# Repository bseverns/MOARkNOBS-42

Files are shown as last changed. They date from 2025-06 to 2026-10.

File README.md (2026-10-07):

# MOARkNOBS-42

MOARkNOBS-42 (MN42) is an open, reactive MIDI/OSC performance instrument: a physical control surface, Teensy firmware,
a browser configurator, and a desktop Bridge that are designed and documented as one system.

It gives performers 42 configurable control slots, six envelope-follower inputs, profile recall, MIDI, OSC, and
browser-based editing without hiding the device contract behind proprietary software. It is closer to a small system
with a very visible control surface than “just a controller with a lot of knobs.”

[Try the browser configurator in simulator mode](https://bseverns.github.io/MN42/) without hardware, or read the
[five-minute orientation](docs/getting-started/FirstFiveMinutes.md).

## How the system fits together

```mermaid
flowchart LR
  H[Hardware<br>buttons, pots, LEDs,<br>envelope inputs] --> F[Firmware<br>scanning, MIDI,<br>config, persistence]
  F --> C[Contracts<br>manifest, schema,<br>WebSerial, Bridge RPC]
  C --> U[User tools<br>browser configurator,<br>OSC and host MIDI]
```

Each layer reports what it knows to the next. That is why the project emphasizes schema compatibility, verified
readback, test coverage, and evidence-backed support boundaries.

## Choose your path

| Interest | Start here | You will learn... |
| --- | --- | --- |
| Performer | [Quickstart for Performers](docs/getting-started/QuickstartForPerformers.md) | How to connect, configure, recall profiles, and prepare a rig. |
| Builder | [Quickstart for Builders](docs/getting-started/QuickstartForBuilders.md) | How to inspect, flash, bring up, and validate a board. |
| Contributor | [Contributing](CONTRIBUTING.md) | The build, test, documentation, and review gates. |
| Technical Evaluator | [Hardware-Test Readme](HARDWARE_TEST_README.md) | What the current prototype evidence proves—and does not prove. |

For a conceptual tour, use [Start Here](docs/getting-started/StartHere.md). For a complete source-tree map, use
[Repository Contents](docs/project/RepositoryContents.md).

## What is included

- **Hardware:** a Teensy 4.0 control surface with buttons, pots, LEDs, MIDI I/O, OLED feedback, and six reactive inputs.
- **Firmware:** scheduling, control scanning, MIDI behavior, modulation, configuration, and generation-checked persistence.
- **Browser configurator:** direct WebSerial setup, monitoring, staged edits, verified Apply, profiles, and a hardware-free simulator.
- **Bridge:** local browser console, OSC routing, virtual/host MIDI routing, and an App-over-Bridge transport.
- **Documentation and evidence:** contracts, build guides, validation procedures, and dated bench receipts.

## Quick start without hardware

1. Open the [hosted configurator](https://bseverns.github.io/MN42/).
2. Select **Start Simulator** for the firmware-default reset state, or **Load Demo Rig** for the illustrative example.
3. Check the named simulator fixture in Session, then change a slot, inspect the staged diff, and apply it to the simulated device.

The simulator demonstrates the browser workflow. It does not validate physical controls, timing, MIDI wiring, or
electrical behavior.

## Build and test

The PlatformIO project root is `firmware/`; always pass `-d firmware` from the repository root:

```bash
pio run -d firmware -e teensy40_main
pio test -d firmware -e teensy40_unity -vvv
```

Run the grouped repository checks before proposing a change:

```bash
./tools/doctor --full
```

See [Contributing](CONTRIBUTING.md) for the scoped test matrix and the custom Unity transport rules.

## Current project boundary

MN42 is at the hardware-test stage. The prototype boards and software paths are useful for bring-up and evaluation,
but the repository does not claim a public v1.0 release, an orderable fabrication package, universal host/browser
support, or a signed desktop installer.

Current hardware observations, board photos, test status, and the exact evidence still needed are kept in the
[Hardware-Test Readme](HARDWARE_TEST_README.md) and [Current Build](hardware/CurrentBuild.md)—not on this landing page.

## Documentation

- [Documentation site](https://bseverns.github.io/MOARkNOBS-42/)
- [System Map](docs/getting-started/SystemMap.md)
- [Connectivity Guide](docs/getting-started/ConnectivityGuide.md)
- [Documentation Truth Map](docs/reference/DocumentationTruthMap.md)
- [Testing](docs/validation/TESTING.md)
- [Release and reproducibility](REPRODUCIBILITY.md)

If two documents disagree, the [Documentation Truth Map](docs/reference/DocumentationTruthMap.md) defines the tie-break
rules. Historical wiki pages are frozen; canonical maintained documentation lives in this repository and the generated
documentation site.

## Contact and feedback

- Reproducible bugs and public questions: [GitHub Issues](https://github.com/bseverns/MOARkNOBS-42/issues)
- Security-sensitive reports: [Security policy](SECURITY.md)
- Pilot-run inquiries: [severns3@gmail.com](mailto:severns3@gmail.com)

Never put credentials, private device data, or other secrets in a public issue.

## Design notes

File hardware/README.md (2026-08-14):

# MOARkNOBS-42 Hardware References

This folder contains the hardware references used by the hardware-test package.
Use these files to validate the current prototype on the bench.

Do not treat this folder as a fabrication-ready release bundle.

Start with [CurrentBuild.md](CurrentBuild.md).

## External Power Requirement

Use a regulated `5 V DC` external supply at the DC input.

- `5 V / 4 A` is the minimum recommended bench supply.
- `5 V / 5 A` is preferred for LED-heavy testing (`white100`, `blast`, long soaks).
- Ground must be common across logic, LED, MIDI, and envelope follower sections.

> [!WARNING]
> Do not feed `9 V` or `12 V` into this board's VIN path unless a regulator/buck stage is explicitly added and documented. In this project, `VIN_RAW` and `VIN_FUSED` are project rail labels and should not be interpreted as an Arduino-style high-voltage raw VIN input.

## Power Topology Caveat

The intended fuse topology is:

- preferred: `5V_IN -> F1_LOGIC_0.5A -> 5V_LOGIC`
- preferred: `5V_IN -> F2_LED_2.5A -> 5V_LED`

If the actual board copper instead routes `F2` downstream of `F1`, then `F1` becomes an upstream choke for the entire machine.

> [!WARNING]
> If `F1` is upstream of the LED branch, the `0.5 A` PTC is the effective whole-system current limit. Firmware brightness caps help, but they are not a substitute for correct rail topology and fuse placement.

## Verify Before High-Current LED Tests

Before `white100`, `blast`, or burn-in phases:

- meter DC jack positive to `F1` input
- meter DC jack positive to `F1` output
- meter DC jack positive to `F2` input
- determine whether `F1` and `F2` are parallel branches or whether `F2` is downstream of `F1`
- do not run full-strip white or burn-in tests until this is confirmed

Power estimates and quick current math live in [PowerBudget.md](../docs/reference/PowerBudget.md).

## Firmware Env Boundary

- Flash `teensy40_main` on Rev A or any board whose LED rail topology is still unverified.
- Flash `teensy40_main_reworked` only after the board has been reworked and that split-rail topology has its own dated validation evidence.

## Current Bench-Validation References

- [Power, button, and LED schematic](../docs/assets/board/SCH_MOAR_Schematic_1-PWR-BUTTON-LED_2026-08-13.png)
- [Interface, MIDI, and control schematic](../docs/assets/board/SCH_MOAR_Schematic_2-INTERFACE-MIDI-CNTRL_2026-08-13.png)
- [Six-channel envelope schematic](../docs/assets/board/SCH_MOAR_Schematic_3-ENVELOPE_2026-08-13.png)
- [top-side board photo](../docs/assets/board/prodTOP.jpg) and [bottom-side board photo](../docs/assets/board/prodBTM.jpg)
- [trace-inspection photo](../docs/assets/board/trace.jpg), [bench context](../docs/assets/board/bench.jpg), and [powered bring-up](../docs/assets/board/bringup.jpg)
- [fabrication boundary note](fabrication/README.md)

These files are included to support bench validation and wiring review. No current BOM, Gerber, or NC-drill release bundle is tracked in `fabrication/`.

## Included Notes

- [CurrentBuild.md](CurrentBuild.md)
- [Parts.md](Parts.md)
- [PartsRationale.md](PartsRationale.md)
- [Substitutions.md](Substitutions.md)

## Status Boundary

- current schematic PNG sheets and board photos are present and usable as hardware references
- no current BOM export is tracked in `fabrication/`
- no verified fabrication-ready Gerber and NC-drill bundle is claimed by this package
- the fabrication folder is a boundary note until verified manufacturing files are added

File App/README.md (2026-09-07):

# MOARkNOBS-42 Browser Configurator

Use the browser configurator to connect directly over WebSerial, monitor the instrument, edit mappings, and manage
profiles. If you need OSC, host MIDI, or a browser without WebSerial, use the [Bridge](../bridge/README.md) path.

The fastest hardware-free introduction is the [hosted configurator](https://bseverns.github.io/MN42/): select
**Start Simulator** for the firmware-default reset state, or **Load Demo Rig** for illustrative mappings and motion.
The active simulator fixture is named in Session.

## Support boundary

- Direct USB is best evidenced on Chromium-based browsers with WebSerial.
- App-over-Bridge is best evidenced with the Node 24 Bridge on a desktop host.
- Firefox/Safari WebSerial and universal browser support are not claimed.
- The simulator rehearses App behavior; it is not hardware, electrical, MIDI-wiring, or latency evidence.

See [Host Compatibility](../docs/reference/HostCompatibility.md) before widening those claims.

## Quick start: direct USB

1. Flash the controller and connect it with a USB data cable.
2. From `App/`, serve the files from a secure or localhost origin:

   ```bash
   python3 -m http.server 8000
   ```

3. Open <http://localhost:8000/> in a Chromium-based browser.
4. Select **Check compatibility**, then **Connect**, and choose the MN42 serial device.
5. Wait for the identity, manifest, schema, and configuration handshake to finish.
6. Stage an edit, review the diff, select **Apply**, and wait for verified readback.

The legacy `benzknobz.html` URL remains a supported local/test entry point.

## Quick start: App over Bridge

```bash
npm --prefix bridge ci
npm --prefix bridge start
```

Open <http://127.0.0.1:8787/>, start the device session, then select **Open configurator**. The App uses the structured
Bridge session for configuration while OSC and MIDI routing remain active.

## Everyday workflow

- Use **Configure** to select a physical slot, map its output, build the **Reactive** path (source, ARG relationship, and EF character), then add **Motion**. With ARG off, Source drives the path; with ARG on, Reactive assignment keeps the path assigned while ARG supplies its combined value. Each Motion lane shows its shared generator’s current shape and rate, or labels an unsaved generator change as a local draft; editing remains in Lab. The selected-slot strip separates staged settings from measured device contributions and follows their causal order.
- Use **Stage** for a compact performance dashboard and safe recall controls.
- Use **Lab** for exact controls arranged by ownership. Its upper row keeps Live Slots, Selected Slot, and compact Session context together; the full-width **Lab Bench** opens one room at a time: **Instrument** for machine-wide shaping and live device controls, **Profile** for A–D arp/LFO/incoming-MIDI work, **Observe** for scope, monitor, MIDI trace, and modulation topology, and **Evidence** for staged diff and diagnostics. Continuous slot controls pair exact numbers with sliders; timing sliders use logarithmic travel. Reset to confirmed stages the last confirmed field value.
- Importing JSON stages a draft; it does not write the device until Apply succeeds.
- Export saves the current staged state, including unsent changes.
- Profile, scene, macro, and transport actions that could replace a dirty draft are blocked until it is applied or discarded.
- If Apply becomes uncertain, keep the candidate visible and let authoritative readback resolve device truth.

**State · Presets, profiles & backups** groups starting presets, device profile actions, and configuration/profile files.
Opening the drawer writes nothing. Presets and imports stage changes; profile save persists configuration on the device.

Changed controls carry **Staged** markers. The compact **Review / Discard / Apply** dock keeps the transaction available;
Review can focus the exact changed slot field in its Lab Bench room. **Customize in Lab** and **Return to Configure** preserve the
selected slot and LFO lane; generator links open **Lab Bench → Profile → Profile LFO & Routes**. Recipe explanations remain visible on touch screens.

The App explains how a slot’s value is shaped; the Bridge explains where that value goes. Neither surface infers
missing device measurements or confirms receipt by an external host application.

## Troubleshooting

- **Connect is unavailable:** wait for the page to finish initializing, then run **Check compatibility**.
- **No device selected:** the browser picker was cancelled; select **Connect** again and choose the device.
- **WebSerial is blocked:** use HTTPS or `http://localhost`, and confirm the browser supports WebSerial.
- **Apply is disabled:** fix the validation errors shown in the staged-diff panel.
- **State is uncertain/resynchronizing:** do not repeat writes blindly; wait for authoritative readback.
- **Need to recover during a set:** use **Panic Help**; the hardware baseline combo is `Ctrl0 + Ctrl1 + Ctrl2`.

## Develop and test

```bash
npm --prefix App test
```

The Playwright suite serves the real runtime and view modules, then exercises simulator, schema, staged Apply,
uncertainty, migration, profile, and UI behavior.

## Reference

- [App Behavior Contract](../docs/app/AppBehaviorContract.md) — runtime ownership, modes, schema, staged state, telemetry, and simulator boundaries
- [Configuration Transaction Model](../docs/reference/ConfigurationTransactionModel.md) — candidate, receipt, uncertainty, and readback semantics
- [App Transport Truth Table](../docs/app/AppTransportTruthTable.md) — direct, structured Bridge, raw Bridge, and simulator labels
- [Configurator Tour](../docs/guides/Configurator.md) — operator-facing UI walkthrough
- [App bench receipts](../docs/bench/app/README.md) — observed host/device evidence
- [Documentation Truth Map](../docs/reference/DocumentationTruthMap.md) — tie-break rules

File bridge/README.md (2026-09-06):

# MN42 Bridge

The MN42 Bridge is the desktop companion for the browser configurator. Use it when a rig needs OSC, host/virtual MIDI,
a local browser console, or App access without browser WebSerial. For direct USB configuration only, start with the
[App](../App/README.md).

## Support boundary

- Best repo evidence: Node.js 24 desktop host with the browser console or CLI.
- OSC and DAW routing are setup-specific; consult receipts before making host-wide claims.
- CI artifacts are unsigned. This repository does not claim a signed installer or broad DAW certification.
- Package scripts intentionally require Node `>=24 <25` until wider versions have explicit evidence.

See [Host Compatibility](../docs/reference/HostCompatibility.md) for the conservative matrix.

## Quick start: browser console

Prerequisites: Node.js 24.x and an MN42 connected over USB.

```bash
npm --prefix bridge ci
npm --prefix bridge start
```

Open <http://127.0.0.1:8787/> if the server does not open it automatically. Then:

1. Choose the serial port and confirm the OSC/MIDI destinations.
2. Start the Bridge and wait for the device session to report ready.
3. Open **Monitor**, start passive soundcheck, and move one stable hardware control to observe configured Bridge outputs.
4. Select **Open configurator** when you need instrument configuration edits.

Returning users begin at **Your saved rig**: choose a browser-local **Performance Setup** and **Start this setup**
to recall its exact serial, MIDI, and OSC settings. The suggested MN42 profile stays advisory. **Edit** and
**New setup** open the collapsed setup workbench; its manual start action is **Start current setup**.

**Routing** labels Device → MIDI cards **Next start** and MIDI → OSC custom routes **Live now**. Slot/EF → CC →
Channel cards, with raw JSON under Advanced, apply on the next Bridge start in Configured routes mode; legacy
compatibility retains its automatic CC assignments.
Invalid raw definitions block starting and saving until corrected.

**Monitor** follows MN42 → USB → Bridge and the four OSC/MIDI directions. Idle routes remain neutral; observed
Bridge output does not confirm receipt in a host application. Device evidence is available under **Device details**,
and alerts link to the relevant Diagnostics section. See the [console tour](../docs/bridge/BridgeConsoleTour.md).

The HTTP server binds to loopback by default. Every launch creates a random control token and opens a tokenized URL;
treat it as a local credential. Public-interface HTTP requires the explicit `--unsafe-network-http` option and your own
network protection.

## Quick start: CLI

Find the serial device (`/dev/cu.usbmodem*` on macOS, `/dev/ttyACM*` or `/dev/ttyUSB*` on Linux, or a COM port on
Windows), then run:

```bash
node bridge/mn42_bridge.js \
  --serial /dev/ttyACM0 \
  --osc 9000 \
  --osc-listen 9000 \
  --host 127.0.0.1 \
  --bind 127.0.0.1 \
  --midi "MN42 Bridge"
```

Replace the serial path and MIDI port label with values from the host. Use `--config ./bridge/settings.example.json`
for saved settings; explicit CLI flags override the file.

## What the Bridge routes

- Device telemetry to OSC and optional host MIDI.
- OSC or MIDI performance messages back to the firmware live-control lane.
- Structured device-session state to the browser configurator.
- Revisioned staged configuration through `/api/device/*` and `/ws/events`.
- Raw newline-oriented serial compatibility through `/ws`.

Clients negotiate the structured interface through `GET /api/contract` before
using it. Existing `/api/*` paths remain the version-1 compatibility surface;
the response advertises API/event versions, Bridge version/source identity,
supported device schema versions, and verified Apply/session capabilities.

Live `SET_SLOT_VALUE` and typed MIDI/OSC events are performance writes, not staged configuration. Configuration changes
use stage/apply endpoints and preserve uncertainty until authoritative readback resolves device truth.

## Everyday workflows

- **Rehearsal/show:** follow [Bridge for Performers](../docs/guides/BridgeForPerformers.md).
- **Browser console:** use [Bridge Console Tour](../docs/bridge/BridgeConsoleTour.md).
- **OSC or DAW setup:** use [Bridge Operator Reference](../docs/bridge/BridgeOperatorReference.md).
- **App integration:** use [Bridge Transport Contract](../docs/bridge/BridgeTransportContract.md).
- **Write behavior:** use [Bridge Write Lanes](../docs/bridge/BridgeWriteLanes.md).

## Troubleshooting

- **No device updates:** confirm the serial path, close other serial clients, then restart and wait for `HELLO`.
- **OSC commands ignored:** send to the listen port (default `9000`) and use `/mn42/cmd` or a documented typed address.
- **DAW cannot see MIDI:** create/enable a host loopback port and pass its exact label to `--midi`.
- **Port already in use:** stop the existing process or choose different HTTP/OSC ports.
- **Apply is uncertain:** do not repeat the write blindly; wait for the session's authoritative readback.

## Develop and test

```bash
npm --prefix bridge test
npm --prefix bridge run smoke
```

Packaging and signing are separate release concerns. See [Bridge Signing Plan](../docs/release/BridgeSigningPlan.md) and
the [artifact checklist](../docs/release/bridge-artifacts-checklist.md).

## Reference

- [Bridge Docs Map](../docs/bridge/BridgeDocsMap.md)
- [Bridge Operator Reference](../docs/bridge/BridgeOperatorReference.md)
- [Bridge Transport Contract](../docs/bridge/BridgeTransportContract.md)
- [Bridge Write Lanes](../docs/bridge/BridgeWriteLanes.md)
- [Known Good Host Recipes](../docs/reference/KnownGoodHostRecipes.md)
- [Bridge bench receipts](../docs/bench/bridge/README.md)
- [Documentation Truth Map](../docs/reference/DocumentationTruthMap.md)

Bridge code is licensed under the repository license; bundled dependency notices are in
[THIRD_PARTY_LICENSES.md](THIRD_PARTY_LICENSES.md).

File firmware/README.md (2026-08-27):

# MOARkNOBS-42 Firmware Hardware-Test Guide

> **Doc class:** Contract doc. This is the firmware build/test boundary for the current hardware-test package; release and hardware-readiness claims still require the validation docs.

This `firmware/` directory is the real PlatformIO project for the current MOARkNOBS-42 hardware-test package.
The commands below are safe to copy from the repository root because they pass `-d firmware` explicitly.

For document tie-break rules, see [Documentation Truth Map](../docs/reference/DocumentationTruthMap.md).

## Baseline Build

```bash
pio run -d firmware -e teensy40_main
```

The repo-root `platformio.ini` is only a guard that rejects accidental root-level builds.

## Firmware Environments

- `teensy40_main` for Rev A / unverified-rail boards; this is the conservative default build
- `teensy40_main_reworked` only for boards whose split-rail rework has been validated and documented
- `teensy40_full_system` for bridge-connected full-stack bench validation
- `teensy40_unified_test` for manual bench verification of buttons, pots, OLED, LEDs, and envelope inputs
- `teensy40_biquad_test` for filter verification
- `teensy40_eeprom_persistence` for staged persistence and backup-restore validation
- `teensy40_slot_verify` for slot-storage integrity checks
- `teensy40_led_demo` for LED pattern and load-surface checks
- `teensy40_button_ef_demo` for simple button plus envelope USB MIDI validation
- `teensy40_display_alive` for an OLED-only "is the panel alive?" check
- `teensy40_display_led_hw` for OLED and LED hardware bring-up
- `teensy40_power_burnin` for LED load and power-rail soak testing
- `teensy40_unity` for the custom Unity smoke suite

The full lane summary lives in [../docs/hardware-test/TestMatrix.md](../docs/hardware-test/TestMatrix.md).

`GET_MANIFEST` reports the active board power profile, LED cap, and rail-verification bit from the selected env, so do not flash `teensy40_main_reworked` unless the physical board actually matches that claim.

## Envelope Filter Timing

Envelope filter configuration keeps the legacy `frequency` field for wire and
preset compatibility, but the value is a shaping-control scale rather than a
physical cutoff in hertz. The runtime samples one of six followers every 2 ms,
giving each follower an effective rate of about 83.3 Hz. It translates the
legacy control ratio onto that real cadence before configuring the biquad.
Per-slot EF voices perform the same translation using the configured mid-tier
envelope interval. The `native_biquad` step-response test locks this timing
model without claiming analog-input-to-host latency.

## Configuration and Profile Boundaries

The compatibility commands `CAL_ENVS`, `GET_FILTER`, `SET_FILTER`,
`GET_SLOT_FILTER`, `SET_SLOT_FILTER`, `GET_ARGPAIR`, and `SET_ARGPAIR` are
handled by `src/protocol/LegacyConfigCommands.cpp`. Their command spellings,
responses, and persistence behavior are unchanged; `ConfigManager` now exposes
configuration operations without parsing transport text. This refactor does
not alter the durable layout or wire protocol.

`src/protocol/ConfigSchema.cpp` owns `GET_SCHEMA` construction, while
`ProfileTypes.h` owns the current packed profile payload independently of the
manager class. `ProfileMigration.cpp` performs read-only decoding and
sanitization for stored profile versions 1–7; `ConfigManager` retains profile
ID/address validation and the public load/save façade. Migration fixtures cover
versions 1–6, current-version coverage protects version 7, and decoder failure
tests verify that invalid records do not mutate the caller's output.
Activating a stored profile also requires one valid legacy pot/CC mapping copy;
an extended profile payload alone cannot produce a partial profile transition.

The `SET_ALL` implementation is separated into `ConfigBulkTransport` for chunk
staging, timeout/idempotency, and ACKs; `ConfigJsonApply` for complete validation
and atomic runtime/persistence mutation; and `ConfigApplyDigest` for the
device-owned normalized-state checksum. Parse, identity, abort, and timeout
failures discard staged transport state; retrying the last acknowledged
sequence plus config identity replays the same applied checksum and storage
generation without applying again.

Direct read commands remain fronted by `ProtocolSimpleHandlers`, but bounded
read-chunk framing and pending-output state live in `ChunkedReadTransport`, and
`GET_MOD_MATRIX` construction lives in the flash-resident `ModMatrixReport`.
Non-persistent live `SET_*` mutations live in `ProtocolLiveControlHandlers`.
These are ownership boundaries only: command names, response shapes,
persistence semantics, and the durable layout are unchanged.

## On-device Live Editing

The performance surface can now reach three formerly configurator-heavy slot settings without entering config mode:

| Gesture | Active-slot edit | Live behavior |
| --- | --- | --- |
| Double-press `Ctrl3` | Cycle EF oversampling through 1x, 2x, 4x, 8x, 16x, and 32x | Reconfigures the assigned follower immediately |
| Double-press `Ctrl4` | Toggle the slot-local ARG combiner | Switches the configured ARG method and source pair in or out |
| `Ctrl0+Ctrl1+Ctrl4` | Toggle the fixed LFO 1 lane | Enables live centered modulation at 100% for an untuned lane and preserves later tuning |

Ctrl3 and Ctrl4 defer their ordinary single action until the 300 ms double-press window expires, so their double actions do not also change channel or data1. Ctrl5 has no double-press action: each tap-tempo press fires immediately on release, including fast 240 BPM tapping. The edits persist with the slot and stream `slot_patch` readback to an attached configurator. The complete short/long/double/combo map lives in [include/ButtonManager/README.md](include/ButtonManager/README.md).

The former Ctrl5 collision is removed: rapid taps can no longer be classified as an LFO toggle. Ctrl5 singles continue to update `g_tappedBPM`, while the dedicated LFO chord preserves the previous live lane initialization and tuning-retention behavior.

The OLED also acts as a contextual command palette. Holding Ctrl0-Ctrl5 shows that control's semantic namespace and useful chord continuations; recognized chord prefixes show deeper continuations. The compact firmware table and [generated quick reference](../docs/reference/generated/OnDeviceQuickReference.md) both come from [the on-device control registry](../docs/reference/on_device_control_registry.json), so help copy and gesture metadata share one machine-readable source. Config, LFO, jitter, and diagnostic views retain priority and use persistent mode headers.

## First Reading Path

If you are learning this firmware by reading code, start with
[src/firmware_main.cpp](src/firmware_main.cpp), then follow the ordered header
walkthrough in [../docs/firmware/FirmwareMainReadingPath.md](../docs/firmware/FirmwareMainReadingPath.md).
That path is the repo's intended "top-down" introduction to the machine.

## Core Commands

Firmware build:

```bash
pio run -d firmware -e teensy40_main
```

Unity smoke suite:

```bash
pio test -d firmware -e teensy40_unity -vvv
```

Unified bench sketch:

```bash
pio run -d firmware -e teensy40_unified_test -t upload
```

LED surface stress sketch:

```bash
pio run -d firmware -e teensy40_led_demo -t upload
```

Full bridge/system lane:

```bash
pio run -d firmware -e teensy40_full_system -t upload
```

Production boot contract proof:

```bash
node firmware/system_test/mn42_boot_contract_runner.js --serial /dev/cu.usbmodemXXXX --flash --report logs/boot-contract.json
```

Attach-live hardware proof when the board is already running firmware and you only need the real configurator/apply lane:

```bash
node firmware/system_test/mn42_boot_contract_runner.js --serial /dev/cu.usbmodemXXXX --attach-live --report logs/boot-contract-attach-live.json
```

Request one-shot configurator boot from a running firmware image:

```text
ENTER_CONFIG_MODE
```

`ENTER_CONFIG_MODE` stores a one-shot boot marker and reboots. The next boot enters
USB configurator mode and consumes the marker; normal power-up defaults to the
standalone runtime so USB MIDI remains available without opening the configurator
or bridge first.

Live runtime controls exposed over the configurator/native protocol:

```text
GET_NOTE_DYNAMICS
SET_NOTE_DYNAMICS,<velocityShift>,<changeProbability>
GET_JITTER
SET_JITTER,<depth>,<smoothness>
GET_CLOCK
SET_CLOCK,<followExternal>,<clockOutEnabled>,<tappedBpm>
GET_USB_MIDI
SET_USB_MIDI,<0|1>
```

`SET_NOTE_DYNAMICS` clamps to `-64..63` and `0..100`. `SET_JITTER` clamps both
values to `0.0..1.0`. `SET_CLOCK` clamps the internal tempo to `20..300 BPM`.
The firmware advertises these lanes in the manifest so the browser configurator
can fail closed on older builds.

`GET_MANIFEST` also reports a small persistence-health snapshot for host tools:
`brownout_count`, `eeprom_primary_valid`, `eeprom_backup_valid`, and
`eeprom_last_load` (`primary`, `backup`, or `defaults`).

## Important Test Contract

- PlatformIO project root is `firmware/`.
- The Unity lane uses the custom Serial1 transport from `test/unity_output.cpp`.
- Do not re-enable PlatformIO's autogenerated Unity transport.
- Tests assume `board_build.usbtype = usb_midi_serial`.
- Hardware firmware builds override USB strings to enumerate as `MN42 MIDI` (manufacturer `MN42`).
- Do not pull display or SD stacks into the Unity lane unless explicitly needed.

## Local References

- [include/](include/README.md)
- [src/](src/README.md)
- [test/](test/README.md)
- [system_test/](system_test/README.md)

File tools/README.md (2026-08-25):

# Bench Toys & Code Gremlins

> Grab-bag of small scripts that sniff, log, or otherwise harass the hardware so you can learn by poking.

## Serial Logger

Curious about latency or noise? `serial_logger/SerialToCsv.pde` is a Processing sketch that funnels whatever the board spits into CSV files you can graph or diff later. Quick run:

```text
1. Launch Processing 4.
2. Load `SerialToCsv.pde`.
3. Hit Run and choose the board's serial port.
4. Press `L` to log latency, `N` for noise. `Q` bails.
```

Outputs land in `docs/bench/latency/latency.csv` and `docs/bench/noise/adc_idle.csv`. More details live in the [serial_logger README](serial_logger/README.md).

## RTL Latency Report

When you bounce the rig through an external DAW loop and capture an impulse
response, feed those WAVs to `rtl_latency_report.py`. It auto-detects the
send/return spikes, measures the gap in samples, and spits out both a table and
JSON so you can compare baseline (256 buffer) against tuned (64 buffer) sessions
without hand math. Think of it as a drummer with a calculator: loud, precise,
and painfully honest.

## Docs Link Checker

Run `python3 tools/check_docs_links.py` before you ship docs-heavy changes. It checks local Markdown links and heading anchors so learners don't fall through trapdoors.

## Public UI Vocabulary Guard

Run `python3 tools/check_public_ui_vocabulary.py --root .` to keep musician-facing front-door docs on the current App and Bridge names. The guard is deliberately scoped: historical records, compatibility tokens, recipe names, and deep contracts may still use words such as `advanced` or `stage` in other meanings.

## Bring Your Own Hacks

Got a script that makes debugging less dull? Park it here with a README and keep dependencies light. No binaries, no mystery jars—just plain text mischief that others can remix.

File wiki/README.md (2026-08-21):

# Archived Wiki Source Pack

> **Archived:** The wiki is frozen and is no longer a maintained documentation surface. Canonical documentation lives
> in [`docs/`](../docs/index.md), the root [`README.md`](../README.md), and the component READMEs.

The files in this directory are retained as historical source material so existing GitHub Wiki links do not disappear.
They may describe older workflows or support boundaries and must not be used to settle current behavior.

## Where to go instead

- Project introduction: [`README.md`](../README.md)
- Performer path: [`docs/getting-started/QuickstartForPerformers.md`](../docs/getting-started/QuickstartForPerformers.md)
- Builder path: [`docs/getting-started/QuickstartForBuilders.md`](../docs/getting-started/QuickstartForBuilders.md)
- Contributor path: [`CONTRIBUTING.md`](../CONTRIBUTING.md)
- Evaluator path: [`HARDWARE_TEST_README.md`](../HARDWARE_TEST_README.md)
- Documentation tie-break rules: [`docs/reference/DocumentationTruthMap.md`](../docs/reference/DocumentationTruthMap.md)

## Maintenance policy

- Do not add new guidance to `wiki/`.
- Fix a wiki page only when needed to prevent a dangerous or materially misleading stale instruction.
- Move any still-unique, current content into `docs/` before updating it.
- Do not publish this directory as a replacement for the maintained documentation site.

Existing pages remain snapshots. Their `Canonical source` declarations point readers toward the maintained contract or
guide that supersedes them.

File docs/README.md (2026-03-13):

# Docs Index

> Hardware's signed off and etched in copper. This folder is the reference stash for the whole machine—schematics, firmware lore, and every misadventure we've documented.

Welcome to the MOARkNOBS-42 documentation playground. This README aims to help you navigate the library of notes, design scraps, and personal ramblings we keep around to teach ourselves and the next hacker.

Need the fast track from bare board to release? Hit the [Process Overview](ProcessOverview.md).

Craving the bird's-eye view? The [systemflow docs](sketch/systemFlow/) rip the machine into subsystems so you can see how every knob, LED, and envelope fits together before you dive into the weeds.

If you only need the canonical operational docs, start here:

- [TESTING.md](TESTING.md) for what the current automated/manual coverage actually proves
- [ReleaseGuide.md](ReleaseGuide.md) for the human release checklist
- [../REPRODUCIBILITY.md](../REPRODUCIBILITY.md) for the exact artifact-building recipe
- [../App/README.md](../App/README.md) for the browser/runtime/schema/Apply contract

## Local site preview

The repo now ships with a MkDocs scaffold so the docs can read like a guided site instead of a loose folder dump.

```bash
pip install -r requirements.txt
mkdocs serve
```

Then open the local URL MkDocs prints in your terminal.

| Doc | Why it exists | Keep it fresh |
| --- | --- | --- |
| [Primers/MIDI-DSP101.md](Primers/MIDI-DSP101.md) | MIDI basics and the DSP tricks our firmware leans on | Sync when firmware MIDI features or filter math shift |
| [ProcessOverview.md](ProcessOverview.md) | Full build and release flow | Update when hardware or firmware release steps move |
| [TESTING.md](TESTING.md) | Canonical test workflow + coverage map | Refresh when test scope or commands move |
| [ReleaseGuide.md](ReleaseGuide.md) | Human release checklist | Refresh when release ritual or asset list changes |
| [../REPRODUCIBILITY.md](../REPRODUCIBILITY.md) | Canonical deterministic artifact recipe | Refresh when `release.sh` or artifact shape changes |
| [../App/README.md](../App/README.md) | App/runtime contract and simulator notes | Refresh when manifest/schema/apply semantics change |
| [interop/seedbox.md](interop/seedbox.md) | SeedBox handshake + CC contract | Refresh when either repo tweaks the interop map |

## Accessibility

- Every diagram and board glam shot sports alt text so screen readers get the same gossip as eyeballs.
- Headings descend one level at a time—no surprise teleporting from H1 to H4.
- Code blocks and tables stay lightweight so zoom tools and high-contrast themes can rage without breaking layout.

## PCB Gallery

> Fast glamor shots live here so the hardware README can stay lean. Want the cadaver-level detail? The [sketch/](sketch/) folder holds every layer and subsystem sketch.

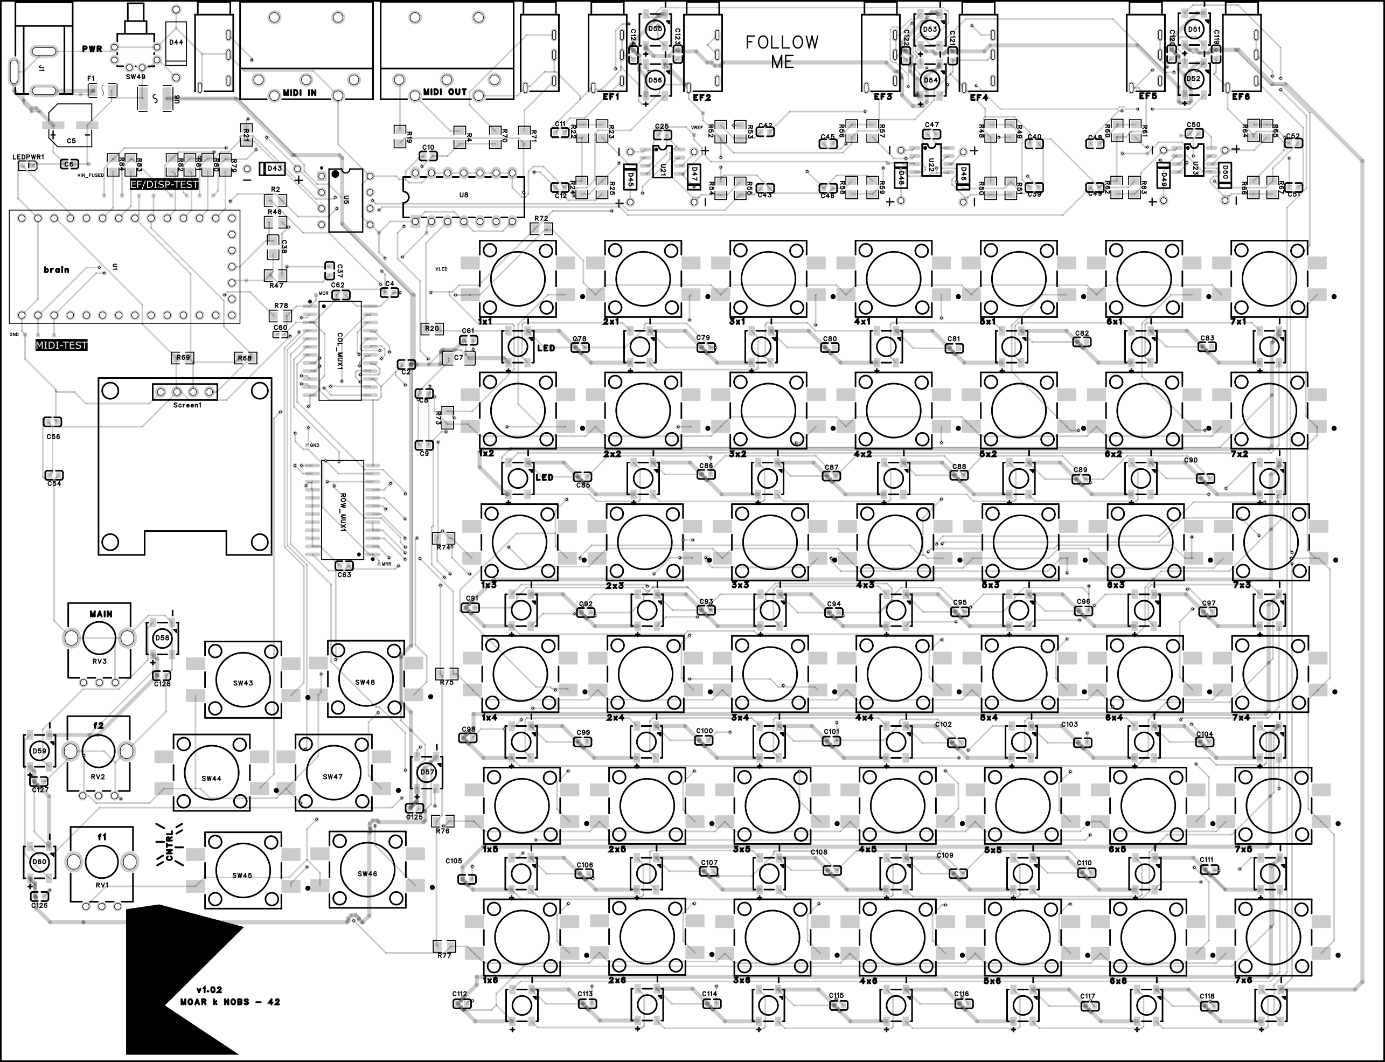
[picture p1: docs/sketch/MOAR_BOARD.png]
Render of MOARkNOBS board showing component layout


Layer spelunking:

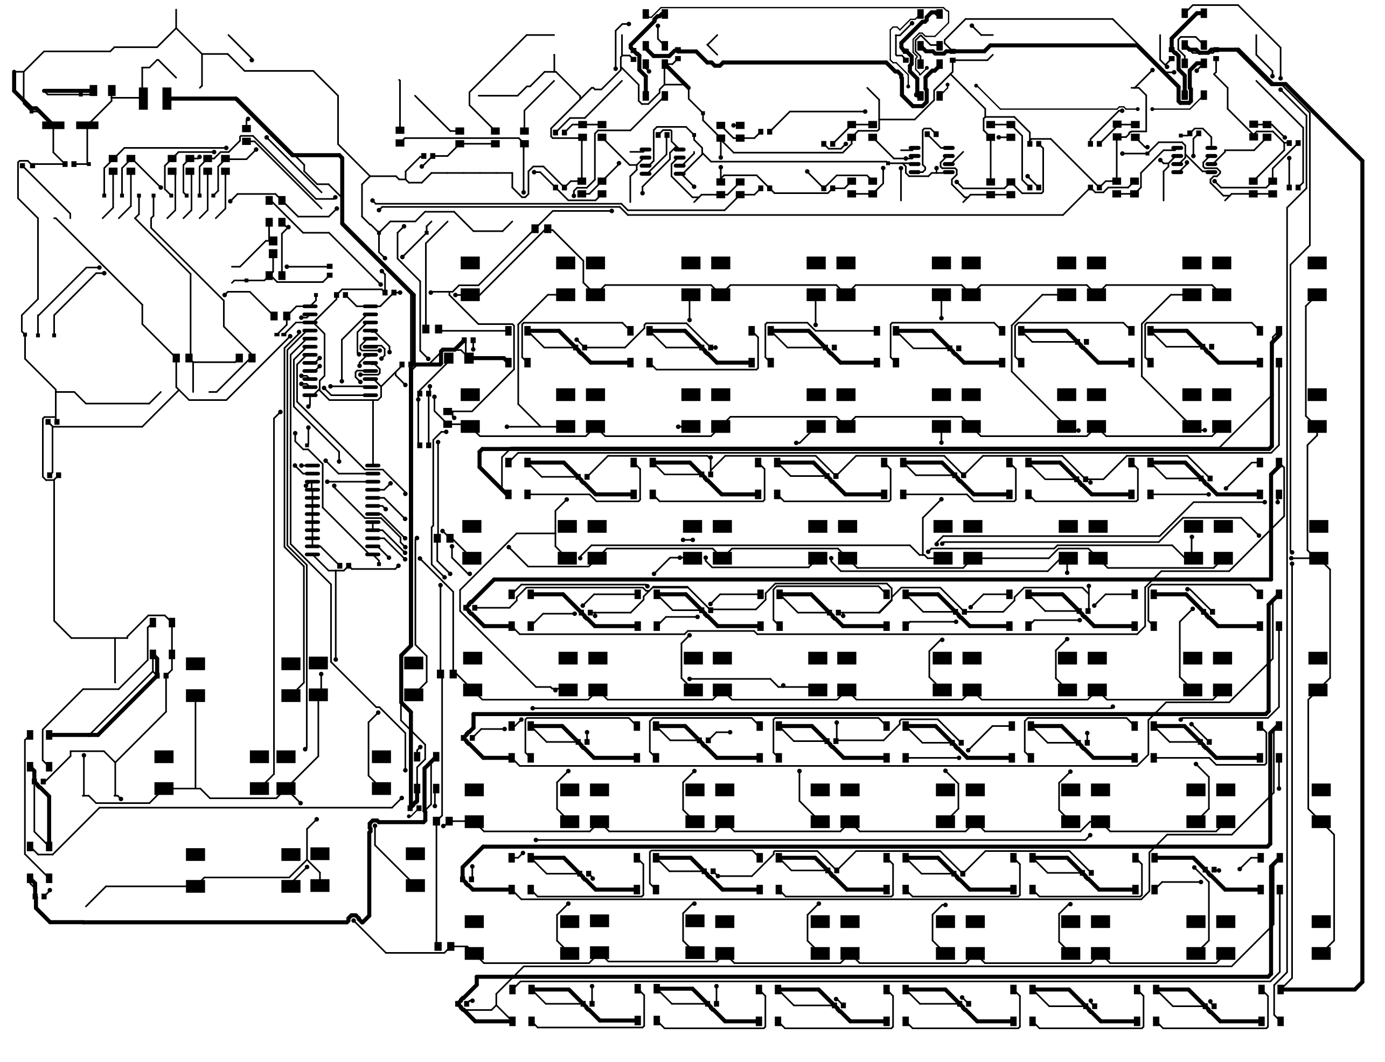
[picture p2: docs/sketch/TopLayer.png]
PCB top-layer trace map

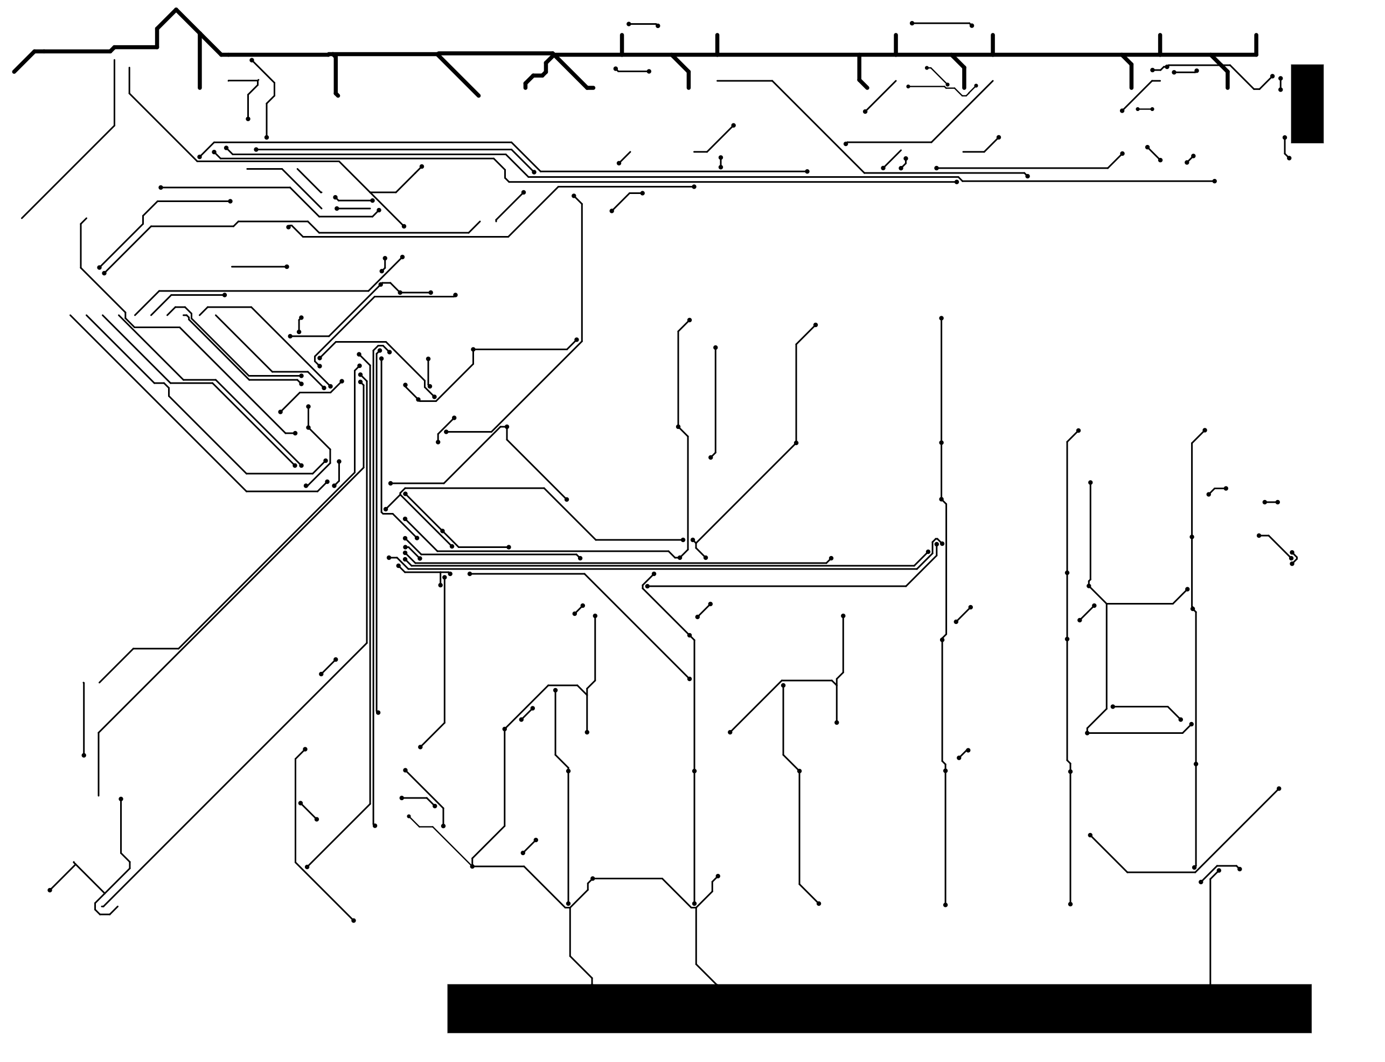
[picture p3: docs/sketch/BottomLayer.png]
PCB bottom-layer trace map


### Everything Everywhere

```mermaid
flowchart TD
  Flash --> Loader[Bootloader] --> FW[Teensy Firmware]
  FW --> BM[ButtonManager] --> DM[DisplayManager]
  Buttons((Buttons)) -->|scan| BM --> FW
  EF[EnvelopeFollower] -->|mod| Slots((Slots))
  ARP[Arpeggiator] -->|mod| Slots((Slots))
  MIDIIN --> FW --> DM[DisplayManager]
  MIDIIN --> FW --> Slots((Slots))
  Browser[[Browser]] --> WebSerial --> FW
  NodeOSC[[Node OSC Bridge]] --> FW
  FW --> Slots((Slots)) --> MIDIOut((MIDI Out))
  FW --> MIDIThrough((MIDI Through))
```

## System Capabilities

 - [Hardware README](../hardware/README.md#sparkfun-shortcut) — final board layout, power rails, and a SparkFun shortcut for the silicon.
- [Firmware README](../firmware/README.md) — how the code slings MIDI, wrangles envelope followers, and keeps the LEDs honest.
- Firmware reference tables: [button map & combo guide](../firmware/include/ButtonManager/README.md#button-map), [filter types](../firmware/include/EnvelopeFollower/README.md#filter-types), [arp settings](../firmware/include/Arpeggiator/README.md#arp-settings), [MIDI types](../firmware/include/MIDIHandler/README.md#supported-message-types), [ARG methods](../firmware/include/EnvelopeFollower/README.md#arg-methods), [display hooks](../firmware/include/DisplayManager/README.md#key-methods).

## Choose Your Adventure

> Need a refresher before you dive? Hit the [MIDI + DSP 101 Primer](Primers/MIDI-DSP101.md) for channel lore, CC etiquette, and the envelope math our modules lean on.

- [BuildersHandbook.md](BuildersHandbook.md) — wire it, flash it, and smoke-test it.
- [Troubleshooting.md](Troubleshooting.md) — chase gremlins when the box won't boot or buttons go rogue.
- [HISTORY.md](HISTORY.md) — chronological ride through the project's evolution. Commit references, design pivots, and the "why" behind the build.
- [Options_DNI.md](Options_DNI.md) — the optional / Do Not Install cheat sheet. Use this before you lock a BOM or when you're deciding what not to solder.
- [PinMap.md](PinMap.md) — every MCU pin's mission and mayhem.
- [EEPROMLayout.md](EEPROMLayout.md) — where config bytes live and die.
- [FirmwareUpdate.md](FirmwareUpdate.md) — flash new brains without desoldering.
- [TESTING.md](TESTING.md) — unit tests to full-stack thrash sessions.
- [DemoPolish.md](DemoPolish.md) — runbook for final demo soak, EXT clock checks, panic-reset verification, and asset packing.
- [TODO.md](TODO.md) — post-release wishlist for when the first build is out and you're itching for v2.
- [ReleaseGuide.md](ReleaseGuide.md) — full release playbook. For quick steps see [Publishing a Release](../README.md#publishing-a-release).
- [../CONTRIBUTING.md](../CONTRIBUTING.md) — patch etiquette and repo contract.
- [sketch/](sketch/) — raw schematics and subsystem scribbles when you need the gory details.
  Highlights:
    - [buttonMatrix.md](sketch/systemFlow/hw/buttonMatrix.md) — how the 42-button grid scans its soul.
    - [display.md](sketch/systemFlow/hw/display.md) — wrangling pixels and I²C.
    - [envelopeFE.md](sketch/systemFlow/hw/envelopeFE.md) — analog envelope follower circuits.
    - Plenty more (midi opto, power antics, board PDFs) for late-night study.
- [WebSerial.md](WebSerial.md) — how the board chats with browsers, negotiates schema versions, and keeps presets safe.
- [OSCBridge.md](OSCBridge.md) — quickstart for OSC + virtual MIDI bridge usage, including DAW setup and troubleshooting.
- [BridgeForPerformers.md](BridgeForPerformers.md) — one-page show-day checklist for running bridge + OSC/DAW fast.
- [BridgePackaging.md](BridgePackaging.md) — implementation plan for shipping one-click bridge binaries/installers.
- [release/bridge-artifacts-checklist.md](release/bridge-artifacts-checklist.md) — per-release template for bridge binary assets, checksums, and sign-off.
- [thermal/](thermal/) — keep the silicon from frying itself.

## Exporting the narrative report

The long-form release report (`report-CDSsample.md`) is meant to ship right next to the binaries.
When you need a pretty PDF for Zenodo, a class handout, or a grant package, run our Pandoc helper:

```bash
./tools/render_report.sh
```

By default the PDF lands in `docs/dist/MOARkNOBS-42-report.pdf`. Set `PDF_ENGINE=xelatex`
if you prefer a different LaTeX backend than [Tectonic](https://tectonic-typesetting.github.io/).
Pass an alternate output directory as the first argument if you want the PDF elsewhere.

## Why these specific parts?

> Quick hits on why each chunk of silicon shows up and where SparkFun teaches the tricks. Longer sourcing diary still lives in
> [../hardware/Parts.md](../hardware/Parts.md) when you want BOM-level receipts.

- **Teensy 4.0** — horsepower with USB baked in. The [Teensy 4.0 Hookup Guide](https://learn.sparkfun.com/tutorials/teensy-40-hookup-guide) covers pinout, power, and programming basics.
- **CD74HC4067 analog mux** — collapses 42 buttons into one ADC read. The [16‑Channel Mux Breakout Guide](https://learn.sparkfun.com/tutorials/16-channel-analogdigital-multiplexer-breakout-cd74hc4067-hookup-guide) shows how to breadboard the trick.
- **SN74HCT245 level shifter** — keeps 5 V button buses from smoking the 3 V3 MCU. SparkFun's [Logic Level Shifting 101](https://learn.sparkfun.com/tutorials/logic-level-shifting) explains the voltage translation.
- **6N138 optocoupler** — isolates MIDI IN. SparkFun's [MIDI Tutorial](https://learn.sparkfun.com/tutorials/midi-tutorial/all) breaks down DIN wiring and opto‑isolation.
- **MCP6002 op‑amp** — rectifies audio for the envelope followers. SparkFun's [Op-Amp Basics](https://learn.sparkfun.com/tutorials/op-amps/all) digs into precision rectifiers and biasing.
- **WS2812 LEDs** — one data pin, full-color rage. SparkFun's [WS2812 Breakout Hookup Guide](https://learn.sparkfun.com/tutorials/ws2812-breakout-hookup-guide) covers timing and power layout.

### Lab Playlist: choose your own adventure

Warm up your brain before flashing firmware.

- [Logic Level Shifting 101](https://learn.sparkfun.com/tutorials/logic-level-shifting) — keep 5 V gear from roasting 3 V3 brains.
- [Demystifying SPI](https://learn.sparkfun.com/tutorials/serial-peripheral-interface-spi) — the bus behind future displays and flash chips.
- [UART vs. MIDI](https://learn.sparkfun.com/tutorials/midi-tutorial/all) — MIDI rides a current loop, not plain UART; this primer shows the difference.
- [Op-Amp Basics](https://learn.sparkfun.com/tutorials/op-amps/all) — build envelope followers, filters, or fuzz boxes without fear.

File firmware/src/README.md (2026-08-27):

# Source Files and Test Mayhem

Welcome to the belly of the beast. This folder splits into two gangs:

- **Core firmware** — the `.cpp` files that actually make the MN42 sing. Stuff like `Arpeggiator.cpp`, `ButtonManager.cpp`, and `firmware_main.cpp` get baked into the shipping build.
- **Machine tests** — `*_t.cpp` hardware harnesses you flash and exercise manually. Unity smoke tests live separately in `../test/test_*.cpp`.

## Source ↔ Docs Fast Lane

If you're trying to understand the firmware as a machine instead of chasing one
module in isolation, start with
[firmware_main.cpp](firmware_main.cpp) and the ordered walkthrough in
[../../docs/firmware/FirmwareMainReadingPath.md](../../docs/firmware/FirmwareMainReadingPath.md).

If you're trying to grok what a file is supposed to do, jump straight to its manifesto:

- [Arpeggiator.cpp](Arpeggiator.cpp) → [../include/Arpeggiator/README.md](../include/Arpeggiator/README.md)
- [ButtonManager.cpp](ButtonManager.cpp) → [../include/ButtonManager/README.md](../include/ButtonManager/README.md)
- [ConfigManager.cpp](ConfigManager.cpp) → [../include/ConfigManager/README.md](../include/ConfigManager/README.md)
- [DisplayManager.cpp](DisplayManager.cpp) → [../include/DisplayManager/README.md](../include/DisplayManager/README.md)
- [EnvelopeFollower.cpp](EnvelopeFollower.cpp) → [../include/EnvelopeFollower/README.md](../include/EnvelopeFollower/README.md)
- [LEDManager.cpp](LEDManager.cpp) → [../include/LEDManager/README.md](../include/LEDManager/README.md)
- [MIDIHandler.cpp](MIDIHandler.cpp) → [../include/MIDIHandler/README.md](../include/MIDIHandler/README.md)
- [MidiInputRouter.cpp](MidiInputRouter.cpp) → profile-owned inbound CC matching and pickup
- [MachineParameterService.cpp](MachineParameterService.cpp) → normalized internal/slot mutation boundary
- [PotentiometerManager.cpp](PotentiometerManager.cpp) → [../include/PotentiometerManager/README.md](../include/PotentiometerManager/README.md)
- [protocol/Protocol.cpp](protocol/Protocol.cpp) → [protocol/README.md](protocol/README.md)

## Run the Tests

Each test rides its own PlatformIO environment. To see one roar, run the matching command from the `firmware/` directory:

```bash
pio run -e teensy40_full_system               # builds src/main_t.cpp
pio run -e teensy40_unified_test              # builds src/unified_t.cpp
pio run -e teensy40_display_alive             # builds src/display_alive_t.cpp
pio run -e teensy40_biquad_test               # builds src/biquadfilter_t.cpp
pio run -e teensy40_eeprom_persistence        # builds src/eeprom_persistence_t.cpp (LittleFS default)
pio run -e teensy40_slot_verify               # builds src/verify_slots_t.cpp (LittleFS default)
```

Use these to keep your mods honest. Compile, flash, repeat—no fear, no mercy.

## Jitter Tuning

Hold `Ctrl0 + Ctrl3 + Ctrl4` and turn control pots to tune Perlin jitter:
- Pot 0: depth (`Jitter: 0.35`)
- Pot 1: smoothness (`Smooth: 0.42`)

## Live Surface Shortcuts

Outside config and LFO-tune modes, use these gestures to edit the active slot live:

- Double-press `Ctrl3`: cycle EF oversampling through 1x/2x/4x/8x/16x/32x.
- Double-press `Ctrl4`: toggle ARG on/off while retaining its selected method and sources.
- Press `Ctrl0+Ctrl1+Ctrl4`: toggle fixed LFO 1 modulation. A new lane starts Centered at 100%; disabling it retains that tuning.

Ctrl3 and Ctrl4 retain their exclusive 300 ms double-press window. Ctrl5 has no double-press action and sends each tap-tempo press immediately on release. See the [ButtonManager field guide](../include/ButtonManager/README.md) for the complete map.

## MIDI Nerd Notes

`MIDIHandler.cpp` now speaks RPN and can sniff out universal SysEx packets. If you're poking at the MIDI spec, this is your playground to see how the fancy stuff maps to code.

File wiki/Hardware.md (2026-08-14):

# Hardware

Hardware artifacts live in `hardware/` and supporting diagrams in `docs/sketch/`.
Canonical source: `hardware/README.md`

## Core board characteristics

- Teensy 4.0 controller
- 42-button matrix via multiplexers
- 42 multiplexed physical potentiometer/control slots
- 52 WS2812 LEDs
- 6 envelope follower inputs
- MIDI I/O over DIN and TRS Type-A

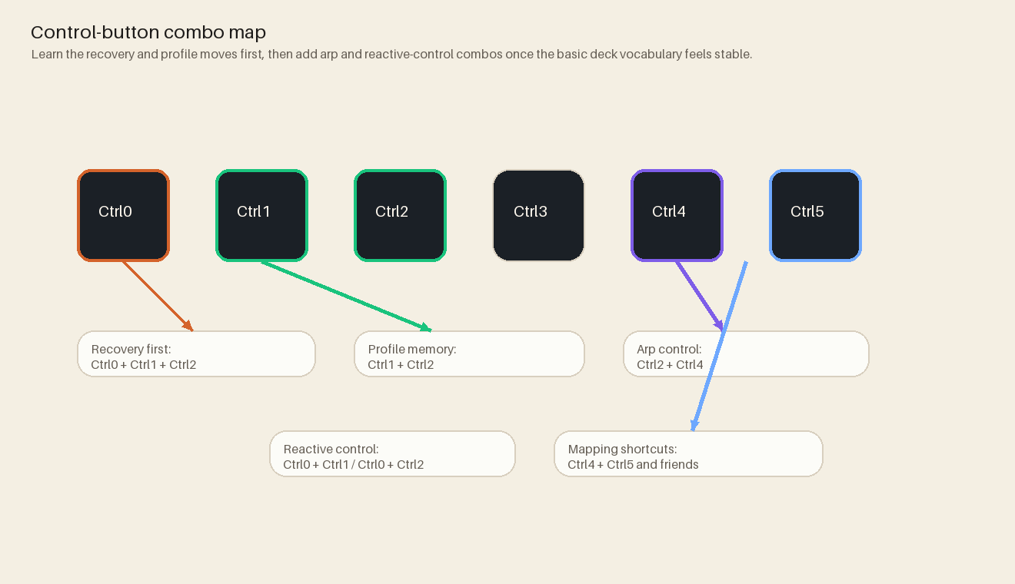
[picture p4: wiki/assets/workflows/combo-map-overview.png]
Control-surface map showing the six control buttons and their recovery, profile-memory, arpeggiator, reactive-control, and mapping shortcut families.


## Build and fabrication assets

- [Power, button, and LED schematic](../docs/assets/board/SCH_MOAR_Schematic_1-PWR-BUTTON-LED_2026-08-13.png)
- [Interface, MIDI, and control schematic](../docs/assets/board/SCH_MOAR_Schematic_2-INTERFACE-MIDI-CNTRL_2026-08-13.png)
- [Six-channel envelope schematic](../docs/assets/board/SCH_MOAR_Schematic_3-ENVELOPE_2026-08-13.png)
- [Top](../docs/assets/board/prodTOP.jpg), [bottom](../docs/assets/board/prodBTM.jpg), and [trace-inspection](../docs/assets/board/trace.jpg) board photos
- [Fabrication boundary note](../hardware/fabrication/README.md) (no orderable Gerber/BOM package is currently enclosed)

## Design docs

- Hardware overview: `hardware/README.md`
- Part rationale: `hardware/Parts.md`
- System flow sketches: `docs/sketch/systemFlow/hw/`
- Pin mapping: `docs/reference/PinMap.md`

## Electrical and safety notes

- Use a regulated `5 V DC` supply: `5 V / 4 A` minimum, or `5 V / 5 A` for LED-heavy tests.
- Do not feed `9 V` or `12 V` into the board's VIN path unless a documented regulator or buck stage has been added.
- Keep logic, LED, MIDI, and envelope-follower grounds common.
- Before full-strip white, blast, or burn-in testing, meter whether `F1` and `F2` are parallel branches. If `F2` is downstream of `F1`, the `0.5 A` PTC limits the whole machine; firmware brightness caps do not correct that topology.
- Keep LED power rails wide (>= 0.5mm traces in PCB CAD revisions).
- Respect fused rails and common ground wiring practices.
- Verify power polarity before first boot and rework.

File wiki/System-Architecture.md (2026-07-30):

# System Architecture

MOARkNOBS-42 has four main layers:
Canonical source: `README.md`

1. Hardware controller (Teensy + buttons + pots + LEDs + envelope inputs + MIDI I/O)
2. Firmware runtime (schedulers, protocol, managers, persistence)
3. WebSerial configuration app (`App/`)
4. Node OSC/MIDI bridge (`bridge/`)

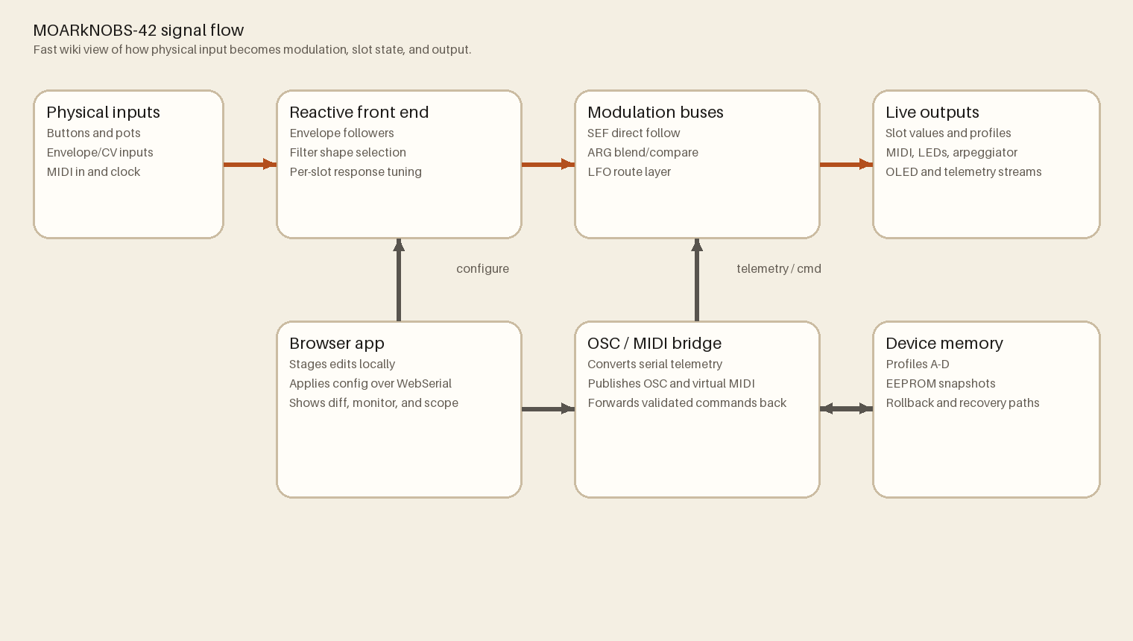
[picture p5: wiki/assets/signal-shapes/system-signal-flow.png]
System diagram showing physical inputs feeding the reactive front end, then modulation buses, then live outputs, with the browser app, OSC/MIDI bridge, and device memory connected as the operator and host-control layers around that path.


## Data flow

1. Human input enters from button matrix, control buttons, pots, and envelope follower analog inputs.
2. Firmware updates slot state, modulation state (EF/ARG/LFO/arp), and output buses.
3. Firmware emits MIDI and telemetry over serial/WebSerial.
4. Bridge converts telemetry to OSC/MIDI and forwards external commands back to firmware.
5. Web app stages config, validates schema, and applies updates via serial protocol.

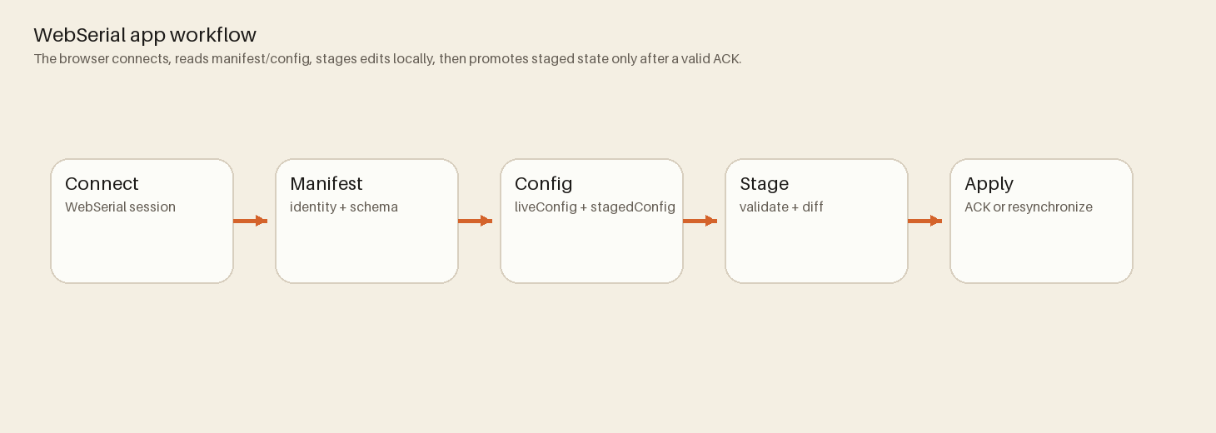
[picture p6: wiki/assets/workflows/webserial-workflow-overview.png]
WebSerial workflow showing connection, manifest and schema discovery, configuration read, local staging, validation, then Apply confirmation or resynchronization.


## Firmware runtime organization

- `SystemState`: shared object ownership and wiring
- `Protocol`: serial command handling + JSON/RPC contract
- `Modes`: profile + slot behavior
- `UI`: OLED/LED/button interaction layer
- `Runtime`: scheduler servicing and task orchestration

## Persistent configuration

- Transactional, generation-backed LittleFS stores durable configuration,
  profiles, macros, and scenes.
- Two data generations plus redundant metadata keep an incomplete write from
  becoming authoritative.
- At boot, firmware selects the newest valid generation or falls back to
  defaults when neither validates.
- The old schema-4 EEPROM offset map is historical documentation, not the
  current persistence contract.

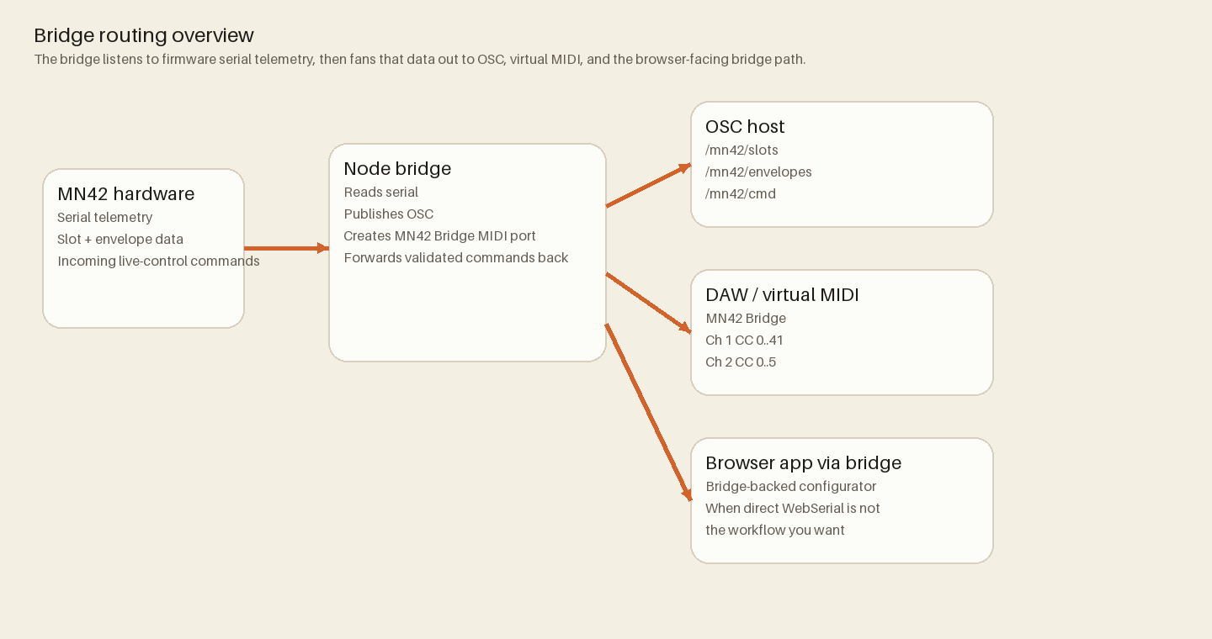
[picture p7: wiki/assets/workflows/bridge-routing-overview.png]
Bridge routing overview showing the hardware serial connection entering the Node bridge and branching to OSC, virtual MIDI, and the browser configurator.


## Primary source references

- `README.md` (root architecture narrative)
- `firmware/README.md` (runtime details)
- `docs/guides/WebSerial.md` (host contract and message flow)
- `docs/guides/OSCBridge.md` (bridge transport behavior)
- `docs/reference/PersistenceContract.md` (current LittleFS commit model)

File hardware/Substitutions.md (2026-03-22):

# Parts Substitutions

This page is a conservative sourcing guide for builders. It only records what can be stated without inventing electrical equivalence.

If a substitute is not documented in repo evidence, it is marked `UNVERIFIED — needs bench validation`.

## Substitution Table

| Function | Current part | Sourcing risk | Known substitute | Verification status | Notes |
| --- | --- | --- | --- | --- | --- |
| MCU / USB MIDI host brain | Teensy 4.0 | High | No repo-documented direct substitute | No substitute documented in repo | Board docs and firmware docs assume Teensy 4.0 specifically. |
| Button matrix analog mux | CD74HC4067 | Medium | No repo-documented direct substitute | No substitute documented in repo | Treat family swaps as risky until channel behavior and control logic are bench-validated. |
| 5 V to 3V3 logic translation | SN74HCT245 | Medium | No repo-documented direct substitute | No substitute documented in repo | Direction, thresholds, and timing should be treated as validation items, not assumptions. |
| Envelope follower op-amp stage | MCP6002 | Medium | `UNVERIFIED — needs bench validation` | Unverified | Any alternate op-amp must be checked for supply range, input behavior, and envelope response on the bench. |
| MIDI IN isolation | 6N138 | Medium | `UNVERIFIED — needs bench validation` | Unverified | The repo mentions the 6N138 path but does not document a validated alternate optocoupler. |
| Addressable indicator LEDs | WS2812-style LEDs | Medium | `UNVERIFIED — needs bench validation` | Unverified | The repo documents a WS2812-style family, not a single verified purchasing SKU or package variant. |
| OLED display | SSD1306 OLED | Medium | `UNVERIFIED — needs bench validation` | Unverified | The repo documents SSD1306 usage, but not a validated alternate module list. |
| MIDI connectors | 5-pin DIN plus 1/8 in TRS Type-A | Low | No repo-documented substitute list | No substitute documented in repo | Mechanical footprint and Type-A wiring should be treated as fit checks. |
| Power protection | 0.5 A logic PTC and 2.5 A LED PTC | Medium | `UNVERIFIED — needs bench validation` | Unverified | Hold current, trip current, and physical footprint should be confirmed before substitution. |

## How To Use This Page

1. Prefer the documented part when you can source it.
2. If you must substitute, treat `UNVERIFIED` literally and test the affected subsystem before a full build.
3. If you validate a substitute on real hardware, update this file with the exact part number and the test evidence that proved it.

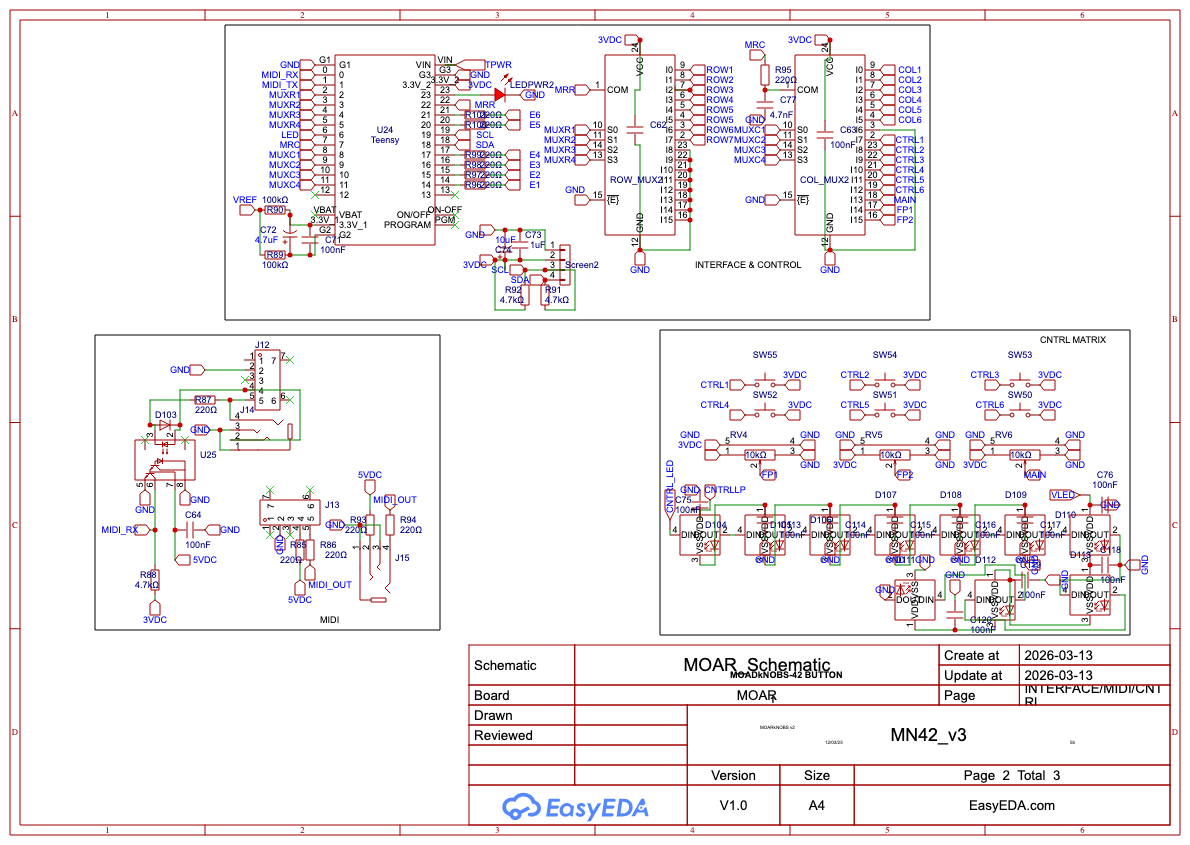
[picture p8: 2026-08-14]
docs/assets/board/SCH_MOAR_Schematic_2-INTERFACE-MIDI-CNTRL_2026-08-13.png

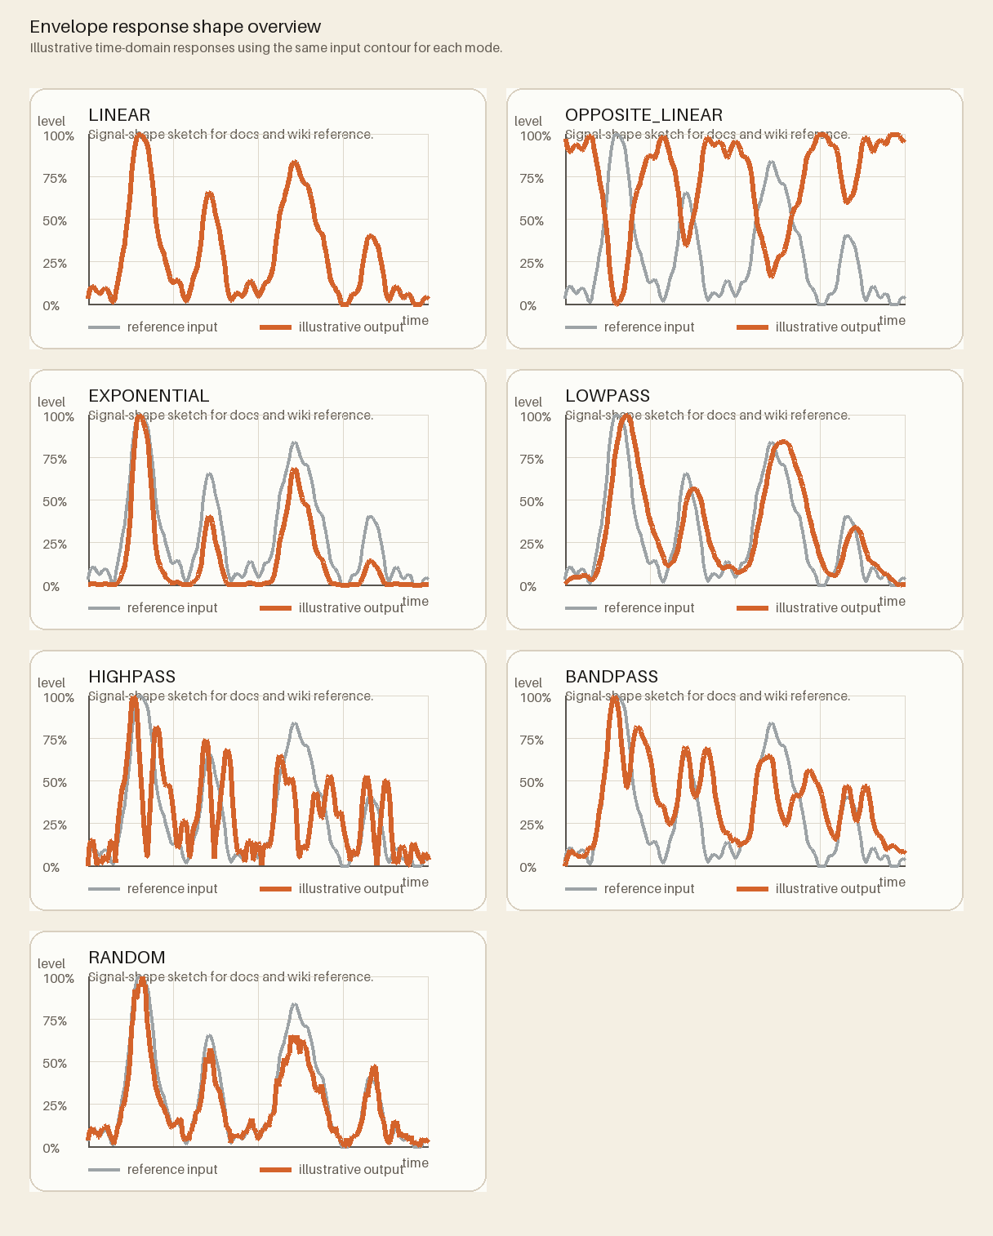
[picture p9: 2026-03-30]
docs/assets/signal-shapes/filter-shapes-overview.png

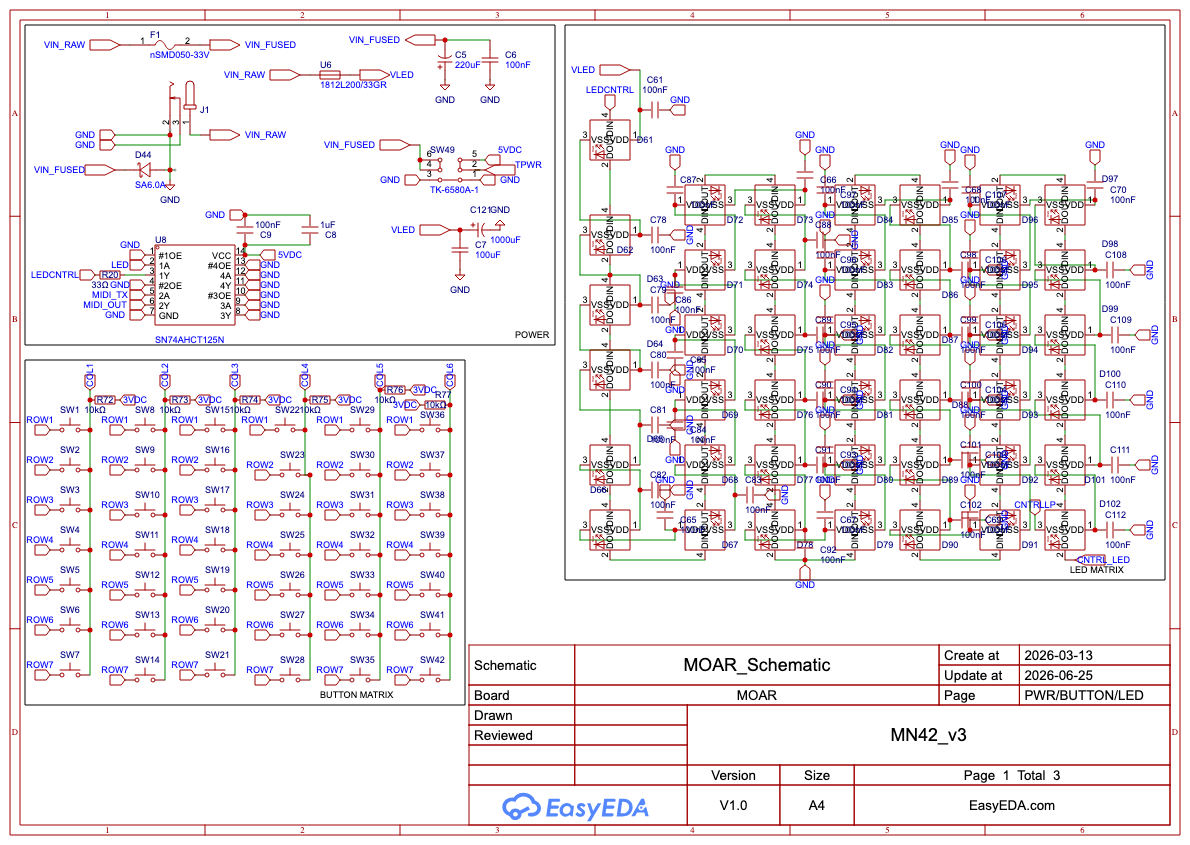
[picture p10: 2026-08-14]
docs/assets/board/SCH_MOAR_Schematic_1-PWR-BUTTON-LED_2026-08-13.png

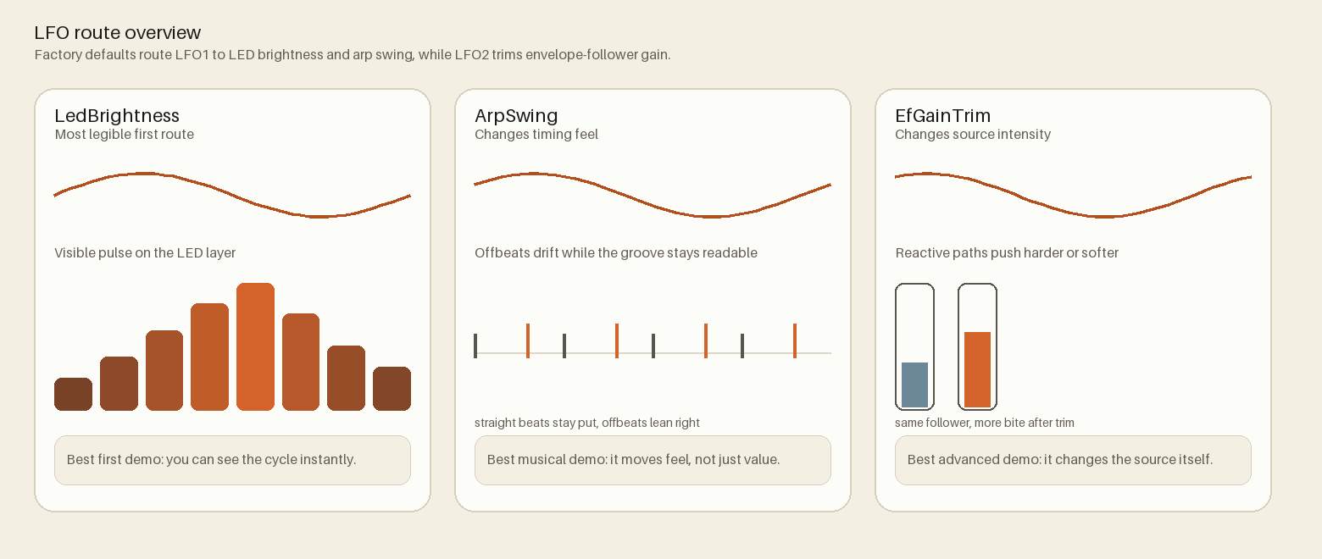
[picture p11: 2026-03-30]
docs/assets/signal-shapes/lfo-route-overview.png

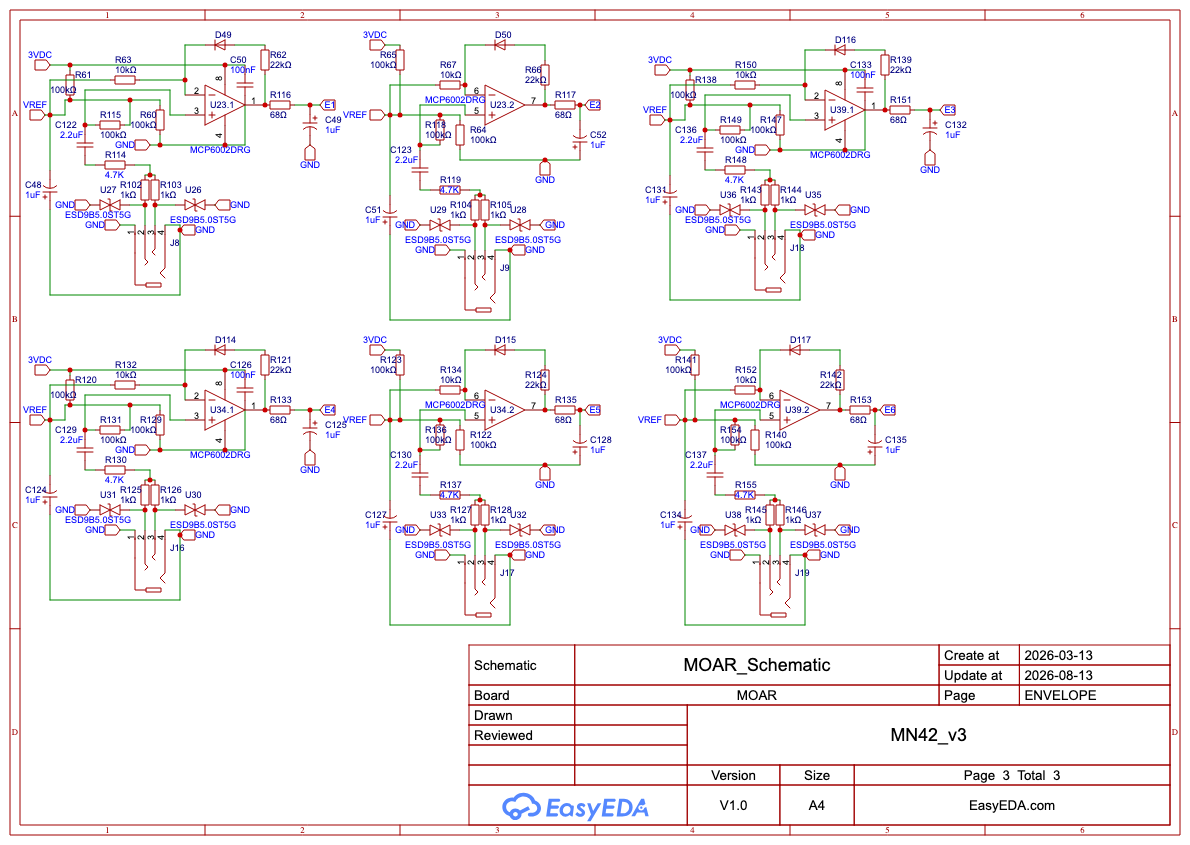
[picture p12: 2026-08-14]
docs/assets/board/SCH_MOAR_Schematic_3-ENVELOPE_2026-08-13.png

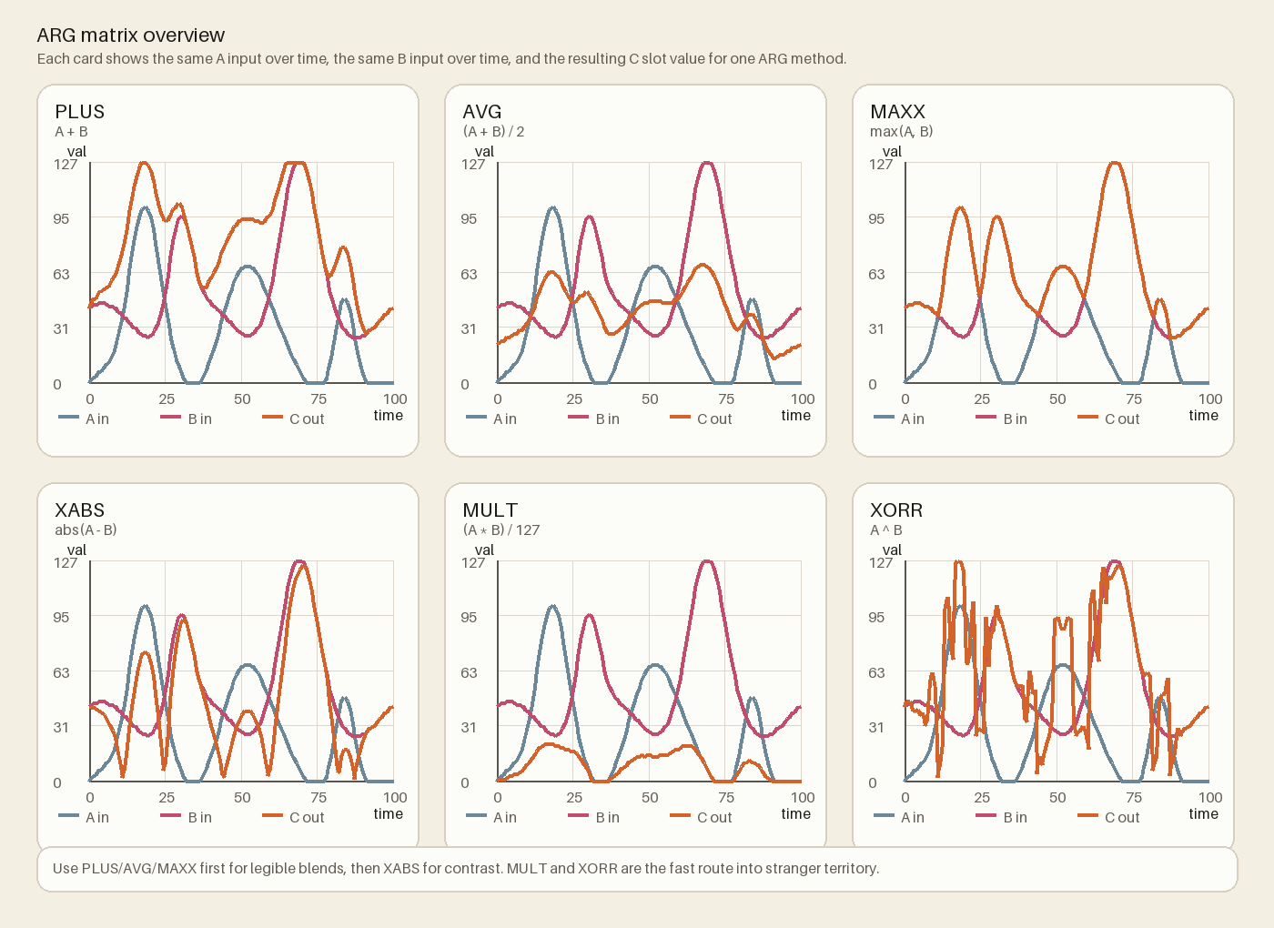
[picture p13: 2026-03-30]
wiki/assets/signal-shapes/arg-matrix-overview.png

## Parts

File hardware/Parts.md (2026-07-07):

# Parts & Rationale

> The silicon misfits that make this controller sing; this is the canonical stash for why each part earned a seat on the board.

For the current hardware file status, start with [CurrentBuild.md](CurrentBuild.md). For sourcing risk and conservative alternates, see [Substitutions.md](Substitutions.md).

## Teensy 4.0

600 MHz ARM core with native USB MIDI. SparkFun's [Teensy 4.0 Hookup Guide](https://learn.sparkfun.com/tutorials/teensy-40-hookup-guide) walks through pinout, power rails, and flashing without bricking.

## CD74HC4067 analog mux

Collapses forty‑two buttons into one ADC read. The [16‑Channel Mux Breakout Guide](https://learn.sparkfun.com/tutorials/16-channel-analogdigital-multiplexer-breakout-guide) shows how to fan-in a forest of switches and breadboard it before spinning copper.

## SN74HCT245 level shifter

Keeps the 5 V button grid and LED strip from punching the 3 V3 brain. SparkFun's [Logic Level Shifting 101](https://learn.sparkfun.com/tutorials/logic-level-shifting) explains the voltage‑translation sleight of hand.

## Power rails + fuses

Splitting the 5 V logic rail from the 5 V LED rail keeps noise off the MCU while the strip parties. Inline PTC fuses (0.5 A for logic, 2.5 A for LEDs) fail safe if you cross-wire or short a pixel. SparkFun's [Fuse Tutorial](https://learn.sparkfun.com/tutorials/fuses) is the quick refresher on why these little resettable bricks earn their keep.

## MCP6002 op-amp

Rectifies and smooths incoming audio for the envelope followers. SparkFun's [Op-Amp Basics](https://learn.sparkfun.com/tutorials/op-amps/all) covers precision rectifiers and bias tricks.

## 6N138 optocoupler

Gives MIDI IN its own electrical bubble. SparkFun's [MIDI Tutorial](https://learn.sparkfun.com/tutorials/midi-tutorial/all) breaks down current loops, DIN vs. TRS jacks, and why opto‑isolation matters.

## WS2812 LEDs

One data pin, a riot of color on 52 diodes. SparkFun's [WS2812 Breakout Hookup Guide](https://learn.sparkfun.com/tutorials/ws2812-breakout-hookup-guide) dives into timing and power decoupling so you don't brown‑out the strip.

Need swap-friendly alternates or board placement notes? Hop back to the [hardware README](README.md) for the condensed build sheet and layout lore, then check [Substitutions.md](Substitutions.md) before making part swaps.

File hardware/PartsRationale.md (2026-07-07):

# Why These Specific Parts?

Here’s the long-form rant the landing page no longer has space for: every part on this board is picked because it either keeps the rig stable under demo abuse or makes the learning story cleaner. Grab the cheat-sheet vibe from the README, then come here when you want the receipts.

## Teensy 4.0: the loud brain

Teensy 4.0 gives us a 600 MHz core, USB MIDI baked in, and a dev community that actually debugs in public. It’s overkill on clock speed, which means we can waste cycles on clarity—more comments, more guard rails—without dropping frames on the LED strip or choking MIDI. If you want to contrast it with STM32 or RP2040 in a workshop, the code paths here make the trade-offs obvious.

## CD74HC4067 analog mux: button crowd control

Forty-two buttons would eat every pin on the board, so a 16-channel analog mux does the crowd control. It keeps the PCB routing sane, demonstrates address-line timing, and still leaves room to tack on extra sensors if you’re hacking live. Students see the mux logic in `ButtonManager` and immediately grok why scan timing matters.

## SN74HCT245 level shifter: peace between voltage islands

The button matrix and LEDs live at 5 V; the MCU chills at 3.3 V. A simple HCT245 keeps everyone polite without resorting to exotic bidirectional boards. It’s cheap, forgiving, and a perfect excuse to teach why voltage translation belongs near the noisy peripherals instead of in firmware hacks.

## Power rails + fuses: controlled chaos

Splitting the logic and LED rails keeps digital noise out of the audio and UI paths. PTC fuses (0.5 A for logic, 2.5 A for LEDs) add idiot-proofing so beginners can botch a solder joint without letting the magic smoke out. The layout leaves clear test points so you can probe sag and ripple when you want to nerd out about decoupling.

## MCP6002 op-amp: envelope honesty

The MCP6002 rectifies and smooths the incoming audio so the envelope follower doesn’t lie. It runs happily on the same 5 V rail as the rest of the front-end and tolerates the clumsy inputs you get during workshops. It’s also a great teaching moment for precision rectifiers without dragging in exotic op-amps.

## 6N138 optocoupler: MIDI quarantine

MIDI IN gets its own electrical bubble via a 6N138. It keeps laptop ground loops from turning into hum on the LEDs and doubles as a live demo of why opto-isolation exists. DIN and TRS wiring both behave once you follow the datasheet, so you can hot-swap cables mid-demo without fear.

## WS2812 LEDs: maximal spectacle

One data pin drives 52 diodes and the timing quirks make for excellent debugging theater. They’re noisy enough to justify the power rail isolation, and the DMA tricks in firmware show exactly how to feed them without starving MIDI. If you want calmer lights, swap the strip, but the WS2812 drama makes the lessons stick.

Need alternate part numbers, footprints, or sourcing links? The shopping list and board notes stay in the [hardware README](README.md) and the quick reference tables live in [hardware/Parts.md](Parts.md). Grab those when you’re ordering; come back here when you want to explain why this BOM earns its keep.

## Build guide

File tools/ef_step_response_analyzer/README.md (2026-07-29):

# EF Step Response Analyzer

Open `EfStepResponseAnalyzer.pde` in Processing 4 and press `O` to select a
CSV from `tools/ef_latency_logger/EfLatencyCsv.pde`. The sketch groups samples
by EF and slot, infers monotonic rises/releases, and exports one row per
meaningful response run with:

- observed MIDI-output 10–90% duration;
- event cadence;
- mean device sample-to-MIDI-enqueue latency; and
- the output range and sample count used for each result.

The analyzer ignores movements under 16 MIDI values and splits runs after a
100 ms sample gap or a meaningful direction reversal. Those thresholds are in
the sketch constants so a bench operator can make them stricter for a noisy
signal.

The result describes the observed **translated MIDI output response**. It does
not establish analog EF circuit rise/release time from an external stimulus or
physical host MIDI-arrival latency. Use a shared trigger and scope/logic
analyzer when those measurements are required.

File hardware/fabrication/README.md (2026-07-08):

# MOARkNOBS-42 Fabrication Artifacts

This directory is the canonical location for verified PCB manufacturing documents when they exist, primarily **Gerber / NC Drill packages** needed to duplicate the physical board cleanly.

## Currently Omitted

At present, **no orderable fabrication packages are enclosed**.
The tracked contents of this directory are currently limited to this `README.md` boundary note. No current BOM, Gerber archive, NC-drill archive, pick-and-place export, or assembly package is tracked here.

The repository intentionally delays supplying push-button manufacturing `.zip` drops until the prototype layout and bring-up findings have completed release-level hardware checks. Consequently, the distributed hardware asset constitutes a **reference bundle**: useful for code review, schematic tracing, bench validation, and planning, but not a factory-ready fabrication package.

When a verified revision is confirmed, standardized manufacturing artifacts should be added here with explicit version and validation notes.

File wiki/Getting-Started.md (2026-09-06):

# Getting Started

This is the finished-instrument path from cable to one saved, playable setup.
You do not need PlatformIO, Python, or the firmware source to follow it.
Canonical source: `docs/getting-started/QuickstartForPerformers.md`

## 1. Connect safely

1. Use a known-good USB **data** cable, not a charge-only cable.
2. Connect the instrument through its normal documented USB/power arrangement.
3. Wait for the Teensy USB device to appear before opening another serial tool.
4. Do not open the browser configurator and Bridge against the same serial port
   at the same time.

If the instrument does not enumerate, go directly to
[Connect did nothing](Troubleshooting.md#connect-did-nothing).

## 2. Choose the simpler connection

| Your goal | Open this | Connection |
| --- | --- | --- |
| Configure one instrument, inspect it, or manage profiles | Browser configurator supplied with the instrument | Direct WebSerial in a Chromium-based browser |
| Use OSC, a DAW-facing MIDI route, or App-over-Bridge | MN42 Bridge console | Bridge session |

Start with direct WebSerial unless OSC or DAW routing is part of tonight's
session. If you received the instrument with a hosted configurator URL, open
that. Running the App or Bridge from a source checkout belongs in
[Developer Setup](Developer-Setup.md).

If neither a configurator URL nor an MN42 Bridge application was supplied, the
current hardware-test package does not yet provide a zero-setup end-user
launcher; use Developer Setup or ask the instrument builder for the matching
App/Bridge artifact.

## 3. Confirm recognition

In the configurator:

1. click **Connect**
2. choose the MOARkNOBS-42/Teensy serial device
3. wait for the banner to show the device identity and firmware
4. confirm the transport/contract indicator is verified

In the Bridge console, wait until **Bridge**, **Serial**, and **Device** all
report ready, then choose **Open configurator**.

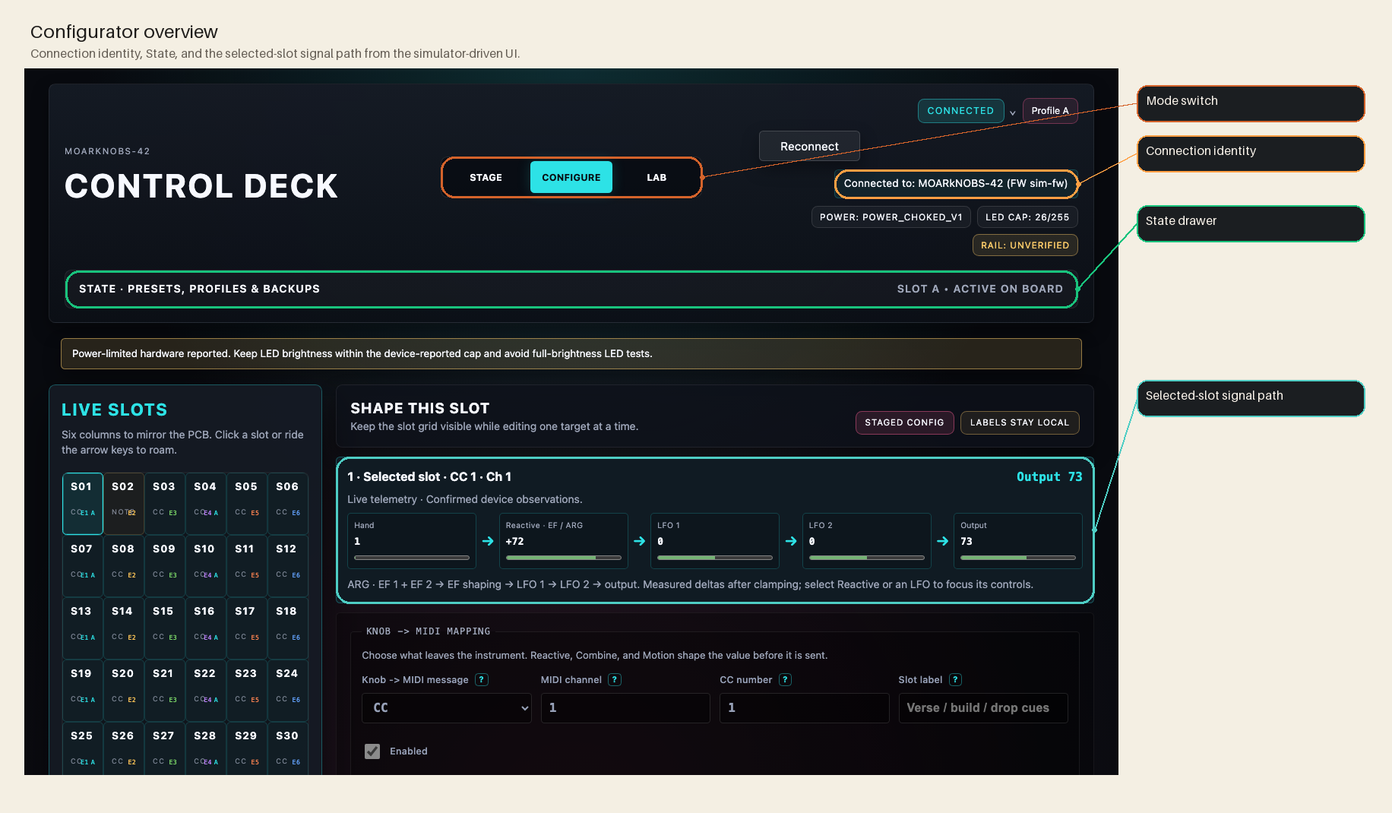
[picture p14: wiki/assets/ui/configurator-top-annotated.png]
Annotated configurator overview identifying the mode switch, connection identity, State drawer, and selected-slot signal path.


For an already-configured instrument at a performance, select **Stage** in the
top mode switch. It shows connection/telemetry health, profile and scene
recall, slot activity, envelope levels, and panic help without exposing staged
editors or Apply controls. If the dashboard says a draft is staged, resolve it
in Configure or Lab before any profile or scene recall.

## 4. Load one known starting point

For the shortest first pass:

1. switch the configurator to **Configure** or **Lab**
2. choose `DEMO_A - Reactive Stack` from the preset picker
3. confirm the staged-diff area becomes visible
4. click **Apply**

For an exact DAW/synth exercise with a downloadable JSON configuration, use
[First Playable Walkthrough](Playable-Walkthrough.md).

## 5. Move, listen, and look

A successful first checkpoint has three kinds of evidence:

- moving an enabled control changes its slot value and emits MIDI
- a receiving synth or DAW reacts to the mapped message
- the slot/LED and configurator telemetry move with the control or envelope

If the browser changes but the synth does not, use
[MIDI is not reaching the DAW](Troubleshooting.md#midi-is-not-reaching-the-daw).

## 6. Interpret Apply honestly

- **Synced** or verified readback: the captured configuration became device
  truth.
- **No device write needed**: the normalized device state was already the same.
- **Applied captured configuration / newer edits remain staged**: the captured
  version applied, but later edits are still local.
- **Apply rejected before transmission**: correct or refresh, then retry; the
  device was not written by that attempt.
- **Apply outcome uncertain**: stop editing and let authoritative readback
  finish. Do not assume success or rollback.
- **Device differs**: device truth is known, but it does not match the attempted
  candidate; the draft remains available.

## 7. Save it

After the device is verified and the staged diff is clean:

1. choose profile `A`, `B`, `C`, or `D`
2. click **Save profile**
3. use **Download profile/configuration** for an external JSON backup
4. switch away and back once to prove recall before relying on it live

Profiles use the current generation-backed LittleFS persistence system, not the
historical EEPROM layout.

## 8. Learn one recovery move

The panic-safe hardware combo is `Ctrl0 + Ctrl1 + Ctrl2`. It stops the arp,
disables EF follow, and reloads the active profile baseline.

Keep [Troubleshooting](Troubleshooting.md) open during the first session. It is
organized by the symptom you see, not by repository subsystem.

## Next useful pages

- [First Playable Walkthrough](Playable-Walkthrough.md)
- [Configure in Browser](WebSerial-App.md)
- [Connect to DAW / OSC](OSC-Bridge.md)
- [Save and recall profiles](WebSerial-App.md#save-recall-and-back-up)
- [Developer Setup](Developer-Setup.md)

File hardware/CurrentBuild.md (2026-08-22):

# Current Hardware Build

This is the hardware status page for the hardware-test package.

Last audited against repo contents: 2026-08-22.

Audit status: prototype bring-up references are present and current for the hardware-test package; no verified fabrication bundle or current fabrication BOM is tracked.

## Package Scope

This package supports prototype bench validation.
It does not claim fabrication readiness.
The tracked `hardware/fabrication/` tree currently contains only `README.md`, which is a boundary note rather than a manufacturing artifact.

## Physical Board Status

Prototype PCBs have been received and are now part of the hardware-test loop. The current work is bring-up evidence,
not production sign-off: power-rail checks, OLED/control validation, MIDI path testing, envelope follower behavior,
LED load testing, and host connectivity through the WebSerial App and bridge.

The fabricated boards are clean enough to make the prototype review useful. Current faults and caveats are being treated
as design and integration findings in this machine unless later bench evidence points to a fabrication-quality problem.
The 0.5 mm test pads visible across the current board are usable for probing during this bench-review phase.

Board photos currently present:

- top-side photo: `docs/assets/board/prodTOP.jpg`
- bottom-side photo: `docs/assets/board/prodBTM.jpg`
- trace-inspection photo: `docs/assets/board/trace.jpg`
- assembled bench-context photo: `docs/assets/board/bench.jpg`
- powered bring-up context photo: `docs/assets/board/bringup.jpg`
- early Teensy breadboard harness photo: `docs/assets/board/test.jpg`
- raw historical assembly-photo archive: `hardware/archive/T-3D5W706139A/`

These images are public breadcrumbs for the prototype story. They do not replace measured inspection notes, serial logs,
or dated bench receipts.

## Current Hardware References

| Item | Path | Status | Use in this package |
| --- | --- | --- | --- |
| Power/button/LED schematic | [sheet 1](../docs/assets/board/SCH_MOAR_Schematic_1-PWR-BUTTON-LED_2026-08-13.png) | present | Power, button-matrix, and LED reference for bench validation |
| Interface/MIDI/control schematic | [sheet 2](../docs/assets/board/SCH_MOAR_Schematic_2-INTERFACE-MIDI-CNTRL_2026-08-13.png) | present | Teensy interface, MIDI, OLED, and direct-control reference |
| Envelope schematic | [sheet 3](../docs/assets/board/SCH_MOAR_Schematic_3-ENVELOPE_2026-08-13.png) | present | Six-channel envelope-input reference |
| Fabrication directory contents | `hardware/fabrication/README.md` only | boundary note only | States that no orderable fabrication package is enclosed |
| Prototype BOM export | none tracked in `hardware/fabrication/` | absent | No current BOM file is present in this checkout; do not rely on older BOM names |
| Gerber / NC-drill archive | none tracked in `hardware/fabrication/` | absent | No verified fabrication bundle is present or claimed |
| Physical board photos | [top](../docs/assets/board/prodTOP.jpg), [bottom](../docs/assets/board/prodBTM.jpg), [trace](../docs/assets/board/trace.jpg), [bench](../docs/assets/board/bench.jpg), [bring-up](../docs/assets/board/bringup.jpg) | present | Public breadcrumb images for current prototype board review |

## How To Use This Folder

1. Use the three current schematic sheets and linked board photos to confirm the assembled prototype matches the expected wiring and layout.
2. Use [Parts.md](Parts.md) and [Substitutions.md](Substitutions.md) to review parts and likely substitutions before bench work.
3. If you are preparing manufacturing files, stop. This package does not certify a fabrication-ready output set.

## Known Design / Integration Findings

- The physical boards are suitable for probing and bring-up; no fabrication-quality blocker is claimed from the current
  photo and trace-inspection evidence.
- The tracked `hardware/fabrication/` directory is only a status note until verified manufacturing artifacts are added.
- Rail topology and high-current LED behavior still need dated bench evidence before this prototype can be described as
  release-ready.
- Any fault found during bring-up should be logged as a design/integration finding first, then reclassified only if direct
  inspection or measurement points to fabrication.

## What Is Not Verified Yet

- no verified Gerber plus NC-drill release bundle
- no tracked current BOM export in `hardware/fabrication/`
- no tracked fabrication artifact in `hardware/fabrication/` beyond the boundary README
- no claim that any fabrication archive has completed release-level checks
- no order-ready manufacturing sign-off from this package
- no claim that the physical prototype has completed full release-level hardware validation

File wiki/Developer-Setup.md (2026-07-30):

# Developer Setup

This page takes a contributor from a source clone to a firmware handshake,
local App, and optional Bridge.
Canonical source: `docs/project/ProcessOverview.md`

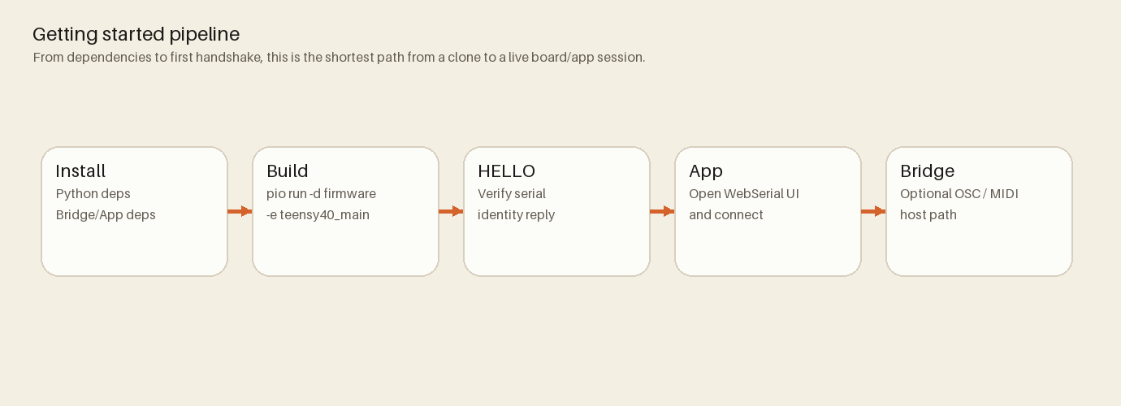
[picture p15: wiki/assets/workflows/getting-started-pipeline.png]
Pipeline graphic showing install, build, HELLO handshake, WebSerial app connection, and optional bridge setup.


## Prerequisites

- PlatformIO Core on PATH (`pio`)
- Node.js 24.x for Bridge/App tooling
- Python 3.11 or newer for repository helper scripts
- Teensy 4.0 connected over USB

## 1. Install dependencies

From repository root:

```bash
pip install -r requirements.txt
npm --prefix bridge ci
npm --prefix App ci
```

## 2. Build and upload firmware

The PlatformIO project root is `firmware/`:

```bash
pio run -d firmware -e teensy40_main
pio run -d firmware -e teensy40_main -t upload
```

## 3. Verify the serial handshake

Open a serial terminal and send:

```text
HELLO
```

Expected response includes:

```json
{ "hello": "mn42" }
```

## 4. Run the App locally

```bash
python3 -m http.server -d App
```

Open `http://localhost:8000/`, click **Connect**, and confirm manifest data
appears.

## 5. Run the Bridge when needed

```bash
node bridge/mn42_bridge.js --serial /dev/ttyACM0 --osc 9000 --osc-listen 9000 --host 127.0.0.1 --bind 127.0.0.1 --midi "MN42 Bridge"
```

Replace `/dev/ttyACM0` with the actual device path.

## Contributor routes

- `docs/project/ProcessOverview.md`
- `docs/getting-started/BuildersHandbook.md`
- `docs/validation/TESTING.md`
- [Wiki testing map](Testing.md)
- [Symptom-based troubleshooting](Troubleshooting.md)

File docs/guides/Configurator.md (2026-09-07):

# Configurator Tour

Current App contract/support boundary: [App/README.md](https://github.com/bseverns/MOARkNOBS-42/blob/main/App/README.md), [Host Compatibility](../reference/HostCompatibility.md), [Documentation Truth Map](../reference/DocumentationTruthMap.md).

The browser app is not just a remote control. It is the safest place to understand the firmware contract because it has to negotiate identity, schema compatibility, staged edits, and confirmation from the device before pretending anything changed.

Annotated browser configurator screenshot showing connection identity, the State drawer, and the selected-slot signal path.

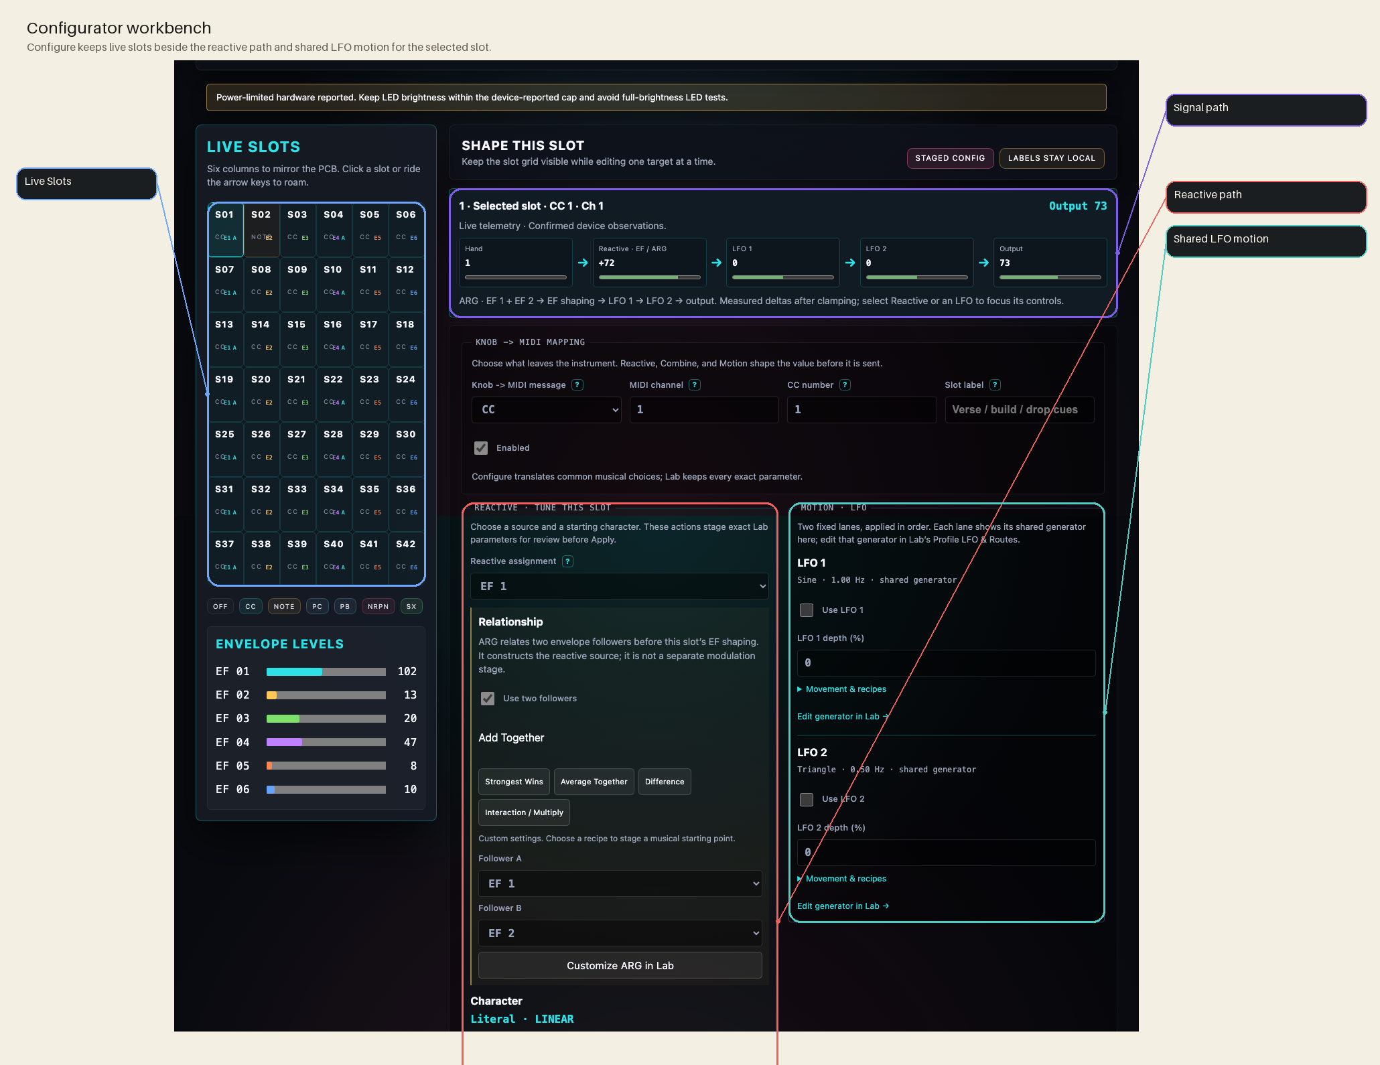
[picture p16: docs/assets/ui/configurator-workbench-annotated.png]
Annotated browser configurator screenshot showing live slots, the selected-slot signal path, Reactive shaping, and shared LFO Motion.


## The core idea

The configurator keeps two versions of the world:

- **live config** – what the device most recently confirmed
- **staged config** – what the user is currently editing

That split lets the UI show meaningful diffs and preserve local work. After transmission, an ambiguous outcome is resolved by authoritative device readback; it is not described as rollback. See [Configuration Transaction Model](../reference/ConfigurationTransactionModel.md).

## Connect flow

```mermaid
sequenceDiagram
  participant User
  participant App
  participant Device
  User->>App: Connect
  App->>Device: hello
  App->>Device: get_manifest
  Device-->>App: manifest
  App->>App: compare schema versions
  App->>Device: get_schema
  Device-->>App: schema
  App->>Device: get_config
  Device-->>App: config
  App->>App: seed liveConfig and stagedConfig
```

If the manifest schema does not match the app's local contract, the app raises a migration-required path before it allows live writes.

## What happens when you edit

Most controls do **not** immediately rewrite device state.

1. you change a field
2. the form system validates and clamps it against `config_schema.json`
3. the app mutates `stagedConfig`
4. the diff panel compares `stagedConfig` to `liveConfig`
5. Apply becomes available only when the staged payload is valid

Some controls can also issue field-level writes through the runtime patch lane, but even then the runtime stages locally first so the UI never loses track of intent. On native WebSerial, the production contract is still full Apply with verified ACK.

## Selected-slot tuning translates Lab; it does not replace it

Configure centers the selected slot with a persistent identity, mapping, measured output, and two musical shaping zones. It follows this progression:

```text
recipe -> musical feel -> translated summary -> exact Lab parameters
```

The App's `tuning_catalog.js` is presentation metadata only. It supplies musician-first labels, explanations, and deterministic recipe patches. `config_schema.json` still decides whether a configuration is structurally valid, and firmware/readback still decides what the device actually contains. The catalog is tested against the schema enum lists so it cannot silently add or omit a firmware value.

Configure exposes:

- **Source / Reactive assignment** — the exact EF assignment for this slot; when ARG is enabled, the assignment keeps the reactive path connected while ARG supplies its combined follower value
- **Character** — small selected-slot EF recipes such as Clean / Neutral, Smooth, Punchy, Gate, and Experimental
- **Response** — a readable summary derived from the exact smoothing, detector, attack, and release values; it is not a new firmware parameter
- **Amount** — Adaptive explicitly enables auto-gain; Subtle, Moderate, and Strong explicitly disable auto-gain and stage gain 0.5, 1, or 2. The summary retains the exact mechanism.
- **Direction** — a musical translation of the firmware destination mode, such as **Louder → more** or **Signal replaces value**; Lab retains the exact token.
- **Reactive relationship / ARG** — inside Reactive, enable two followers, choose source A/B, and stage Strongest Wins, Average Together, Difference, or Interaction recipes. ARG chooses the reactive input before the slot’s EF shaping; it is not an additional independent output delta. An EF assignment still gates this path.
- **Motion / LFO** — each fixed lane has its own switch and signed depth. Configure shows the current shared generator shape and rate, or marks an unsaved generator edit as a **local draft**. **Movement & recipes** discloses combine mode and centered-motion recipes; generator editing remains in Lab’s Profile LFO & Routes.

Lab keeps every underlying control. Enum choices lead with musical language while retaining the exact token, for example **Smooth · LOWPASS**, **Punchy · EXPONENTIAL**, **Average Together · AVG**, and **Strongest Wins · MAXX**.

Lab has two deliberate tiers. Its upper row keeps **Live Slots**, **Selected Slot**, and a compact **Session** context together. The full-width **Lab Bench** then opens one ownership room at a time:

- **Instrument** holds envelope assignments, filter/ARG compatibility controls, LED configuration, USB MIDI output, and Device Clock.
- **Profile** holds Profile Arp, Profile LFO & Routes, and Incoming MIDI for the selected A–D profile.
- **Observe** holds the Device Monitor, EF/LFO Scope, MIDI Monitor, and the read-only Modulation Matrix.
- **Evidence** holds Staged Diff, the Diagnostic Slot Inspector, and the Debug Log.

This does not reduce Lab coverage. It gives machine-wide settings, profile state, live observation, and diagnostic evidence separate destinations. Configure deep links open the matching room; **Edit generator in Lab** opens **Profile → Profile LFO & Routes** and focuses the chosen generator.

### State and exact Lab controls

**State · Presets, profiles & backups** groups starting presets, profile switching/saving, and JSON backups. Presets and imports stage a draft; Apply sends it; profile save persists it. Existing dirty-draft and capability guards remain in force. Opening the drawer does not issue a write.

Lab’s continuous slot parameters pair exact numeric inputs with sliders. Attack/release and other millisecond time constants use logarithmic travel; smoothing, gain, and lane depth use linear travel. Double-click a continuous control, or use its **Reset to confirmed** button, to stage the last confirmed field value. No reset writes immediately.

The smaller Apply dock reserves scroll space and keeps focused controls clear of it. Screenshot checks include the dock when dirty, rather than hiding it.

### Recipe boundaries

Recipes use the same staged config path as manual edits. They do not write immediately.

| Recipe family | Changes | Deliberately preserves |
| --- | --- | --- |
| EF character | selected slot's EF response fields | EF source, calibration baseline, gain, direction, every other slot |
| ARG | selected slot's enable + method | source A/B and every other slot |
| Fixed LFO | one selected slot-local lane | the other lane and every other slot |

Recipes show a persistent explanation below their controls, including on touch devices. Staged markers identify affected controls; Review remains the complete diff and focuses the corresponding Lab tab, slot, lane, and field. **Customize in Lab** opens the relevant exact controls, and **Return to Configure** preserves the selected slot and lane.

The signal strip displays hand/base → reactive EF/ARG delta → LFO 1 delta → LFO 2 delta → resolved output. Contribution graphics use one coherent device snapshot, never arithmetic reconstructed from staged settings. Missing or stale contribution data is explicitly unreported; no ARG-specific delta is invented.

The compact EF evidence line reuses the App's current telemetry snapshot: EF identity, active/recent/inactive state, current level, resolved slot output, EF contribution when reported, and gate threshold when relevant. It is host-observed visualization, not physical-device validation or latency measurement.

Simulator modulation is behavioral rehearsal, not analog calibration or hardware-validation evidence. Its deterministic LFO traces follow the declared shape, and its EF model intentionally maps only enough existing tuning fields to make recipe differences visible without claiming circuit fidelity.

When firmware sends a `slot_patch`, the App says **Device reported** because the frame proves device state but does not reliably prove whether the originating action was a deck press or another device-side path. Clean editor state follows that truth without becoming a false browser draft; unrelated staged intent is preserved and conflicts remain visible.

## Live controls remain a separate authority lane

Jitter, Device Clock, Note Dynamics, and the Live Arp Engine use immediate runtime RPCs. They do not join the main staged configuration Apply. Multi-field Jitter and Clock forms protect unfinished local input from telemetry until **Push live override** succeeds; disconnect deliberately clears that pending local draft.

Lab presents one **Shared Arp Engine**, not two arpeggiators. The context switch chooses either current live engine state (`SET_ARP`) or one profile's saved defaults (`SET_PROFILE`). Selected Slot carries its staged root note plus profile assignment and live start/stop actions. The profile assignment disclosure remains the bulk inspection path. Shape and timing are shared by every running arp slot; firmware changes are not required for this information architecture.

## Presets are starting points, profiles are memory

The preset picker is there to help users learn the instrument on purpose instead of by superstition.

- Picking a preset stages a candidate config in the browser.
- It does **not** persist anything until you apply it.
- It only becomes long-term device memory when you explicitly save that state into profile A, B, C, or D.

That means you can safely audition mappings, compare ideas, and keep one preset as a teaching scaffold while another becomes your actual stored performance profile.

If you want the human explanation for every shipped preset, read [Preset Library](PresetLibrary.md).

## What happens when you apply

```mermaid
flowchart TD
  A[User presses Apply] --> B[Runtime validates staged config]
  B --> C[Runtime sends full staged payload with checksum]
  C --> D{Receipt and integrity fields valid?}
  D -- Yes --> E[read back and verify device config]
  D -- No --> F[mark uncertain]
  F --> G[resynchronize from device]
  E --> H[verified]
  G --> H
  G --> I[verified-device-different]
```

This is the important safety behavior:

- a valid receipt starts or completes verification
- a missing or mismatched receipt means the outcome is uncertain
- authoritative readback determines what the device actually contains

After a verified Apply, Configure may offer **Return to pre-Apply state**. This action stages the previously confirmed snapshot for review; it does not write to the device. The operator must Apply again. A later device patch or authoritative hydration invalidates that snapshot so the App does not offer a stale return path.

## What the configurator helps users learn

The app is useful because it turns protocol details into visible actions:

- **manifest identity** becomes a connection banner
- **schema versioning** becomes migration warnings
- **config validity** becomes disabled Apply until the payload is legal
- **device patches** become visible live updates instead of invisible background state changes
- **transport uncertainty** becomes an explicit resynchronization workflow

## Where to go next

- Read [Operator Tutorial](OperatorTutorial.md) for the practical “how to operate this machine” walkthrough.
- Read [Profile Workflow](ProfileWorkflow.md) if you want the save/load/reset flow explained step by step.
- Read [Failure-First Guide](../validation/FailureFirst.md) if your mental model is forming through recovery cases.
- Read [WebSerial Protocol](WebSerial.md) for the lower-level message model.
- Read [Preset Library](PresetLibrary.md) for what each shipped preset is trying to teach.
- Read [Testing](../validation/TESTING.md) for what the simulator and Playwright suite actually prove.
- Read [Bridge For Performers](BridgeForPerformers.md) if your interest is more live workflow than development.

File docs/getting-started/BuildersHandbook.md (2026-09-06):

# Builder's Handbook

Welcome to the MOARkNOBS-42 build bible—the fast-and-loose guide for wiring, flashing, and taming this misfit controller. If you're holding a soldering iron and a dream, you're in the right place.

If the board throws a tantrum, consult the [Troubleshooting](../validation/Troubleshooting.md) page before you reach for the fire extinguisher.

## Wire It Up

Start with the bare essentials. We'll keep the spaghetti minimal:

1. **Power** – Feed the Teensy 5 V through `VUSB` and ground everything like your sanity depends on it.

   Power hookup: 5V to VUSB, ground shared
   _Teensy getting 5 V on VUSB, all grounds bonded._

2. **LED Data** – Run Teensy pin `6` through a ~330 Ω resistor into the first WS2812's `DIN`. Chain the rest like dominoes.

   LED data line: pin 6 → 330 Ω → DIN
   _Pin 6 hits a resistor before feeding DIN. If it looks like this, you're golden._

3. **Buttons/Encoders** – Follow the pin labels on the board. Short wires = less noise.

   Button harness fanned to labeled pins
   _Each ribbon lands on its labeled pad; no loose strands, no drama._

4. **Decoupling** – Drop a 0.1 µF ceramic between 5 V and GND near the Teensy and again at the LED strip. It's cheaper than smoke.
5. **Wire Gauge** – 22 AWG for power runs, 24 AWG stranded for data. Keep anything carrying bits under 30 cm unless you like debugging antennas.

Reference diagrams still carry the wiring examples. Current prototype board and bench-context photos live under
`docs/assets/board/`; measured bench receipts still need to stay in the validation and bench docs.

### Wiring Habits

- Twist power and ground together; the pair that hums together stays quiet together.
- Heat‑shrink every joint so nothing shorts when the roadies throw the rig in a van.
- If it bends, give it strain relief—zip ties, hot glue, chewing gum, whatever keeps the Teensy from doing yoga.

### Why this matters

Mess up the power or data line and the board either sulks or smokes. A clean wiring job saves you hours of "why is nothing blinking?".

### Runtime LED control

The WS2812 strip isn’t just a wiring exercise—the firmware persists brightness and color all the way through EEPROM and the profile system. `GET_CONFIG` shows the current `led` object (brightness, RGB, hex), `SET_LED` stores new values, and `SET_ALL` can ship `{"led":{"color":"#00ffee"}}` fragments to pick a shade for the whole rig. You still drive the data line through pin 6, but the LEDManager now listens to the LFO bus (`LedBrightness` target) and updates the strip as soon as a profile loads, a `SET_LED` lands, or an envelope follower tips a slot. The status LED on pin 23 pulses whenever a diagnostic counter increments (UART overruns, dropped MIDI, slow loops), so it’s the quickest smoke test when you suspect the firmware is under stress.

## Flash the Brain

1. **Install PlatformIO** – `pip install -r requirements.txt` or use the VS Code add-on. Old-school? Arduino IDE with Teensyduino works too.
2. **Plug in the Teensy 4.0** over USB.
3. **Build and upload** the main firmware from the repo root:
   ```bash
   pio run -d firmware -t upload -e teensy40_main
   ```
   The loader will yell success when it's done.
4. **Local library stash** – We archive FastLED and the Adafruit display libs under `firmware/lib/`.
   PlatformIO grabs these first, so builds don't choke when you're offline or the registry glitches.
   To refresh them, pull the latest release from upstream, drop it in that folder, and keep the license file.

### Firmware Flow

```mermaid
flowchart TD
    Boot --> Init[Init hardware]
    Init --> Loop{Main loop}
    Loop -->|Read inputs| Proc[Process controls]
    Proc --> Update[Update LEDs & MIDI]
    Update --> Loop
```

### Why this matters

Knowing the firmware loop helps you predict how fast the box reacts and where to poke when hacking features.

## LFO Engine

Two low‑frequency oscillators live inside the firmware for modulation work. Each LFO can free‑run in Hz or lock to the MIDI clock (24 PPQN), with depth and polarity controls per instance.

```cpp
#include "LFO/LFOManager.h"

LFO &lfo1 = lfoManager.lfo(0);
lfo1.setShape(LFOShape::Sine);
lfo1.setFrequencyHz(1.0f);
lfo1.setDepth(0.75f);
lfo1.setBipolar(false);
lfo1.setSyncEnabled(true);
lfo1.setSyncRatio(LFOSyncRatio::Div4); // 1 cycle per 4 beats
```

The LFO bus can drive internal targets like EF gain trim, arp swing, or LED brightness, and can be routed out over MIDI/OSC via the routing layer.

The same LFO state lives inside each profile snapshot. `GET_PROFILE` returns the `lfos` array plus the `routes` table (internal targets, MIDI CC7/CC14, and OSC callbacks), and `SET_PROFILE` lets you persist changes by sending a JSON payload with partial updates. When a profile loads, the firmware replays those shapes, depths, and routes via `LFOManager::applyProfile`, so the LEDs, arpeggiator, and envelope gain trim all jump to the stored motion before you touch a knob. The normalized outputs are mirrored in `g_lfoValues` and the WebSerial `lfos` telemetry so the UI and OLED draw the same oscillations the scheduler runs.

## Arpeggiator

The arpeggiator can run UP, DOWN, UP-DOWN, RAND, DRUNK, or EUCL patterns, synced to MIDI clock (24 PPQN) or the internal tapped BPM fallback. Step length stays in ticks, while swing and gate length are percent-based so timing scales with tempo.

- **Toggle:** `Ctrl2 + Ctrl4` turns the arp on/off for the active slot when that slot is assigned by the active profile.
- **Edit (hold):** Long-press `Ctrl2 + Ctrl4` to enter Arp Edit while held; Control pot 1 sets gate length %, Control pot 2 sets octave range (0–3).
- **Swing presets:** Long-press `Ctrl2 + Ctrl3` to cycle 0%, 8%, 16%, 30%.
- **Base note:** Short press `Ctrl2 + Ctrl3` bumps the base note.

## First-Run Tests

Once the firmware's on board, make sure the basics don't flake out:

1. **Blink test** – Drop this mini sketch in `firmware/test/` and upload it the same way:
   ```cpp
   #include <FastLED.h>
   #define LED_PIN 6
   #define NUM_LEDS 1
   CRGB leds[NUM_LEDS];
   void setup(){ FastLED.addLeds<WS2812, LED_PIN, GRB>(leds, NUM_LEDS); }
   void loop(){
     leds[0]=CRGB::Green; FastLED.show(); delay(500);
     leds[0]=CRGB::Black; FastLED.show(); delay(500);
   }
   ```
   If that lone pixel blinks, you're in business.
2. **Button sanity** – Build the hardware test suite:
   ```bash
   pio run -d firmware -e teensy40_full_system
   ```
   Follow the serial prompts to poke every switch and LED.

### Why this matters

Catching a dead LED or flaky button now beats reflowing it after the enclosure's buttoned up.

## Button Controls

Need a crash course in front‑panel mayhem? Here's how the six control buttons misbehave. _EF = Envelope Follower._

| Button | Short Press | Long Press | Double Press |
| --- | --- | --- | --- |
| #0 | Toggle EF | Calibrate EF baseline | Cycle EF filter forward |
| #1 | Next Slot | Reload active profile | Cycle EF filter backward |
| #2 | Cycle EF assignment | Toggle Slot Active | Cycle MIDI Type (CC/Note/etc) |
| #3 | Cycle MIDI Channel | Reload persisted config | Cycle EF oversampling |
| #4 | Cycle registry number (CC/NRPN/RPN) | Save active profile/config | Toggle active-slot ARG |
| #5 | Tap BPM | Diagnostics/pages | Toggle active-slot LFO 1 lane |

**Slot Buttons (0–41):**
Short press selects the slot. Long press assigns or cycles the Envelope Follower and flips it on; once it’s awake, jab Control 0‑5 to lock to a specific EF.

### Why this matters

Learning the combos early means you perform tricks live instead of digging through docs mid‑set.

If you want the combinations grouped by intention instead of by raw button matrix, read [Combo Guide](../guides/ComboGuide.md).

## WebSerial in the Wild

The Teensy screams JSON snapshots over WebSerial so the browser can watch the synth wiggle in real time.

```mermaid
sequenceDiagram
    participant B as Browser
    participant T as Teensy
    B->>T: HELLO\n
    T->>B: {"hello":"mn42"}
    loop Every ~100ms
        T->>B: {"slots":[...],"envelopes":[...]}
    end
```

### Why this matters

WebSerial lets you tweak patches from a browser without custom software. It's quick feedback with zero driver drama.

## What Could Go Wrong?

- **No common ground** – LEDs ghost or don’t light. Tie every ground together like you mean it.
- **Wrong pin** – LED data on any pin but 6? Enjoy the dark.
- **Power sag** – feeding 52 WS2812s from a wimpy supply causes brownouts and swearing.
- **Missing libraries** – PlatformIO fails fast if dependencies vanish. Check `platformio.ini` before blaming the hardware.
- **Bootloader naps** – if the Teensy doesn’t auto‑program, hit its button to jolt the bootloader awake.

### Why this matters

These classics ruin weekends. Keep them in mind and you'll spend more time making noise than troubleshooting.

## Profiles

The rig hoards four full configuration profiles (A–D) in EEPROM. Each slot stores pot mappings, LED brightness/color, envelope routing (including follower-to-multi-slot mappings), ARG/filter details, and the entire modulation matrix (arpeggiator timing + shape, LFO shapes/depths/routes, and per-slot MIDI channel/EF payloads). The WebSerial [`GET_PROFILE`](../guides/WebSerial.md#profiles-and-modulation-snapshots) response exposes this snapshot so editors can replay the same state in software, and `SET_PROFILE` lets you persist a partial or complete payload back to the board. When you load a profile, the firmware replays the stored LED color, LFO routes, and slot envelope parameters instantly before your pots/docs move again.

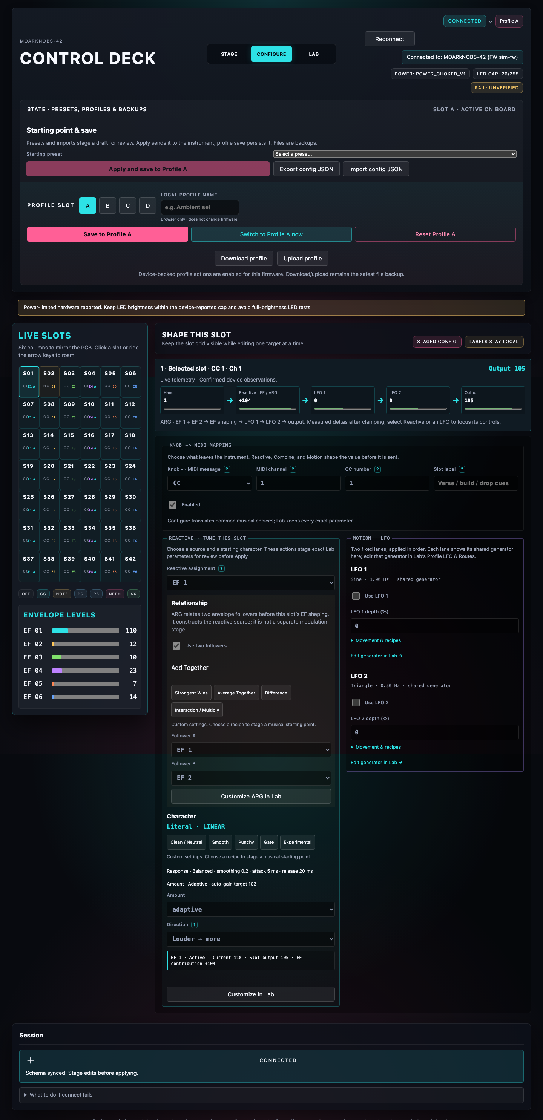
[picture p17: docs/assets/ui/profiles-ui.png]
Browser configurator State drawer showing Profile A–D selection, save and recall controls, and JSON backup actions.


The hero banner mirrors those slots: tap A–D to pick the active profile, then use **Save profile**, **Load profile**, or **Reset profile** to call the UI’s RPC helpers. Save will stage the current diff and then invoke `SET_PROFILE` for that slot, while Load clears the diff and re-fetches the stored snapshot via `GET_PROFILE`. Reset restores the slot to factory defaults and pushes them back through `SET_PROFILE` so the desk stays tidy.

For crash recovery and sharing, download the staged profile as JSON or upload a backup file that stages immediately (the UI also mirrors the last staged state to `localStorage`, so a reload keeps unsent edits handy).

If you want curated starting points before you start authoring your own maps, use the browser preset picker and keep [Preset Library](../guides/PresetLibrary.md) nearby. That page explains what each shipped preset is trying to teach and which one is best for a first pass.

- **Jump profiles** – mash **Ctrl1 + Ctrl2** to hop to the next profile. It wraps after the fourth.
- **Save the chaos** – long‑press **Ctrl4** once you've mangled the knobs to taste.
- **Panic reload** – long‑press **Ctrl1** (with the confirm jab) to yank the active profile from EEPROM.

### Why this matters

Profiles let you keep live, studio, and "what if I break everything" setups without re‑flashing, and the payload ensures every modulation bus, LED cue, and envelope follower is restored exactly as it was.

## Manual Hardware Tests

Compile the test environments when you want to verify the board outside of the main firmware:

```bash
pio run -d firmware -e teensy40_full_system      # or teensy40_unified_test, etc.
# Unity harness flexes a different muscle:
pio test -d firmware -e teensy40_unity -vvv
```

Available environments:

- `teensy40_full_system` – step-through checks of each subsystem
- `teensy40_unity` – Unity-driven automated tests (run with `pio test -d firmware -e teensy40_unity -vvv`)
- `teensy40_unified_test` – full integration test
- `teensy40_biquad_test` – biquad filter calibration
- `teensy40_eeprom_persistence` – EEPROM backup/restore test
- `teensy40_slot_verify` – verifies MIDI slot storage

### Why this matters

Running the test rigs lets you trust the hardware before you haul it on stage.

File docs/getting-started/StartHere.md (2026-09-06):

# New User Story

If you are new to MOARkNOBS-42, the easiest mistake is to think it is "just a controller with a lot of knobs." It is closer to a small system with a very visible control surface.

This page is the beginner-friendly tour: what the parts are, how they relate, and what to read next when you want to go deeper.

If you need a brutally short first path, start with [First Five Minutes](FirstFiveMinutes.md). It sorts the first step into four choices: play it, configure it, build/test it, or understand it.

If you want the whole hardware/App/Bridge/firmware/evidence picture before the tour, open the [System Map](SystemMap.md).

If you already know you want a longer role-based reading path, skip ahead to [Guided Routes](GuidedRoutes.md).

## The elevator version

MOARkNOBS-42 is built around four layers:

```mermaid
flowchart TD
  H[Hardware layer<br>buttons, pots, LEDs, envelope inputs] --> F[Firmware layer<br>scheduler, MIDI, config, persistence]
  F --> C[Contract layer<br>manifest, schema, WebSerial, bridge RPC]
  C --> U[User layer<br>browser app, OSC bridge, performer workflow]
```

If one layer lies to the next, the whole experience gets weird fast. That is why the docs keep returning to contract sync, test coverage, authoritative readback, and traceability.

## What you are looking at

### On the board

Render of the MOARkNOBS board showing its control layout and main supporting components.

- a Teensy 4.0 running the firmware
- a button grid and control buttons for direct interaction
- LED output for visual feedback
- envelope follower inputs for audio-reactive control
- generation-checked persistent storage so the machine remembers verified state

### In the browser

Annotated browser configurator screenshot showing live slots, the selected-slot signal path, Reactive shaping, and shared LFO Motion.

- a runtime that connects over WebSerial
- a schema-driven form system
- staged edits that can be reviewed before they are applied
- checksum-backed Apply with explicit uncertainty and authoritative readback

## The first mental model to keep

The browser does **not** own the truth by itself, and the firmware does **not** blindly trust the browser.

The normal conversation is:

1. connect to the device
2. ask for its manifest
3. compare schema versions
4. fetch the config
5. stage changes locally
6. apply changes and wait for a verified receipt/readback outcome

That is why the configurator can safely support staging, diff views, local draft discard, uncertainty recovery, and migration warnings.

## The first practical walk

If you want the shortest role-based route, use [First Five Minutes](FirstFiveMinutes.md). If you want the learning tour, follow this order:

### 1. Learn the high-level workflow

Read [Process Overview](../project/ProcessOverview.md).

That page tells you the sequence from hardware prep to release without burying you in implementation details.

### 2. Learn how to recover from problems

Read [Troubleshooting](../validation/Troubleshooting.md).

The best time to understand failure modes is before the board is half-built and silent.

### 3. Learn the browser model

Read [Configurator Tour](../guides/Configurator.md), then [WebSerial Walkthrough](../guides/ProtocolWalkthrough.md).

If you learn best from concrete examples rather than empty forms, read [Preset Library](../guides/PresetLibrary.md) after that. It explains what each shipped preset is actually for and why the picker exists.

If you want the vocabulary before the examples, read [Glossary](../reference/Glossary.md).

If you want the reactive-control concepts broken out into small explainers instead of one big system page, follow [Reactive Control Guide](../guides/ReactiveControlGuide.md) with [ARG Guide](../guides/ARGGuide.md), [Filter Feel Guide](../guides/FilterFeelGuide.md), and [LFO Route Guide](../guides/LfoRouteGuide.md).

Those pages explain how the browser thinks about staged state, manifests, patches, and apply safety.

### 4. Learn what the tests actually prove

Read [Testing Story](../validation/TestingStory.md), then [Testing](../validation/TESTING.md).

If your real question is "how do I get one playable setup tonight?" jump to [Musician-First Guide](MusicianFirstGuide.md).

That page is where the repo stops being mystical about "tested" versus "not yet proven on real hardware."

## What to ignore on your first pass

You do **not** need to read these immediately unless you are debugging or extending the stack:

- [Legacy EEPROM Layout — Schema 4](../reference/EEPROMLayout.md) — historical only
- [Pin Map](../reference/PinMap.md)
- [Assumption Ledger](../reference/assumption-ledger.md)

They matter, but they are better after you already know the main path through the instrument.

## When you are ready for the deeper story

Once the basic workflow makes sense, read [History](../project/HISTORY.md).

That is where the project starts to become legible as more than a collection of files. You can see when test coverage expanded, when the browser became schema-driven, when release hardening started to matter, and why the project now reads so defensively in places.

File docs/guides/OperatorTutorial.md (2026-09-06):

# Operator Tutorial

This page is the practical answer to “how do I actually operate this thing without guessing?”

The browser configurator is not just a settings page. It is the live operating surface for:

- understanding what the board is currently doing
- staging edits without lying to yourself
- deciding when to apply those edits to the device
- managing profiles and backups

Annotated configurator screenshot showing connection identity, the State drawer, and the selected-slot signal path.

Annotated configurator screenshot showing live slots, the selected-slot signal path, Reactive shaping, and shared LFO Motion.

## The three states you need to keep separate

If you keep these separate, the machine feels calm. If you mix them together, it feels haunted.

### 1. Live device state

This is what the firmware most recently confirmed.

- It is the truth the hardware is actually using.
- It updates after connect and after a successful apply.
- It is what profile save/load/reset operates on.

### 2. Staged browser state

This is what you are currently editing in the configurator.

- Most form edits change staged state first.
- The diff panel compares staged state to live device state.
- **Apply** is the moment staged state attempts to become live device state.

### 3. Browser-only operator state

This is local helper information that belongs to the operator, not the firmware.

- slot labels
- the MIDI badge

These do **not** get written to the board.

That means:

- they do not require **Apply**
- they survive reconnects in the same browser
- they should not be mistaken for device memory

## First operating pass

Use this as the basic rehearsal flow.

1. Connect the board.
2. Confirm the header shows the expected device and firmware.
3. Click a slot in **Live Slots**.
4. Edit that slot in **Selected Slot**.
5. Watch the staged diff change.
6. Press **Apply** only when the staged change is intentional.
7. Save a profile only after the live device state is the state you want to keep.

## Editing safely

The safest mental model is:

1. select the slot
2. make the edit
3. inspect the diff
4. apply intentionally
5. save the profile only if that live result is worth keeping

This is safer than treating every field as a live hardware write.

## Profiles, backups, and recovery

There are two different kinds of “saving” in the configurator.

### Save profile

This stores the current live device state into an on-device profile slot.

Use it when the board itself should remember the state.

### Download / upload profile

This is file backup and restore through the configurator.

Use it when:

- you want an external copy
- you want to move a setup between machines
- you want a rollback point before experimental edits

### Reset profile

This restores the active profile to its baseline and pushes that result back through the normal profile path.

Treat it as destructive. Make a backup first if the current state matters.

## What to watch during operation

The configurator gives you three useful truth surfaces:

- the connection banner: which device you are actually talking to
- the staged diff: what has changed but is not yet applied
- the status/console area: whether the last action succeeded, failed, or rolled back

If these three surfaces agree, you are usually safe.

If they disagree, stop and resolve that before making more changes.

## Suggested rehearsal workflow

Before rehearsal:

1. connect and confirm identity
2. load the intended profile
3. make any needed staging edits
4. apply
5. save the updated profile only if you want the board to keep it

During rehearsal:

1. keep an eye on the connection/status surface
2. use the slot labels and MIDI badges as operator aids
3. avoid profile reset unless you are intentionally restoring a baseline

After rehearsal:

1. export a backup if the session produced a good state
2. note any browser-local labels you want to recreate elsewhere

## Read next

- [Configurator Tour](Configurator.md) for the transport and staged/live contract
- [Profile Workflow](ProfileWorkflow.md) for save/load/reset behavior
- [Failure-First Guide](../validation/FailureFirst.md) if you want to understand what happens when things go wrong
- [Testing](../validation/TESTING.md) for what the repo actually proves

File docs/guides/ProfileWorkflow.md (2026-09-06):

# Profile Workflow

This page exists because profiles are one of the easiest places for a newcomer to get confused.

The short version:

- a **preset** is a browser-side starting point
- a **profile** is a saved device memory slot

If you mix those up, the configurator feels unpredictable. If you keep them separate, the workflow becomes calm and deliberate.

## The profile panel as a workflow

Browser configurator State drawer showing presets, Profile A–D selection, save and recall controls, and JSON backup actions.

Use the profile area as a four-step process, not as a pile of unrelated buttons.

### 1. Pick a target profile slot

Choose A, B, C, or D based on what role you want it to play:

- A: safe baseline
- B: current rehearsal idea
- C: alternate mapping
- D: risky experiment or show-specific scene

The exact slot names do not matter. The role does.

### 2. Stage changes first

This can come from:

- editing the form directly
- loading a preset from the picker
- importing a JSON config

At this point nothing permanent has happened yet.

### 3. Apply to the live device

This is when the browser actually pushes the staged config to the deck. Only after the device acknowledges the change should you treat the new state as real.

### 4. Save the live state into a profile

Saving a profile is what turns "I like this right now" into "I can get back here later."

That is the core mental model:

```mermaid
flowchart LR
  A[Load or edit staged config] --> B[Apply to live device]
  B --> C[Listen, watch, verify]
  C --> D[Save into profile A-D]
```

_Alt text: Flowchart showing the profile workflow moving from staged edits to Apply, then verification, then saving into a permanent device profile slot._

## What each button is for

### Save profile

Use this when the current live state is good and you want it to persist in the selected slot.

On current firmware this writes the selected device slot directly over the native `SAVE_PROFILE` path.
If the browser disables this button, treat that as a stale firmware or disconnected-session clue rather than a hidden feature flag. Use **Download profile** for a file backup until the device reconnects cleanly.

### Load profile

Use this when you want to recall the saved EEPROM state from the selected slot and make it active again.

On current firmware this recalls the selected device slot through `LOAD_PROFILE` and makes that slot active.
If this control is disabled, the browser is usually protecting you from stale firmware, a disconnected device, or a failed handshake.

### Reset profile

Use this when you want to wipe the selected slot back to its baseline/default state.

On current firmware this restores the selected slot to the firmware baseline through `RESET_PROFILE`, then marks that slot active.
If this control is disabled, reconnect first and confirm the manifest loaded; do not assume the slot was reset remotely.

### Download profile

Use this when you want a portable JSON backup of the current staged or active idea outside the device.

### Upload profile

Use this when you want to bring in a saved JSON and stage it for review.

## The safe beginner ritual

If you are not yet comfortable, do this every time:

1. choose a target slot
2. stage one preset or a small set of edits
3. apply
4. confirm the rig behaves the way you expect
5. save into that same slot

That order makes it much harder to lose a known-good setup.

## Common mistakes

### "I picked a preset and thought it was already saved"

It is not. The preset picker stages locally first. You still need to Apply, and then Save if you want persistence.

### "I loaded a profile and my unsaved browser changes vanished"

That is expected. Load profile means "replace the current live/staged context with the device snapshot from that slot."

### "I saved into the wrong slot"

Use one slot as a permanent baseline so you always have a clean place to recover from.

### "I do not know whether I should export a preset or save a profile"

- export when you want a file
- save profile when you want on-device recall

### "The profile buttons are disabled even though this repo says they are supported"

That usually means one of three things:

- you are not connected
- the manifest handshake did not complete
- the board is running older firmware than the current app/docs expect

## Suggested slot roles

For many users this simple scheme is enough:

| Slot | Role |
| ---- | --- |
| A | stable baseline |
| B | current rehearsal build |
| C | alternate arrangement |
| D | risky experiment or one-song setup |

The point is not the labels themselves. The point is that every slot should have a job.

## Read next

- [Musician-First Guide](../getting-started/MusicianFirstGuide.md) for the rehearsal-first version of this workflow
- [Preset Library](PresetLibrary.md) for browser-side starting points
- [Failure-First Guide](../validation/FailureFirst.md) for what to do when profile actions feel confusing
- [WebSerial Protocol](WebSerial.md) for the underlying `GET_PROFILE` / `SET_PROFILE` snapshot behavior

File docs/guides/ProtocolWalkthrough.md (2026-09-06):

# WebSerial Walkthrough

Current line-level contract: [MN42 Line Protocol](../reference/MN42LineProtocol.md), [Serial Protocol](../reference/SerialProtocol.md), [Documentation Truth Map](../reference/DocumentationTruthMap.md).

If you want to learn the firmware source behind this conversation, pair this
guide with [Firmware Main Reading Path](../firmware/FirmwareMainReadingPath.md)
and [firmware/src/protocol/README.md](https://github.com/bseverns/MOARkNOBS-42/blob/main/firmware/src/protocol/README.md).

The raw WebSerial reference tells you what messages exist. This page explains why the conversation is structured that way and what a newcomer should expect to happen from the moment the browser connects.

The short version is: the browser does not blindly trust the device, and the device does not blindly trust the browser.

## The session story

```mermaid
sequenceDiagram
  participant Browser
  participant Firmware
  Browser->>Firmware: HELLO
  Firmware-->>Browser: {"hello":"mn42"}
  Browser->>Firmware: GET_MANIFEST
  Firmware-->>Browser: manifest JSON
  Browser->>Firmware: GET_SCHEMA
  Firmware-->>Browser: schema JSON
  Browser->>Firmware: GET_CONFIG
  Firmware-->>Browser: full config JSON
  Browser->>Browser: clone into liveConfig and stagedConfig
  Browser->>Firmware: live patch lane or full apply lane
  Firmware-->>Browser: patch or checksum ACK
```

_Alt text: Sequence diagram showing a browser sending HELLO, requesting manifest and config, then staging edits and receiving patches or acknowledgements from the firmware._

That flow is the heart of the configurator.

## Step 1: identify the device before editing it

The browser starts by saying hello, then asks for the manifest.

Console-style handshake diagram showing the browser HELLO request and the firmware JSON response.

The manifest is not decorative metadata. It tells the browser:

- what device is connected
- what firmware version it is running
- what schema version the device expects
- how many slots, pots, envelopes, and LEDs the UI should assume

That is why the browser can show identity banners and schema mismatch warnings before it lets anyone edit live state.

## Step 2: hydrate a trustworthy model

Once the manifest makes sense, the browser requests the full configuration and splits it into two copies:

- `liveConfig`: what the device most recently confirmed
- `stagedConfig`: what the user is currently editing

That split is the most important safety feature in the app. It lets the UI be honest about what is merely proposed versus what the device has actually accepted.

## Step 3: edit locally first

When a user changes a field, the browser usually edits `stagedConfig` first.

That means the UI can:

- show diffs before applying changes
- batch related changes together
- preview migrations
- recover cleanly if a write is rejected

Without staged state, the browser would have to pretend every local change was already true on the device.

## Step 4: send the smallest safe write

There are two common write shapes:

- a narrow patch lane for field-level edits when the active transport supports it
- a broader staged apply lane that carries complete state and a checksum

The right mental model is not "the browser streams every keystroke forever." The right model is "the browser tries to send the smallest truthful mutation and waits for device confirmation."

## Step 5: listen for patches and telemetry

The firmware streams two useful classes of output:

- periodic state snapshots
- targeted patch messages when a smaller part of the state changes

This matters because the configurator is not a static settings form. It is a live monitor:

- slot values move
- envelope followers breathe
- LFO values animate
- diagnostics tell you when the firmware is under pressure

Screenshot of the browser configurator State drawer showing presets, device profiles, and JSON backup actions.

## Step 6: verify or resynchronize

When the browser sends a larger apply, the firmware answers with a checksum-backed acknowledgement. That acknowledgement is what allows the browser to advance `liveConfig` to the newly staged state.

If the acknowledgement is missing or does not match expectations, the runtime enters uncertainty and reads authoritative device configuration back. It does not claim rollback after transmission. See [Configuration Transaction Model](../reference/ConfigurationTransactionModel.md).

That is a quiet but critical part of the contract. It keeps the UI from lying.

## Why the protocol feels more formal than a hobby serial app

This protocol is a little stricter than a typical "send some JSON over USB" tool because the browser is acting like an editor for a real instrument state:

- version mismatches matter
- partial writes matter
- persistence matters
- diagnostics matter
- rollback matters

The point is not ceremony for its own sake. The point is to make on-stage and on-bench editing trustworthy.

## What new users should remember

If the configurator feels careful, that is intentional.

It is trying to protect four things at once:

1. device identity
2. schema compatibility
3. staged versus confirmed state
4. safe apply behavior

Once you understand those four ideas, the rest of the WebSerial reference becomes much easier to read.

## Read next

- [Configurator Tour](Configurator.md) for the UI-facing side of this exchange
- [WebSerial Protocol](WebSerial.md) for the full command and payload reference
- [App README](https://github.com/bseverns/MOARkNOBS-42/blob/main/App/README.md) for the runtime-side implementation model

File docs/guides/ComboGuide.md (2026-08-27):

# Combo Guide

The raw button/combination table is useful, but it is not the easiest way to learn the controller.

This page groups the combos by intention so a new player can memorize the ones that matter first.

While any control button is held, the OLED now acts as a contextual command palette. It names that control's family and shows the most useful continuations; recognized prefixes reveal their available deeper continuations. Every registered chord also receives generated exact-action help, including separate tap and hold actions where applicable. The hexadecimal fallback is reserved for unregistered combinations. The compact, generated [On-Device Control Quick Reference](../reference/generated/OnDeviceQuickReference.md) comes from the same registry as the firmware help table.

Control-button map highlighting recovery, profile, arp, reactive-control, and mapping combo clusters.

## Start here if you are new

Memorize these first:

1. profile cycling
2. arp toggles
3. panic-safe reset
4. one or two MIDI-type shortcuts

That gives you recovery, timing control, and basic mapping power without having to carry the whole matrix in your head.

The full button table still lives in [firmware/include/ButtonManager/README.md](https://github.com/bseverns/MOARkNOBS-42/blob/main/firmware/include/ButtonManager/README.md#button-map).

## Recovery combos

These are the ones worth learning even if you never become a combo wizard.

| Combo | What it does | Why it matters |
| --- | --- | --- |
| `Ctrl0 + Ctrl1 + Ctrl2` | panic-safe baseline reset  | fastest "get me back to something sane" move |
| long-press `Ctrl1` | reload profile from EEPROM | recover a stored baseline |
| long-press `Ctrl3` | reset EEPROM | destructive recovery path; not a casual action |

Recommended to memorize first:

- panic-safe reset
- profile reload

## Profile and memory combos

These help you move between saved states.

| Combo | What it does |
| --- | --- |
| `Ctrl1 + Ctrl2` | cycle profiles A-D |
| long-press `Ctrl4` | save config |
| long-press `Ctrl1` | reload current profile |

These are the combos that matter most once you start using the rig in rehearsal or live work.

## Arp combos

These control timing and note behavior.

| Combo | What it does |
| --- | --- |
| `Ctrl2 + Ctrl4` | toggle arpeggiator |
| long-press `Ctrl2 + Ctrl4` | enter arp edit while held |
| `Ctrl2 + Ctrl3` | bump arp base note |
| long-press `Ctrl2 + Ctrl3` | cycle swing presets |

Best ones to learn first:

- `Ctrl2 + Ctrl4`
- long-press `Ctrl2 + Ctrl3`

Those two alone let you feel the arp become part of the instrument.

## Mapping and MIDI-type combos

These are about changing what a slot _is_.

| Combo | What it does |
| --- | --- |
| `Ctrl4 + Ctrl5` | set slot to MIDI Note mode |
| `Ctrl3 + Ctrl5` | set slot to Program Change |
| `Ctrl0 + Ctrl5` | set slot to Pitch Bend |
| `Ctrl1 + Ctrl4` | set slot to Aftertouch |
| `Ctrl2 + Ctrl5` | set slot to NRPN |
| `Ctrl1 + Ctrl3` | set slot to RPN |
| `Ctrl0 + Ctrl3` | set slot to SysEx |

This is powerful, but it is not the right first thing to memorize. Learn it once the concepts are clear.

## Reactive-control combos

These are where the deck starts acting more like a reactive instrument.

| Combo | What it does |
| --- | --- |
| `Ctrl0 + Ctrl1` | cycle ARG method |
| `Ctrl0 + Ctrl2` | cycle ARG envelope pair |
| `Ctrl0 + Ctrl4` | enable EF and randomize settings |
| `Ctrl0 + Ctrl1 + Ctrl4` | toggle live LFO 1 for the active slot |

These are great once you already understand EF and ARG, but they are exactly the ones that can feel like "black magic" without context.

Read these first:

- [ARG Guide](ARGGuide.md)
- [Filter Feel Guide](FilterFeelGuide.md)
- [Reactive Control Guide](ReactiveControlGuide.md)

## System and mode combos

These change broader operating behavior.

| Combo | What it does |
| --- | --- |
| `Ctrl3 + Ctrl4 + Ctrl5` | toggle USB MIDI output |
| `Ctrl3 + Ctrl4` | cycle LED display modes |
| `Ctrl1 + Ctrl5` | toggle MIDI clock output |
| `Ctrl1 + Ctrl4 + Ctrl5` | toggle clock source (EXT/INT) |
| `Ctrl0 + Ctrl1 + Ctrl3` | toggle LFO quick-tune mode |
| `Ctrl0 + Ctrl2 + Ctrl3 + Ctrl5` | enter on-device config mode |

You can roll into or out of the Config Mode chord in any finger order. Its
temporary `Ctrl2+Ctrl3` subset is suppressed, so entering or leaving the mode
does not also bump the arpeggiator base note.
Release all controls before intentionally playing one of its sub-combos; the
all-up state re-arms both short and long forms immediately.

LFO quick-tune control-pot map:

- `CtrlPot0`: frequency
- `CtrlPot1`: depth
- `CtrlPot2`: sync ratio (sync ON) or bipolar/unipolar (sync OFF)

These are useful, but most players do not need them on day one.

## Actions that can replace current runtime state

These deserve confirmation:

- long-press `Ctrl3` reloads persisted configuration and can replace unsaved runtime edits
- anything that rewrites slot type while you are not sure what the active slot is

If in doubt, reload a profile instead of escalating immediately.

## A good memorization order

If you only want a sensible first set, learn these in order:

1. `Ctrl1 + Ctrl2` for profile cycling
2. `Ctrl2 + Ctrl4` for arp toggle
3. `Ctrl0 + Ctrl1 + Ctrl2` for panic-safe reset
4. long-press `Ctrl1` for profile reload
5. one MIDI type shortcut you actually use often

That gives you a practical live vocabulary without forcing you to memorize the whole matrix at once.

## Read next

- [Profile Workflow](ProfileWorkflow.md) for how profile actions fit the browser/device workflow
- [Failure-First Guide](../validation/FailureFirst.md) for what to do when a combo puts the rig somewhere unexpected
- [Builder's Handbook](../getting-started/BuildersHandbook.md) for the broader hands-on control story

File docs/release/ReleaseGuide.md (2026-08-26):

# Release Guide

Need to cut a proper drop? Start with [Release Story](ReleaseStory.md), then treat this file as the operator checklist and [Reproducibility](Reproducibility.md) as the canonical artifact recipe.

Current release/support boundary: [Release Boundary Index](ReleaseBoundaryIndex.md), [Host Compatibility](../reference/HostCompatibility.md), [bridge/README.md](https://github.com/bseverns/MOARkNOBS-42/blob/main/bridge/README.md), [Bridge Signing Plan](BridgeSigningPlan.md), [Documentation Truth Map](../reference/DocumentationTruthMap.md).

```mermaid
flowchart LR
  A[Build + tests] --> B[Update notes]
  B --> C[Stamp version]
  C --> D[Tag commit]
  D --> E[release.sh]
  E --> F[Artifacts + manifest]
  F --> G[Upload / publish]
```

1. **Run the gauntlet** – build (`pio run -d firmware -e teensy40_main`) and test (`pio test -d firmware -e teensy40_unity -vvv`, `npm --prefix bridge test`, `npm --prefix App test`). For a beta/public candidate, run `./release_verify_hil.sh`; it always runs the bridge and app suites, and it adds Unity/full-stack HIL when `TEST_PORT` or an auto-detected board is available. Use `REQUIRE_HIL=1` when hardware evidence is mandatory.
2. **Refresh the human-facing release notes** – update [CHANGELOG.md](https://github.com/bseverns/MOARkNOBS-42/blob/main/CHANGELOG.md) and the relevant entry in [HISTORY.md](../project/HISTORY.md) so both the terse delta log and the longer narrative are current.
3. **Confirm version stamping** – firmware version strings come from `FW_VERSION`/`GIT_SHA`, which are stringized in [firmware/include/version.h](https://github.com/bseverns/MOARkNOBS-42/blob/main/firmware/include/version.h) and injected by [firmware/scripts/version.py](https://github.com/bseverns/MOARkNOBS-42/blob/main/firmware/scripts/version.py). For local release builds, export the intended tag before invoking the release script:
   ```bash
   FW_VERSION=vX.Y.Z ./release.sh vX.Y.Z
   ```
   - `release.sh` now runs two explicit lanes:
     - `release_verify_hil.sh` (hardware verification; enforce with `REQUIRE_HIL=1`)
     - `release_build.sh` (deterministic artifact generation)
   - `release_verify_hil.sh` feeds the generated `dist/mn42_vX.Y.Z_hardware-test_verification.json` so artifacts explicitly show what verification was executed versus skipped.
   - `release_build.sh` refuses tracked source changes before packaging so `dist/mn42_vX.Y.Z_hardware-test_manifest.json` records a clean source commit.
4. **Commit it** – lock in doc updates and any release prep changes with a commit.
5. **Tag it loud** – `git tag -a vX.Y.Z -m "vX.Y.Z"` to mark the moment. The release workflow rejects lightweight tags, non-semantic tag names, and tags without a matching dated `CHANGELOG.md` heading.
6. **Push the tag** – `git push origin vX.Y.Z` kicks CI into `.github/workflows/release.yml`.
7. **Review the prerelease** – after every required build lane succeeds, CI creates or updates the GitHub prerelease, appends a factual artifact index, and attaches the complete output set.
   - The release workflow builds hardware-test firmware artifacts, a frozen browser App ZIP, and unsigned hardware-test bridge packages (`macOS x64 + arm64`, `Linux x64`, `Windows x64`). It also stores the core and Bridge bundles as workflow artifacts.
   - Release packaging is blocked unless bridge tests, app tests, and `teensy40_main` firmware build pass in the release workflow.
   - GitHub Release creation and asset upload happen only in the final publication job, after both the core and Bridge artifact bundles exist.
   - GitHub Release asset labels must keep the current boundary visible: hardware-test/prerelease, not beta/public.
   - Read `mn42_vX.Y.Z_hardware-test_verification.json` before publishing notes: default hosted runners use optional HIL mode unless you provide a hardware port.
   - Bridge uploads include per-target checksums, bridge third-party license payloads, artifact manifest metadata, and hardware-test/prerelease labels.
8. **Add or refine human notes** – CI-generated notes and the artifact index provide the factual floor; edit the prerelease description if the milestone needs a stronger narrative.
9. **Celebrate or debug** – if CI faceplants, fix it and cut a new tag rather than moving the failed tag. If it works, cue the lights.

## Bridge packaging track

Unsigned bridge packaging now runs automatically in the release workflow. The remaining manual track is signing and installer-grade polish for beta/public outward artifacts:

1. Follow [`BridgePackaging.md`](BridgePackaging.md) phases for the current release target.
2. Review the generated bridge artifacts and checksums from CI.
3. For a beta/public macOS artifact, run `npm --prefix bridge run package:macos` with `REQUIRE_BRIDGE_SIGNING=1`, `APPLE_CODESIGN_IDENTITY`, `APPLE_NOTARY_KEY`, `APPLE_NOTARY_KEY_ID`, and `APPLE_NOTARY_ISSUER_ID`.
4. Attach/verify signed bridge artifacts alongside firmware files on the GitHub release when you are producing a signed outward-facing release.
5. Verify docs match the shipped UX (`docs/guides/OSCBridge.md`, `docs/guides/BridgeForPerformers.md`, `bridge/README.md`).
6. Complete the artifact checklist template: [`release/bridge-artifacts-checklist.md`](bridge-artifacts-checklist.md).

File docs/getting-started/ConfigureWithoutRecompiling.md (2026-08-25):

# Configure Without Recompiling

Many MN42 performance and mapping behaviors can be configured without recompiling firmware.

That does not make MN42 a generic no-code controller platform. The firmware still defines the instrument. The browser configurator and Bridge expose the parts intended to move during setup, rehearsal, and performance.

## Configuration Boundary Table

| Area | Configurable Without Recompile | Still Firmware/Contract Bound |
| --- | --- | --- |
| Slots | message type, channel, primary data field, active state, slot-local modulation fields | slot count, schema shape, supported message types |
| Profiles | save, load, reset, import, export | EEPROM layout, profile count, firmware persistence behavior |
| Incoming MIDI | source port/channel/CC, destination, interaction, output range, takeover | binding capacity, supported message class, destination eligibility, takeover rules  |
| EF | assignment, follower-related slot settings, destination behavior where exposed | envelope count, input hardware, firmware follower implementation |
| ARG | enable, method, sources | available methods and source count |
| LFO routes | route type, target, amount/depth/range where supported | route count, target enum, output scheduler behavior |
| Bridge | serial path, OSC/MIDI ports, host recipes, App-over-Bridge workflow | staged/live write boundaries and Bridge/device session contract |

## Browser Configurator

Use the browser configurator for the main staged configuration workflow:

- inspect manifest, schema, and current config
- edit slots
- stage changes locally
- validate against schema
- Apply to firmware
- save, load, reset, and export profiles

The safe rule is simple: staged edits do not become live firmware truth until Apply succeeds and the device acknowledges the write.

## Slots

Slots can be configured without recompiling:

- MIDI message type
- MIDI channel
- CC or primary data field
- active/muted state
- slot-local EF settings
- slot-local ARG settings

The exact available fields depend on the current firmware manifest and schema.

## Profiles

Profiles let the device store working states instead of rebuilding a setup from scratch. The App exposes profile workflows for saving, loading, resetting, importing, and exporting profile data.

Use profiles for rehearsal states, show setups, and experiments you want to recover.

## Incoming MIDI

Incoming MIDI bindings are profile-owned firmware configuration, not Bridge host mappings. In Lab, use **Profile Performance → Incoming MIDI** to configure:

- DIN, USB, or either input port;
- MIDI channel and 7-bit CC number;
- a supported slot or machine-level destination;
- Continuous, Momentary, or Toggle interaction;
- output minimum and maximum;
- soft pickup or jump takeover for Continuous routes.

The current implementation accepts only CC7 input. Slot destinations are intentionally limited to active, direct, unmodulated CC slots so external ownership and physical takeover remain unambiguous. See [MIDI Input Mapping](../guides/MidiInputMapping.md).

## EF Settings

Envelope follower behavior can be configured per slot:

- assigned follower index
- response/filter shape
- detection mode
- attack/release or related timing
- baseline and gain behavior
- destination behavior for how EF contribution affects the slot value

EF changes are still bounded by firmware support. The configurator should fail closed when the connected firmware does not advertise a capability.

## ARG Settings

ARG blends two envelope follower sources before the slot uses the modulation result. Per-slot ARG settings include:

- enable/disable
- method
- source A
- source B

Use [ARG Guide](../guides/ARGGuide.md) when choosing a method by feel rather than by formula.

## LFO Routes

LFO routes can target internal behavior, MIDI/CC output, slot values, or OSC mirrors depending on firmware support.

Current route controls include:

- LFO index
- route type
- target
- depth
- signed amount
- output min/max range

Use [LFO Route Guide](../guides/LfoRouteGuide.md) and [Modulation Matrix Contract](../reference/ModulationMatrixContract.md) for the deeper model.

## Bridge And Session Workflows

Use the Bridge when the browser cannot or should not talk directly to the device, or when the performance setup needs OSC or virtual MIDI.

Bridge-side configuration can include:

- serial path
- OSC host/ports
- MIDI port label
- custom MIDI-to-OSC mappings
- cached structured device session
- App-over-Bridge workflow

Bridge live-control writes are not the same as staged firmware config writes. See [Bridge Write Lanes](../bridge/BridgeWriteLanes.md).

## Conservative Boundary

Without recompiling does not mean without proof.

Before treating a workflow as production-safe, check:

- [Host Compatibility](../reference/HostCompatibility.md)
- [Connectivity Guide](ConnectivityGuide.md)
- [TESTING](../validation/TESTING.md)
- [Release Criteria](../release/ReleaseCriteria.md)

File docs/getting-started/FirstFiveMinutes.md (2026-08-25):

# First Five Minutes

> **Doc class:** Orientation. This page helps you choose a first path. It does not replace contract or evidence docs. Current safe repo claim: hardware-test package.

Pick the sentence that sounds most like you. Do that path first. Ignore the rest until you have momentum.

## Explore Without Hardware

**Who this is for:** curious visitors who want to understand the configurator before finding or building an instrument.

1. Open the [hosted configurator](https://bseverns.github.io/MN42/).
2. Switch to **Lab**, then select **Start simulator** instead of connecting a serial device.
3. Change one slot, inspect the staged diff, and apply it to the simulated device.

The simulator proves the browser workflow, not physical controls, timing, MIDI wiring, or electrical behavior.

## Play It

**Who this is for:** performers who want one playable setup before reading the whole repo.

**What you need:** an MN42 board, a USB data cable, a supported browser path, and the audio/MIDI/OSC gear you actually plan to use.

**Steps:**

1. Plug the board in over USB and confirm it enumerates.
2. Open the configurator in performer/stage mode.
3. Connect, check the device banner, and load or save a profile.
4. Use the Bridge only if you need OSC or a DAW-facing virtual MIDI port.
5. Before rehearsal or demo use, run the punch list for that exact rig.

**Primary links:**

- [Quickstart for Performers](QuickstartForPerformers.md)
- [Connectivity Guide](ConnectivityGuide.md)
- [Demo Test Punch List](../validation/DemoTestPunchList.md)

**Caveat:** a working bench setup is not a universal host/DAW/browser claim.

## Configure It

**Who this is for:** users who want to change mappings, profiles, scenes, or live setup without touching firmware.

**What you need:** a connected board, the browser configurator, and either direct WebSerial or the local Bridge path.

**Steps:**

1. Decide whether direct WebSerial is enough or whether you need the Bridge.
2. Connect and wait for manifest/config data before editing.
3. Use **Configure** for everyday slot mapping or **Lab** for exact bench controls.
4. Stage edits, review the diff, apply, and wait for confirmation.
5. Save the profile only after the device accepted the setup.

**Primary links:**

- [Configurator Tour](../guides/Configurator.md)
- [Profile Workflow](../guides/ProfileWorkflow.md)
- [Configure Without Recompiling](ConfigureWithoutRecompiling.md)

**Caveat:** the browser helps edit device state; it is not the source of truth by itself.

## Build/Test It

**Who this is for:** builders validating hardware, flashing firmware, or proving a board on the bench.

**What you need:** the current board/build, Teensy 4.0, PlatformIO, USB data cable, and a bench setup you trust.

**Steps:**

1. Check the current hardware status before ordering, soldering, or assuming fabrication files are ready.
2. Build or upload the main firmware from the repo root with `pio run -d firmware -e teensy40_main`.
3. Confirm the board answers `HELLO`.
4. Run the Unity lane with `pio test -d firmware -e teensy40_unity -vvv`.
5. Use hardware-test lanes and receipts for real-board claims.

**Primary links:**

- [Quickstart for Builders](QuickstartForBuilders.md)
- [Current Hardware Build](../reference/HardwareCurrentBuild.md)
- [TESTING](../validation/TESTING.md)

**Caveat:** this repo is not claiming public fabrication readiness or verified rail topology without dated evidence.

## Understand It

**Who this is for:** readers who want the mental model before operating or building anything.

**What you need:** no hardware; just enough patience to avoid reading every deep reference page first.

**Steps:**

1. Read the object card to learn what MN42 is and is not.
2. Open the system map to see hardware, firmware, App, Bridge, and evidence as one system.
3. Read who controls a slot so the reactive and takeover paths have a concrete shape.
4. Use the glossary only when terms get in the way.

**Primary links:**

- [Object Card](ObjectCard.md)
- [System Map](SystemMap.md)
- [Who Controls This Slot?](../learn/OneSignalPath.md)

**Caveat:** if pages disagree, use the [Documentation Truth Map](../reference/DocumentationTruthMap.md); history and planning pages do not define current behavior.

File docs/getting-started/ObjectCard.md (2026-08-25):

# MN42 Object Card

MOARkNOBS-42 is a specific open, reactive MIDI/OSC performance instrument. It is not a generic controller platform and not a minimal faderbank.

Current repo status: hardware-test package. For folder ownership and generated-output boundaries, see [Repository Contents](../project/RepositoryContents.md).

## What Is In The Object?

- 42 virtual control slots
- six envelope follower inputs
- Teensy 4.0 firmware
- MIDI output lanes over USB and hardware MIDI
- RGB LED feedback
- display/status surfaces
- browser configurator support
- optional desktop Bridge for OSC and virtual MIDI workflows

## What Are The Controls?

The main performance model is slot-based. A slot can represent a MIDI behavior, store per-slot settings, and receive modulation from reactive sources.

The reactive sources include:

- envelope follower input
- ARG pair math between envelope followers
- LFO routes
- live hardware control movement
- profile-owned incoming MIDI for supported machine parameters and eligible direct, unmodulated CC slots

These sources do not all participate through one universal resolver. Reactive composition and external-MIDI takeover have separate, documented eligibility and ownership semantics. See [Who Controls This Slot?](../learn/OneSignalPath.md).

## What Comes Out?

MN42 can emit MIDI messages from slot state and modulation. The documented system also supports OSC and virtual MIDI workflows through the Bridge.

The current docs are conservative about host support. Read [Host Compatibility](../reference/HostCompatibility.md) before treating any browser, DAW, or operating-system path as generally verified.

## What Connects To It?

- USB for firmware/configurator paths
- hardware MIDI connections
- signal inputs for envelope follower behavior
- browser configurator over the supported transport path
- local Bridge process when OSC, virtual MIDI, or App-over-Bridge is the better fit

## What Can Be Configured Without Recompiling?

Many performance and mapping behaviors can be configured without recompiling firmware:

- slot message type, channel, and primary value fields
- profiles
- EF assignment and follower settings
- ARG settings
- LFO route targets and ranges
- profile-owned incoming MIDI bindings, response modes, ranges, and takeover policy
- bridge/session workflow settings

See [Configure Without Recompiling](ConfigureWithoutRecompiling.md).

## What Is Experimental Or Hardware-Test Only?

This repo is still framed as a hardware-test package. Hardware-test evidence matters more than optimistic interpretation.

Treat these as conservative boundaries:

- public fabrication readiness is not claimed
- rail topology verification is not implied unless a dated evidence doc says so
- host/DAW compatibility is setup-specific unless covered by receipts
- release status depends on [Release Criteria](../release/ReleaseCriteria.md)

## What Should Not Be Assumed Yet?

Do not assume universal browser support, universal DAW routing, signed bridge installers, fabrication-ready production artifacts, or production-safe hardware variants just because a software check passes.

The instrument is real and documented, but the proof path is deliberately visible.

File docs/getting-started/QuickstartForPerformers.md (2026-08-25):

# Quickstart for Performers

This is the shortest path from plugging in the board to using it live.

```mermaid
flowchart LR
  A[USB connect] --> B[Browser configurator]
  B --> C[Apply / save profiles]
  B --> D{Need OSC or DAW MIDI?}
  D -- No --> E[Stay on WebSerial]
  D -- Yes --> F[Start bridge]
  F --> G[Use OSC / virtual MIDI]
```

## 1. Connect the board

1. Plug MOARkNOBS-42 into your computer over USB.
2. Wait for the board to enumerate.
3. If the board is new or newly flashed, confirm it responds to `HELLO` before show-day use.

## 2. Start with the browser configurator

Use the browser configurator when you want direct USB setup, profile management, and live monitoring without extra routing software.

Use **Stage** mode at a gig. It keeps connection state, firmware identity, active profile, power safety, slot activity, envelope levels, scene recall, and the documented panic-baseline help visible without exposing raw schema forms or lab panels.

Use **Configure** or **Lab** when preparing mappings. Configure keeps everyday slot mapping visible; Lab restores the full bench with EF/ARG/filter/LED editors, import/export, monitor, scope, MIDI monitor, and debug surfaces.

Use **Lab** tools for debugging. Treat those as bench surfaces, not the normal show screen.

Start here:

- [Configurator Tour](../guides/Configurator.md) for the current configurator workflow
- [Operator Tutorial](../guides/OperatorTutorial.md) for the practical operating model
- [Connectivity Guide](ConnectivityGuide.md) if you are not sure whether you need the bridge

## 3. Connect in the configurator

1. Serve the configurator from `http://localhost` or use the published project URL you normally deploy from.
2. Open the configurator. Add `?mode=stage` when you want the performer dashboard first.
3. Click **Connect**.
4. Pick the MOARkNOBS-42 serial device.
5. Wait for the connection banner to show the device identity and firmware details.

## 4. Save and load profiles

- Use profile slots `A` through `D` for on-device saved states.
- Use **Load profile** to recall a stored device state.
- Use **Save profile** after you have applied and confirmed the setup you want to keep.
- Use export/download if you want an external JSON backup as well.

More detail: [Profile Workflow](../guides/ProfileWorkflow.md).

## 5. Use the bridge only when you need it

Use the Node bridge when you need one of these:

- OSC into Max, Pd, TouchOSC, or another OSC host
- A virtual MIDI port for a DAW
- A fallback path when the browser/workstation setup is not the right tool

Bridge details: [OSC Bridge](../guides/OSCBridge.md) and [Performer Bridge Guide](../guides/BridgeForPerformers.md).

## 6. If connection fails

- Re-seat the USB cable and confirm it is a data cable.
- Reopen the configurator and reconnect.
- Serve the configurator from `http://localhost` or another allowed secure context.
- If WebSerial is not working in your browser/workflow, switch to the bridge path in [Connectivity Guide](ConnectivityGuide.md).
- If the board itself is not responding, check [Troubleshooting](../validation/Troubleshooting.md).

## 7. Before a rehearsal or public demo

- Run [Demo Test Punch List](../validation/DemoTestPunchList.md).
- Use [Validation Flow](../validation/ValidationFlow.md) if you need to decide whether the setup is merely connected, actually demo-ready, or still in bench-only status.

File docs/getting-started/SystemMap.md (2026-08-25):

# System Map

> **Doc class:** Orientation. Use this page to see how the physical instrument, App, Bridge, firmware contracts, and evidence docs fit together.

MN42 is a specific reactive performance instrument, not a generic controller platform. The system is easiest to read as one object with several truth boundaries: the hardware exposes controls and signals, firmware owns the runtime behavior, the App stages and applies configuration, and the Bridge gives the browser a structured host/device session.

```mermaid
flowchart LR
  Performer[Performer]
  Controls[42 slots<br/>pots, buttons, LEDs]
  Inputs[Six EF inputs<br/>CV/audio envelope followers]
  Firmware[Firmware<br/>manifest, schema, config]
  App[Browser App<br/>staged editor and monitor]
  Bridge[Structured Bridge<br/>host session and transports]
  Hosts[MIDI/OSC hosts<br/>DAWs, synths, tools]
  ExternalMIDI[Other MIDI devices<br/>performance input]
  Evidence[Bench and release evidence]

  Performer --> Controls
  Performer --> Inputs
  Controls --> Firmware
  Inputs --> Firmware
  App <--> Bridge
  Bridge <--> Firmware
  Firmware <--> Hosts
  ExternalMIDI <--> Firmware
  Bridge --> Hosts
  Firmware --> Evidence
  App --> Evidence
  Bridge --> Evidence
```

## Reading It

- The **object** is the 42-slot controller with six envelope followers and reactive modulation.
- The **firmware** is the source of truth for persisted profile/config state and supported capabilities.
- The **App** is the operator surface for staging, applying, monitoring, and profile work.
- The **Bridge** gives desktop browsers structured access to device state and host transports.
- **Incoming MIDI** is a profile-owned firmware performance lane. Supported CC routes keep working over DIN or USB without the App or Bridge attached.
- The **contracts** define what the App, Bridge, and firmware promise to each other.
- The **evidence docs** record what has actually been tested.

## Truth Boundaries

Use the contracts when behavior matters:

- [Manifest Contract](../reference/ManifestContract.md) for firmware capabilities, schema, and release boundary data.
- [Bridge Transport Contract](../bridge/BridgeTransportContract.md) for browser-to-Bridge session behavior.
- [MN42 Line Protocol](../reference/MN42LineProtocol.md) and [Serial Protocol](../reference/SerialProtocol.md) for device command lanes.
- [Modulation Matrix Contract](../reference/ModulationMatrixContract.md) for EF, ARG, LFO, and route reporting.
- [MIDI Input Mapping](../guides/MidiInputMapping.md) for profile-owned inbound CC routes and takeover behavior.

Use the evidence pages when readiness matters:

- [TESTING](../validation/TESTING.md) for software and hardware-test lanes.
- [Release Criteria](../release/ReleaseCriteria.md) for release gates.
- [Bench Receipts](../bench/README.md) for observed App, Bridge, firmware, host, latency, and noise receipts.

## Next Pages

- [Object Card](ObjectCard.md) for the physical definition.
- [Configure Without Recompiling](ConfigureWithoutRecompiling.md) for what can be changed from the App/Bridge path.
- [Who Controls This Slot?](../learn/OneSignalPath.md) for the reactive-composition and external-takeover paths.
- [Guided Routes](GuidedRoutes.md) if you want a role-based reading order.

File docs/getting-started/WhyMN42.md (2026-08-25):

# Why MN42

MOARkNOBS-42 is a performance instrument for deciding what gets to move a control.

A performer's hand can establish a value. Sound can disturb it through envelope followers. Two signals can be combined through ARG. Time can move it through an LFO. For eligible direct CC slots and machine-level parameters, another MIDI device can take control; soft pickup lets the performer cross that remote value and take the slot back without a jump.

That shifting relationship between body, environment, time, and other machines is the musical reason MN42 exists.

## Control is a relationship

MN42 is not a bank of knobs with modulation added around the edges. Its 42 slots are places where control relationships can be configured, recalled, observed, and performed.

Two paths make the idea concrete:

- **Reactive composition:** a physical baseline can be shaped by EF/ARG behavior and LFO routes according to their documented add, subtract, replace, scale, or centered semantics.
- **External takeover:** profile-owned incoming MIDI can write an eligible direct, unmodulated CC slot or a supported machine parameter. Soft pickup prevents the physical pot from snapping the value back until it crosses the externally established value.

Those paths are related, but they are not one universal arbitration engine. Current firmware deliberately rejects ambiguous incoming-MIDI targets such as independently modulated slot baselines. The constraint keeps the musical result explainable.

Read [Who Controls This Slot?](../learn/OneSignalPath.md) for the visual version, then [Reactive Control Guide](../guides/ReactiveControlGuide.md) and [MIDI Input Mapping](../guides/MidiInputMapping.md) for the two deeper paths.

## Legibility makes the behavior playable

Unusual control relationships are useful only if a performer can understand and recover them.

MN42 keeps that logic visible through:

- open hardware and firmware that can be inspected and rebuilt;
- a browser App with separate Stage, Configure, and Lab surfaces;
- profiles that keep reactive settings and incoming MIDI routes with the device;
- a local Bridge that separates host routing from instrument configuration;
- contracts that define exact behavior instead of asking the UI to invent it;
- evidence documents that distinguish a demonstrated path from a general claim.

Openness is therefore not the whole thesis. It is what makes this reactive instrument teachable, auditable, and trustworthy.

## More than a sealed controller

Many controllers hide value ownership inside presets, host mappings, or companion software. MN42 makes the movement itself inspectable:

- what established the baseline;
- which reactive sources contributed;
- where a route exits;
- when external MIDI owns a virtual pot;
- when the performer's hand has taken it back;
- what is live now versus staged for Apply.

The physical surface, firmware, App, Bridge, profiles, and documentation are parts of one instrument because each helps answer those questions.

## Who this matters to

MN42 makes the most sense for:

- experimental musicians who want control movement to become compositional material;
- sound and media artists working across audio, MIDI, OSC, and physical gesture;
- educators who want modulation, takeover, and state authority to remain visible;
- instrument hackers who want to audit, rebuild, or alter the system without pretending unverified behavior is proven.

If that sounds like you, continue with [Who Controls This Slot?](../learn/OneSignalPath.md), [Quickstart for Performers](QuickstartForPerformers.md), or [Quickstart for Builders](QuickstartForBuilders.md).

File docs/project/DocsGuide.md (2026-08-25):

# Docs Guide

This page is the sitemap and governance guide for MN42 documentation.

If two pages disagree, use the [Documentation Truth Map](../reference/DocumentationTruthMap.md). That page defines the truth hierarchy; this page only tells you where to go.

## Where Do I Start?

- New to the instrument: [Start Here](../getting-started/StartHere.md)
- Need the physical definition: [Object Card](../getting-started/ObjectCard.md)
- Need the repo map: [Repository Contents](RepositoryContents.md)
- Want a reading path: [Guided Routes](../getting-started/GuidedRoutes.md)
- Performing with the device: [Quickstart for Performers](../getting-started/QuickstartForPerformers.md)
- Building or flashing: [Quickstart for Builders](../getting-started/QuickstartForBuilders.md)
- Lost in terms: [Glossary](../reference/Glossary.md)

## Site Categories

Use these categories when deciding where a doc belongs:

| Category  | Use it for | First pages |
| --- | --- | --- |
| Learn | concepts, vocabulary, and teaching paths | [Why MN42](../getting-started/WhyMN42.md), [Who Controls This Slot?](../learn/OneSignalPath.md) |
| Use | performer/operator workflows | [Configurator Tour](../guides/Configurator.md), [Profile Workflow](../guides/ProfileWorkflow.md) |
| Build | hardware, firmware, bring-up, flashing | [Builder's Handbook](../getting-started/BuildersHandbook.md), [Bringup](../hardware-test/Bringup.md) |
| Prove | tests, validation, release readiness, receipts  | [TESTING](../validation/TESTING.md), [Release Criteria](../release/ReleaseCriteria.md) |
| Reference | protocol, contracts, compatibility, pin maps | [MN42 Line Protocol](../reference/MN42LineProtocol.md), [Manifest Contract](../reference/ManifestContract.md) |
| Project | support, process, history, pilot-run framing | [License and Support](LicenseAndSupport.md), [Pilot Run](PilotRun.md) |
                                                 |

## Which Docs Are Canonical?

Canonical behavior and support boundaries live in contract docs:

- [App README](https://github.com/bseverns/MOARkNOBS-42/blob/main/App/README.md)
- [Bridge README](https://github.com/bseverns/MOARkNOBS-42/blob/main/bridge/README.md)
- [Firmware README](https://github.com/bseverns/MOARkNOBS-42/blob/main/firmware/README.md)
- [Host Compatibility](../reference/HostCompatibility.md)
- [Manifest Contract](../reference/ManifestContract.md)
- [MN42 Line Protocol](../reference/MN42LineProtocol.md)
- [Serial Protocol](../reference/SerialProtocol.md)
- [Bridge Transport Contract](../bridge/BridgeTransportContract.md)
- [Bridge Write Lanes](../bridge/BridgeWriteLanes.md)
- [Modulation Matrix Contract](../reference/ModulationMatrixContract.md)

Orientation pages may simplify these contracts, but they do not override them.

For folder ownership and generated-output boundaries, use [Repository Contents](RepositoryContents.md).

## Where Are Evidence Docs?

Evidence docs live under validation, release, bench, and hardware-test areas:

- [Testing Story](../validation/TestingStory.md)
- [TESTING](../validation/TESTING.md)
- [Validation Flow](../validation/ValidationFlow.md)
- [Release Criteria](../release/ReleaseCriteria.md)
- [Bench Receipts](../bench/README.md)
- [Hardware Test Matrix](../hardware-test/TestMatrix.md)
- [Known Issues](../hardware-test/KnownIssues.md)

Bench receipts should remain in the repo even when they are not all visible in top navigation.

## Where Are Historical Docs?

Historical and planning docs are useful context, not current truth:

- [History](HISTORY.md)
- [Lineage](lineage.md)
- [TODO](TODO.md)
- `docs/agents/_reports/`
- dated audits such as [Repo Health Audit 2026-03](../validation/repo-health-audit-2026-03.md)
- old app/runtime upgrade plans and release-packaging plans

If a historical page conflicts with a contract or evidence doc, the historical page loses.

## What Do I Read If I Am Lost?

Read in this order:

1. [Object Card](../getting-started/ObjectCard.md)
2. [Guided Routes](../getting-started/GuidedRoutes.md)
3. [Who Controls This Slot?](../learn/OneSignalPath.md)
4. [Glossary](../reference/Glossary.md)
5. [Documentation Truth Map](../reference/DocumentationTruthMap.md)

Then choose one lane: Learn, Use, Build, Prove, Reference, Project, or Archive.

## Canonical Visuals And Behavior Media

The repo keeps many useful fabrication views, bench photos, and diagnostic screenshots. Only the small set below should be treated as a current visual answer to “what does MN42 look like now?”

| Canonical view | Maintained source | Current status |
| --- | --- | --- |
| Physical instrument hero | `docs/assets/board/moarF.png` | Current board view; not a claim of a finished enclosure or production unit |
| Annotated physical surface | Not yet captured | Required; do not substitute a fabrication render and call it a finished instrument |
| App Configure | `App/tests/visual-snapshots/configure-1440x1000.png` | Approved visual-regression baseline |
| App Lab | `App/tests/visual-snapshots/lab-1920x1080.png` | Approved visual-regression baseline |
| App Stage | `App/tests/visual-snapshots/stage-1440x1000.png` | Approved visual-regression baseline |
| Bridge Monitor | `docs/images/bridge-stage-mode.png` | Recapture required; the committed image still shows the legacy Stage label |

Other UI images are explanatory or historical unless a page explicitly identifies them as current. A canonical capture must record:

- the surface and viewport;
- capture date and source commit;
- simulator versus attached hardware;
- any profile, recipe, or staged state needed to reproduce it;
- useful alt text that describes the information hierarchy rather than decorative color.

The App's four approved PNGs are pixel assertions on the canonical macOS + pinned Chromium lane. Routine screenshot matrices remain diagnostic artifacts and do not become front-door imagery automatically.

### First behavior video

The first canonical behavior clip should document incoming-MIDI soft pickup on attached hardware:

1. an external CC establishes the value of one eligible direct slot;
2. the physical pot moves below that value without snapping the output;
3. the pot crosses the remote value;
4. physical control resumes.

Capture the control surface and a visible value/output monitor in the same take. Record firmware identity, profile, MIDI source, destination slot, and source commit beside the clip. Label it **demonstration**, not validation, unless a matching receipt records the setup and expected result. Provide a caption or transcript.

Until that attached-hardware take exists, [Who Controls This Slot?](../learn/OneSignalPath.md) is the canonical storyboard. A simulator-only clip must be labeled as simulator rehearsal and must not replace the hardware demonstration.

## Editing Rules

- Put new conceptual/teaching pages in Learn.
- Put operator workflows in Use.
- Put first-boot and flashing workflows in Build.
- Put proof, checklists, receipts, and release gates in Prove.
- Put protocol and compatibility details in Reference.
- Put support, process, history, and governance in Project.
- Put generated reports, old audits, and stale plans in Archive.

Before adding a new page, decide whether it is contract, evidence, orientation, planning, or history. If that is unclear, update the [Documentation Truth Map](../reference/DocumentationTruthMap.md) or the [Documentation Compaction Plan](DocumentationCompactionPlan.md).

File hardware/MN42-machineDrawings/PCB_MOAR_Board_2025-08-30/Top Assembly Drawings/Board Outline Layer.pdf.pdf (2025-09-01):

7x6

EF6 MIDI OUT | EF4

f2

### MOAR k NOBS - 42

EF5

f1

1x1

### PWR

EF3

### MAIN

### brain

v1.02

MIDI IN | EF1 | EF2
\\ | /

### CNTRL

/ | \\

1x2

### LED

### LED

2x2 | 3x2 | 4x2 | 5x2 | 6x2 | 7x2
1x3 | 2x3 | 3x3 | 4x3 | 5x3 | 6x3 | 7x3
1x4 | 2x4 | 3x4 | 4x4 | 5x4 | 6x4 | 7x4
1x5 | 2x5 | 3x5 | 4x5 | 5x5 | 6x5 | 7x5
1x6 | 2x6 | 3x6 | 4x6 | 5x6 | 6x6
2x1 | 3x1 | 4x1 | 5x1 | 6x1 | 7x1

MIDI-TEST

EF/DISP-TEST

# FOLLOW

ME

VIN_FUSED

VLED

MRR

MCR

GND

GND

VREF

J1
SW49

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
C78 | C80 | C81
C82 | C83

C85

C86

C61

C87 | C88 | C89

C90

C91
C92 | C93 | C94 | C95 | C96 | C97
C98 | C99 | C100 | C101
C102 | C103
C104
C105 | C106 | C107
C108 | C109C121

C120

C126

C127

C128

C124

C123
C122

U5

U1

SW48

SW47

SW45 | SW46

SW44

SW43

Screen1

RV3

RV2

RV1

ROW_MUX1

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
R69 | R68

R47

R46

R21
R19
R4

R2

LEDPWR1

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
COL_MUX1

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
R74 R73

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
C25 | C47 | C50
C52
C49 | C51

C48

C46

C45

C43

C42
C40
C12 | C39

C11

C54

C62

C63

C79

C110 | C111
C112 | C113 | C114 | C115 | C116 | C117 | C118C119

C125

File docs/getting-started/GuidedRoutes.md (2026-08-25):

# Guided Routes

Pick one route, finish it, then come back for the others.

If you only need the next five minutes, use [First Five Minutes](FirstFiveMinutes.md). This page is the longer reading map after that first choice.

## Builder Route

**Best for:** someone assembling, flashing, or proving hardware.

**Time estimate:** 45-60 minutes for reading, not counting bench work.

**Outcome:** you know the bring-up order, flashing lane, and proof boundary.

Primary links:

1. [Object Card](ObjectCard.md)
2. [Quickstart for Builders](QuickstartForBuilders.md)
3. [Hardware Story](HardwareStory.md)
4. [Builder's Handbook](BuildersHandbook.md)
5. [Bringup](../hardware-test/Bringup.md)

Go deeper:

- [Testing Story](../validation/TestingStory.md)
- [Hardware Test Matrix](../hardware-test/TestMatrix.md)
- [Release Criteria](../release/ReleaseCriteria.md)

## Learner Route

**Best for:** someone trying to understand the architecture and vocabulary.

**Time estimate:** 35-45 minutes.

**Outcome:** you can explain the object, signal path, and main contracts in plain language.

Primary links:

1. [System Map](SystemMap.md)
2. [Why MN42](WhyMN42.md)
3. [Who Controls This Slot?](../learn/OneSignalPath.md)
4. [Glossary](../reference/Glossary.md)
5. [Reactive Control Guide](../guides/ReactiveControlGuide.md)

Go deeper:

- [ARG Guide](../guides/ARGGuide.md)
- [Filter Feel Guide](../guides/FilterFeelGuide.md)
- [LFO Route Guide](../guides/LfoRouteGuide.md)

## Musician Route

**Best for:** someone who wants a playable rig without reading every firmware page first.

**Time estimate:** 20-30 minutes.

**Outcome:** you can connect, configure, use profiles, and recover from common show-day mistakes.

Primary links:

1. [Quickstart for Performers](QuickstartForPerformers.md)
2. [Configurator Tour](../guides/Configurator.md)
3. [Profile Workflow](../guides/ProfileWorkflow.md)
4. [Connectivity Guide](ConnectivityGuide.md)
5. [Failure-First Guide](../validation/FailureFirst.md)

Go deeper:

- [Bridge for Performers](../guides/BridgeForPerformers.md)
- [Preset Library](../guides/PresetLibrary.md)
- [Configure Without Recompiling](ConfigureWithoutRecompiling.md)

## Teaching Route

**Best for:** workshops, studios, and classrooms.

**Time estimate:** 30-45 minutes.

**Outcome:** a learner can move from concrete behavior to modulation concepts without drowning in implementation detail.

Primary links:

1. [Object Card](ObjectCard.md)
2. [Who Controls This Slot?](../learn/OneSignalPath.md)
3. [Configure Without Recompiling](ConfigureWithoutRecompiling.md)
4. [Reactive Control Guide](../guides/ReactiveControlGuide.md)
5. [Testing Story](../validation/TestingStory.md)

Go deeper:

- [MIDI + DSP 101](../Primers/MIDI-DSP101.md)
- [Firmware Main Reading Path](../firmware/FirmwareMainReadingPath.md)
- [Documentation Truth Map](../reference/DocumentationTruthMap.md)

## If You Are Lost

Read [Docs Guide](../project/DocsGuide.md). It explains which pages are canonical, which pages are evidence, and where historical notes live.

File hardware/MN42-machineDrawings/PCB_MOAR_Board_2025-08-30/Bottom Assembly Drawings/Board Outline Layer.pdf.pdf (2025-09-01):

/ | \\

# CNTRL

\\ | /

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
C120
C121

C122

C123
C124

U5

U1

# ROW_MUX1

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
# COL_MUX1

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
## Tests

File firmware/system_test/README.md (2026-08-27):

# System Test Pit

Welcome to the gauntlet. This folder is where the firmware proves it can survive a night on stage.
These are **hardware-in-the-loop** tests — they don't fake the MCU or the peripherals.
We flash the real board and make sure the buttons, LEDs, EEPROM and friends actually do their job.

## OSC↔firmware rodeo (from [`docs/validation/TESTING.md`](../../docs/validation/TESTING.md))

`docs/validation/TESTING.md` defines the OSC + WebSerial hardware-in-the-loop lane. Think of these as end-to-end stories
the automated runner rehearses:

1. **Handshake & heartbeat** – `mn42_bridge.js` should auto-fire `HELLO`, wait for the board’s `{"hello":"mn42"}` reply, and
   stream `/mn42/slots` + `/mn42/envelopes` snapshots. No stream, no party.
2. **OSC command loop** – sling `/mn42/cmd` with `{ "cmd": "SET_SLOT_VALUE", "slot": N, "value": V }`. The bridge must validate
   the JSON, translate it to the firmware text command `SET_SLOT_VALUE,<slot>,<value>`, and the firmware should report the new
   value in the next `/mn42/slots` burst.
3. **Keep-alive sanity** – once streaming, periodic snapshots should keep landing without re-sending `HELLO`. If packets stop,
   the bridge should whine in its stdout and attempt a reconnect.
4. **Storage smoke pass** – when explicitly armed, the runner closes the bridge phase, opens the serial lane directly, and
   proves `SAVE_PROFILE` / `LOAD_PROFILE` / `RESET_PROFILE`, `SAVE_MACRO_SLOT` / `RECALL_MACRO_SLOT`, and
   `SAVE_SCENE` / `GET_SCENES` / `RECALL_SCENE` against a real board.

These checkpoints match the spirit of the "Real hardware gauntlet" section: the scripts aren't just poking APIs, they're
proving the board, bridge, and OSC stack stay in lockstep.

## What's inside

- `mn42_fullstack_runner.js` – Node-based system smoke test that orchestrates the OSC ↔ bridge ↔ firmware handshake above, and
  can optionally run the destructive EEPROM storage smoke pass after the bridge phase.
- `mn42_bridge_session_runner.js` – Node-based bridge-session proof for the upgraded browser-console path:
  `/api/connect`, `/api/device/session`, `/api/device/stage`, `/api/device/apply`, cleanup apply, and `/ws/events`.
- `mn42_boot_contract_runner.js` – Node-based direct-serial proof for the exact `teensy40_main` boot path: standalone boot
  banner, `ENTER_CONFIG_MODE` reboot, configurator handshake, one staged `SET_ALL` apply/ACK, and cleanup back to the original
  config.
- `mn42_persistence_abuse_runner.js` – Evidence wrapper for persistence abuse. Safe by default: it runs the non-destructive
  boot/apply/readback proof and only runs destructive profile/macro/scene storage checks when `--exercise-storage` is passed.
- `test_*.cpp` – hardware-oriented subsystem tests, including Ctrl3/Ctrl4 double-press timing, immediate Ctrl5 tap tempo, and the `Ctrl0+Ctrl1+Ctrl4` live LFO 1 chord.
- `TestHelpers.cpp` – shared glue for those sketches.

## Running the full-stack script

1. Flash the hardware with the full system firmware:

   ```bash
   pio run -d firmware -e teensy40_full_system -t upload
   ```

2. Install bridge deps if you haven’t already:

   ```bash
   npm --prefix bridge ci
   ```

3. Fire the runner (it spawns the bridge for you). Override ports via flags or env vars if needed:

   ```bash
   node firmware/system_test/mn42_fullstack_runner.js \
     --serial /dev/ttyACM0 \
     --osc-out 10000 \
     --osc-in 10001 \
     --report logs/system-test.json | tee logs/system-test.log
   ```

   It exits non-zero if any OSC↔firmware scenario craters. Reports capture both the story (JSON) and the raw log so CI can hoard
   artifacts.

4. If you want the storage/recovery pass too, use explicit sacrificial slots:

   ```bash
   node firmware/system_test/mn42_fullstack_runner.js \
     --serial /dev/ttyACM0 \
     --exercise-storage \
     --profile-slot 3 \
     --scene-slot 5 \
     --pot-index 0 \
     --report logs/system-test-storage.json | tee logs/system-test-storage.log
   ```

   This intentionally overwrites:

- the selected profile slot
- the single macro snapshot
- the selected scene slot

   The runner restores the active live profile and rewrites the selected profile slot if it had an existing stored payload, but it
   cannot non-destructively back up the macro snapshot or an occupied scene slot. Pick bench-only storage targets.

## Running the structured bridge-session proof

Use this when you want hardware evidence for the modern bridge runtime rather than the older raw OSC heartbeat story.

1. Put `teensy40_main` into USB configurator mode first. The simplest repeatable lane is:

   ```bash
   node firmware/system_test/mn42_boot_contract_runner.js \
     --serial /dev/cu.usbmodemXXXX \
     --attach-live \
     --report logs/boot-contract-attach-live.json
   ```

2. Run the bridge-session proof:

   ```bash
   node firmware/system_test/mn42_bridge_session_runner.js \
     --serial /dev/cu.usbmodemXXXX \
     --http-port 8791 \
     --report logs/bridge-session-test.json
   ```

The runner proves:

- the browser-console server starts
- `/api/connect` starts the bridge against the real USB serial port
- `/api/device/session` reaches `ready`
- `/ws/events` emits `device.ready`
- `/api/device/stage` marks the session dirty
- `/api/device/apply` returns an ACK/checksum and promotes staged config to live
- cleanup apply restores the original live config

## Running the persistence abuse wrapper

Use this when you want one JSON receipt that separates:

- safe automated HIL proof
- opt-in destructive storage proof
- Unity-covered corruption scenarios
- manual-only fault-injection cases

Safe default run:

```bash
node firmware/system_test/mn42_persistence_abuse_runner.js \
  --serial /dev/cu.usbmodemXXXX \
  --report logs/persistence-abuse-safe.json
```

The safe run writes two artifacts:

- the requested JSON report
- a dated Markdown receipt at `docs/bench/firmware/YYYY-MM-DD_persistence-safe-summary.md`

Destructive storage run on sacrificial slots:

```bash
node firmware/system_test/mn42_persistence_abuse_runner.js \
  --serial /dev/cu.usbmodemXXXX \
  --exercise-storage \
  --profile-slot 3 \
  --scene-slot 5 \
  --pot-index 0 \
  --report logs/persistence-abuse-storage.json
```

The wrapper does not fake real-board corruption. It reports primary/backup/default recovery from the Unity suite and leaves
power-cut or raw-corruption fault injection in the manual bench lane until there is an explicit safe hook.

## When to reach for the older sketches

Those `test_*.cpp` binaries still have a place when you’re chasing electrical gremlins—buttons, LEDs, or the envelope follower
baseline. Use `pio run -d firmware -e teensy40_eeprom_persistence` and friends for deep dives, then pivot back to the automated
runner once the solder smoke clears.

Rock it, break it, then make it better.

## Running the production boot contract runner

Use this when you need evidence for the real `teensy40_main` boot/configurator handoff instead of the bridge demo lane.

1. Install bridge deps if you have not already:

   ```bash
   npm --prefix bridge ci
   ```

2. Run the boot contract proof against the attached board. Add `--flash` when you want the runner to upload `teensy40_main`
   first:

   ```bash
   node firmware/system_test/mn42_boot_contract_runner.js \
     --serial /dev/cu.usbmodemXXXX \
     --flash \
     --report logs/boot-contract.json | tee logs/boot-contract.log
   ```

   If the board is already running the current firmware and you cannot reliably attach before the one-shot standalone boot
   banner, use the attach-live lane instead:

   ```bash
   node firmware/system_test/mn42_boot_contract_runner.js \
     --serial /dev/cu.usbmodemXXXX \
     --attach-live \
     --report logs/boot-contract-attach-live.json | tee logs/boot-contract-attach-live.log
   ```

The runner proves:

- standalone boot emits the boot banner plus `{"type":"boot_mode","mode":"standalone_runtime"}`
- direct serial answers `HELLO` while the standalone runtime is alive
- `ENTER_CONFIG_MODE` reboots into `{"type":"boot_mode","mode":"usb_configurator"}`
- configurator mode completes `HELLO` -> `GET_MANIFEST` -> `GET_SCHEMA` -> `GET_CONFIG`
- one small `SET_ALL` change receives a matching ACK/checksum and readback
- cleanup restores the original config unless `--skip-cleanup` is set

In `--attach-live` mode, the runner still proves the real `HELLO` -> `ENTER_CONFIG_MODE` -> configurator handshake ->
`SET_ALL`/ACK/cleanup path, but it does not require capturing the cold-boot standalone banner from byte zero.

Note: after the configurator-mode proof, the board remains in USB configurator mode until the next manual reset or power cycle.

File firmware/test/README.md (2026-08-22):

# MOARkNOBZ Firmware: Hardware Testing Suite

This project doubles as a proving ground and a punching bag. Two flavors of tests keep the firmware honest:

* `src/*_t.cpp` – manual hardware gauntlets you flash and prod like a lab rat.
* `test/test_*.cpp` – the only Unity smoke tests, run under `pio test` when you want receipts without solder burns.

Only the `test/test_*.cpp` crowd plays nice with Unity. Anything in `src/*_t.cpp` won't budge until you upload it to real silicon.

You're in `firmware/test/`; bounce back to [../README.md](../README.md) for the grand tour of the firmware proper.

## Unity Output

`unity_output.cpp` is the trash‑talking megaphone that lets Unity scream over `Serial1` when tests run on real iron. The test
rig `[env:teensy40_unity]` flips on `UNITY_INCLUDE_CONFIG_H`, so `unity_config.h` wires Unity's macros straight into those
hooks—no extra `build_src_filter` dance.

`UNITY_OUTPUT_START()` boots the chatter at 115200 on `Serial1` by default. If your hardware grooves at some other rate, crack
open `unity_config.h` and remix the macro.

`GlobalsStub.cpp` seeds `g_tappedBPM` plus the other globals the unit suite
needs, so the linker chills without hauling in `Globals.cpp` and its SD baggage.

## Custom Runner

PlatformIO's stock Unity runner speaks over the default `Serial` port, which is useless for this rig. Our tests scream down
`Serial1`, so we roll a tiny Python runner that just parses Unity's output and calls it a day.

To take it for a spin from repo root:

```bash
pio test -d firmware -e teensy40_unity -vvv
pio test -d firmware -e native_midi_input -vvv
```

Or, if you're already inside `firmware/`:

```bash
pio test -e teensy40_unity -vvv
```

Drop new flashing logic into `stage_uploading()` if your CI needs to lob firmware at some remote hardware. The rest of the
runner is pure line parsing, so hack away.

## Hardware Hit List

| File | What it beats on |
|---|---|
| `src/main_t.cpp` | LEDs, button matrix, slot pot, envelope followers, OLED display |
| `src/unified_t.cpp` | Whole rig at once: LEDs, buttons, pots, envelopes, display, config |
| `src/biquadfilter_t.cpp` | BiquadFilter DSP math only |
| `src/eeprom_persistence_t.cpp` | EEPROM, ConfigManager, slots, display, buttons, pots, envelopes, LEDs |
| `src/verify_slots_t.cpp` | MIDISlots and EEPROM integrity |
| `test/test_led_manager.cpp` | LEDManager brightness and colour knobs |
| `test/test_button_manager.cpp` | ButtonManager long‑press timing |
| `test/test_potentiometer_manager.cpp` | Pot channel + CC mapping |
| `test/test_display_manager.cpp` | DisplayManager update throttle |
| `test/test_envelope_follower.cpp` | EnvelopeFollower low‑pass/high‑pass flip |
| `test/test_config_manager.cpp` | ConfigManager EEPROM recovery |
| `test/test_midi_handler.cpp` | MIDIHandler program/aftertouch/pitch bend/NRPN/SysEx routing – fakes the pipes, so keep it off hardware |
| `test/test_arpeggiator.cpp` | Arpeggiator start/stop sanity |
| `test/test_biquad_filter.cpp` | BiquadFilter low‑pass vs high‑pass math |
| `test/demo_button_ef_usb_midi.cpp` | Punk-simple USB MIDI hardware demo: one button, one envelope follower |

### Picking the right test

Say the OLED ghosts you mid-jam:

1. Scan the table and spot `test/test_display_manager.cpp`.
2. Blast the whole Unity suite: `pio test -d firmware -e teensy40_unity -vvv` (or `pio test -e teensy40_unity -vvv` from `firmware/`). `test/test_mainUnity.cpp` will herd every test, including the display check. Want just one? comment out the `RUN_TEST` lines you don't care about and rerun.
3. If Unity shrugs, flash `src/main_t.cpp` (`pio run -e teensy40_full_system -t upload`) and watch the screen dance.
4. Still blank? time to chase solder joints.

### Shared helpers

`TestHelpers.cpp` anchors the control-button matrix in one spot so every test riffs from the same pin map. Include `TestHelpers.h` and you're good to shred without duplicating arrays.

#### Hardware I/O fakes with a safety switch

`Hardware/IO.h` is the new patch bay for `analogRead()` and `digitalRead()`. The default passthrough still hits the real ADC/GPIO on hardware, but tests can hijack the lines with `hardware::setAnalogReadProvider()`/`setDigitalReadProvider()` or the friendlier `Scoped…` wrappers. Feed it a lambda, spill out whatever fake voltage or button state you need, and Unity will believe you. Check `test/test_hardware_io.cpp` for the full recipe, including a tiny sequence generator that loops canned ADC readings while ButtonManager chews through its matrix. Use it to slam extreme values, bounce simulations, or timing edge cases without touching copper.

## Manual machine tests (`src/*_t.cpp`)

When you need to stare the hardware in the face, grab a `src/*_t.cpp` sketch and drive it yourself.

Example: run the unified gauntlet and see what smokes first.

1. `cd firmware`
2. `pio run -e teensy40_unified_test -t upload`
3. `pio device monitor`
4. Mash buttons, twist pots, and read the OLED like a fortune teller. Fix whatever flinches.

## Now with Unity smoke tests

We finally caved and wired up a few automated checks in `test/test_*.cpp` for those lonely nights when you want proof without solder burns. Anything in `src/*_t.cpp` still demands real hardware and a steady trigger finger.

```bash
pio test -d firmware -e teensy40_unity -vvv
```

### Native-host seam

`native_biquad` is the first hardware-free firmware lane. It tests the
Arduino-independent `BiquadFilter` coefficient and response behavior on the
CI host:

```bash
pio test -d firmware -e native_biquad -vvv
```

`native_transport` executes the Arduino-independent modulation token-bucket
policy on the CI host, including cold-reset timing, refill/capacity behavior,
32-bit clock wraparound, Note priority, rotating fairness, and failed-attempt
token preservation:

```bash
pio test -d firmware -e native_transport -vvv
```

`native_modulation` executes slot-value composition without the Arduino HAL,
including EF/LFO ordering, all lane modes, clamping, sanitization, and the
legacy replacement curve:

```bash
pio test -d firmware -e native_modulation -vvv
```

`native_persistence` exercises the extracted storage-map and migration-layout
arithmetic plus profile-modulation packing, sanitization, and CRC semantics:

```bash
pio test -d firmware -e native_persistence -vvv
```

It complements, rather than replaces, the Teensy Unity/HIL environment. New
native tests should stay behind a deliberate portable boundary; do not pull
Arduino, display, SD, or USB transport dependencies into this lane.

 The `teensy40_unity` rig only flips on `UNIT_TEST`. If you also define `USB_MIDI_STUB`, `test/usb_midi.cpp` and pals hijack the usual Teensy globals and fake out `MIDI` and `usbMIDI`. Instead of playing macro shell games, we drop in a skinny `usb_midi_class` that exposes the same face as the real deal. Any code shouting for `usbMIDI` ends up talking to our stub, the core header never loads, and the linker goes back to sleep. A tiny `MIDI.h` shim rides shotgun so the `midi` namespace exists even when the heavyweight library sits out. Hardware builds leave that flag off so `MIDIHandler.cpp` sticks with the legit USB stack—no linker brawls, no ghosts.

  Tests never include `<Arduino.h>` directly anymore. Drop `#include "unity_config.h"` at the top and it drags in Arduino and our usbMIDI doppelganger. The `teensy40_unity` env rewrites the core's `usbMIDI` symbols at build time so the stub keeps center stage and the real header stays buried. Skip the shim and the compiler will howl about dueling `usb_midi_class` defs.

### Serial? fake it.

Vendor libs love to yammer over `Serial` even when there's no UART in sight. Host-side builds don't drag in the Arduino core, so `test/SerialStub.h` fakes the small `Print` and `HardwareSerial` surface used by native seams. The Teensy Unity graph keeps the OLED, BusIO, FastLED/OctoWS2811, and LittleFS libraries out entirely: test-local Adafruit/FastLED headers provide only the interface types exercised by software tests. Hardware builds still resolve the real libraries.

Unity is fussy and demands a `unity_config.h` to map its battle cries.
There's a lean version in `test/unity_config.h` that just sprays bytes
over `Serial1`. If you need different output, crack that file open and
remix the macros.

That env sets `test_build_src = true`, but we keep the haul lean with a `build_src_filter`. Only the bits we actually test hitch a ride—`test_mainUnity.cpp`, `Arpeggiator.cpp`, `MIDIHandler.cpp`, plus `GlobalsStub.cpp` and `Utility.cpp` so the clock math and tapped BPM global keep time. `DisplayManager::registerInteraction()` gets faked in `test/DisplayManagerStub.cpp` so the UI stays out of the link step. If anything in that pile won't compile, Unity will scream before you ever flash a board.

### VS Code's flaky build staging

If VS Code yells about `firmware/test/DisplayManagerStub.cpp` and a missing `.sconsign311.dblite`, that's SCons trying to log its dependency cache before PlatformIO finished birthing the `.pio/build/<env>` directory. We now strong-arm that folder into existence in `firmware/scripts/deprecated_copy_flag.py` (peek [`firmware/scripts/README.md`](../scripts/README.md) for the gritty details), but if you see the error again, nuke `.pio/` and rerun `pio test -d firmware -e teensy40_unity -vvv` so the script can repave the path.

### test_envelope_follower.cpp
Snaps the EnvelopeFollower between low-pass and high-pass to make sure DC gets gutted on command.

### test_config_manager.cpp
Corrupts EEPROM headers on purpose and checks that the backup block rides to the rescue.

### test_button_manager.cpp
Fakes time itself to ensure long presses don't fire until 500ms has actually passed and that a follow-up tap is needed to seal the deal.

### test_led_manager.cpp
Makes sure the LED engine listens when we bark new brightness or colour orders.

### test_potentiometer_manager.cpp
Checks that channel and CC mapping stick for the first slot pot.

### test_display_manager.cpp
Pokes the update interval to prove the UI can chill when told.

### test_midi_handler.cpp

Shoots fake MIDI through stubbed veins to make sure routing doesn't flake out. The usb_midi impostors live in this folder and disappear on real silicon, so `teensy40_unified_test` leaves this test on the bench. Only the `teensy40_unity` rig builds with `UNIT_TEST` to conjure those impostors; every other env skips the flag, so anything leaning on the stub just naps.

The stub's `MidiType` enum mirrors the real deal. The opener is `SystemExclusive`, the curtain drop is `EndOfExclusive`, and a freshly-minted `Tick` rides 0xF8 so you can count the beat without pulling in the whole clock rig. If your tests still shout the old names, patch 'em—yesterday's API won't save today's jam.

### test_arpeggiator.cpp
Starts the riff machine, stops it, and double-checks it grabbed the right slot.

### test_biquad_filter.cpp
Runs a quick low-pass vs high-pass duel to catch any rogue DSP math.

## File Descriptions

### main_t.cpp

Location: src/main_t.cpp

#### Purpose-built to verify all major subsystems individually:

LEDManager: one LED at a time, now including the new EF meters, control beacon and pot halos

ButtonManager: tests both the matrix-multiplexed buttons and the direct-wired control buttons

PotentiometerManager: sweeps the lone slot pot; filter knobs get read via ButtonManager

EnvelopeFollower: confirms dynamic envelope response

DisplayManager: shows static test data on all 3 lines

Run this and check it with your eyes. No automation. Human-in-the-loop sanity checks, every time.

Interaction: Step manually by hitting Enter in the serial monitor between stages.

### demo_button_ef_usb_midi.cpp

Location: test/demo_button_ef_usb_midi.cpp

This is the "show it to the synth club" sketch. It ditches the whole firmware stack and just wires a single control button (pin 12) and one envelope follower input (A0) straight into USB MIDI. Flash it when you want to prove the analog front-end works without hauling the full UI along.

Upload it like so:

```bash
pio run -d firmware -e teensy40_button_ef_demo -t upload
```

What you get once it boots:

* Serial spits a quick setup spiel while it samples a noise-floor baseline.
* Button presses blast middle C on channel 1.
* The envelope jack maps to MIDI CC 21 with a fast smoothing tail. Wiggle your source and watch MIDI Monitor light up.

Pro tip: keep the rig quiet for a hot second after reset so the baseline stays classy. After that, mash away.

### unified_t.cpp

Location: src/unified_t.cpp

#### This is the integration stress-test. All systems together, reacting to physical input. No waiting for user input via serial; it uses the actual button matrix for flow control. If something doesn't light up, react, or show data, you know exactly where to poke.

Used for field validation, QA benches, and righteous debugging rage.

Interaction: Uses real button presses (not keyboard input). Designed to be used with the assembled controller.

### biquadfilter_t.cpp

Location: src/biquadfilter_t.cpp

#### Tests the digital signal processing side of things. No LEDs. No buttons. Just math:

Verifies BiquadFilter's behavior for low-pass filters

Confirms correct coefficient updates and state handling

Useful for catching dumb mistakes in your DSP brain

Run this when your filter "sounds weird" and you're sure the hardware is fine.

### eeprom_persistence_t.cpp

Location: src/eeprom_persistence_t.cpp

#### Checks that configuration data survives a power cycle and that the backup EEPROM region can resurrect corrupted settings.

Expect to reboot the board a couple of times and watch the display for prompts. The sketch now hollers over both `Serial` and `Serial1`, so pick your poison. It's manual, messy, and exactly why this suite exists.

### verify_slots_t.cpp

Location: src/verify_slots_t.cpp

#### Blasts known values into every MIDISlot and slurps them back out to make sure EEPROM isn't lying to you.

Output scrolls by on Serial with PASS/FAIL verdicts. Trust, but verify.

## How to Build a Test

Each test is wired to its own PlatformIO environment in platformio.ini. The trick is to explicitly define which files you want to include. Here's an example for building `main_t.cpp`:

[env:teensy40_full_system]
extends = env:teensy40_base
build_src_filter =
    +<**/main_t.cpp>
    +<**/ButtonManager.cpp>
    +<**/ConfigManager.cpp>
    +<**/DisplayManager.cpp>
    +<**/EnvelopeFollower.cpp>
    +<**/LEDManager.cpp>
    +<**/MIDIHandler.cpp>
    +<**/PotentiometerManager.cpp>
    +<**/Utility.cpp>
    +<include/**.h>
    -<**/firmware_main.cpp>

Flash it with:

```bash
pio run -e teensy40_full_system -t upload
```

That `teensy40_full_system` build shoves the whole circus onto the board so you can poke every subsystem live.

Swap in `unified_t.cpp`, `biquadfilter_t.cpp`, `eeprom_persistence_t.cpp`, or `verify_slots_t.cpp` depending on what you're shaking down today.

## Add Your Own Test

Got a new stunt that isn't in the roster? Spin up your own environment:

```ini
[env:your_new_test]
extends = env:teensy40_base
build_src_filter = +<**/your_new_test.cpp>
test_build_src = true
```

`build_src_filter` is your whitelist—only sources tagged with a `+` get invited to the party. Flip `test_build_src` to haul in everything under `src/` so Unity hammers the real firmware, not some cardboard cutout.

For a full-blown example, raid [platformio.ini](../platformio.ini) and riff off an existing `env:` block.

## Final Note

This isn't a test suite for a codebase. It's a test suite for a circuit. If you're not plugging in wires and getting your fingers zapped on that one cap you forgot was charged, you're doing it wrong or I did it wrong, building it for you. This repo is for makers, hackers, educators, and the electrically-inclined misfits who prefer flickering LEDs and buzzers over CI badges.

If you're here, you're one of us. Thank you for looking at a README this deep in the project. Let's test dirty.

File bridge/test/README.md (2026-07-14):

# MN42 Bridge Test Rig

~~Before you smash that keyboard, make sure you've knocked out the setup in the [bridge README](../README.md).~~ Node 24, deps installed, the whole prep talk.

```mermaid
flowchart LR
  Tests[npm test]
  Bridge((mn42_bridge))
  Mock[[Mock Serial]]
  Tests --> Bridge
  Bridge <-->|JSON| Mock
```

## Running the suite

This scrappy test pile lives under `npm test`.

```bash
npm test
```

Run it from inside `bridge/` and watch each script light up. It's the fastest way to prove the bridge still boots, screams OSC, and whines when the serial line ghosts it.

For tighter feedback loops, the package scripts are split by responsibility:

- `npm run test:cli` checks help output and missing-port handling.
- `npm run test:transport` checks serial-to-OSC, OSC/MIDI-to-serial, validation, and reconnect behavior.
- `npm run test:browser` checks the browser-driven bridge server, `/app/` serving, raw `/ws` transport, structured session API, and `/ws/events`.
- `npm run smoke` runs entrypoint smoke checks for both `mn42_bridge.js` and `mn42_bridge_server.js`.

### Command validation cage match

Need to make sure the bridge slams the door on garbage? `cmd_validation.test.js` hurls oversized JSON and off-the-rails slot/value pairs to confirm anything sketchy gets dropped before it can fry your rig.

## What's with the mocks?

The tests hijack modules so you don't need the real controller dangling off USB:

- `mock_serial.js` spins up `SerialPortMock` with a canned handshake and a few slot values. Use it when you want serial JSON to spill over into OSC without touching hardware.
- `mock_serial_close.js` fakes a flaky cable by dropping the port once and shouting whenever the bridge claws its way back. Perfect for verifying reconnect logic.
- `mock_jzz.js` muzzles the `jzz` MIDI driver so ALSA stays quiet and tests don't go spelunking for hardware.

## Rolling your own serial saga

Got a fresh nightmare to simulate? Wire up a new mock:

1. Write a module that replaces `serialport` with your custom class or `SerialPortMock` setup. Peek at the existing mocks for reference.
2. In your test, preload the mock with `node -r ./test/my_mock.js mn42_bridge.js ...` or `require()` it before booting the bridge.
3. Script the drama—spew fake JSON, drop connections, or count writes—and assert the bridge keeps its cool.

Keep it loud, keep it lean, and remember: real hardware is the enemy of deterministic CI.

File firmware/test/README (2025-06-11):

#MOARkNOBZ Firmware: Hardware Testing Suite

This project contains a set of low-level, unapologetically manual tests for the MOARkNOBZ firmware. 

These test files are not placed in the conventional /test folder, but directly in the src/ directory. Why? Because we want full control. PlatformIO's test runner is fine for blinking LEDs and clapping for your own test framework, but when you're pushing bytes over MIDI and debugging weird I2C flickers, you need direct access and clean compile filters.

##File Descriptions

###mainTEST.cpp

Location: src/mainTEST.cpp

####Purpose-built to verify all major subsystems individually:

LEDManager: one LED at a time, manually stepped

ButtonManager: tests both the matrix-multiplexed buttons and the direct-wired buttons

PotentiometerManager: reads all knobs, prints analog values

EnvelopeFollower: confirms dynamic envelope response

DisplayManager: shows static test data on all 3 lines

Run this and check it with your eyes. No automation. Human-in-the-loop sanity checks, every time.

Interaction: Step manually by hitting Enter in the serial monitor between stages.

###unified.cpp

Location: src/unified.cpp

####This is the integration stress-test. All systems together, reacting to physical input. No waiting for user input via serial; it uses the actual button matrix for flow control. If something doesn't light up, react, or show data, you know exactly where to poke.

Used for field validation, QA benches, and righteous debugging rage.

Interaction: Uses real button presses (not keyboard input). Designed to be used with the assembled controller.

###test_biquadfilter.cpp

Location: src/test_biquadfilter.cpp

####Tests the digital signal processing side of things. No LEDs. No buttons. Just math:

Verifies BiquadFilter's behavior for low-pass filters

Confirms correct coefficient updates and state handling

Useful for catching dumb mistakes in your DSP brain

Run this when your filter "sounds weird" and you're sure the hardware is fine.

##How to Build a Test

Each test is wired to its own PlatformIO environment in platformio.ini. The trick is to explicitly define which files you want to include. Here's an example for building mainTEST.cpp:

[env:teensy40_mainTEST]
extends = env:teensy40_base
build_src_filter =
    +<**/mainTEST.cpp>
    +<**/ButtonManager.cpp>
    +<**/ConfigManager.cpp>
    +<**/DisplayManager.cpp>
    +<**/EnvelopeFollower.cpp>
    +<**/LEDManager.cpp>
    +<**/MIDIHandler.cpp>
    +<**/PotentiometerManager.cpp>
    +<**/Utility.cpp>
    +<include/**.h>
    -<**/firmware_main.cpp>

Substitute mainTEST.cpp with unified.cpp or test_biquadfilter.cpp depending on what you're testing.

##Final Note

This isn't a test suite for a codebase. It's a test suite for a circuit. If you're not plugging in wires and getting your fingers zapped on that one cap you forgot was charged, you're doing it wrong. This repo is for makers, hackers, educators, and the electrically-inclined misfits who prefer flickering LEDs over CI badges.

If you're here, you're one of us. Let's test dirty.

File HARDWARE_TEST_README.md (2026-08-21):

# MOARkNOBS-42 Hardware-Test Readme

## What This Package Is

This package is a self-contained hardware-test bundle for the current MOARkNOBS-42 prototype.
It is intended to validate:

- prototype firmware bring-up
- OLED function at address `0x3C`
- button matrix and control buttons
- potentiometer scanning
- WS2812 LED behavior
- USB MIDI and board-side MIDI routing
- envelope follower behavior and baseline checks
- WebSerial telemetry and configurator behavior
- OSC/MIDI bridge connectivity

## What This Package Is Not

- not a public release package
- not a fabrication-ready manufacturing bundle
- not a claim that any Gerber archive or NC-drill outputs are verified
- not a signed desktop-installer package

Current package limitations are tracked in [docs/hardware-test/KnownIssues.md](docs/hardware-test/KnownIssues.md).

## Evidence Photo Trail

The package now includes a small photo trail for the hardware story. These photos are useful for orientation and
storytelling; the pass/fail evidence still comes from the bring-up checklist, serial logs, measurements, and dated bench
receipts.

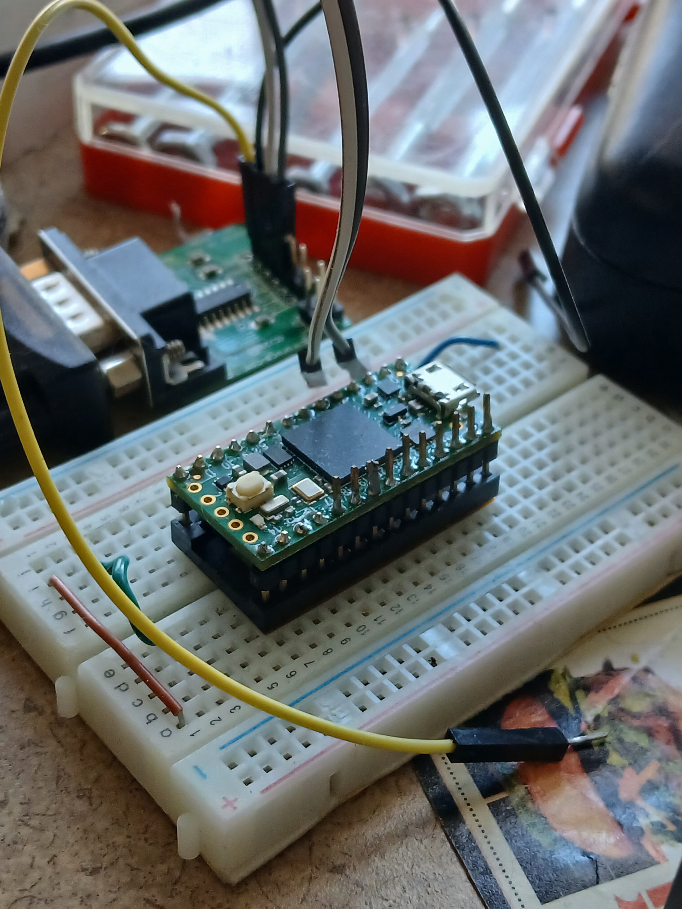
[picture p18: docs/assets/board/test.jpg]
Early Teensy breadboard harness used before the full MOARkNOBS-42 board became the main validation target.


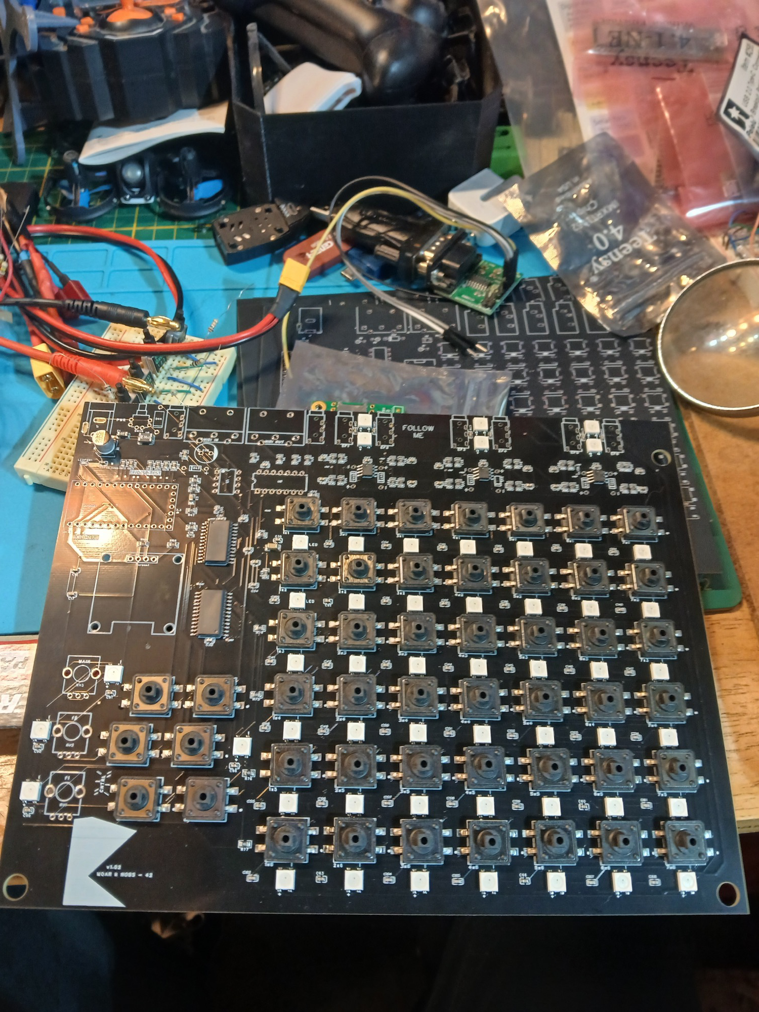
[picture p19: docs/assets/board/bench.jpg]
Assembled MOARkNOBS-42 prototype board on the bench with controls, LEDs, and support hardware visible.


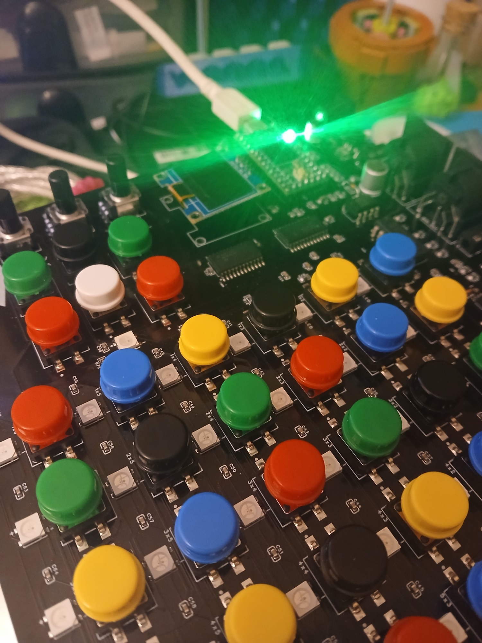
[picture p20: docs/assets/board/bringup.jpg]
Powered MOARkNOBS-42 prototype board during bring-up with button caps installed and status LEDs visible.


### Fabrication and inspection views

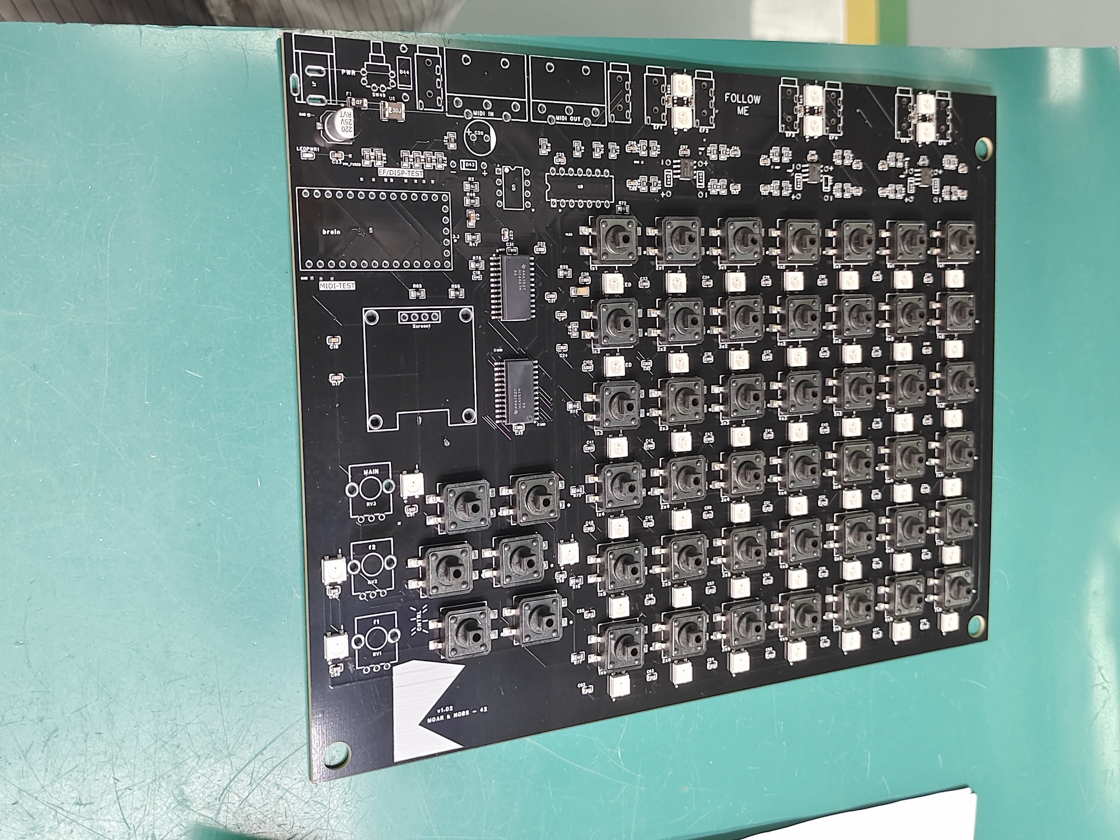
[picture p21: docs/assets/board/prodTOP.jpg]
Top side of the MOARkNOBS-42 prototype PCB from the current fabrication run.


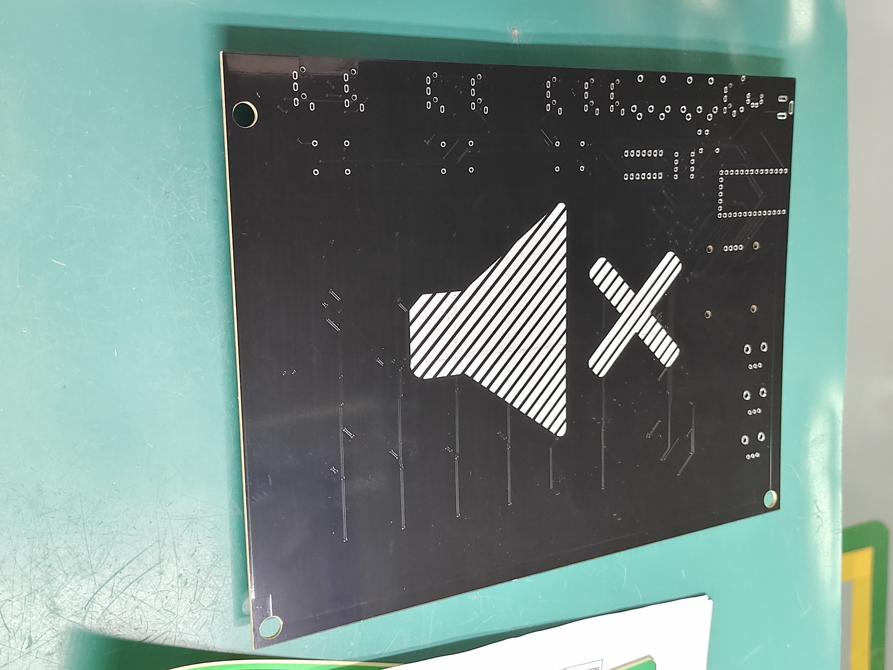
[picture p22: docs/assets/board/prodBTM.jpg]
Bottom side of the MOARkNOBS-42 prototype PCB from the current fabrication run.


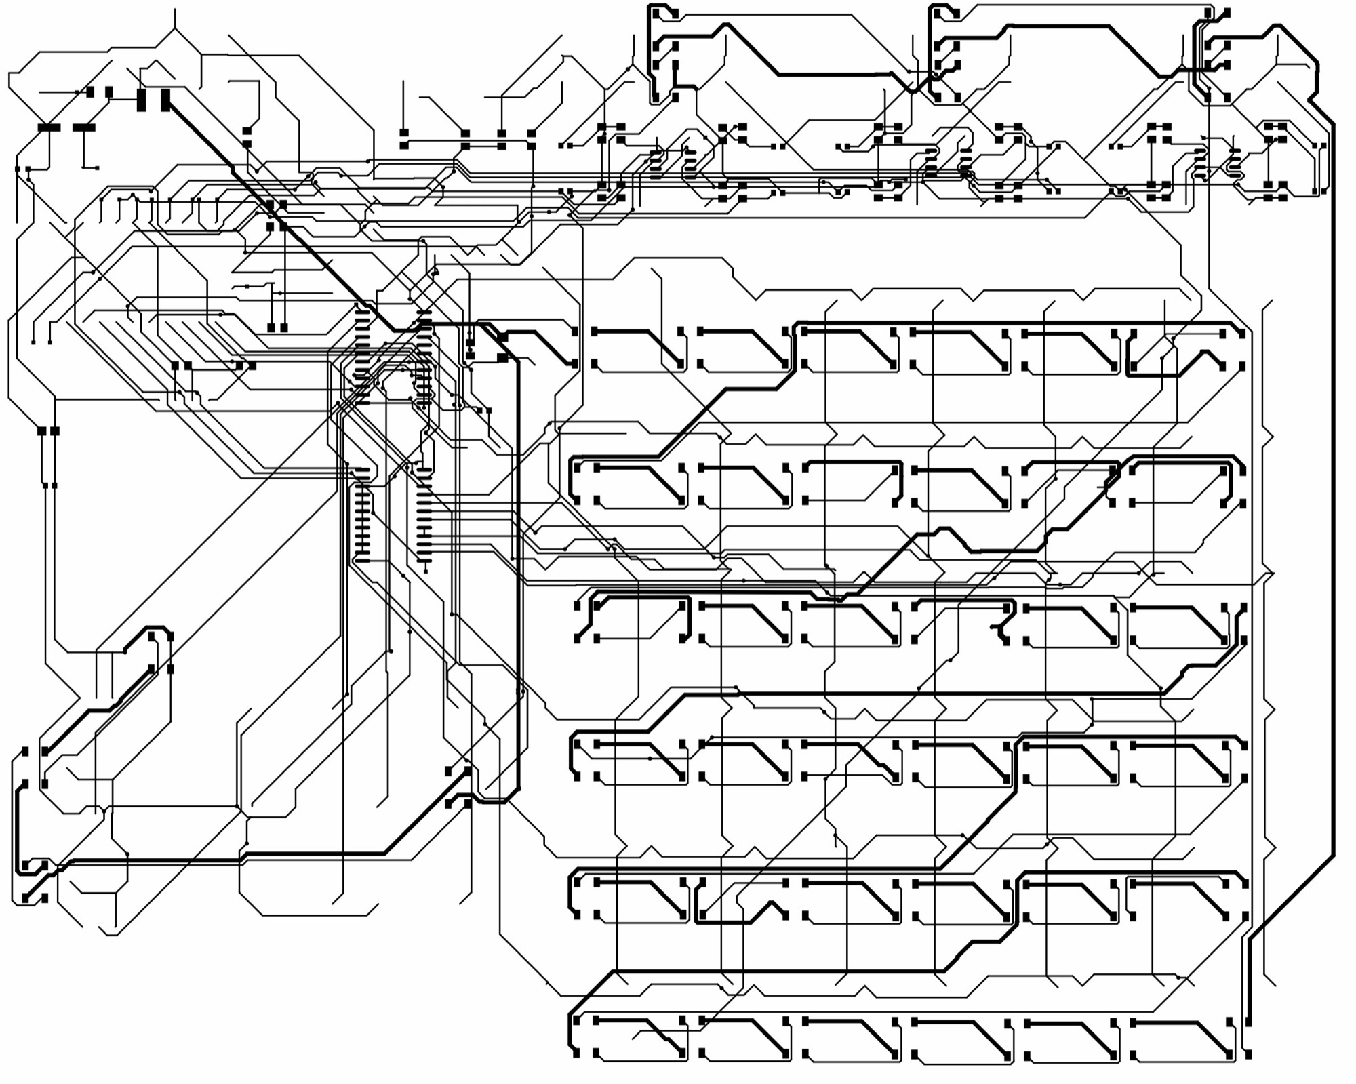
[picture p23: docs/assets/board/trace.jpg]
Close-up trace inspection photo from the MOARkNOBS-42 prototype PCB bring-up work.


## Current Review Snapshot

| Area | Current observation | Status | Next evidence needed |
| --- | --- | --- | --- |
| PCB fabrication quality | Boards arrived cleanly enough for probing, assembly review, and trace inspection; 0.5 mm test pads are usable. | Useful prototype run | Dated inspection notes and rail measurements |
| Power rails | Bring-up is in progress; current testing indicates an input-fuse routing problem. | Under review | Voltage, current, and thermal receipt after power-path correction |
| OLED/display | Dedicated hardware validation depends on the corrected power path. | Under review | Display bring-up pass/fail receipt |
| Controls and MIDI | The board is suitable for button, pot, DIN, and USB-MIDI validation. | Under review | Filmed control-scan and MIDI receipt |
| LEDs and reactive inputs | LED load and envelope-follower behavior still need bench evidence. | Under review | Load/current and EF baseline receipts |
| Fabrication readiness | No verified Gerber, NC-drill, or release BOM bundle is enclosed. | Not ready | Verified, revision-matched fabrication release bundle |

The canonical hardware status is [hardware/CurrentBuild.md](hardware/CurrentBuild.md). This table is an orientation
summary, not a substitute for dated measurements or bench receipts.

## Package Layout

- `firmware/` contains the real PlatformIO project and all kept firmware test lanes.
- `hardware/` contains the current schematic PDF, PCB/reference drawing PDFs, parts notes, and the fabrication boundary note.
- `App/` is included because WebSerial telemetry validation is part of this package.
- `bridge/` is included because bridge validation is part of this package.
- `docs/hardware-test/` contains the hardware-test operator docs.
- `tools/` contains the bench capture helpers, link checker, and source-export script.

## First Command

From a clean checkout, verify the documented firmware build:

```bash
pio run -d firmware -e teensy40_main
```

That is the package baseline. If this build fails, stop there and fix the toolchain before bench work.

## Setup

Install the Python-side requirements:

```bash
python3 -m pip install -r requirements.txt
```

Install the optional host-side validation dependencies when you need them:

```bash
npm --prefix bridge ci
npm --prefix App ci --no-audit --no-fund
```

## Supported Firmware Environments

- `teensy40_main`
- `teensy40_full_system`
- `teensy40_unified_test`
- `teensy40_biquad_test`
- `teensy40_eeprom_persistence`
- `teensy40_slot_verify`
- `teensy40_button_ef_demo`
- `teensy40_display_led_hw`
- `teensy40_power_burnin`
- `teensy40_unity`

See [docs/hardware-test/TestMatrix.md](docs/hardware-test/TestMatrix.md) for when to use each one.

## First-Boot Checklist

Run the first-boot procedure in [docs/hardware-test/Bringup.md](docs/hardware-test/Bringup.md).

The minimum bring-up sequence is:

1. Inspect power rails and soldering before first power.
2. Build and upload `teensy40_main`.
3. Confirm Teensy USB detection and serial output.
4. Run `teensy40_display_led_hw` to confirm the OLED path and LED path.
5. Run `teensy40_unified_test` for manual control, display, and EF checks.
6. Validate WebSerial with `App/`.
7. Validate bridge connectivity with `bridge/` plus `teensy40_full_system`.

## WebSerial Validation

Serve the configurator locally:

```bash
python3 -m http.server --directory App 8000
```

Then open `http://localhost:8000/`, connect to the board, and confirm:

- `HELLO` succeeds
- manifest/config load succeeds
- live telemetry updates while controls move

The App-specific reference is [App/README.md](App/README.md).

## Bridge Validation

Start the bridge:

```bash
npm --prefix bridge start
```

Then open `http://127.0.0.1:8787/` and confirm the bridge reaches the device after the
firmware sends its handshake. The bridge-specific reference is [bridge/README.md](bridge/README.md).

For the end-to-end lane, flash `teensy40_full_system` and run:

```bash
node firmware/system_test/mn42_fullstack_runner.js --serial /dev/ttyACM0 --report logs/system-test.json
```

Replace `/dev/ttyACM0` with the actual device path on your host.

## Source Package Export

To create a hardware-test source archive that excludes `node_modules`, `.pio`, `.platformio`,
`site`, `dist`, `logs`, `.DS_Store`, Playwright output, and temp files:

```bash
python3 tools/export_hardware_test_source.py --root . --label hardware-test --output dist/mn42_hardware_test.zip
```

The included and excluded surfaces for that archive are listed in
[docs/hardware-test/PackageManifest.md](docs/hardware-test/PackageManifest.md).

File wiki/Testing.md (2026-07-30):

# Testing

Testing is layered from fast firmware checks to full hardware + bridge exercises.
Canonical source: `docs/validation/TESTING.md`

If you are trying to recover tonight's instrument rather than validate a build,
start with [Troubleshooting by Symptom](Troubleshooting.md). The commands below
are contributor and bench-validation tools.

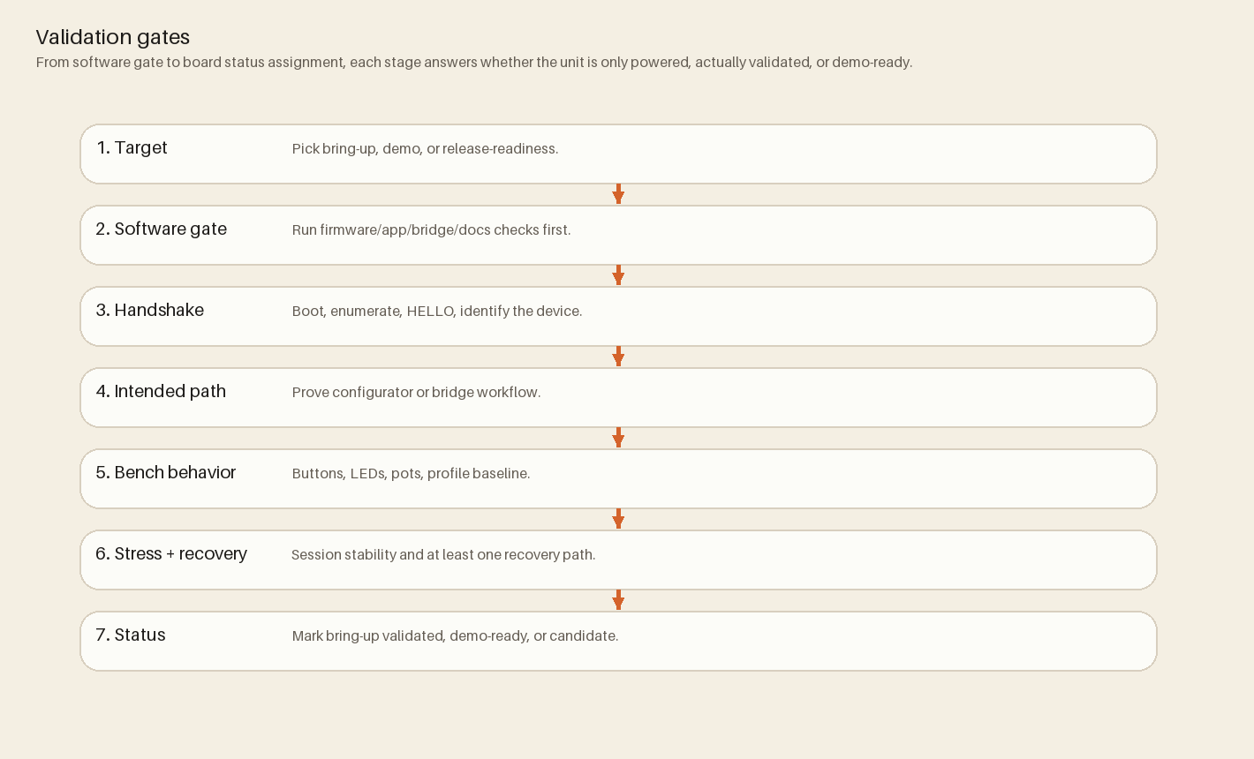
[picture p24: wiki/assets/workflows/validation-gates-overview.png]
Validation-gate diagram progressing from target selection and software checks through handshake, intended-path proof, bench behavior, stress and recovery, and final status.


## Canonical command set

Run from repo root unless noted.

1. Full orchestrated suite:
   ```bash
   ./test.sh
   ```
2. Unity firmware suite (strict command from repo contract):
   ```bash
   pio test -d firmware -e teensy40_unity -vvv
   ```
3. Firmware build sanity:
   ```bash
   pio run -d firmware -e teensy40_main
   ```
4. Bridge tests:
   ```bash
   npm --prefix bridge test
   ```
5. App tests:
   ```bash
   npm --prefix App test
   ```

## Unity test contract (important)

- PlatformIO project root is `firmware/`.
- Unity transport is custom only (`firmware/test/unity_output.cpp` using `Serial1`).
- Do not use PlatformIO's default serial Unity transport.
- Do not add `-DSerial=...` transport substitutions.
- Do not include `unittest_transport.h` from PlatformIO defaults.
- USB mode for tests is `USB_MIDI_SERIAL`.

## Manual firmware test environments

- `teensy40_full_system`
- `teensy40_unified_test`
- `teensy40_biquad_test`
- `teensy40_eeprom_persistence`
- `teensy40_slot_verify`

Build and upload with:

```bash
pio run -d firmware -e <env> -t upload
```

## Full-stack hardware runner

```bash
node firmware/system_test/mn42_fullstack_runner.js --serial /dev/ttyACM0 --report logs/system-test.json
```

## Reference docs

- `docs/validation/TESTING.md`
- `firmware/test/README.md`
- `firmware/system_test/README.md`

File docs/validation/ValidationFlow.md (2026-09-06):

# Validation Flow

> **Doc class:** Evidence doc. This page is the go/no-go flow for board, demo, and release-readiness validation.

Use this page when you need a repeatable answer to one question:

Is this board merely powered on, actually validated, demo-ready, or ready for a broader supported release?

This flow is conservative on purpose. If a step is not proven, mark it as unverified instead of assuming it is fine.

Current evidence/support boundary: [TESTING](TESTING.md), [Host Compatibility](../reference/HostCompatibility.md), [Documentation Truth Map](../reference/DocumentationTruthMap.md).

Validation gate diagram showing the sequence from target selection and software gate through handshake, intended path, bench behavior, stress and recovery, and final status assignment.

## 1. Pick the validation target

Choose one target before you start:

- `bring-up` for a newly assembled or newly received board
- `demo` for a rehearsal or public-facing prototype pass
- `release-readiness` for broader support or small-batch product claims
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

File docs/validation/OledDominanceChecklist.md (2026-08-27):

# OLED Dominance Checklist

This checklist validates that temporary overlays never hide modal editing state.

## Scope

Display ownership should resolve in this order:

1. startup animation
2. modal edit views (`on-device config`, `LFO tune`, `jitter tune`, `diagnostics`)
3. held-control contextual command palette
4. status overlays (when no modal view is active)
5. control overlays (`filter`, `arp`, `arp edit`, `note dynamics`)
6. screensaver
7. baseline context view
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

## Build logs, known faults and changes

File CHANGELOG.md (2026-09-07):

# Changelog

All notable changes to this project will be documented in this file.

The format is based on [Keep a Changelog](https://keepachangelog.com/en/1.0.0/),
and this project adheres to [Semantic Versioning](https://semver.org/spec/v2.0.0.html).

## [Unreleased]

### Fixed
- The final GitHub Release upload now selects the repository explicitly, allowing the checkout-free publication job to attach its already-built asset bundles.

## [v0.9.8] - 2026-08-25

### Added
- Frozen, deterministic browser App ZIPs now ship with the firmware, source, verification, provenance, checksum, and license artifacts.
- Release-tag preflight now requires an annotated semantic tag and a matching dated changelog entry.
- Added live hardware-in-the-loop receipts for firmware live-control lanes, including USB MIDI output, note dynamics, jitter, and clock round-trips with before/after configuration-state verification.
- Added selected-slot modulation visualizations and expanded Lab observation/evidence surfaces for Scope, MIDI Monitor, Device Monitor, Modulation Matrix, staged diff, slot inspection, and debug logging.
- Added integration coverage requiring simulator LFO routing, selected-slot telemetry, active-profile state, legacy-route shadowing, and Mod Matrix reporting to agree.
Added compact visual landmarks to major Lab rooms and tools while keeping text labels authoritative and telemetry surfaces icon-free.

### Changed
- GitHub prerelease creation and asset upload now run as one final gated publication job after every core and Bridge platform bundle succeeds.
- Bridge outputs are preserved as four platform-specific ZIPs so manifests, checksums, READMEs, and license files cannot overwrite one another during collection.
- Reworked the App around distinct Stage, Configure, and Lab operator roles rather than progressively denser versions of one editor.
- Reorganized Lab around Instrument, Profile, Observe, and Evidence workspaces.
- Split Lab Instrument controls into staged Machine configuration (Apply required) and immediate Live device controls (Writes now).
- Refined Configure around a selected-slot signal path that separates hand position, Reactive/EF/ARG behavior, fixed LFO motion, and resolved output.
- Refined Bridge surfaces around performer/session routing and live topology rather than duplicating configurator responsibilities.
- Changed fresh simulator startup to use neutral profile LFO routing instead of a seeded demonstration route.
- Changed simulator LFO resolution so telemetry and Mod Matrix reporting consume the same active-profile effective routing graph.
- Browser App publication now produces source-addressable immutable releases and stamps the originating repository SHA into the deployed surface.

### Fixed
- Packaged Bridge schema authority now includes the App tuning catalog and supports the named and async ES-module exports required by the staged runtime.
- Release publication no longer depends on a GitHub Release already existing when the tag-triggered workflow starts.
- Fixed simulator startup reporting a false Slot 6 LFO conflict caused by a hidden seeded profile route.
- Fixed simulator Mod Matrix routing being read from Profile A regardless of the currently active profile.
- Fixed disagreement between simulator telemetry and Mod Matrix reporting for profile SlotValue LFO routes.
- Fixed simulator compatibility semantics for legacy profile LFO routes so fixed per-slot lanes shadow older routes in the same way as firmware.
- The final GitHub Release upload now selects the repository explicitly, allowing the checkout-free publication job to attach its already-built asset bundles.

### Release Boundary
- The repository remains a hardware-test package, not a beta/public hardware release.
- Current software, simulator, App, Bridge, CI, and HIL tooling can prepare and record physical validation but do not substitute for it.
- rail_topology_verified remains false.
- Beta/public progression remains blocked on documented physical evidence including reworked-rail validation where applicable, soak testing, EF stability, EXT-clock starvation, panic-baseline validation, and the required fabrication/assembly artifacts.
- Further feature work is not evidence that these physical gates have passed.

## [v0.9.7] - 2026-08-25

### Added
- Device-owned Incoming MIDI routes with profile persistence, soft takeover, and musician-facing App configuration.
- Expanded Lab coverage for slot envelopes, LFOs, profile performance controls, and machine-level modulation routes.
- Root README now introduces MN42 as a complete instrument ecosystem and routes performers, builders, contributors, and evaluators to one landing page each.
- Documentation navigation now provides a five-page Learn syllabus and generated path breadcrumbs.
- The retained wiki source pack is explicitly archived in favor of canonical repository documentation.
- App and Bridge entry pages are now concise operational guides backed by focused behavior and operator references.

### Changed
- Reframed the App and Bridge around selected-slot behavior, profile performance, incoming control, and evidence-backed device authority.
- Hardware-test status and fabrication photos now live in `HARDWARE_TEST_README.md` instead of dominating the project landing page.
- Contribution guidance now front-loads the required readiness checklist and `tools/doctor.py --full` gate.

### Release Boundary
- Published as release `v0.9.7` from legacy lightweight tag `26_8` at `af1f1e7`; the tagged software state passed its core preflights, but the initial GitHub Release had no attached assets after the Bridge package smoke and release-upload ordering exposed last-mile defects.
- Treat this as a hardware-test/prerelease milestone and release-engineering rehearsal, not a signed beta/public distribution.

## [v0.9.6] - 2026-06-01

### Changed
- Hardened App and Bridge flows, refreshed OSC routing and the Bridge operator tour, and expanded verification/release automation across the `beta4..beta5` commit range.
- Published GitHub source tag `beta5` as release `v0.9.6`.

### Release Boundary
- The GitHub release has no attached binary assets or release notes. Treat it as a source snapshot, not an installer or HIL-verified artifact bundle; use repository manifests and checksums for any generated `dist/` set.

## [beta0.6.0] - 2026-04-20

### Added
- Firmware now exposes real device-backed profile save/load/reset flows plus EEPROM-backed macro snapshot and scene storage, with manifest capability reporting so the App can tell the truth about what the board supports.
- Added stronger storage/regression coverage in the firmware tests plus a destructive `--exercise-storage` lane in `firmware/system_test/mn42_fullstack_runner.js` for bench validation of profile/macro/scene persistence.
- Added `docs/reference/HostCompatibility.md` so browser, bridge, OSC, and DAW support claims are split into verified, documented, and not-claimed buckets instead of being implied from skim-level marketing language.
- WebSerial `GET_MANIFEST` now includes `device_name`, allowing host tools to identify the target rig explicitly instead of inferring identity from version/build data.
- App connect panel now shows a dedicated identity banner (`Connected to: <device> (FW <version>)`) and ships an inline "What to do if connect fails" helper.
- Added firmware panic-safe baseline combo (`Ctrl0 + Ctrl1 + Ctrl2`): stops arp, disables EF follow, and reloads the active profile.
- Added App demo presets `DEMO_A - Reactive Stack` and `DEMO_B - Clock Contrast` for show-ready profile switching.
- Added `docs/DemoPolish.md` runbook covering soak test flow, EXT-clock starvation checks, panic-path verification, and demo asset prep.
- Added Playwright test `App/tests/connection_banner.spec.js` to guard the new connection identity UX in CI.
- Added a persisted Basic/Advanced UI mode in the App (plus `ui_mode` Playwright coverage) so newcomers can stay on plain knob->MIDI mapping while power users keep EF/ARG/filter depth visible.
- Added a guided profile workflow in the App (target slot -> switch/load -> apply -> save), profile import/export staging cues, and tighter profile toolbar behavior around connect/disconnect state.
- Added glossary-style help badges and layman labels across slot editing + schema-rendered forms so EF/ARG/filter/SysEx terms are explained inline instead of buried in docs.
- Added bridge usability docs for every audience level: full operator runbook (`bridge/README.md`), quickstart (`docs/OSCBridge.md`), performer one-pager (`docs/BridgeForPerformers.md`), and packaging plan (`docs/BridgePackaging.md`).
- Added release-prep tooling for bridge packaging: `bridge/scripts/smoke_bridge_cli.js`, `bridge/scripts/package_bridge.sh`, and npm scripts (`smoke`, `package:bridge`, `release:prep`) plus a per-release artifact checklist (`docs/release/bridge-artifacts-checklist.md`).
- Playwright simulator rig bolts into CI and `test.sh`, so you can hammer the
  App’s UI without cracking open the firmware—kick it off locally with
  `npm --prefix App test` when you want browser-level truth before wiring up
  the hardware. The suite now rewrites the manifest mid-run to trigger the
  migration dialog, rehearses rollback, and proves a clean apply clears the diff
  badge.
- Hardware-in-the-loop system runner (`firmware/system_test/mn42_fullstack_runner.js`)
  now ships as a first-class script: it spawns the bridge, drives the OSC slot
  patch scenarios called out in the docs, and emits JSON + text logs ready for
  CI artifacts or late-night lab notes.
- Slot ownership got formalized: each slot now names its owning manager and
  persistence block, with the EEPROM serializer carving out explicit 64-byte
  pages so firmware, WebSerial, and Unity tests stop stepping on each other's
  toes when they rebuild schema drafts.
- Slot configs now stash 16-byte SysEx templates with `XX`/`MSB`/`LSB` placeholders, and the WebSerial editor lets you script
  those bursts without cracking open the firmware.
- Per-slot envelope follower settings (filter type, cutoff, Q) live alongside each MIDISlot and persist to EEPROM, bumping the
  schema to `0x0004` so stored patches remember their curves.
- Dual LFO engines now live in `firmware_main.cpp` via `LFOManager`, routing LED brightness, arp swing, and EF gain trim while persisting shapes/routes inside the profile payload so both UART telemetry and WebSerial keep the same modulation state. Unity LFO tests guard the shapes and clock sync math. [2fe3c15]
- The Web Configurator was rebuilt around a split runtime kernel and BenzKnobz view layer: schema-driven forms, staged diff/rollback controls, telemetry cards, a MIDI monitor, and a simulator toggle all live in `runtime.js`/`views/*` plus new Playwright specs that exercise every panel without a human in Chromium. [2fe3c15]
- Serial commands now route through a sorted dispatch table with standalone handler functions, an exposed `dispatchCommand` for Unity, and an "unknown command" log that also prints the available verbs; new Unity tests hit both a known and unknown command so the glue layer stays covered. [unreleased mainline]
- Added `test/test_protocol_dispatch.cpp` and the `firmware/python` shim that makes `python -c ...` resolve to `python3`, keeping the Unity runner happy in environments without a bare `python`. [unreleased mainline]
- Macro snapshot controls now expose `SAVE_MACRO_SLOT`/`RECALL_MACRO_SLOT` to the WebSerial UI with inline feedback, disabled save during writes, and optional config reloads after recall so the browser mirrors slot 254 without touching live profiles.
- Introduced LED animation modes (`Static`, `PeakHold`, `Trail`, `ClockPulse`) plus a scheduler-driven `LedAnimator`, diagnostics override, and RPC hooks so pots/envelopes can emit dynamic feedback safely outside interrupt context.
- Scene slot support now ships with named EEPROM-backed saves, `SAVE_SCENE`/`RECALL_SCENE`/`GET_SCENES` verbs, and browser controls that sync scene availability from firmware instead of pretending storage exists.

### Changed
- App/firmware/bridge seams were closed around real production commands instead of simulator-era assumptions: configurator transport now adapts cleanly onto native firmware verbs, bridge host control uses `SET_SLOT_VALUE`, and operator docs were updated to the same contract.
- Browser-only slot notes (`label`, MIDI badge, `Take Control`) now stay strictly browser-local: they no longer travel as device truth, the simulator no longer advertises them as firmware-backed config, and reconnects preserve local notes instead of rehydrating stale defaults from `get_config`.
- Docs now read with a clearer pre-production support boundary: landing pages, connectivity docs, bridge docs, and the repo health audit call out validated host surfaces early, and MkDocs strict build is kept green with the current nav/link structure.
- Connection UI now separates transport state (`Connected`, `Handshaking`, `Disconnected`) from identity details, with device/firmware info moved to the dedicated banner.
- OLED copy pass improves live readability: expanded arp shape names (`Up-Down`, `Random`, `Euclid`), less-abbreviated EF/filter labels, and explicit swing feedback (`Swing: n%`).
- Device Monitor now includes a dedicated `Device` field sourced from manifest identity.
- Bridge and docs indexes now cross-link quickstart/performer/packaging/release-checklist flows, and bridge examples were corrected to the current default OSC ports (`9000` send/listen) so docs match the live bridge behavior.
- `.gitignore` now excludes local hardware CAD project/autosave artifacts (`*.epro`, `*.eprj`, autosave patterns, and `hardware/*_backup/`) so board iteration files can stay local-only while firmware/app/docs ship cleanly.
- Runtime simulator and staged-state handling were tightened for profile/testing flows (`set_param` support, staged/live dirty reconciliation), and profile save now auto-applies dirty staged edits before firmware snapshot commands.
- Added a focused explainability pass across recent architecture hotspots (`App/runtime.js`, `App/views/benzknobz.js`, `App/views/form_renderer.js`, `firmware/src/{Runtime,Scheduler,Protocol,ConfigManager,CommandQueue}.cpp`, `firmware/src/modes/Modes.cpp`) so post-2025 additions read like maintainable design notes instead of archaeology.
- Commit summary (v1.0 prep sweep): newcomer-friendly App UX + profile workflow hardening + bridge usability docs + packaging/release scaffolding + targeted code explainability comments.
- Runtime now runs a normalization/sanitization lap that clamps slot payloads
  before validation/apply, so the control surface stops seeing ghost values
  when the `runtime` bridge chews on sketchy input.
- Firmware source files now carry teaching-forward comment blocks explaining
  data flow, pointer ownership, and math choices so workshops can read the code
  like a zine instead of a riddle.
- The November comment pass now ships with subject headers—boot choreography,
  input scanning, persistence hygiene, and signal-flow math—so instructors can
  stitch the annotated files into lesson plans without reverse engineering the
  comment trail.
- Root and firmware READMEs map the control stack with new "crash course" and
  "stack philosophy" sections, pointing students toward the annotated modules
  and the docs they feed.
- Testing docs call their shot: `docs/validation/TESTING.md` now walks through the
  full-stack runner flags so contributors can actually reproduce the OSC↔firmware
  handshake the release notes keep hyping.
- Added an "Annotated Source Field Guide" and guided-tour curriculum so mentors
  know exactly which `.cpp` to open when explaining globals, mux math, or MIDI
  queueing.

### Fixed
- Browser-local slot metadata now survives reconnect/profile-refresh paths correctly instead of getting overwritten by live `get_config` payloads during hydrate/replace flows.
- MkDocs strict docs build now passes with the host-compatibility page in nav and the formerly off-nav audit/interop pages explicitly labeled as archive/reference material.
- Connect-failure path now reveals actionable recovery guidance directly in-app instead of leaving users at a dead-end error state.
- Corrected demo-facing OLED abbreviations that were too terse for live explanation of EF/arp/swing states.
- Corrected stale bridge/example docs that still referenced old OSC defaults and legacy bridge verbs; documentation now reflects the current `/mn42/cmd` contract and `--osc/--osc-listen` defaults.
- Status/diff badges finally clock the `hidden` flag and swap styles instead of
  pretending they’re always visible—badge CSS tweaks landed in the App so the
  UI doesn’t gaslight folks skimming change reports.
- Bulk CC dumps finally stash channels under `EEPROM_POT_CHANNELS` and park CC numbers under `EEPROM_POT_CC`, so `Utility::processBulkUpdate`
  lines up with the documented EEPROM map instead of gaslighting ConfigManager.
- Incoming SysEx packets longer than 64 bytes now get dropped at the door unless you explicitly forward them, keeping rogue gear
  from hogging RAM.

## [0.2.0] - 2025-10-31

### Added
- Demo USB MIDI sketch under `firmware/test/demo_button_ef_usb_midi.cpp` shows a control button punching out note-on/off while the envelope follower breathes CC data back to the host DAW.
- Unity test docs flag the new demo so folks know where to start when sniffing the USB transport without spelunking the test harness.
- Diagnostic mode boots with self-test pages and a compact matrix view so field checks stop feeling like guesswork.
- Boot banner now decodes reset causes and spits a system report before the synth even clears its throat.
- Release pipeline and a pre-commit lint job keep CI honest and reproducible.
- Filter tuning pots let you twist the analog guts without reaching for a screwdriver mid-jam.
- Arpeggiator learned to wiggle on its own—Perlin noise jitters included.
- WebSerial telemetry spews live state into the browser, because the best debugging tools are the ones you already have open.
- NRPN/RPN/SysEx support unlocks MIDI’s weird alleys instead of sticking to vanilla CCs.
- Start tracking changes with this log so the paper trail matches the noise we’re making.
- Pin map and EEPROM layout docs locked down for builders who like schematics with their solder fumes.
- SparkFun reference sidebars point straight to the solder-stained source material.
- Web configurator now drives all slot parameters (EF, ARG, LED colour, full MIDI types) and falls back to a bundled schema when the device won’t deliver one.
- `docs/HISTORY.md` now carries a “how to read this thing” primer so future builders can trace the arc without spelunking the git log first.
- Added a September status rollup capturing the post-`v0.1.0` cleanup sprint and what we’re staging for the next hardware spin.
- Dropped breadcrumbs to the bridge scripts so folks can sling telemetry without reverse engineering the tooling.

### Changed
- Bridge rides Node 20 and clang-format marches in lockstep with CI.
- README now calls out firmware build steps and links the new docs.
- HISTORY timeline is chunked by focus blocks instead of loose commit lists—more story, less archeology.
- ConfigManager now coughs up the MIDI channel map it stashes in EEPROM so fresh boots inherit the saved routing without extra glue code.
- PotentiometerManager and Globals keep their EEPROM offsets honest, carving out extra JSON buffer slack so oversized hardware presets don’t brick the load.
- Unity system report test pipes its output through `PrintTarget` and `Serial1`, matching the custom transport instead of whispering into the void.
- OctoWS2811 DMA driver is back under `firmware/lib/OctoWS2811/` so Teensy 4 builds keep upstream timing guarantees even when we compile offline.

### Removed
- OctoWS2811 vendored library; FastLED handles the LEDs solo now. *(Undone by the October 2025 DMA revival noted above.)*
- Blocked the Teensy core’s OctoWS2811 copy via `lib_ignore` to keep builds clean.

### Fixed
- Pot channel persistence handoff won’t drop stored assignments when ConfigManager rebuilds the control surface on boot.
- Bumping the EEPROM schema to `0x0003` wipes and realigns the slot arena before wider SysEx-ready structs load, so upgrades stop trampling profile blocks.

## [0.1.0] - 2025-08-06
### Added
- First public release of MOARkNOBS-42.

[0.2.0]: https://github.com/bseverns/MOARkNOBS-42/releases/tag/v0.2.0
[0.1.0]: https://github.com/bseverns/MOARkNOBS-42/releases/tag/v0.1.0
[v0.9.6]: https://github.com/bseverns/MOARkNOBS-42/releases/tag/beta5
[v0.9.7]: https://github.com/bseverns/MOARkNOBS-42/releases/tag/26_8
[v0.9.8]: https://github.com/bseverns/MOARkNOBS-42/releases/tag/v0.9.8
[beta0.6.0]: https://github.com/bseverns/MOARkNOBS-42/releases/tag/beta0.6.0
[Unreleased]: https://github.com/bseverns/MOARkNOBS-42/compare/v0.9.8...HEAD

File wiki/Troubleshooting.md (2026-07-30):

# Troubleshooting

Start with the symptom you can observe. Do not diagnose the repository
architecture first.
Canonical source: `docs/validation/FailureFirst.md`

## Connect did nothing

1. Confirm the cable carries data.
2. Close other serial terminals, Bridge instances, and browser tabs that may
   own the port.
3. Use a Chromium-based browser for direct WebSerial.
4. Serve/open the configurator from an allowed secure context.
5. Reconnect USB, reload the page, and choose the Teensy device again.

If the Teensy never enumerates, move to the physical checks in
`docs/validation/Troubleshooting.md`.

## Apply outcome uncertain

1. Stop applying or discarding drafts.
2. Keep the instrument connected.
3. Wait for authoritative readback/resynchronization.
4. If readback reports **Device differs**, treat the shown live state as device
   truth and the staged state as an unapplied draft.
5. Export the staged draft before reconnecting if it matters.

An uncertain result does not prove that firmware rolled back.

## Apply rejected before transmission

- Validation failure: correct the staged fields.
- Stale session revision: refresh the Bridge session and retry.
- Apply already in progress: wait for the active transaction to finish.
- Device not ready: restore a ready connection before retrying.

Device authority remains verified because this attempt did not reach the serial
Apply writer.

## Bridge cannot find the serial port

1. Disconnect direct WebSerial and close serial terminals.
2. Refresh detected ports in the Bridge console.
3. Select or type the actual Teensy serial path.
4. Start the Bridge and wait for **Serial** and **Device** to become ready.
5. If the port appeared after the DAW opened, restart the DAW after Bridge MIDI
   is available.

## MIDI is not reaching the DAW

1. Confirm the slot value moves in the configurator or Bridge telemetry.
2. Confirm the Bridge is running if the DAW expects `MN42 Bridge`.
3. Enable the correct MIDI input and channel on the receiving track.
4. Use a MIDI monitor to confirm the expected CC/note leaves the instrument.
5. Verify the destination parameter is actually MIDI-learned or mapped.

The current repository documents DAW routing but does not claim universal
DAW-by-DAW verification.

## OSC host receives nothing

1. Confirm Bridge send host/port matches the OSC listener.
2. Confirm the listener binds the intended interface.
3. Watch `/mn42/slots` or `/mn42/envelopes`.
4. Verify local firewall rules and avoid using the same UDP port for an
   incompatible listener.

## Envelope follower does not react

1. Confirm the source is connected to the intended EF input.
2. Watch envelope telemetry before changing mappings.
3. Reduce to one follower with `LINEAR` or `LOWPASS`.
4. Disable ARG temporarily.
5. Confirm the target slot is active and the receiving synth/DAW is mapped.

## Connection was lost

1. Stop moving controls until the link returns.
2. Reconnect through the same transport you started with.
3. Let device truth hydrate before editing.
4. Confirm whether a staged draft remains dirty.
5. Use `Ctrl0 + Ctrl1 + Ctrl2` if the performance state itself needs a known
   baseline.

## Deeper references

- `docs/validation/FailureFirst.md`
- `docs/validation/Troubleshooting.md`
- `docs/reference/ConfigurationTransactionModel.md`
- `docs/guides/BridgeForPerformers.md`
- [First Playable Walkthrough](Playable-Walkthrough.md)

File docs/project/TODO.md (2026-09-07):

# Demo-First TODO (MOARkNOBS-42)

This file is **demo-first**: everything above “Post-demo Mischief” exists to make the demo feel calm,
inevitable, and repeatable.

Target demo outcomes:

- WebSerial editor app
- EF / Arp / ARG
- Basic clock following
- Profiles

If a feature already exists in firmware, it still gets a checkbox here as **VERIFY**. Demo risk is not
“does code exist,” it’s “will it behave on demand.”

Last edited: 2026-09-07

---

## Recent implementation snapshot (2026-02-14)

- [ ] Remaining work is hardware/demo verification (soak, EXT clock starvation check, panic-path validation on real rig, and asset prep).

---

## Public README Photo Backlog

- [x] Assembled front panel with knobs, buttons, OLED, and LEDs installed.
- [x] Bench setup during first-power and rail-topology validation.
- [x] MIDI, USB, and WebSerial/bridge test session with the board connected.
- [ ] Required rework close-up, or a clear "no rework required" board close-up after validation.

---

## 0) The 10-minute demo (run-of-show)

1. Plug in MN42 → open WebSerial editor → Connect
2. Show identity + active profile + staged diff panel
3. Make one tiny edit → Apply → confirm change on device and/or MIDI monitor
4. EF: show reactive envelope + gate stability when quiet
5. Arp: enable → change shape → change swing
6. Clock follow: show EXT vs INT + Start/Stop behavior (basic)
7. Profiles: load Profile B → obvious behavior change → save + reload proof
8. Close: “This is a workshop-friendly instrument: fast remaps, profiles, and modulation brains.”

---

## 1) Demo Blockers (must be true Monday)

### 1.1 WebSerial Editor: connect → edit → apply → rollback

- [x] **VERIFY:** WebSerial Connect succeeds on first try (no mystery steps)
  - Acceptance: user sees a clear “Connected to MOARkNOBS-42” state within 10s.
- [x] **VERIFY:** Device identity is visible in the app
  - Acceptance: FW version + device name + active profile index/name shown somewhere obvious.
- [x] **VERIFY:** Config loads from device into UI correctly
  - Acceptance: active profile + slot grid/state matches what the device shows.
- [x] **VERIFY:** Staged diff is visible and trustworthy
  - Acceptance: UI clearly shows “dirty” changes vs device state (no silent edits).
- [x] **VERIFY:** Apply writes changes and device acknowledges success
  - Acceptance: one edited field changes behavior immediately; no power-cycle required.
- [x] **VERIFY:** Rollback / cancel staged changes restores the pre-edit state
  - Acceptance: you can safely “undo” before applying; device remains unchanged.

**One “hero edit” we will demo (pick exactly one):**

- [x] Change a slot’s Type (CC/Note/NRPN/etc)
- [x] Change a slot’s CC number or channel
- [x] Change an EF parameter (mode/gate/attack/release) and see effect

---

### 1.2 EF demo: “it moves, and it doesn’t jitter”

- [ ] **VERIFY:** EF reacts clearly to a real input source (phone audio, pedal send, DAW loop)
  - Acceptance: visible movement on OLED/LED and/or MIDI monitor.
- [ ] **VERIFY:** EF gate/noise floor prevents jitter when silent
  - Acceptance: with no input, EF output settles to near-zero and does not spam.
- [ ] **VERIFY:** EF calibration path is available if baseline drifts
  - Acceptance: you can trigger recalibration (on-device combo OR WebSerial action) in < 10 seconds.
- [ ] **VERIFY:** EF diagnostic view is legible (baseline/gain/value)
  - Acceptance: during demo you can point at a page and explain what’s happening.

**EF “one sentence explanation” (write it now):**

- [x] “EF turns incoming audio amplitude into stable MIDI modulation with gating and calibration.”

---

### 1.3 Arp demo: “it feels alive, and it follows the rig”

- [x] **VERIFY:** Arp enable/disable is reliable and obvious
  - Acceptance: no stuck notes; OLED/LED indicates arp state.
- [x] **VERIFY:** Pattern shapes are selectable and audibly/visibly distinct
  - Acceptance: you can switch shape live and the pattern changes immediately.
- [x] **VERIFY:** Swing is controllable and demonstrable
  - Acceptance: show 50% vs a swung preset (e.g. 58–65%) and feel changes.
- [x] **VERIFY:** Arp behaves when clock source changes (INT ↔ EXT)
  - Acceptance: no runaway timing or lockups.

**Arp “one sentence explanation” (write it now):**

- [x] “Arp is a pattern brain with swing that can run internally or lock to external clock.”

---

### 1.4 ARG demo: “two envelopes in, one modulation out”

**Definition (what ARG is):**  
ARG = **Advanced Relative Gain**. It turns an EF into a **two-input modulation blender**: pick an envelope
pair (A,B) from the six EF inputs, then combine/compare them using **14 math methods**
(`A+B`, `A/B`, `max(A,B)`, `A^B`, etc.). The result becomes the slot’s modulation value.

**On-device controls (must be demo-reliable):**

- **Prereq:** active slot already has an **EF assigned**
- **Enter ARG:** `Ctrl0 + Ctrl1` (with EF enabled on that slot)
- **Cycle ARG method:** press `Ctrl0 + Ctrl1` again (cycles through 14 methods)
- **Cycle envelope pair (A,B):** `Ctrl2 + Ctrl5` (walks all unique pair combos from the 6 EF inputs)
- OLED should show method + pairing (e.g. `EF 1: A3/B0`) when changed

**WebSerial hooks (nice, but demo can succeed without them):**

- `SET_ARGMETHOD <0-13>` / `GET_ARGMETHOD`
- Status payload includes: `argEnabled`, `argMethod`, `argPair`

#### Demo acceptance checks

- [ ] **VERIFY:** ARG can be entered and exited without breaking EF or Arp
  - Acceptance: enable EF → enter ARG → bail out and return to normal EF behavior.
- [ ] **VERIFY:** Method cycling is obvious
  - Acceptance: switching methods produces clearly different output (not “subtle maybe?”).
- [ ] **VERIFY:** Pair cycling is obvious
  - Acceptance: you can point at the OLED and say “this is input A vs input B,” and behavior changes when you switch pairs.
- [ ] **VERIFY:** ARG output is visible somewhere
  - Acceptance: either (a) MIDI CC stream in a monitor changes, or (b) OLED/LED diagnostics show the value moving.

#### The 30-second ARG demo script (recommended)

1. Assign EF to the active slot (show EF moving)
2. Enter ARG (`Ctrl0+Ctrl1`)
3. Pick a “high contrast” method:
   - `MAXX` (louder wins), `XABS` (difference), or `XORR` (obvious glitch)
4. Pick a pair you can describe in words (e.g. “kick vs pad”, “mic vs noise”)
5. Point to the output and say:
   - “ARG compares two envelopes and turns that relationship into modulation.”

#### Fallback plan (if ARG gets weird live)

- If pairing feels confusing → lock to `AVG` or `MAXX` and stop touching pairs
- If output is too subtle → switch to `XORR` (always obvious) or `DIVI` (dramatic)
- If anything fights clock/arp → demo EF + arp and mention ARG briefly as “deeper demo later”

---

### 1.5 Clock following: basic, not heroic

- [x] **VERIFY:** External MIDI clock can be followed (choose one path: USB OR DIN)
  - Acceptance: bpm follows DAW clock; timing doesn’t visibly drift during demo window.
- [x] **VERIFY:** Start/Stop works (Continue optional)
  - Acceptance: Start resets pattern coherently; Stop halts without stuck notes.
- [x] **VERIFY:** Clock status is visible somewhere (diagnostic page OK)
  - Acceptance: you can point and say “INT / EXT / LOST”.

**Clock “one sentence explanation” (write it now):**

- [x] “MN42 can follow external clock so it stays in time with the session.”

---

### 1.6 Profiles: prove persistence

- [x] **VERIFY:** Load Profile A vs Profile B shows an obvious difference
  - Acceptance: a mapping or behavior changes immediately and visibly.
- [x] **VERIFY:** Save profile works (from device or app, whichever is canonical)
  - Acceptance: after save + power cycle (or reload), the change persists.
- [x] **VERIFY:** Profile identity is visible (index/name)
  - Acceptance: you can say “Profile 2 is the Bridge demo layout” and it’s shown.

**Profiles “one sentence explanation” (write it now):**

- [x] “Profiles let us swap whole controller behaviors instantly for different classes or rigs.”

---

## 2) Demo Polish (strongly recommended)

### 2.1 UX clarity

- [x] Add/verify a simple “Connected to: MOARkNOBS-42 (FW x.y)” banner in WebSerial UI
- [x] Add/verify a “What to do if connect fails” helper (close other serial clients, replug, refresh)
- [x] Ensure OLED labels for EF mode / arp shape / swing are readable and not abbreviated weirdly

### 2.2 Reliability / performance

- [ ] Verify 5-minute soak test: no UI lockups, no serial stalls, no stuck notes
- [ ] Verify LED/OLED updates don’t starve MIDI/clock handling (esp. with EXT clock)
- [ ] Verify “panic exit” path: one combo that returns to safe baseline state
  - Implemented combo: `Ctrl0 + Ctrl1 + Ctrl2` now does panic-safe reset (stop arp, disable EF follow, reload active profile baseline).

### 2.3 Demo assets

- [x] Prepare one short audio loop for EF input (phone file OR DAW loop)
- [x] Prepare one DAW project (or MIDI clock source) for clock follow
- [x] Prepare two named profiles: `DEMO_A`, `DEMO_B` (or a clear index story)

---

## 3) Demo Rehearsal Checklist (night before / morning of)

- [ ] Run the full run-of-show once without stopping
- [ ] Time it (target 8–12 minutes)
- [ ] Confirm cable kit: USB, any DIN adapters, audio feed cable, phone dongle if needed
- [ ] Confirm fallback plan:
  - If clock follow is flaky → run INT clock and explain EXT support briefly
  - If ARG is risky → keep ARG minimal (one method, one pair) or skip and mention it
  - If WebSerial is flaky → use on-device edits + show WebSerial briefly as “next”

---

## 4) Post-demo Mischief (true wishlist)

### Hardware / Mechanical (belongs in your hardware repo; keep pointers here if you want)

- [ ] Optional breakout board for expansion (I²C/SPI/GPIO + “safe/risky” silk)
- [ ] USB-C connector (device-only) + mechanical/case alignment + bootloader access

### EF experiments (beyond what exists today)

- [ ] Add additional filter responses (notch/tilt/peaking) if worth the complexity
- [ ] Multi-band / band-split EF (experimental mode)
- [ ] EF visualization polish: gate threshold marker + peak hold + dedicated EF “glance” page

### Arp / pattern brain upgrades

- [ ] Custom pattern shape (editable step array)
- [ ] Grid-based pattern edit mode (7×6 step editor)
- [ ] Arp diagnostics page: step index + length + clock source + mini timeline

### MIDI weird alleys

- [ ] Polyphonic Aftertouch (0xA0)
- [ ] Lightweight MPE fan-out slot type
- [ ] Extra MIDI utilities: Song Select, MMC shims, routing/filter toggles

### Simulator truth

- [x] Split the two simulator purposes into explicit entry states.
  - **Start Simulator** boots a firmware-canonical reset: Profile A active, pot slots on channel 1 with CC 0,
    and the firmware-default EF payloads. It must contain no illustrative mappings, ARG examples, or LFO routes.
  - **Load Demo Rig** applies the deliberately illustrative mapping, EF/ARG, and LFO-route fixture used for
    demonstrations and screenshots.
  - Acceptance: simulator tests, UI labels, and screenshots name the selected fixture; a default simulator session
    can be compared directly with the firmware reset path without mistaking demo state for untouched instrument truth.

### On-device “Config Mode”

- [x] Shallow OLED config menu for per-slot edits (type/channel/CC) + autosave on exit
  - Combo: `Ctrl0 + Ctrl2 + Ctrl3 + Ctrl5`
  - Controls in mode: `Ctrl0/1` slot prev/next, `Ctrl2` type, `Ctrl3` channel, `Ctrl4` data1/CC, `Ctrl5` exit+save

### Docs / tests / meta

- [ ] Update screenshots once hardware returns so the docs match the UI
- [ ] Extend tests as new features land (Poly AT, custom patterns, MPE)
- [ ] Keep this file honest: prune quarterly, archive dead ideas

### Hardware

- [x] Properly feed both the logic and LED circuits from input

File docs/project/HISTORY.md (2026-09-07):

# Project History

> **Doc class:** Historical narrative. This page is not the source of current contract, support, release, or test truth. When this page disagrees with current README, reference, validation, or release pages, the current contract and evidence pages win. See [Documentation Truth Map](../reference/DocumentationTruthMap.md).

This file tells the development story of MOARkNOBS-42: why the repo sprawled, when the hardware got serious, and how the project turned from a pile of firmware experiments into a documented hardware-test package. It is based on commit history with a few first-person design notes left intact on purpose.

## Short Version

## Short Version

MOARkNOBS-42 started in late 2024 as an attempt to build more instruments, learn MIDI deeply, and push microcontroller work past one-function sketches. Through 2025 it became a real Teensy-based MIDI controller project with a PCB, display, EEPROM-backed configuration, envelope followers, arpeggiator behavior, WebSerial telemetry, and an expanding test harness.

By early 2026, the center of gravity moved from "can the firmware do this?" to "can the whole instrument prove this?" Firmware, App, Bridge, docs, release tooling, and bench evidence started being treated as one product surface. Through the spring, prototype fabrication and release hardening forced the repository to separate verified behavior from plans, simulations, and optimistic assumptions.

By summer 2026, a second shift was underway: the question was no longer only whether the system was powerful or provable, but whether a musician could understand and inhabit it. The App, Bridge, hardware controls, documentation, recovery flows, and modulation systems increasingly converged around operator roles and a more legible performance model.

By August 2026, incoming MIDI joined physical gesture, envelope followers, ARG relationships, and LFO motion as a device-owned control source. Soft takeover, origin-aware routing, profile persistence, and musician-facing App work made an older implication explicit: MN42 is not only a surface that sends control. It is a surface where several sources can make claims on the same musical state and the performer can arbitrate among them.

The current repo posture remains evidence-driven: current support, release, fabrication, and hardware claims belong in contract and evidence docs rather than in this history.

The useful arc is:

- **2024 to early 2025:** exploration, firmware scaffolding, KiCad/EasyEDA hardware starts.
- **Spring and summer 2025:** first board spins, firmware baseline, MIDI expansion, WebSerial, and early tagged drops.
- **Fall 2025:** CI, diagnostics, docs, teaching structure, and bridge/test discipline.
- **Winter 2025 to early 2026:** browser configurator, LFOs, macro/scene storage, and safer live recovery.
- **March to May 2026:** release hardening, prototype fabrication handoff, contract cleanup, Node 24 bridge path, and evidence-driven release gates.
- **June to July 2026:** system convergence, musician-facing ergonomics, documentation hierarchy, and clearer App/Bridge operator roles.
- **August 2026:** device-owned incoming control, schema/persistence closure, and an increasingly explicit control-arbitration model.

## How to Read This History

- **Read phases, not every hash.** Each phase names the main obsession so you know whether you are in copper, firmware, browser, Bridge, or release-proof territory.
- **Treat "Turning point" callouts as the story spine.** They mark moments where the project changed shape, not just moments where code landed.
- **Use commit references as trailheads.** Short hashes and tags are included where they already existed in the old history; missing hashes are labeled with durable topic names instead of volatile placeholders.
- **Read reflections as diary fragments.** The italic sections keep the first-person design voice, grouped away from the factual bullets so the page scans without losing its pulse.
- **Let later phases reinterpret earlier work without rewriting it.** A feature may enter history once as engineering and matter again later when several features reveal a larger instrument idea; the later phase should record that change in meaning rather than pretending the meaning was obvious from the start.
- **Use contract docs for current truth.** This page remembers the path. It does not define today's protocol, support boundary, release status, or test requirements.

## Completed History

### Phase 1: Origin, Firmware Skeleton, and Board Curiosity (Late 2024 - March 2025)

The project begins as a hands-on MIDI and microcontroller study, with Bastl Instruments' [60 Knobs](https://github.com/bastl-instruments/60knobs) and [60knobs-experimental](https://github.com/bastl-instruments/60knobs-experimental) acting as early sparks.

- **December 10, 2024:** The initial commit introduces the firmware source tree with modules for button scanning, MIDI handling, display control, and EEPROM support. [58ef040]
- **Mid December 2024:** Early display management, multiplexed button matrix work, "mux management," and display managers start forming the first runtime shape.
- **Late December 2024:** EEPROM, USB MIDI functionality, debounce logic, and a second display-code revision land. [dbf3c21, 788a1ba]
- **January - March 2025:** Hardware design starts in KiCad, then shifts into repeated board iteration. Firmware cleanup and configuration handling continue alongside the first serious PCB files. [70665ff, 4c22a8b]
- **Late January 2025:** The EasyEDA project appears, the firmware tree moves under `firmware/`, and substantial board files arrive. [20e518a]
- **February - March 2025:** Board revisions, button routing, and resistor pull-up improvements keep cycling. [f36d220, dd0ebb6]

> **Turning point:** The project stops being only a firmware experiment once the repo has to care about physical layout, not just whether a sketch compiles.

**Reflections from this stretch**

- _I decided I wanted to build more instruments and wanted to explore MIDI and microcontrollers more expansively. Heavy early research around simple machines, one-function mockups, and C++ best practices began._
- _More complicated in areas that I didn't anticipate complexity in than in the outright complicated parts._
- _How is this thing supposed to happen, as more than just a simple experiment?_
- _My old workstation only ran up to KiCad 6._

### Phase 2: First Board Spin and Firmware Baseline (April - June 2025)

Spring turns the repo into something with named hardware, testable firmware pieces, and enough documentation to begin carrying intent forward instead of relying on memory.

- **April 2025:** Repository reorganization and the first official PCB revision, `MN42-1`, land in EasyEDA. [174b516, f5916a7]
- **May 2025:** Firmware refactors focus on display timing, envelope follower behavior, and general stability. README updates start documenting actual use. [44e89dc, ec7edb3]
- **May 2025:** The initial testing framework appears with incremental fixes. [ed357da, 6a4e54a]
- **Early June 2025:** Unit tests for `BiquadFilter` arrive, along with fade-animation fixes. [b050f4f, 69fd0db]
- **June 17, 2025:** Tag `firmware1.0` marks a stable firmware baseline before the feature set widens. [04f6b72]
- **Late June 2025:** MIDI message support expands beyond plain CCs, slot verification appears, filter feedback improves, and docs explain envelope filters, ARG mode, and test approaches. [6cef527, 0e5c9d9, 2615616, ab8078a, 43b1d33, b14ef44]
- **June 25 - 28, 2025:** Pin assignments are consolidated, old files are removed, the MIT license lands, hardware docs improve, DSP/control-button tests expand, and README cleanup wraps the documented state. [bfbfbaf, cb39705, b703f1f, 1a2b239, 8ed5568]

> **Turning point:** `firmware1.0` is less "done" than "stable enough to mutate." After this, the project has a baseline to branch from instead of a fog bank.

**Reflections from this stretch**

- _Work just a little at a time, and eventually you have a whole castle._
- _Getting onto breadboards for timing testing/display/MIDI/etc._
- _I bet this can do so much more than CC really easy._
- _Decided to give AI tools a try because who am I to say no to a perfectly good tool?_
- _I am trying to get better at documentation as I go, but this helps explain what is happening so much more than my drafts alone. I just have an assistant now._

### Phase 3: Feature Expansion, Public Drops, and Test Discipline (July - August 2025)

Summer is where MOARkNOBS-42 starts acting like an instrument instead of a hardware exercise. The arpeggiator, deeper MIDI types, WebSerial telemetry, diagnostics, and CI/test expectations all arrive in a noisy cluster.

- **July 2025:** Arpeggiator mode lands with base-note support and full MIDI type coverage. PlatformIO builds pick up the arpeggiator sources, README behavior gets documented, and tests expand across biquad filter modes and EEPROM slot verification. [850b4e9, 60abd55, e03466d, 6b81ed0, 1e9a015, 09ffda2, 2716465, 9a8733b]
- **July 2025:** Button-driven navigation simplifies test phases, helper functions unify test initialization, variables get clearer, and docs add flashing instructions, diagrams, and links back to this history. [8716674, bf1936f, 109a1b8, 6d769ec, 822a1ea, 5f3e34b, e25622e, 0941fcb]
- **Early August 2025:** Hardware v1.02 work completes, `Utility::processBulkUpdate` is refactored around a raw char buffer, and `MN42_v2` design assets arrive under hardware references. `fea338e` calls for thicker LED power traces so the LEDs do not sag or cook when current rises.
- **Early August 2025:** NRPN, RPN, and raw SysEx support widen the MIDI story; WebSerial starts streaming runtime state to the browser.
- **August 6, 2025:** Early tagged drop `v0.1.0` bundles filter-tuning pots, a self-driving arpeggiator, WebSerial telemetry, NRPN/RPN/SysEx support, and the first `CHANGELOG`. [v0.1.0]
- **August 8, 2025:** PR #286 brings in FastLED and adds teachable comments around the early browser configurator path. [956069c]
- **Late August 2025:** CI flakes force build-script hardening. The MIDI library changes, `usb_midi` ghosts get chased down, and a Unity test rig makes commits prove themselves.
- **August 22 - 23, 2025:** Diagnostic mode lands with self-test pages, compact matrix view, reset-cause boot banner, system report, release workflow, pre-commit lint, and CI pinned to Node 20 at the time. [0215e43, 00af0f1, 399b17, b7c126a, 19fbe9b, 7ee46c7, 702c107]
- **August 25, 2025:** SparkFun reference sidebars join the docs as learning links from the source. [4e4cf22]

> **Turning point:** `v0.1.0` is the first outward signal that the project is not just private bench noise. The repo now has tags, browser telemetry, deeper MIDI, and a test culture that can hurt your feelings usefully.

**Reflections from this stretch**

- _If you ever wanted a synth to show you its source and its soul, this is the moment._
- _My ears are still ringing because I went to a metal show in the basement of an American Legion. I am scrambling to make these Unity testers work for the codebase as well as actual builds of the firmware._
- _Standards are not optional; often the best lessons come from coloring off the page._
- _Because a README that teaches you nothing is just wall art._

### Phase 4: Diagnostics, Bridge Notes, and Teaching Repo (September - December 2025)

Fall turns the repo into a field guide. The work is still technical, but the bigger shift is that bring-up rituals, bridge behavior, annotated source, and repeatable tests become first-class material.

- **September 2025:** `bridge/` scripts get documented so serial telemetry can be wired without reverse-engineering the handshake. Diagnostic docs, boot banner logic, and Unity expectations are cleaned up.
- **September 2025:** Hardware planning notes capture possible `MN42-1.1` changes: regulator headroom, pot footprints, and related spin prep.
- **October 2025:** Major README and HISTORY passes tighten cross-links, PlatformIO test breadcrumbs, scoped button-matrix rituals, WebSerial console macros, and the "use Serial1, not Serial" Unity transport lesson.
- **Mid October 2025:** `ConfigManager` pushes stored MIDI channel maps into live managers, `PotentiometerManager` tracks the same EEPROM offsets, the globals JSON loader gets more room for hardware presets, and `test_system_report.cpp` routes Unity chatter through the same `PrintTarget`/`Serial1` combo as the rest of the harness.
- **Late October 2025:** `demo_button_ef_usb_midi.cpp` provides a button-plus-envelope USB MIDI sanity sketch.
- **October 31, 2025:** `v0.2.0` ships diagnostic boot pages, verbose reset banner, USB MIDI demo, and release/CI discipline.
- **November 2025:** Firmware comments get a teaching pass across major `.cpp` files. Slot ownership, EEPROM layout, SysEx templates, schema page reservations, source tour material, and lesson headers turn the repo into half notebook, half lab.
- **Mid November 2025:** The Playwright-driven simulator rehearses handshake, schema validation failure, checksum/ACK rollback, and simulator toggles. `npm --prefix App test` gets wired into `test.sh` and CI.
- **Late November 2025:** WebSerial aligns with `CONFIG_VERSION` `0x0004`; the browser reads `git_sha`, `build_time`, `free_ram`, and `free_flash` from the handshake. The LED editor moves from a 42-cell color grid to brightness plus hex color, and runtime normalization keeps staged diff/apply behavior aligned with firmware slot patches.
- **December 2025:** `firmware/system_test/mn42_fullstack_runner.js` starts spawning the Bridge, confirming `HELLO`, sending slot patches over OSC, tailing telemetry, and writing JSON/text logs. Docs describe the upload-to-runner flow, and Playwright migration coverage grows teeth.

> **Turning point:** The repo stops treating docs as a recap and starts treating them as part of the instrument. A future builder can learn from source comments, tours, tests, and runner evidence instead of spelunking old commits.

**Reflections from this stretch**

- _Next milestone: line up the manufacturing quote without losing the DIY ethos._
- _Documentation isn't a tombstone; it's a mosh pit and we just pushed closer to the stage._
- _Feels good when the tooling jams as hard as the hardware: documentation, tests, and demo riffs all screaming through the same signal chain._

### Phase 5: Configurable Instrument and Live-Recovery Shape (January - February 2026)

Early 2026 is where the system starts behaving like a configurable performance object. LFO routing, browser-side editing, serial dispatch cleanup, macro/scene storage, onboarding UX, and demo safety all move forward together.

- **January 2026:** Firmware instantiates a dedicated `LFOManager`, seeds two routed oscillators for LED brightness, arp swing, EF gain trim, and shared diagnostics/telemetry globals. Unity/LFO tests cover shapes, clock sync ratios, normalized outputs, MIDI-clock loss, and EEPROM-backed route snapshots. [2fe3c15]
- **January 2026:** The App splits the runtime kernel from the BenzKnobz view layer, adding schema-driven forms, staged diff/rollback UI, telemetry cards, MIDI monitor, simulator toggle, and Playwright coverage for config forms, bridge handshake, MIDI monitor, and migration flow. [2fe3c15]
- **January 2026:** Serial command handling is refactored from a massive `processCommandQueue` ladder into a sorted dispatch table with dedicated handlers, `dispatchCommand`, unknown-command logging, and Unity coverage through `testOnly_dispatchCommand`. [dispatch-refactor-2026-01]
- **January 2026:** `test/test_protocol_dispatch.cpp` covers known `HELLO` dispatch and unknown commands. A small `firmware/python` shim points `python` to `python3` for PlatformIO helper compatibility in `python3`-only environments. [dispatch-refactor-2026-01]
- **February 2026:** Macro and scene snapshot plumbing starts: `SAVE_MACRO_SLOT`, `RECALL_MACRO_SLOT`, richer LED mode planning, scheduler-driven LED animation, fixed-size scene records, EEPROM-backed slots, and browser controls begin taking shape.
- **February 2026:** The App gains persisted Basic/Advanced UI modes, glossary/help cues, safer profile workflow, RPC gating, and clearer connect/disconnect behavior across profile, macro, and scene controls.
- **February 2026:** Bridge onboarding docs get rebuilt with quickstart, performer one-sheet, operator reference, packaging roadmap, release artifact checklist, smoke scripts, package scripts, and npm aliases.
- **February 2026:** CAD iteration files such as `.epro`, `.eprj`, autosave, and backup outputs are ignored by default so release surfaces stay focused.
- **February 2026:** Demo polish adds a `device_name` manifest field, clear "Connected to" banner, connect-failure help, Playwright coverage for connection UX, more readable OLED labels, a panic-safe exit combo (`Ctrl0 + Ctrl1 + Ctrl2`), demo presets, and a runbook in `docs/validation/DemoPolish.md`.

> **Turning point:** The browser is no longer only a log window. It becomes a guarded editor that can rehearse changes, validate schemas, recover from bad live state, and expose the instrument to less-technical users without lying about what is happening underneath.

**Reflections from this stretch**

- _The rig finally has the pulse I imagined: two synced modulators that can flow into LEDs, the arpeggiator, MIDI CCs, or every envelope follower tweak without the scheduler hitching a beat._
- _With the simulator standing in for the Teensy and schema validation guarding every Apply, the browser is no longer just a read-only log; it edits profiles, replays slot patches, and rehearses checksum rollbacks before you touch the hardware._
- _This pass shifted the demo story from "we can probably recover" to "we can prove identity, readability, and recovery on command because we are being militant about this for a reason."_
- _PCBWay reached out and wants to help me make a run of prototypes of the board: motivation to move from simply a cool maker project to something a bit more ornate and rugged._

### Phase 6: Release Hardening, Contract Closure, and Prototype Handoff (March - May 2026)

Spring 2026 is the "prove it" season. The project tightens export provenance, test coverage, Bridge, App, and firmware contracts, storage truth, host compatibility, and hardware evidence.

- **March 2026:** Release prep shifts from "probably shippable" to "prove it" through deterministic export checks, contract-sync guards, and release artifact validation. [`c4f3132`, tag `26_1`]
- **March 2026:** Stale security findings force cleanup in firmware formatting paths: remaining `sprintf` calls are replaced with bounded `snprintf`, Unity link issues are straightened out, and false-positive triage noise drops. [`77978db` and March follow-ups]
- **March 2026:** The configurator stops advertising unfinished placeholder presets, including the visible Elektron Analog Rytm stub.
- **March 2026:** Unity coverage expands into orchestration: `exponentialMovingAverage`, `LedAnimator::cycleMode`, command queue parsing and overflow, SeedBox handshake flow, runtime pending note-offs, WebSerial snapshots/slot patches, and UI tuning helpers.
- **March 2026:** A scheduler bug is exposed and fixed: MIDI service, envelopes, WebSerial streaming, SeedBox updates, and low-priority UI/LED refreshes are registered as recurring work instead of one-shot tasks.
- **March 13, 2026:** The prototype PCB run is sent to fabrication, marking the handoff from design churn to real boards in the mail.
- **March 2026:** A fit/finish audit forces firmware, Bridge, App, and docs to tell one story. Browser-driven profile save/load/reset becomes real firmware behavior, EEPROM-backed macro snapshots and scene storage land, native transport verbs become the source of truth, and Bridge live control moves to `SET_SLOT_VALUE`. [`9143195`, `b6844fc`]
- **March 2026:** Browser-only slot notes such as `label`, the MIDI badge, and `Take Control` are explicitly local browser affordances instead of fake device config. Reconnect behavior stops stomping local notes with the last `GET_CONFIG` response. [`3d3e595`]
- **March 2026:** `HostCompatibility.md` is added, MkDocs strict mode returns to green, and navigation/reference pages become explicit. [`403874e`, `ff60649`, `8e1deb7`]
- **March 2026:** Firmware tests gain targeted persistence coverage, and the full-system runner gets a destructive `--exercise-storage` path for profile/macro/scene proof. [`b6844fc`]
- **April - May 2026:** Source exports come from tracked files only; release manifests ignore generated dirt while still refusing dirty tracked trees. [release-gate-tightening-2026-04]
- **April - May 2026:** Doctor and App bridge paths align around Node 24, matching the Bridge release lane and current host evidence. [node24-bridge-alignment-2026-04]
- **April - May 2026:** Release verification treats Bridge and App tests as mandatory, layers in Unity and full-stack HIL when hardware is present, and records skipped-versus-run evidence in `release_verification.json`. [release-verification-evidence-2026-04]
- **April - May 2026:** Bridge packaging adds gated signing/notarization hooks so beta/public artifacts must prove signing before being treated as outward-facing releases. [bridge-signing-gates-2026-04]

> **Turning point:** Once copper is ordered and release artifacts are gated, the project has to stop narrating intentions as if they are proof. The repo starts saying what is verified, what is planned, and what is merely historical.

**Reflections from this stretch**

- _The useful surprise here was not just "more tests passed"; it was that broader coverage exposed a real scheduler bug hiding in plain sight._
- _There is a different kind of seriousness once copper has been ordered; every doc line and every test starts reading like an instruction to your future self standing at a bench with actual hardware in the mail._
- _This was the month the repo got less romantic and more trustworthy: fewer implied capabilities, fewer simulator ghosts, more "does the whole instrument tell the same story when you actually use it?"_
- _The release path stopped being "build some zips" and became "prove the source, prove the host, and prove the outward-facing binaries are treated like evidence artifacts instead of internal scraps."_

### Phase 7: System Convergence and Operator Legibility (June - July 2026)

Early summer is less about adding another subsystem than making the existing ones belong to the same instrument. The repo already has firmware depth, browser editing, Bridge routing, hardware controls, tests, and a dense documentation library; the work increasingly turns toward deciding what each surface is *for* and how a performer should encounter it.

- **June - July 2026:** Documentation is reorganized around fewer first doors instead of fewer total pages. Learn, Use, Build, Prove, Reference, Project, and Archive become reader-facing lanes, while contract, evidence, orientation, planning, and historical truth remain explicitly distinct. [VERIFY TRAILHEAD: documentation compaction / truth-map commits]
- **June - July 2026:** Performer and learner routes become more intentional: First Five Minutes, Musician-First guidance, signal-path teaching, reactive-control guides, and role-based quickstarts increasingly translate firmware behavior into musician decisions instead of mirroring source-tree structure. [VERIFY TRAILHEAD]
- **June - July 2026:** The App and Bridge are treated more clearly as different operator surfaces over the same machine. The App owns instrument configuration and performance-facing state; the Bridge increasingly reads as the host/session/routing environment around the instrument rather than a second configurator. [VERIFY TRAILHEAD]
- **June - July 2026:** LFO, ARG, EF, display, profile, scene, panic, and on-device control work keeps moving toward reachability: important behavior should be observable and recoverable from the panel or a musician-facing software surface rather than existing only because the firmware supports it. [VERIFY TRAILHEAD]
- **June - July 2026:** App/Bridge simulator, screenshot, documentation, and operator-evidence surfaces mature enough that interface behavior can be rehearsed without confusing simulator proof for hardware proof. [VERIFY TRAILHEAD]

> **Turning point:** The project stops asking whether every subsystem is powerful enough and starts asking whether a musician can understand the whole instrument without understanding every subsystem.

**Reflections from this stretch**

- _Realizing that hiding complexity is far different and more complex than simply deleting it._
- _The machine should explain itself while it is operated without the endless tiny-screen menu dive._
- _A lot of work is going into distinguishing the instrument from the backstage plumbing around it._
- _Documentation hierarchy and UI hierarchy are versions of the same design problem - CIs will save._

### Phase 8: Control Ecology and the Surface of Arbitration (August 2026)

August makes a long-running musical idea explicit in the architecture. Physical controls, envelope followers, ARG relationships, and LFOs already gave the machine several ways to move state. Device-owned incoming MIDI adds another actor: another machine can now make a claim on an MN42 parameter without requiring the App or Bridge to remain attached.

- **August 2026:** Schema 9 adds profile-owned incoming MIDI bindings. DIN and USB CC input can target direct slot values and selected machine parameters through a device-owned parameter-routing layer rather than a host-side mapping shim. [`8fc3d74` and follow-ups]
- **August 2026:** Incoming control gains explicit interaction semantics: absolute, momentary, and toggle behavior; bounded ranges; soft takeover; validation; and origin-aware output suppression. Physical controls can reclaim externally injected state by crossing the remote value instead of snapping immediately back to the pot's old position. [`8fc3d74`, `894bc08`, follow-ups]
- **August 2026:** MIDI binding state becomes part of profile persistence. Legacy modulation records migrate forward, config digests include binding semantics, profile/config import-export share the authoritative representation, and migration regressions are expanded rather than assuming old EEPROM state will survive by luck. [`894bc08`, `9a4ba78`]
- **August 2026:** Persistence hardening closes older boot/profile edge cases discovered during the schema work: configuration is hydrated before active-profile restoration, all schema-8 profile copies are promoted deliberately, ARG housekeeping runs during migration, and profile selection refuses partial transitions when the basic mapping cannot load. [`9a4ba78`]
- **August 2026:** The browser configurator moves toward a clearer musician-facing hierarchy. Stage, Configure, and Lab become distinct jobs instead of progressively larger versions of the same form; Configure translates reactive behavior into Source, Character, Response, Amount, and Direction while Lab preserves exact firmware fields. [VERIFY TRAILHEAD: App surface commits after `9a4ba78`]
- **August 2026:** The incoming-MIDI editor presents routes as Incoming message -> Destination -> Response rather than exposing the nested schema directly. Browser intent is staged synchronously while outbound live patches remain debounced, keeping UI simplification aligned with the same staged/apply authority model used elsewhere. [`5fa44d0`, `db423a0`, `7ad20fe`]
- **August 2026:** The emerging interaction model becomes easier to name: the hand, time, environmental signal, algorithmic combination, and another machine should all participate in the same performance state. The interesting behavior shouldn't be only modulation; it is the performer's ability to allow, combine, resist, or reclaim those influences that makes things interesting.

> **Turning point:** MN42 stops being only a surface that sends control and becomes a place where control is negotiated. The hand, incoming signal, time, algorithms, and other machines can all act on instrument state; performance increasingly consists of deciding how those claims coexist.
And I turned 40.

**Reflections from this stretch**

- _I prefer cooperation amongst my machines. The more shared-load, the better and routing control dynamics from the composer would be optimal._
- _Testing in my current studio is somewhat more difficult than it has been in the past._
- _The browser-surfaces may have started as an addendum or requisite evil, but they've really grown on me._
- _MN42 wants to expose that stability is only temporary and structure is a nice idea._

### Phase 9: Evidence Handoff and the End of Software Alibis (Late August - September 2026)

By late summer, the software stack had become mature enough that adding another abstraction was increasingly less useful than putting the physical instrument under stress. Firmware, App, Bridge, simulator, deployment, documentation, and evidence tooling had spent months closing gaps where one surface could tell a different story from another. The remaining uncertainty increasingly belonged to copper, power, noise, timing, heat, physical controls, and prolonged use.

* **Late August 2026:** Hardware-in-the-loop runners and bench receipts become more explicit about what they prove and, equally importantly, what they do not. Failed HIL runs remain evidence instead of being discarded, and live-control tests demonstrate real Teensy round-trips for USB MIDI, note dynamics, jitter, and clock without contaminating staged configuration state.
* **Late August - early September 2026:** App and Bridge work shifts from feature expansion toward operator clarity. The Bridge increasingly presents the live host/session topology a performer actually needs, while the App resolves into three distinct surfaces: Stage for performance, Configure for instrument programming, and Lab for deeper technical inspection.
* **Early September 2026:** Lab is reorganized around Instrument, Profile, Observe, and Evidence rather than accumulating technical panels in one undifferentiated workspace. Instrument controls explicitly distinguish staged machine configuration from immediate live firmware writes.
* **Early September 2026:** Selected-slot visualization, modulation telemetry, Scope, Modulation Matrix, staged diff, and inspector surfaces increasingly describe the same underlying control path rather than separate debugging interpretations of it.
* **September 7, 2026:** A false simulator LFO conflict exposes one of the remaining representational gaps: the simulator's startup fixture, telemetry, and Mod Matrix could describe different effective routing states. The fix removes seeded startup routes, makes the active profile authoritative, resolves fixed and legacy LFO routing through one effective graph, mirrors firmware shadowing semantics, and adds integration tests requiring telemetry and the Mod Matrix to agree.
* **September 2026:** Browser deployment becomes a source-addressable artifact rather than a floating development page. Published App builds carry their originating commit SHA and immutable release path, allowing the public Configurator to identify exactly which repository state it represents.
* **September 2026:** Interface work reaches an intentional slowdown. Further software changes remain possible, but the major unanswered release questions can no longer be answered by another simulator test, UI pass, documentation rewrite, or CI job. Rail topology, electrical behavior, EF stability, clock starvation, panic recovery, thermal/soak behavior, physical ergonomics, and fabrication evidence require the actual machine.

> **Turning point:** The project finally paints itself into the corner it has been constructing since the first PCB: the remaining important questions require touching the instrument. Software can prepare the experiment, record it, and refuse unsupported claims, but it cannot perform the physical proof.

**Reflections from this stretch**

* *There is a point where improving the test harness becomes another way of avoiding the test.*
* *The useful success of the software is that it has increasingly run out of excuses for the hardware.*
* *If the machine says something happened now, I want to be able to ask which layer knows that, how it knows it, and what evidence survives afterward.*
* *The next useful commits may be photographs, measurements, failed receipts, and corrections rather than features.*

## Current Repository Shape

This is an orientation snapshot, not a contract. For current status, use [Repository Contents](RepositoryContents.md), [Release Boundary Index](../release/ReleaseBoundaryIndex.md), and [TESTING](../validation/TESTING.md).

- `firmware/`: Teensy 4.0 PlatformIO project with modular firmware managers, Unity tests, and hardware/system test runners.
- `hardware/`: current hardware references, substitutions, parts rationale, and current-build notes. Historical PCB source exports are not the same thing as a public fabrication-ready hardware package.
- `App/`: browser instrument surface with Stage / Configure / Lab roles, Playwright coverage, a schema-driven runtime, simulator support, direct WebSerial plus structured Bridge paths, and guarded staged/apply behavior.
- `bridge/`: desktop host/session layer for serial, OSC, MIDI, structured App transport, routing health, and operator diagnostics; it protects device truth without becoming a second instrument configurator.
- `docs/`: MkDocs source for learning, use, build, proof, reference, project, and archive material.
- `tools/`: guardrails for contract sync, release readiness, documentation checks, and repo health.

## Where Planning Continues

Earlier versions of this history also carried a live roadmap. That made sense while the project and its documentation were still being assembled together, but it also made a historical page go stale whenever release, packaging, or operator plans changed.

Current plans now live with the current project and release documents rather than here:

- [Pilot Run / Artist Edition](PilotRun.md)
- [Release Boundary Index](../release/ReleaseBoundaryIndex.md)
- [Release Criteria](../release/ReleaseCriteria.md)
- [Release Guide](../release/ReleaseGuide.md)
- [Bridge Docs Map](../bridge/BridgeDocsMap.md)
- [Documentation Compaction Plan](DocumentationCompactionPlan.md)
- [TODO](TODO.md)

This page records what happened and why the project changed shape. Planning pages record what might happen next.

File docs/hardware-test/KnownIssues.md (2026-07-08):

# Known Issues

## Current Package Limits

- No verified Gerber and NC-drill archive is claimed by this package yet.
- No current BOM export is tracked in `hardware/fabrication/`.
- The hardware reference bundle is for review and testing only, not fabrication sign-off.
- A signed bridge installer is not included.
- Browser validation is scoped to the included `App/` assets and a local host flow, not a broad browser-support claim.
- The bridge validation scope is bench-focused and does not claim verified compatibility across every OSC host or DAW.

## Display And OLED Notes

- The current OLED expectation is address `0x3C`.
- OLED validation is based on the included hardware-test lanes, not a generic bus-scanner utility.
- Some bench receipts have observed `display_init_failed` during boot. Current firmware treats that as a controlled degraded mode instead of a boot blocker.
- The default `teensy40_main` env currently defers OLED boot probing on unvalidated benches so a missing/no-ACK display does not destabilize standalone runtime. Use the dedicated display hardware-test lanes for OLED validation.
- When OLED bring-up fails, `HELLO`, `GET_MANIFEST`, `GET_SCHEMA`, `GET_CONFIG`, and `SET_ALL` remain available so the App and Bridge can still inspect or restore the board.
- `GET_MANIFEST` and WebSerial diagnostics now expose `display_present`, `display_ok`, `display_init_failures`, and `display_status` for machine-readable operator evidence.
- The firmware performs a safe periodic re-init attempt for a missing or failed OLED, but this is still not a claim of universal compatibility across every SSD1306 module variant.
- The package does not claim display performance tuning across every module variant.

## Telemetry And Runtime Notes

- WebSerial validation depends on the current firmware text-command handshake and the included browser configurator.
- Live telemetry is a bench aid, not a hard real-time measurement contract.
- The full-stack bridge runner is hardware-in-the-loop and can fail for host serial-port, permissions, or bench-cabling reasons outside the firmware itself.

## Automated-Test Verification Snapshot (2026-04-23)

The previously documented bridge/app test failures are no longer reproducible in current runs.

- Verified passing: `npm --prefix bridge test`
- Verified passing: `npm --prefix App test`
- Verified passing targeted native transport case:
  `npm --prefix App test -- tests/native_transport.spec.js`

No active automated-test failures are currently tracked in this document. Add new failures only with a reproducible command and failing test path.

## Manufacturing Boundary

- Present hardware PDFs and parts notes are prototype references.
- The current fabrication folder is a boundary note only; no orderable BOM, Gerber, or NC-drill package is enclosed.

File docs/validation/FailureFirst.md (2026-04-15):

# Failure-First Guide

A lot of people learn instruments by joyful misuse. That is fine. But for a device like this, recovery stories are often the fastest route to understanding.

This page explains the most common "wait, what just happened?" situations in the stack and what they usually mean.

## 1. Preset staged, but nothing changed on the device

What happened:

- you chose a preset in the picker
- the browser staged it locally
- you did not Apply yet

Why this exists:

- it protects the live deck from silent overwrite
- it lets you inspect changes before committing them

What to do:

1. review the staged diff
2. press Apply
3. save into a profile only if you want permanence

See: [Preset Library](../guides/PresetLibrary.md), [Profile Workflow](../guides/ProfileWorkflow.md)

## 2. Apply failed or rolled back

What happened:

- the browser sent staged state
- the device did not confirm it correctly
- the runtime rolled back rather than pretending success

Why this exists:

- it keeps the UI honest
- it protects you from phantom state

What to do:

1. check connection health
2. check schema compatibility
3. retry only after the status makes sense

See: [Configurator Tour](../guides/Configurator.md), [WebSerial Walkthrough](../guides/ProtocolWalkthrough.md)

## 3. Schema mismatch warning appears before editing

What happened:

- the browser manifest check found that the UI and device do not agree on config structure

Why this exists:

- editing across schema drift is how you create invisible corruption

What to do:

1. export anything important
2. update firmware or UI as needed
3. only use migration adapters when the UI explicitly offers one

See: [WebSerial Walkthrough](../guides/ProtocolWalkthrough.md), [Glossary](../reference/Glossary.md)

## 4. Loading a profile wiped the thing you were editing

What happened:

- you told the device to recall its saved EEPROM snapshot
- the browser then synced to that newly loaded state

Why this exists:

- loading a profile is a replacement action, not a merge

What to do:

- export your current staged work before loading if you may want it later

See: [Profile Workflow](../guides/ProfileWorkflow.md)

## 5. The board recovered from EEPROM backup or defaulted on boot

What happened:

- the primary saved config was invalid
- firmware recovered from backup, or fell all the way back to defaults

Why this exists:

- the instrument prefers degraded recovery over silent corruption

What to do:

1. reconnect and inspect the current config/profile state
2. reload a known-good profile if needed
3. save again once the state is trustworthy

See: [BuildersHandbook](../getting-started/BuildersHandbook.md), [EEPROM Layout](../reference/EEPROMLayout.md)

## 6. Reactive behavior feels wrong, noisy, or harder than expected

What happened:

- your EF/filter/ARG combination is doing more than you think

Why this exists:

- reactive controls are compositional, not just numeric

What to do:

1. reduce to one envelope follower
2. switch to `LINEAR` or `LOWPASS`
3. disable ARG
4. reintroduce complexity one step at a time

See: [Reactive Control Guide](../guides/ReactiveControlGuide.md)

If the confusion is specifically about blending or shape, read:

- [ARG Guide](../guides/ARGGuide.md)
- [Filter Feel Guide](../guides/FilterFeelGuide.md)
- [LFO Route Guide](../guides/LfoRouteGuide.md)

## 7. Bridge is connected, but your DAW or OSC tool still feels dead

What happened:

- the bridge may be up, but the wrong port, path, or endpoint is still in play

What to do:

1. confirm serial path
2. confirm handshake appears once
3. confirm UDP port and address match the docs
4. relaunch the DAW if the virtual MIDI device came up late

See: [Bridge for Performers](../guides/BridgeForPerformers.md)

## 8. You do not know whether to use browser, bridge, preset, or profile

Use this shortcut:

- browser: editing and inspection
- bridge: live OSC/DAW workflows
- preset: browser-side starting template
- profile: device-side saved memory

If the confusion is about terms rather than behavior, read [Glossary](../reference/Glossary.md).

## Read next

- [Troubleshooting](Troubleshooting.md) for physical hardware failures
- [Glossary](../reference/Glossary.md) for the vocabulary behind these failure cases
- [Guided Routes](../getting-started/GuidedRoutes.md) if you want a calmer route through the site

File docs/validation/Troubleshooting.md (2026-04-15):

# Troubleshooting: When the Rig Refuses to Riff

If the board's gone sulky, this cheat sheet walks you through the usual suspects before you start desoldering in despair.

## Flowchart of Fail

```mermaid
flowchart TD
  A[Board lifeless?] --> B{Power LED lit?}
  B -- No --> C[No Power<br>Check cable, supply, switch]
  B -- Yes --> D{Main LED alive?}
  D -- No --> E[Dead LED<br>Swap LED or check data line]
  D -- Yes --> F{Buttons clean?}
  F -- No --> G[Noisy Button<br>Re-solder, add debounce cap]
  F -- Yes --> H[All good<br>Make noise]
```

## Hardware Horror Show

The camera finally rolled back into the bench bag, so here's a guided tour of the greatest hits that derail a MN42 bring-up session. Match what you see on your board to the cues below, then chase the fixes in order.

### Power Rail Woes (3V3 Brownout)

Annotated diagram of an MN42 power brownout showing a steady USB input, sagging 3V3 rail, and flickering status LED.

1. **Spot the symptom:** The USB input sits pretty at 5.0 V while the status LED barely flickers. That means the cable and power switch are fine; the trouble is downstream.
2. **Confirm the crime:** Probe the 3V3 rail. If it faceplants to ~2.2 V every time the LED bus refreshes, the regulator is browning out. Your MCU is tapping out, not dead.
3. **Fix the mess:** Swap in a known-good regulator or strap in extra bulk capacitance near the LED connector. If the dips vanish, button it up; if not, hunt for shorts on the 3V3 plane.

### Noisy Button (Switch Chatter)

Annotated diagram of oscilloscope captures showing button node chatter, GPIO spikes, and a contaminated ground joint.

1. **Spot the symptom:** Press the suspect button and watch the GPIO trace mirror a spray of spikes. Firmware thinks you're double-kicking the switch.
2. **Confirm the crime:** Measure the switch node: if it ricochets between rails for ~1 ms and sits 0.8 V above ground, the joint is cruddy and there's zero hardware debounce.
3. **Fix the mess:** Scrub the ground lug, reflow the switch, then tack on a 100 nF cap across the contacts. Firmware calms down once the waveform stops moshing.

### LED Data Break (Mid-Chain Silence)

Annotated diagram of an LED chain showing lit leading pixels, a dead mid-chain pixel, and a weak data signal after a cracked joint.

1. **Spot the symptom:** The first ten pixels throw a rave while pixel eleven gives you a sullen red blink before going dark.
2. **Confirm the crime:** Probe the data pad after that pixel. If the edge is square-toothed and barely hits 1.2 V, the data line is fractured.
3. **Fix the mess:** Reflow the pixel's data pad. If the waveform still wheezes, bridge the data trace with a jumper wire and retest the chain from the controller end.

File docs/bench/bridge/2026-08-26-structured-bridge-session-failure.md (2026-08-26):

# Bridge Bench Summary: Structured Session

> Historical diagnostic receipt. The authentication and chunked-read issues recorded here were resolved later the same day; see the [passing rerun](2026-08-26-structured-bridge-session-summary.md).

Date: 2026-08-26
Commit: 407c271709d363ce31a48798f9ab3c114bdf82f8
Firmware git_sha: 407c2717
Firmware version: 0.0.0
Schema version: 9
Board revision: unknown/not captured
Board rework state: unknown/not captured
Serial port: /dev/cu.usbmodem192460701
Host: Mac.lan
Node: v24.18.1
Bridge mode: source
Firmware env: teensy40_main
Runner: firmware/system_test/mn42_bridge_session_runner.js
Artifact / report path: logs/bridge-session-2026-08-26.json
Raw log: logs/bridge-session-2026-08-26.log

## Result

FAIL — runner authentication mismatch before device connection (subsequently resolved)

## Observed

- The source Bridge console started successfully on `127.0.0.1:8791` and generated a control-token URL.
- The HIL runner attempted `/ws/events` without the generated control token.
- The Bridge rejected the unauthenticated WebSocket connection, and the runner stopped with `Structured websocket failed`.
- No `/api/connect`, device-session readiness, staged config, apply, or cleanup step ran in this attempt.

## Impact

- This receipt does not prove or disprove Bridge-to-device behavior on the attached board.
- The failure exposed drift between the token-protected Bridge server and the runner. The runner now consumes the generated token, authenticates its WebSocket and protected API requests, and redacts the credential from logs.
- Because failure happened before device connection, this attempt did not mutate device configuration.

## Runner output

The ephemeral control token was redacted from the console URL.

```text
[bridge-session:server] bridge console: http://127.0.0.1:8791/?token=[redacted]
[bridge-session] Scenario failed: Structured websocket failed
[bridge-session] wrote report to logs/bridge-session-2026-08-26.json
[bridge-session] PASS – Bridge server starts and exposes the console address: http://127.0.0.1:8791
[bridge-session] FAIL – Scenario failure: Structured websocket failed
```

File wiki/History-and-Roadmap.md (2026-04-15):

# History and Roadmap

Project evolution is documented in `docs/project/HISTORY.md`. This page provides a compact index.
Canonical source: `docs/project/HISTORY.md`

## Timeline summary

- 2024: initial firmware architecture and module foundations.
- Early 2025: hardware layout iterations and repository reorganization.
- Mid 2025: firmware stabilization, test harness growth, first release cadence.
- Late 2025: documentation expansion, diagnostics, CI/test hardening, UI maturity.
- 2026: dual LFO routing, onboarding/UX polish, bridge packaging preparation, v1.0 readiness.

## Milestone anchors

- `v0.1.0` (August 2025): first public release.
- `v0.2.0` (October 2025): diagnostic + release discipline improvements.
- Current track: onboarding, reliability, and release packaging toward stable v1.x workflows.

## Primary history sources

- `docs/project/HISTORY.md`
- `CHANGELOG.md`
- `docs/project/lineage.md`
- `docs/project/TODO.md`

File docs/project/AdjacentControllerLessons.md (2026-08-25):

# Adjacent Controller Lessons

> **Doc class:** Planning doc. This page records what MN42 should learn from the local reference projects without copying their identities.

This comparison was made against local clones under `~/Code/controller-references`:

- `shanteacontrols/OpenDeck`
- `16n-faderbank/16n`
- `jescriba/MIDIBox`

The useful question is not "how can MN42 look like those projects?" The useful question is "what project-hardening habits do they expose that MN42 should adapt to its own identity?"

## OpenDeck Lesson: Promise, Configurator, Boundaries

OpenDeck leads with a clear promise: build MIDI/OSC controller behavior without coding, with configuration exposed through a browser. Its front door also separates the official board from other supported boards.

MN42 should adapt:

- keep [Configure Without Recompiling](../getting-started/ConfigureWithoutRecompiling.md) visible early
- state exactly which behaviors can move through App/Bridge/profile workflows
- keep support boundaries conservative and evidence-backed
- separate "this is configurable" from "this is universally supported"

MN42 should not copy:

- the generic controller-platform identity
- broad board-support language
- claims that configuration replaces understanding the instrument

## 16n Lesson: Object, Repository, Build Artifacts

16n is clean because it defines the object first: what the faders are, what comes out, what hardware files exist, what is legacy, and where the build guide lives.

MN42 should adapt:

- keep [Object Card](../getting-started/ObjectCard.md) short and physical
- maintain a clear [Repository Contents](RepositoryContents.md) page
- separate current hardware references from legacy or historical files
- keep fabrication caveats attached to hardware file descriptions

MN42 should not copy:

- the minimal control-surface model
- the assumption that the repo is fabrication-ready
- the idea that the wiki can carry all build truth while repo docs stay thin

## MIDIBox Lesson: Small Code-As-Lesson Surface

MIDIBox is compact enough that the repo reads like a learning artifact. It names its premise directly and keeps the educational path close to the code.

MN42 should adapt:

- keep [Who Controls This Slot?](../learn/OneSignalPath.md) as a compact teaching page
- add short "read this code next" links when docs introduce a subsystem
- keep at least some pages small enough to read before opening source
- explain why App Apply, Bridge session, firmware config, and modulation each exist

MN42 should not copy:

- the tiny documentation footprint
- the single-purpose embedded-demo framing
- the lack of separate App/Bridge/firmware contracts

## Hardening Backlog

| Priority | Gap | Adapted Lesson | Next Move |
| --- | --- | --- | --- |
| High | Readers need a repo-level contents map. | 16n repository contents and artifact separation. | Maintain [Repository Contents](RepositoryContents.md) and link it from README/Docs Guide. |
| High | Configuration claims need precise boundaries. | OpenDeck browser-config clarity, but narrower. | Keep [Configure Without Recompiling](../getting-started/ConfigureWithoutRecompiling.md) tied to contracts and host evidence. |
| High | Release status can be confused with working software. | 16n version/status clarity plus MN42 evidence discipline. | Keep [Release Boundary Index](../release/ReleaseBoundaryIndex.md) visible in Prove. |
| Medium | Reactive modulation needs one map without one giant guide. | OpenDeck feature discoverability, MN42-specific routing.  | Let [Reactive Modulation Matrix](../guides/ReactiveModulationMatrix.md) act as the map before merging guides. |
| Medium | Bridge docs are useful but split across audiences. | 16n directory map style. | Keep [Bridge Docs Map](../bridge/BridgeDocsMap.md) current instead of merging everything. |
| Medium | Educational code paths should remain short. | MIDIBox code-as-lesson. | Add short "read next in code" links to firmware/App/Bridge teaching pages where useful. |
| Low | Hardware files need stronger legacy/current labeling. | 16n electronics/panel README style. | Audit `hardware/` docs for current, legacy, reference-only, and fabrication-ready labels. |

## Guardrails

- Do not turn MN42 into a generic controller platform.
- Do not make the docs look more release-ready than the evidence supports.
- Do not hide bench receipts, caveats, or release blockers to make the site cleaner.
- Do not merge educational guides until the new index pages have proven insufficient.
- Do not claim fabrication readiness without the required release artifacts.

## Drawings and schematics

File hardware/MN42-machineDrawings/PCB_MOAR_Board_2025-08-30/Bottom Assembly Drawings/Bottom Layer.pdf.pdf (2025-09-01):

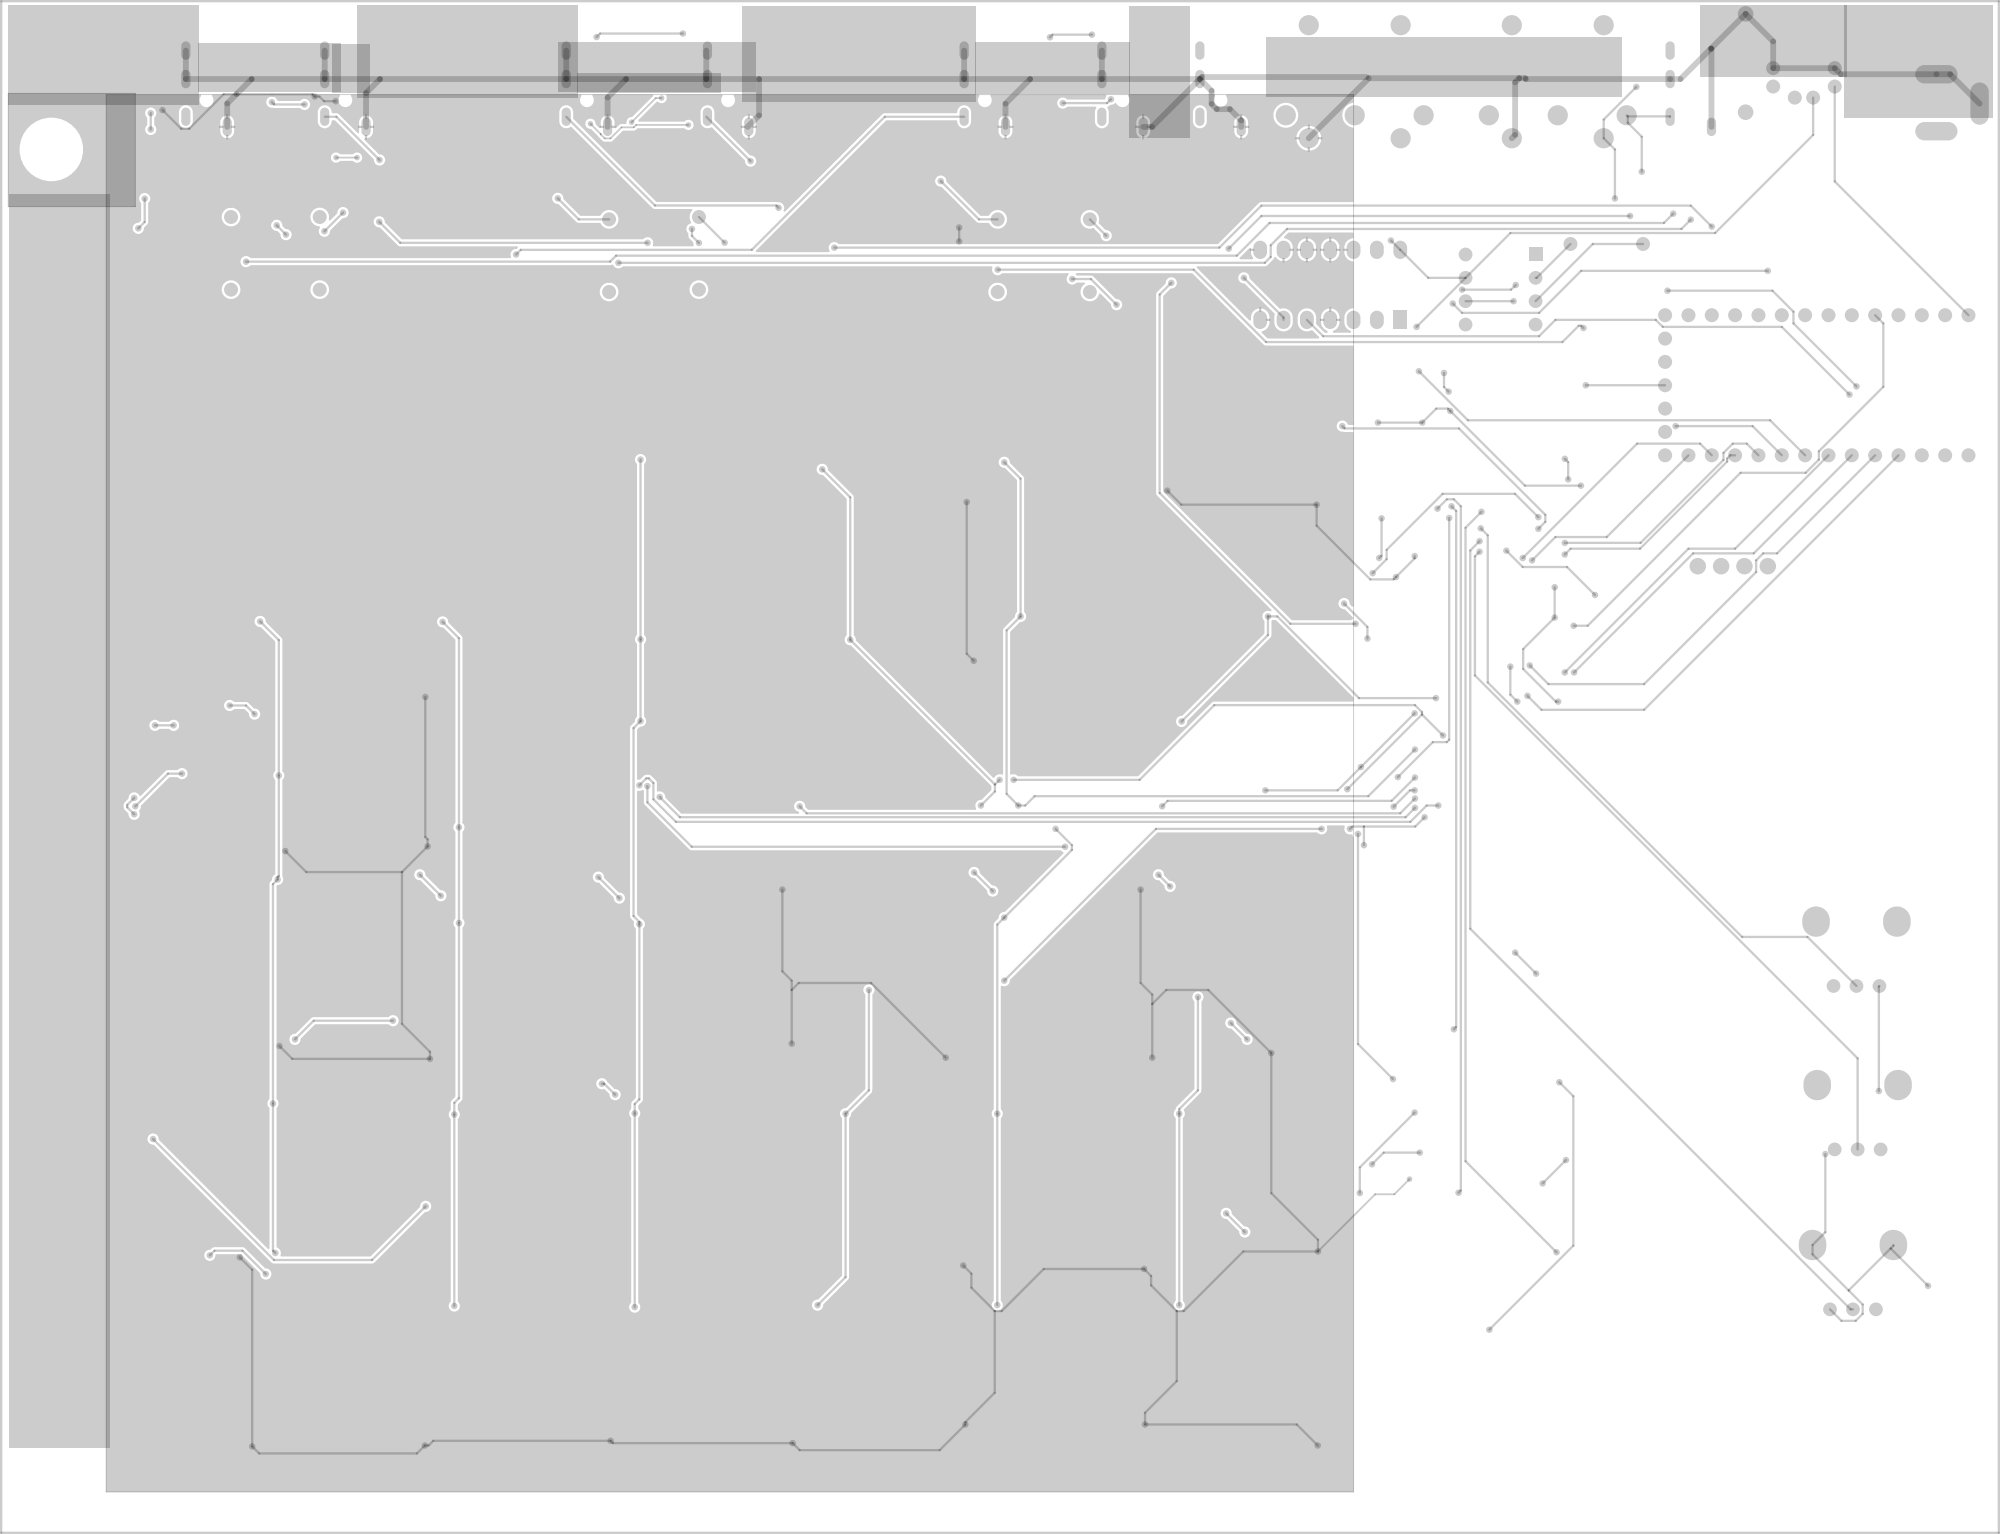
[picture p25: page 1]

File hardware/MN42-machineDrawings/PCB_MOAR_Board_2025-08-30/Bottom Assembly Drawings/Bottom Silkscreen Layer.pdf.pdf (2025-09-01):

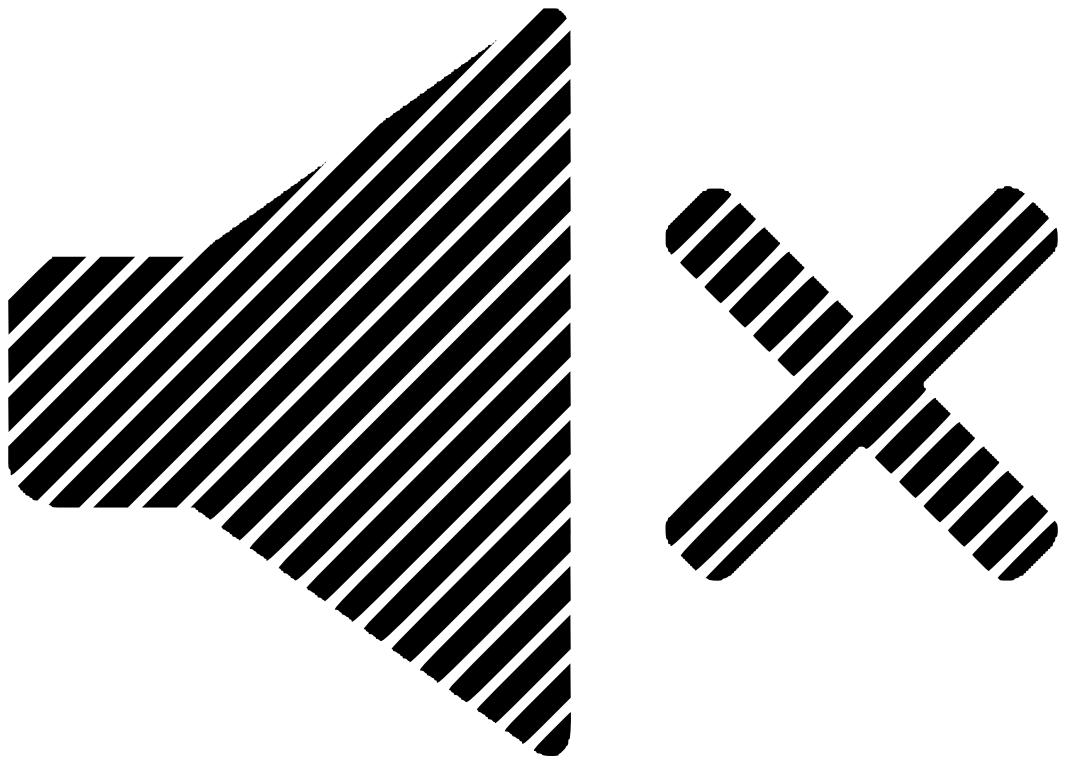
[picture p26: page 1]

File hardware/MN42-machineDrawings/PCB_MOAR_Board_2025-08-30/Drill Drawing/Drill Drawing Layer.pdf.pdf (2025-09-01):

# FOLLOW

ME

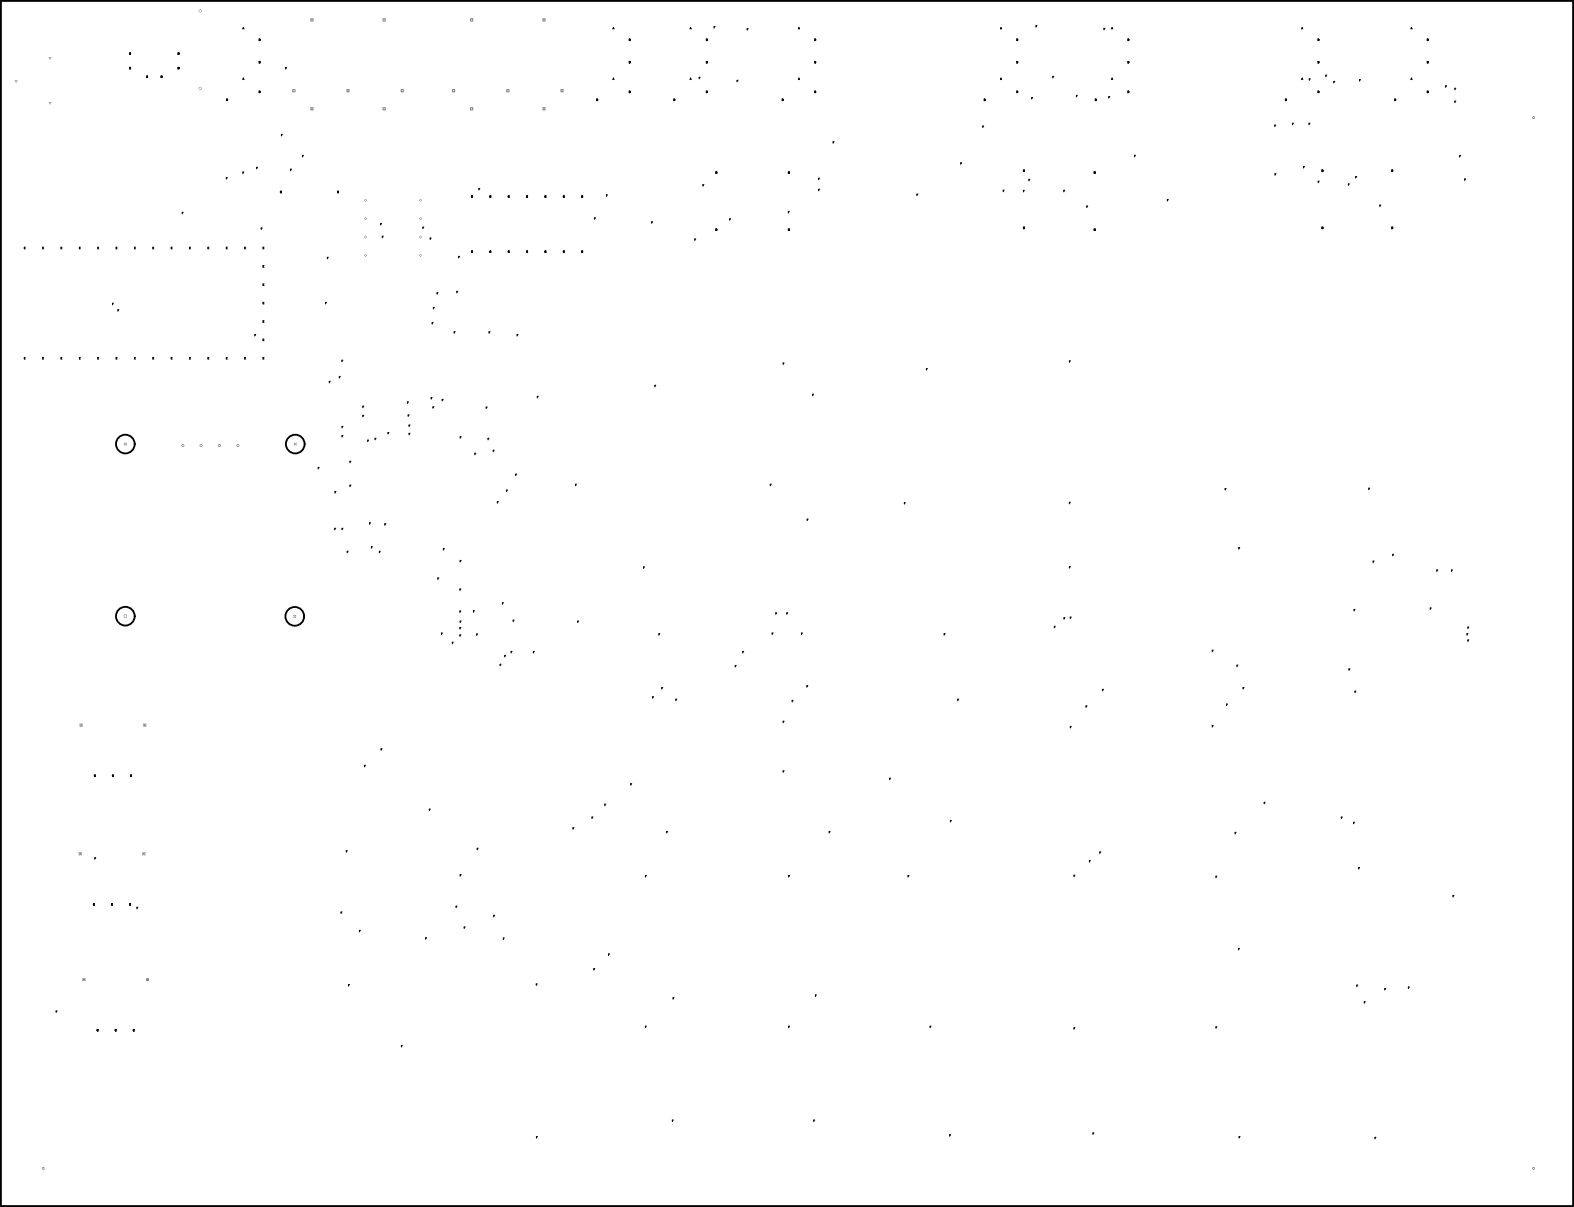
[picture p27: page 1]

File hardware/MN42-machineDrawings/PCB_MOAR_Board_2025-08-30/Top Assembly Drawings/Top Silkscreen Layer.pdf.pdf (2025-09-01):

# FOLLOW

ME

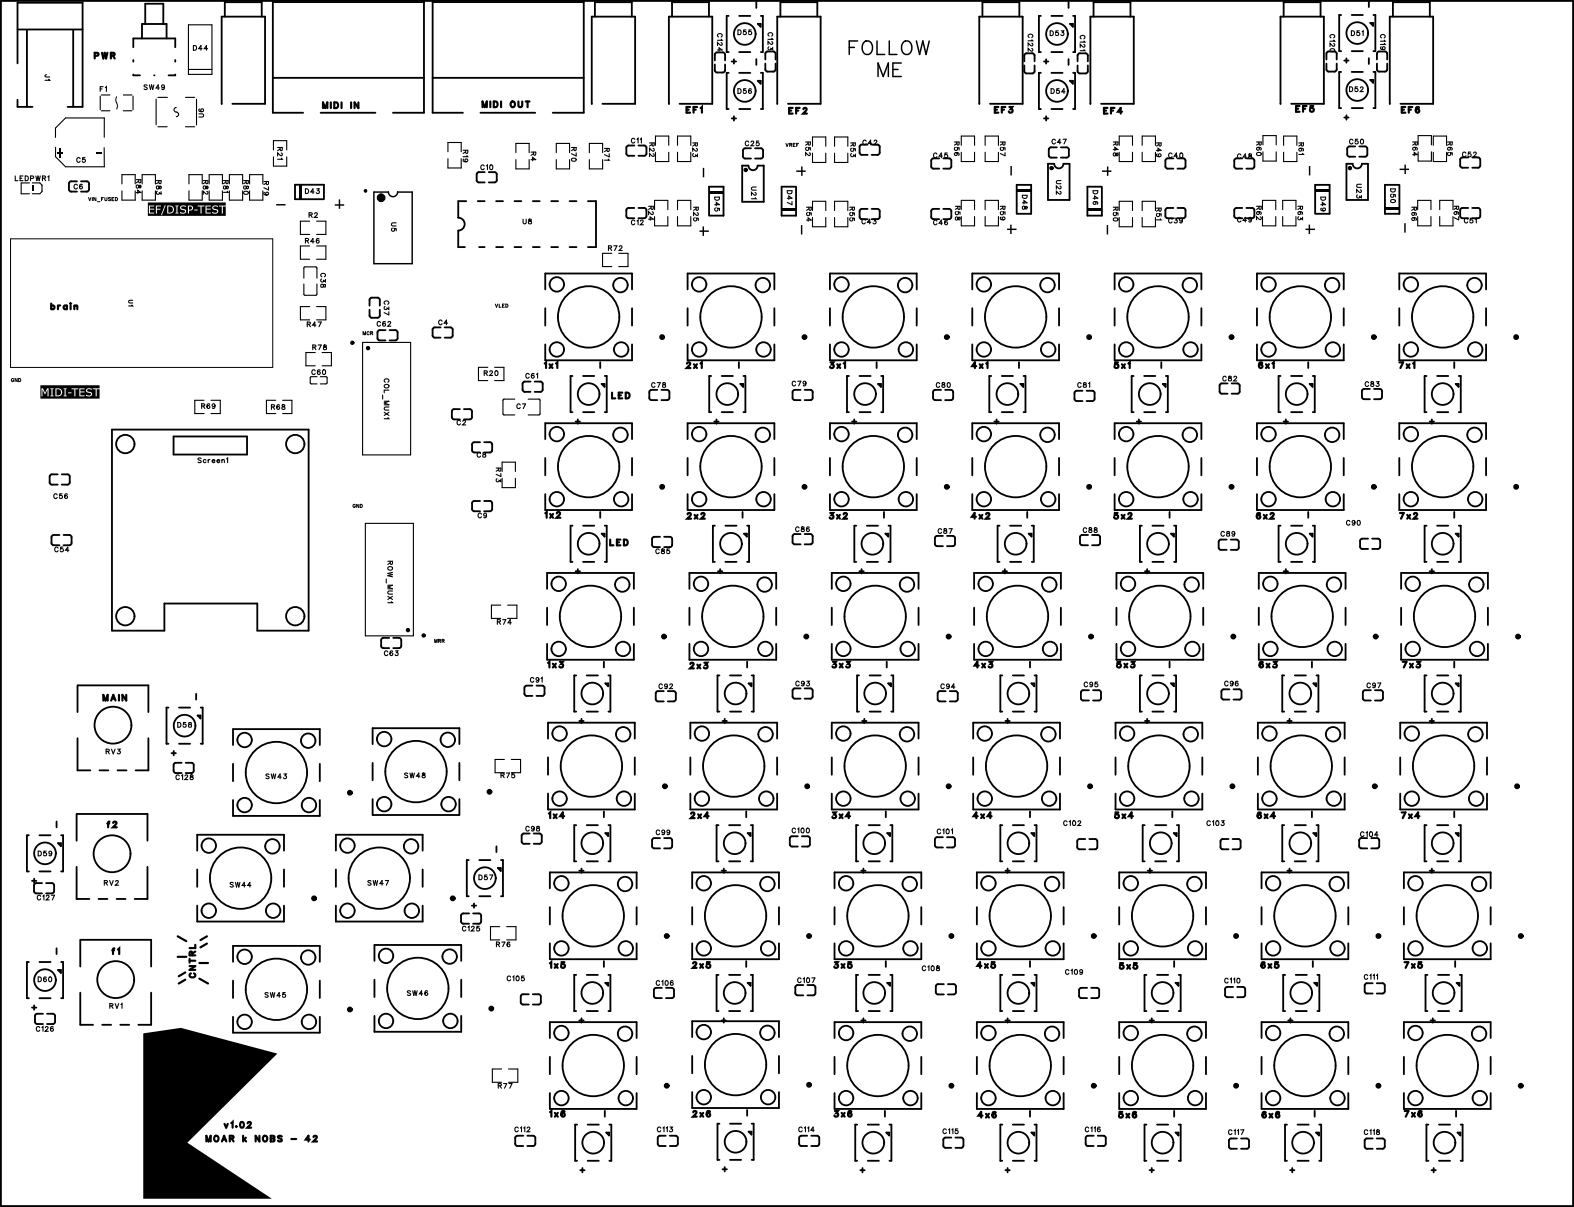
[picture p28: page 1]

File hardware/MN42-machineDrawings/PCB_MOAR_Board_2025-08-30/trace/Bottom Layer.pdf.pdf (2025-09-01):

# FOLLOW

ME

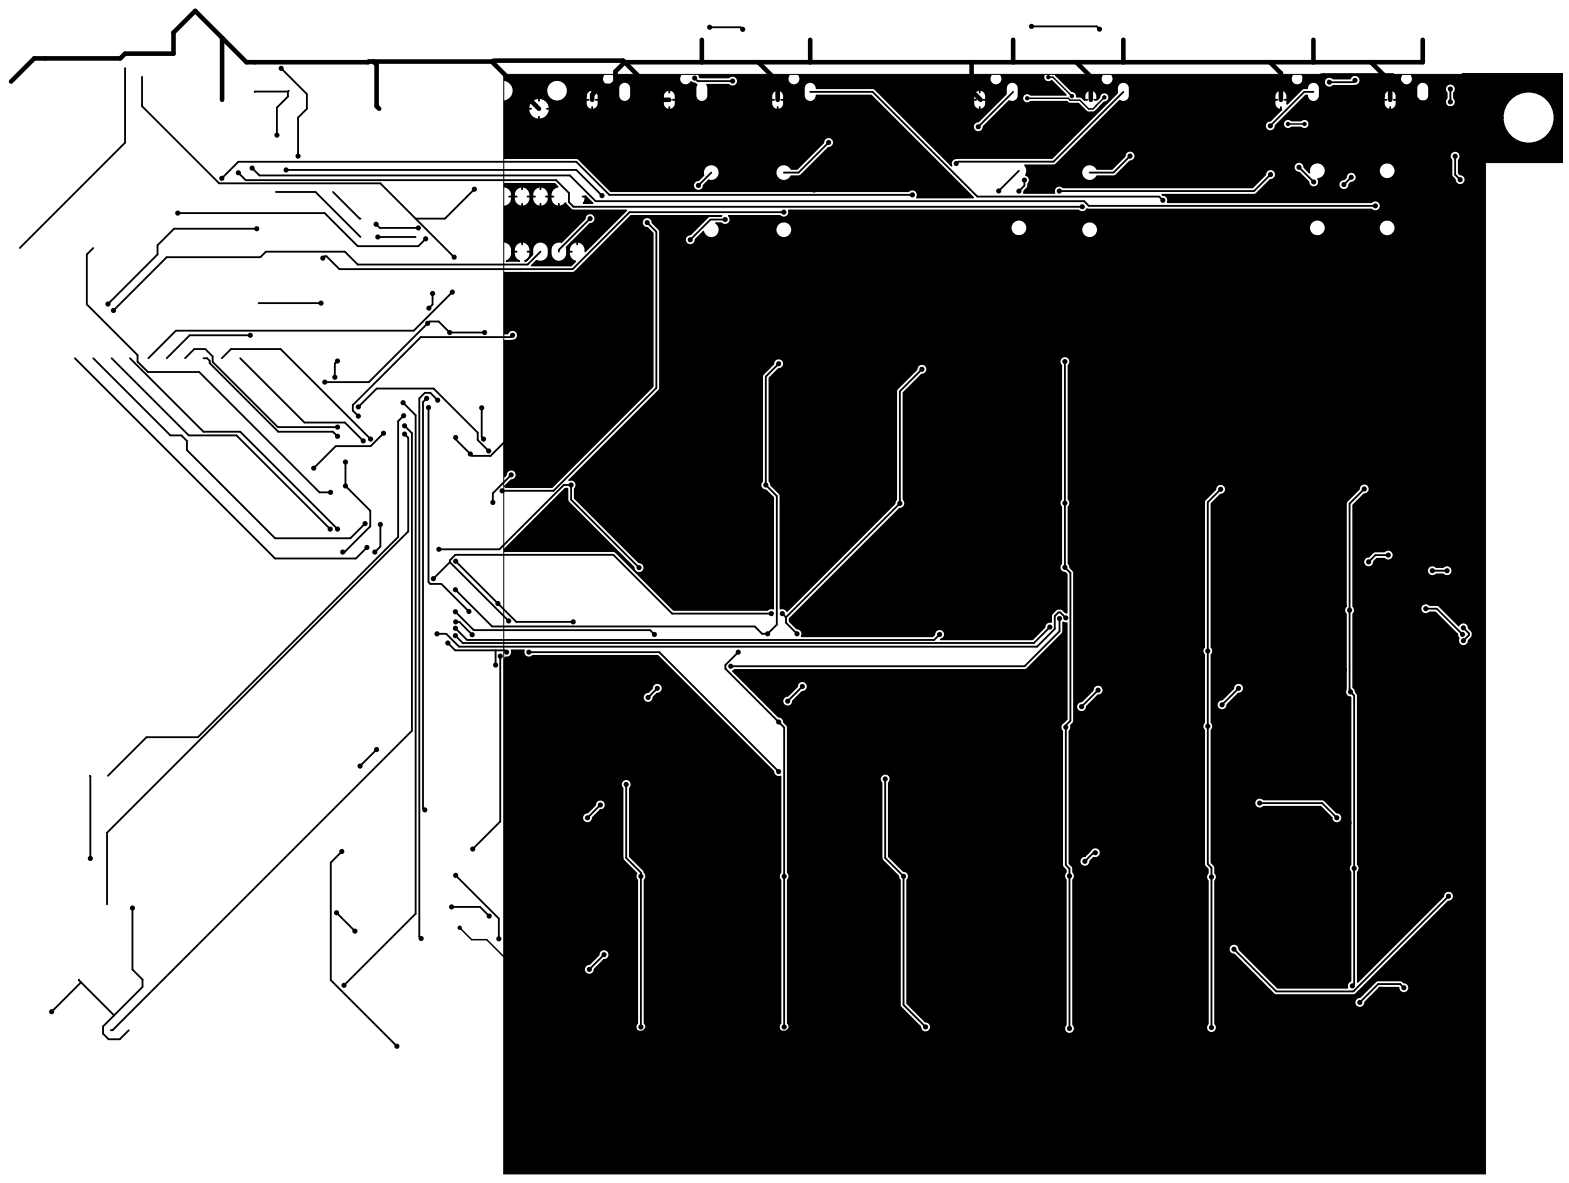
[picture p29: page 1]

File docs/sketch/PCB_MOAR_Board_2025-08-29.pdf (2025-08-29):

# FOLLOW

ME

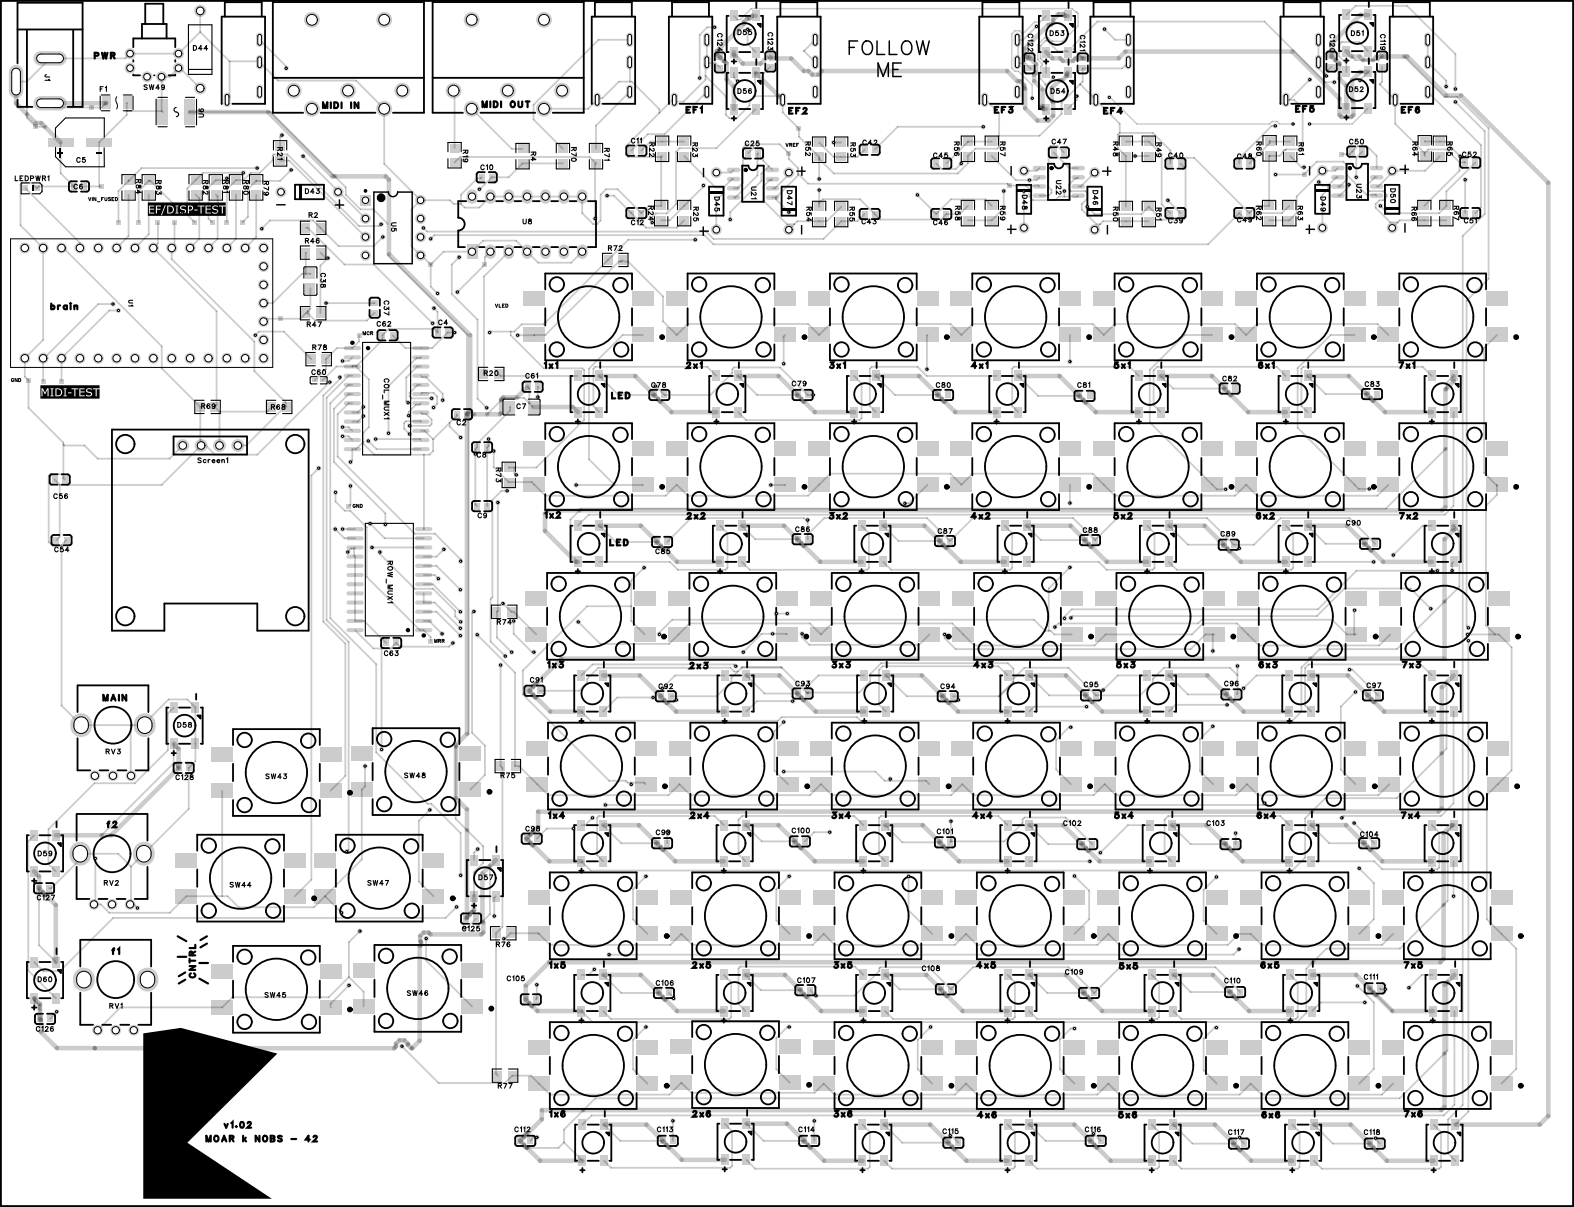
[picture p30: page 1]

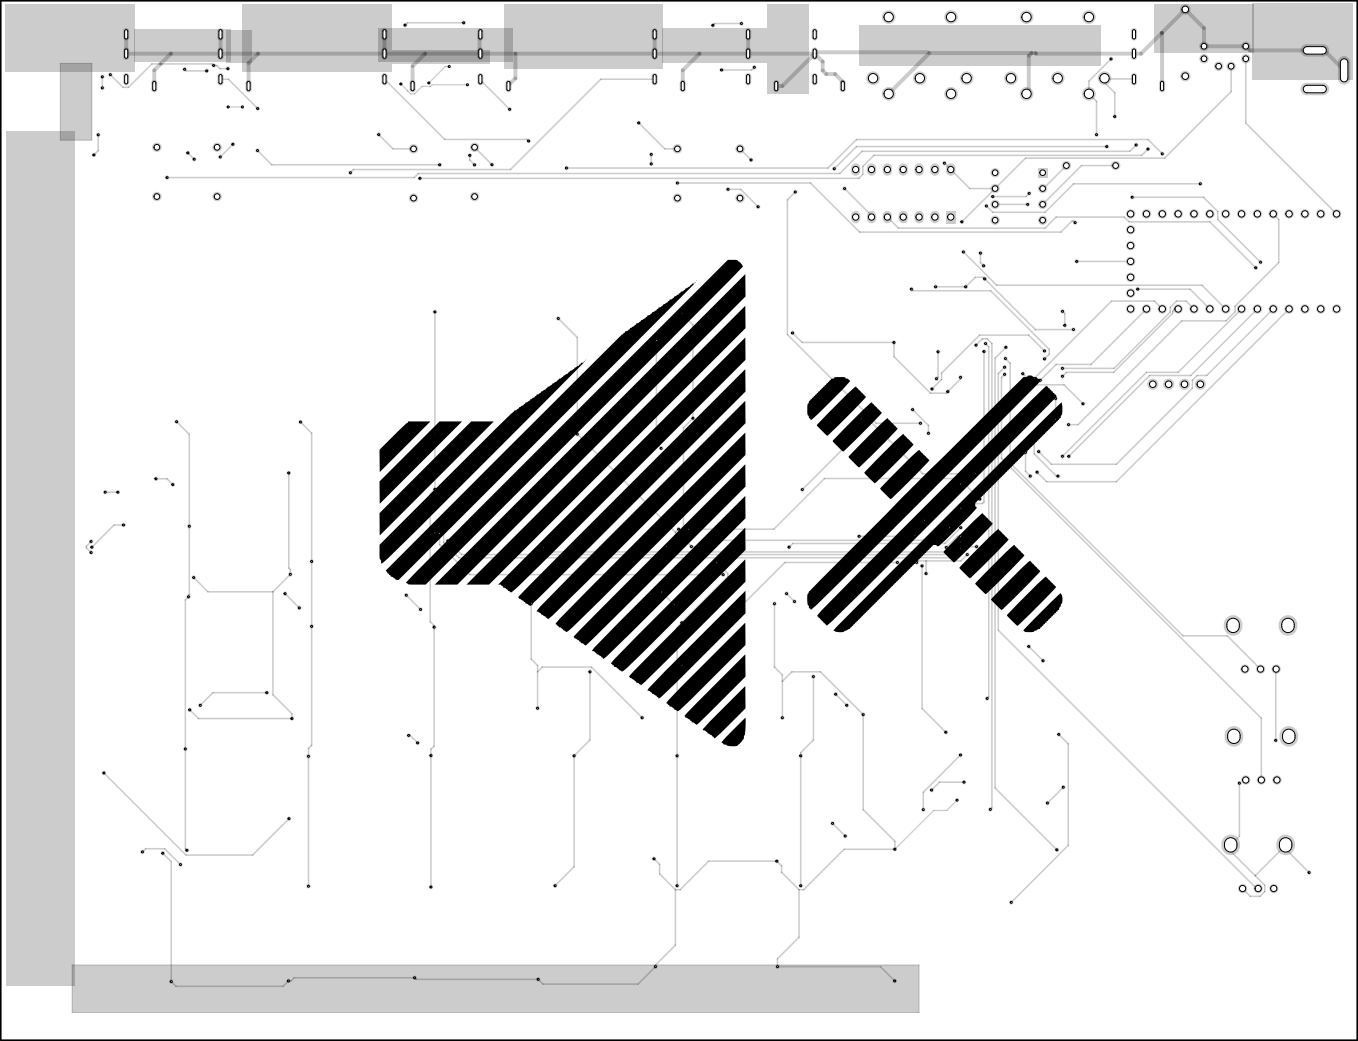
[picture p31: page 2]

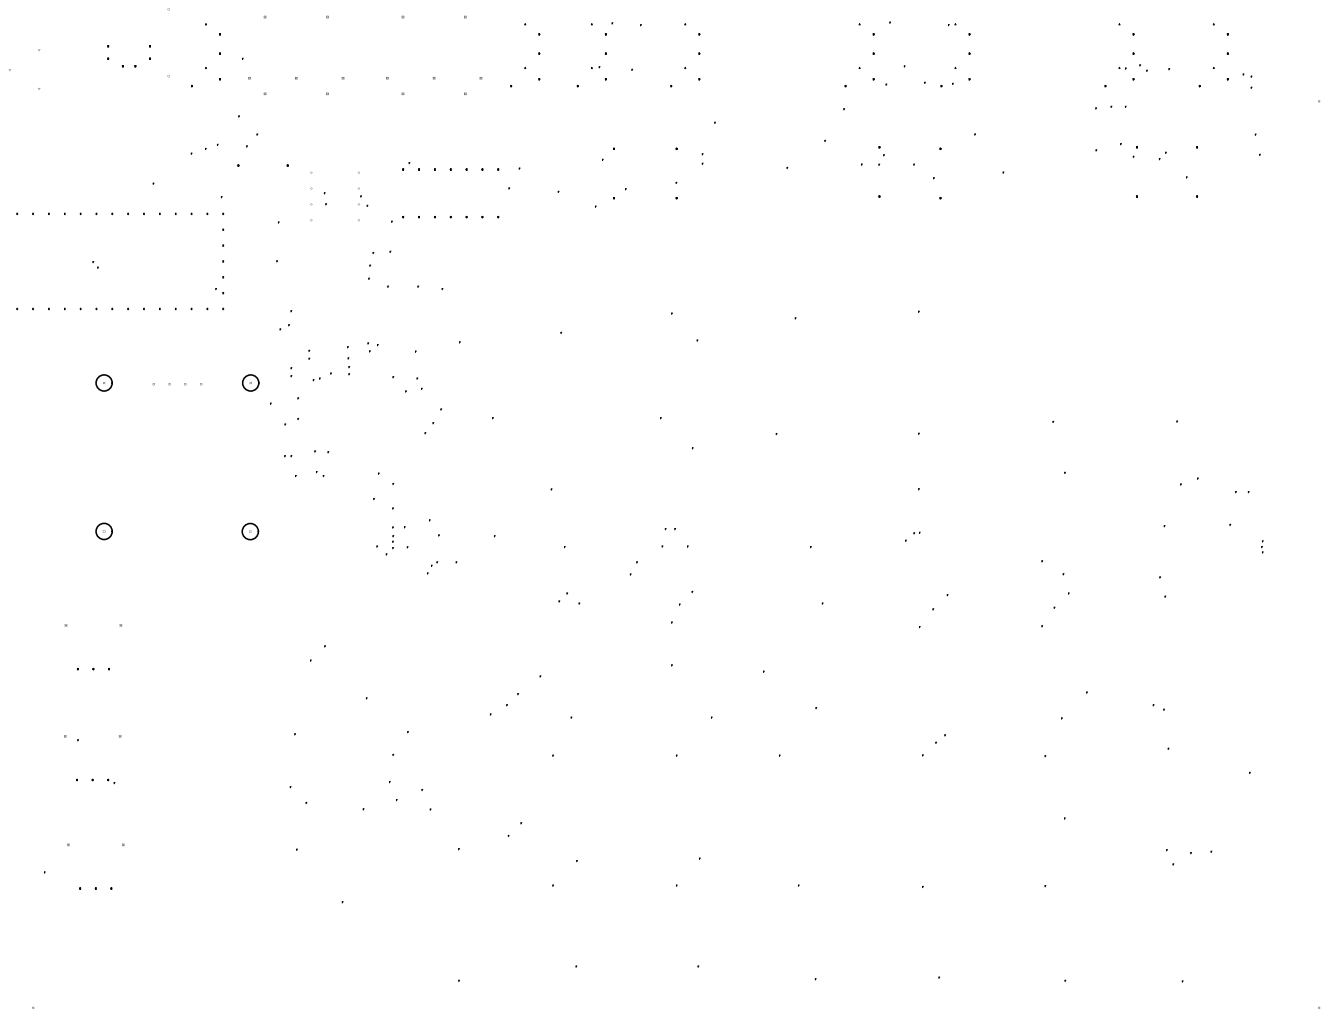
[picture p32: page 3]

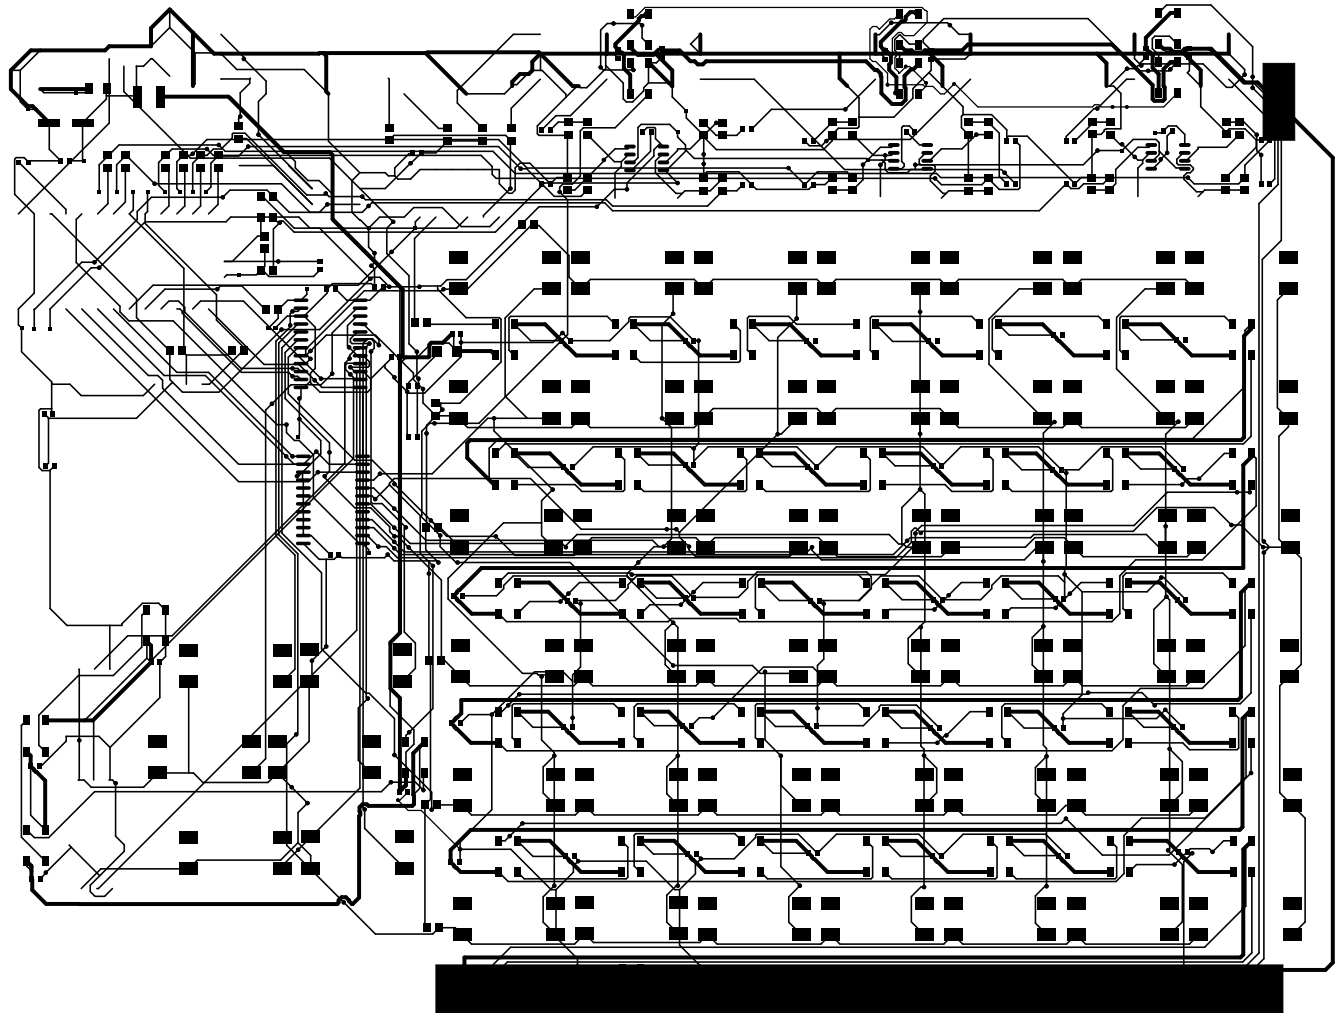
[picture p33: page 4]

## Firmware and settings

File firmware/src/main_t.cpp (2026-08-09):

/*
MOARkNOBS Hardware Smoke Test

Mirrors the production firmware stack: boot sequence, scheduler rhythm,
and per-manager checks happen in order so you can trace the same flow you
teach in `firmware_main.cpp` (protocol → modes → UI → runtime).
Each test phase simply exercises the managers that `FirmwareState.cpp`
keeps alive while the scheduler would normally choreograph their callbacks.

Validates LEDs, the button matrix, one slot pot plus two filter-tuning pots,
envelope followers and the OLED display. Use Control Button #0 to advance
through each phase.

Build and upload with PlatformIO environment `teensy40_full_system`
(e.g. `platformio run -e teensy40_full_system -t upload`).
Requires a Teensy 4.0 wired with the full MOARkNOBS hardware
(button matrix, LED strip, OLED, envelope circuits).

See `firmware/README.md` under "Test Philosophy (and Real Talk)"
for additional context and a list of all available test sketches.
*/

#include <Arduino.h>
#include "Arduino.h"
#include "ButtonManager.h"
#include "DisplayManager.h"
#include "FirmwareState.h"
#include "Globals.h"
#include "LEDManager.h"
#include "LFO/LFOManager.h"
#include "MIDIHandler.h"
#include "Modes.h"
#include "PotentiometerManager.h"
#include "SystemTestShim.h"
#include "TestHelpers.h"

SystemTestSummary runSystemTests();

namespace {
const CRGB kBringUpLedTestColor = CRGB::Green;
constexpr unsigned long kControlSuiteTimeoutMs = 20000;

void showBringUpLed(uint16_t index) {
    ledManager.setColor(CRGB::Black);
    ledManager.setPixelColor(index, kBringUpLedTestColor);
    ledManager.update();
    delay(50);
}

const char *configSlotTypeShortName(MIDIMessageType type) {
    switch (type) {
    case MIDIMessageType::OFF:
        return "OFF";
    case MIDIMessageType::CC:
        return "CC";
    case MIDIMessageType::Note:
        return "NOTE";
    case MIDIMessageType::PitchBend:
        return "BEND";
    case MIDIMessageType::ProgramChange:
        return "PROG";
    case MIDIMessageType::Aftertouch:
        return "AFT";
    case MIDIMessageType::ModWheel:
        return "MOD";
    case MIDIMessageType::NRPN:
        return "NRPN";
    case MIDIMessageType::RPN:
        return "RPN";
    case MIDIMessageType::SysEx:
        return "SYX";
    }
    return "?";
}

const char *syncRatioLabel(LFOSyncRatio ratio) {
    switch (ratio) {
    case LFOSyncRatio::Div1:
        return "1/1";
    case LFOSyncRatio::Div2:
        return "1/2";
    case LFOSyncRatio::Div4:
        return "1/4";
    case LFOSyncRatio::Div8:
        return "1/8";
    case LFOSyncRatio::Div16:
        return "1/16";
    case LFOSyncRatio::Div32:
        return "1/32";
    case LFOSyncRatio::Mul2:
        return "x2";
    case LFOSyncRatio::Mul4:
        return "x4";
    }
    return "?";
}

const char *lfoShapeShortLabel(LFOShape shape) {
    switch (shape) {
    case LFOShape::Sine:
        return "SIN";
    case LFOShape::Triangle:
        return "TRI";
    case LFOShape::Saw:
        return "SAW";
    case LFOShape::Square:
        return "SQR";
    case LFOShape::SampleHold:
        return "S&H";
    case LFOShape::RandomSlew:
        return "RSL";
    }
    return "?";
}

const char *lfoTargetShortLabel(LFOInternalTarget target) {
    switch (target) {
    case LFOInternalTarget::EfGainTrim:
        return "EFG";
    case LFOInternalTarget::ArpSwing:
        return "ARS";
    case LFOInternalTarget::VelocityShift:
        return "VEL";
    case LFOInternalTarget::NoteChance:
        return "CHN";
    case LFOInternalTarget::ArpGate:
        return "GAT";
    case LFOInternalTarget::JitterDepth:
        return "JDP";
    case LFOInternalTarget::JitterSmoothness:
        return "JSM";
    }
    return "?";
}

bool activeInternalTargetForLfo(uint8_t lfoIndex, LFOInternalTarget &targetOut) {
    const size_t count = lfoManager.routeCount();
    LFOManager::Route route{};
    for (size_t i = 0; i < count; ++i) {
        if (!lfoManager.getRoute(i, route)) {
            continue;
        }
        if (route.type == LFOManager::Route::Type::Internal && route.lfoIndex == lfoIndex) {
            targetOut = route.target;
            return true;
        }
    }
    return false;
}

void drawInstruction(const char *line1, const char *line2, const char *line3) {
    displayManager.beginDraw();
    displayManager.drawText(line1, line2, line3);
    displayManager.endDraw();
}

void drawOnDeviceConfigView() {
    const uint8_t slotIndex = activePot;
    const MIDISlot &slot = configManager.getSlot(slotIndex);
    const uint8_t channel = configManager.getPotChannel(slotIndex);
    uint8_t data1 = configManager.getPotCCNumber(slotIndex);
    if (slot.type == MIDIMessageType::NRPN || slot.type == MIDIMessageType::RPN) {
        data1 = configManager.getSlotData1(slotIndex);
    }

    char line1[20];
    char line2[24];
    snprintf(line1, sizeof(line1), "Cfg Slot %u", slotIndex);
    snprintf(line2, sizeof(line2), "%s Ch%u D1%u", configSlotTypeShortName(slot.type), channel,
             data1);

    displayManager.beginDraw();
    displayManager.drawText(line1, line2, "C5 Exit+Save");
    displayManager.endDraw();
}

void drawLfoTuningView() {
    const uint8_t index = buttonManager.lfoTuningIndex() % LFOManager::kMaxLFOs;
    const LFO &lfo = lfoManager.lfo(index);
    LFOInternalTarget target = LFOInternalTarget::EfGainTrim;
    const bool hasTarget = activeInternalTargetForLfo(index, target);

    char line1[20];
    char line2[24];
    char line3[24];
    snprintf(line1, sizeof(line1), "LFO%u T:%s", static_cast<unsigned>(index + 1),
             hasTarget ? lfoTargetShortLabel(target) : "NONE");
    snprintf(line2, sizeof(line2), "%s D%.2f", lfoShapeShortLabel(lfo.getShape()), lfo.getDepth());
    if (lfo.isSyncEnabled()) {
        snprintf(line3, sizeof(line3), "SYNC %s %s", syncRatioLabel(lfo.getSyncRatio()),
                 lfo.isBipolar() ? "BI" : "UNI");
    } else {
        snprintf(line3, sizeof(line3), "HZ %.2f %s", lfo.getFrequencyHz(),
                 lfo.isBipolar() ? "BI" : "UNI");
    }

    displayManager.beginDraw();
    displayManager.drawText(line1, line2, line3);
    displayManager.endDraw();
}

void serviceControlSuiteUi() {
    buttonManager.processButtons(buttonContext);
    if (buttonManager.isOnDeviceConfigModeActive()) {
        drawOnDeviceConfigView();
    } else if (buttonManager.isLfoTuningModeActive()) {
        drawLfoTuningView();
    }
    delay(2);
}
} // namespace

// Control button used to advance test phases
const uint8_t phaseButtonPin = 12; // Control Button #0

// Ordered test phases
enum class TestPhase { IDLE, LEDS, BUTTONS, POTS, ENVELOPES, CONTROL, DISP, SYSTEM, COMPLETE };
TestPhase currentPhase = TestPhase::IDLE;
bool phaseStarted = false;

// --- Utility ---
// Wait for Control Button #0 to be pressed and released.
void waitForButtonPress(const char *prompt = "Press Btn0 to continue") {
    Serial.println(prompt);
    displayManager.showText(prompt, "", "Btn0");
    while (digitalRead(phaseButtonPin))
        ; // wait press (active LOW)
    while (!digitalRead(phaseButtonPin))
        ; // wait release
    delay(50);
}

// --- Unit Tests ---
// Cycle each LED cluster and make sure FastLED actually spits bits.
// We don't block on every single diode; instead we run a sweep and ask the
// human if the glow looked good.  Punk rock hardware testing, basically.
void testLEDManager() {
    Serial.println("\n--- LEDManager Test ---");
    const uint8_t previousBrightness = ledManager.getBrightness();
    ledManager.setBrightness(MN42_SAFE_BENCH_LED_BRIGHTNESS);

    // --- Slot LEDs ---
    for (int i = 0; i < SLOT_LED_COUNT; i++) {
        showBringUpLed(static_cast<uint16_t>(i));
    }
    waitForButtonPress("Slots glow in order? Btn0");

    // --- Envelope follower LEDs ---
    for (int i = 0; i < EF_LED_COUNT; i++) {
        showBringUpLed(static_cast<uint16_t>(EF_LED_OFFSET() + i));
    }
    waitForButtonPress("Followers shine? Btn0");

    // --- Control button LED ---
    showBringUpLed(CONTROL_LED_INDEX());
    waitForButtonPress("Control LED pop? Btn0");

    // --- Pot halo LEDs ---
    for (int i = 0; i < POT_LED_COUNT; i++) {
        showBringUpLed(static_cast<uint16_t>(POT_LED_OFFSET() + i));
    }
    waitForButtonPress("Halos look righteous? Btn0");

    ledManager.setColor(CRGB::Black);
    ledManager.update();
    ledManager.setBrightness(previousBrightness);
    Serial.println("LEDManager test done.");
}

void testButtonManager() {
    Serial.println("\n--- ButtonManager Test ---");
    Serial.println("Press each virtual button (mux matrix) when prompted.");
    for (int b = 0; b < NUM_VIRTUAL_BUTTONS; b++) {
        Serial.printf("Press Virtual Button #%d...\n", b);
        while (!buttonManager.isMuxButtonPressed(b))
            ;
        Serial.printf("Button #%d OK!\n", b);
        delay(200);
    }

    Serial.println("Press each physical control button now.");
    // Pin 6 reserved for LED strip
    for (int i = 0; i < NUM_CONTROL_BUTTONS; i++) {
        Serial.printf("Press Control Button #%d (pin %d)...\n", i, TEST_CONTROL_PINS[i]);
        while (digitalRead(TEST_CONTROL_PINS[i]))
            ;
        Serial.printf("Control Button #%d OK!\n", i);
        delay(200);
    }
    Serial.println("ButtonManager test done.");
}

// Checks the lone slot pot plus the two filter-tuning rebels.
void testPotentiometerManager() {
    Serial.println("\n--- PotentiometerManager Test ---");

    // --- Slot pot -----------------------------------------------------------
    Serial.println("Slot Pot: crank to MIN, hit Btn0.");
    waitForButtonPress();
    int slotMin = potentiometerManager.readRawPot(0);

    Serial.println("Slot Pot: now twist to MAX, hit Btn0.");
    waitForButtonPress();
    int slotMax = potentiometerManager.readRawPot(0);

    int slotDelta = slotMax - slotMin;
    bool slotPass = slotDelta >= POT_RANGE_MIN;
    Serial.printf("Slot Pot sweep: MIN=%d MAX=%d Δ=%d [%s]\n", slotMin, slotMax, slotDelta,
                  slotPass ? "PASS" : "FAIL");

    // --- Filter frequency pot ----------------------------------------------
    Serial.println("Filter Freq: roll to MIN, Btn0.");
    waitForButtonPress();
    int freqMin = buttonManager.getControlPotValue(1);

    Serial.println("Filter Freq: peg it to MAX, Btn0.");
    waitForButtonPress();
    int freqMax = buttonManager.getControlPotValue(1);

    int freqDelta = freqMax - freqMin;
    bool freqPass = freqDelta >= POT_RANGE_MIN;
    Serial.printf("Filter Freq sweep: MIN=%d MAX=%d Δ=%d [%s]\n", freqMin, freqMax, freqDelta,
                  freqPass ? "PASS" : "FAIL");

    // --- Filter resonance/Q pot --------------------------------------------
    Serial.println("Filter Q: dive to MIN, Btn0.");
    waitForButtonPress();
    int qMin = buttonManager.getControlPotValue(2);

    Serial.println("Filter Q: hammer to MAX, Btn0.");
    waitForButtonPress();
    int qMax = buttonManager.getControlPotValue(2);

    int qDelta = qMax - qMin;
    bool qPass = qDelta >= POT_RANGE_MIN;
    Serial.printf("Filter Q sweep: MIN=%d MAX=%d Δ=%d [%s]\n", qMin, qMax, qDelta,
                  qPass ? "PASS" : "FAIL");

    Serial.println("PotentiometerManager test done.");
}

void testFilterPots() {
    Serial.println("\n--- Filter Pot Test ---");
    Serial.println("Sweep Freq & Q pots then press Btn0.");
    float minFreq = 1e6, maxFreq = 0;
    float minQ = 10, maxQ = 0;
    while (digitalRead(phaseButtonPin)) {
        int rawFreq = buttonManager.getControlPotValue(1);
        int rawQ = buttonManager.getControlPotValue(2);
        float freq = map(rawFreq, 0, 1023, 20, 5000);
        float q = map(rawQ, 0, 1023, 50, 400) / 100.0f;
        if (freq < minFreq)
            minFreq = freq;
        if (freq > maxFreq)
            maxFreq = freq;
        if (q < minQ)
            minQ = q;
        if (q > maxQ)
            maxQ = q;
        displayManager.showFilterTuning("Freq", freq, "Q", q);
        Serial.printf("Freq=%.1f Hz Q=%.2f\n", freq, q);
        delay(100);
    }
    while (!digitalRead(phaseButtonPin))
        ;
    bool freqPass = (minFreq <= 30 && maxFreq >= 4900);
    bool qPass = (minQ <= 0.6 && maxQ >= 3.9);
    Serial.printf("Freq range: %.1f-%.1f Hz [%s]\n", minFreq, maxFreq, freqPass ? "PASS" : "FAIL");
    Serial.printf("Q range: %.1f-%.1f [%s]\n", minQ, maxQ, qPass ? "PASS" : "FAIL");
    char line1[32], line2[32];
    snprintf(line1, sizeof(line1), "F %.0f-%.0f %s", minFreq, maxFreq, freqPass ? "OK" : "BAD");
    snprintf(line2, sizeof(line2), "Q %.1f-%.1f %s", minQ, maxQ, qPass ? "OK" : "BAD");
    displayManager.showText("Filter Pots", line1, line2);
    delay(1000);
    displayManager.clear();
}

void testEnvelopeFollowers() {
    Serial.println("\n--- EnvelopeFollower Test ---");
    int pins[] = {A0, A1, A2, A3, A6, A7};
    for (size_t i = 0; i < envelopeFollowers.size(); i++) {
        Serial.printf("Envelope #%d (Pin A%d): MIN input, Btn0.\n", i, pins[i]);
        waitForButtonPress();
        envelopeFollowers[i].update();
        int vmin = envelopeFollowers[i].getEnvelopeLevel();

        Serial.printf("Envelope #%d (Pin A%d): MAX input, Btn0.\n", i, pins[i]);
        waitForButtonPress();
        envelopeFollowers[i].update();
        int vmax = envelopeFollowers[i].getEnvelopeLevel();

        int delta = vmax - vmin;
        bool pass = delta >= ENV_RANGE_MIN;
        Serial.printf("Envelope #%d range: MIN=%d MAX=%d Δ=%d [%s]\n", i, vmin, vmax, delta,
                      pass ? "PASS" : "FAIL");
    }
    Serial.println("EnvelopeFollower test done.");
}

void testControlSuite() {
    Serial.println("\n--- On-Board Control Suite Test ---");
    Serial.println("Validates config mode, clock source toggle, and LFO quick-tune mode.");

    const uint8_t slotBefore = activePot;
    const uint8_t ccBefore = configManager.getPotCCNumber(slotBefore);
    const bool clockFollowBefore = g_followExternalClock;
    bool configEntered = false;
    bool configEdited = false;
    bool configExited = false;
    bool clockToggled = false;
    bool lfoEntered = false;
    bool lfoTargetCycled = false;
    bool lfoExited = false;

    profileRuntimeRequests.clear();

    drawInstruction("Control Suite", "Ctrl0+2+3+5", "Enter Config");
    unsigned long deadline = millis() + kControlSuiteTimeoutMs;
    while (millis() < deadline) {
        serviceControlSuiteUi();
        if (buttonManager.isOnDeviceConfigModeActive()) {
            configEntered = true;
            break;
        }
    }
    Serial.printf("Config mode enter: %s\n", configEntered ? "PASS" : "FAIL");

    if (configEntered) {
        waitForButtonPress("OLED shows Config view? Btn0");

        drawInstruction("Config Edit", "Tap Ctrl4", "Change CC/D1");
        deadline = millis() + kControlSuiteTimeoutMs;
        while (millis() < deadline) {
            serviceControlSuiteUi();
            const uint8_t ccNow = configManager.getPotCCNumber(activePot);
            if (ccNow != ccBefore) {
                configEdited = true;
                break;
            }
        }
        Serial.printf("Config edit detected: %s\n", configEdited ? "PASS" : "FAIL");

        drawInstruction("Config Exit", "Tap Ctrl5", "Exit+Save");
        deadline = millis() + kControlSuiteTimeoutMs;
        while (millis() < deadline) {
            serviceControlSuiteUi();
            if (!buttonManager.isOnDeviceConfigModeActive()) {
                configExited = true;
                break;
            }
        }
        Serial.printf("Config mode exit: %s\n", configExited ? "PASS" : "FAIL");
        Serial.printf("Config autosave request: %s\n",
                      (configEdited && profileRuntimeRequests.savePending()) ? "PASS" : "FAIL");
    }

    drawInstruction("Clock Source", "Ctrl1+4+5", "Toggle source");
    deadline = millis() + kControlSuiteTimeoutMs;
    while (millis() < deadline) {
        serviceControlSuiteUi();
        if (g_followExternalClock != clockFollowBefore) {
            clockToggled = true;
            break;
        }
    }
    Serial.printf("Clock source toggle: %s\n", clockToggled ? "PASS" : "FAIL");

    drawInstruction("LFO Tune", "Ctrl0+1+3", "Enter mode");
    deadline = millis() + kControlSuiteTimeoutMs;
    while (millis() < deadline) {
        serviceControlSuiteUi();
        if (buttonManager.isLfoTuningModeActive()) {
            lfoEntered = true;
            break;
        }
    }
    Serial.printf("LFO mode enter: %s\n", lfoEntered ? "PASS" : "FAIL");

    if (lfoEntered) {
        waitForButtonPress("OLED shows LFO view? Btn0");

        LFOInternalTarget beforeTarget = LFOInternalTarget::EfGainTrim;
        const bool hadTargetBefore =
            activeInternalTargetForLfo(buttonManager.lfoTuningIndex(), beforeTarget);
        drawInstruction("LFO Route", "Tap Ctrl4", "Cycle target");
        deadline = millis() + kControlSuiteTimeoutMs;
        while (millis() < deadline) {
            serviceControlSuiteUi();
            LFOInternalTarget currentTarget = LFOInternalTarget::EfGainTrim;
            if (!activeInternalTargetForLfo(buttonManager.lfoTuningIndex(), currentTarget)) {
                continue;
            }
            if (!hadTargetBefore || currentTarget != beforeTarget) {
                lfoTargetCycled = true;
                break;
            }
        }
        Serial.printf("LFO target cycle: %s\n", lfoTargetCycled ? "PASS" : "FAIL");

        drawInstruction("LFO Exit", "Tap Ctrl5", "Exit tune");
        deadline = millis() + kControlSuiteTimeoutMs;
        while (millis() < deadline) {
            serviceControlSuiteUi();
            if (!buttonManager.isLfoTuningModeActive()) {
                lfoExited = true;
                break;
            }
        }
        Serial.printf("LFO mode exit: %s\n", lfoExited ? "PASS" : "FAIL");
    }

    drawInstruction("Control Suite", "Review Serial", "Btn0 continue");
    waitForButtonPress("Control suite summary reviewed? Btn0");
}

void testDisplayManager() {
    Serial.println("\n--- DisplayManager Test ---");
    displayManager.clear();
    displayManager.showText("Display Test", "Line 2", "Line 3");
    Serial.println("Verify OLED shows 'Display Test', 'Line 2', 'Line 3'. Press Btn0.");
    waitForButtonPress();
    displayManager.clear();
    Serial.println("DisplayManager test done.");
}

void testSystemSuite() {
    Serial.println("\n--- System Test Suite ---");
    displayManager.showText("System Tests", "running...");
    SystemTestSummary summary = runSystemTests();
    char line1[32], line2[32];
    snprintf(line1, sizeof(line1), "Total %u", summary.total);
    snprintf(line2, sizeof(line2), "Fail %u", summary.failed);
    displayManager.showText(summary.failed ? "System FAIL" : "System PASS", line1, line2);
    Serial.printf("System tests: %u total, %u failed\n", summary.total, summary.failed);
    delay(1000);
    displayManager.clear();
}

// --- Setup & Loop ---
void setup() {
    Serial.begin(SERIAL_BAUD);
    while (!Serial)
        ;
    delay(250);
    Serial.println("\n=== MOARkNOBS Unit Test ===");
    Serial.printf("NUM_LEDS=%u SLOT_LED_COUNT=%u EF_LED_COUNT=%u POT_LED_COUNT=%u\n", NUM_LEDS(),
                  hwConfig.slotLedCount, hwConfig.efLedCount, hwConfig.potLedCount);

    configManager.begin(potChannels);
    configManager.loadMIDISlots(&configManager.getSlot(0), NUM_SLOTS);

    midiHandler.begin();
    midiHandler.setDiagnostics(&g_systemDiagnostics);
    midiHandler.setDisplayManager(&displayManager);

    ledManager.begin();
    displayManager.begin();
    potentiometerManager.loadFromEEPROM();
    buttonManager.initButtons();

    pinMode(potMuxAnalogPin, INPUT);
    pinMode(buttonMuxAnalogPin, INPUT);
    pinMode(phaseButtonPin, INPUT_PULLUP);

    Serial.println("\nPress Btn0 to start tests");
    displayManager.showText("Test Mode", "Press Btn0");
}

static const char *phaseName(TestPhase p) {
    switch (p) {
    case TestPhase::LEDS:
        return "LEDs";
    case TestPhase::BUTTONS:
        return "Buttons";
    case TestPhase::POTS:
        return "Pots";
    case TestPhase::ENVELOPES:
        return "Envelopes";
    case TestPhase::CONTROL:
        return "Controls";
    case TestPhase::DISP:
        return "Display";
    case TestPhase::SYSTEM:
        return "System";
    default:
        return "";
    }
}
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
void loop() {
    static bool lastBtn = true;
    bool pressed = digitalRead(phaseButtonPin) == LOW;
    if (pressed && !lastBtn) {
        if (currentPhase == TestPhase::IDLE)
            currentPhase = TestPhase::LEDS;
        else if (currentPhase == TestPhase::SYSTEM)
            currentPhase = TestPhase::COMPLETE;
        else if (currentPhase == TestPhase::COMPLETE)
            currentPhase = TestPhase::IDLE;
        else
            currentPhase = (TestPhase)((int)currentPhase + 1);
        phaseStarted = false;
    }
    lastBtn = pressed;

    if (!phaseStarted) {
        if (currentPhase == TestPhase::IDLE) {
            displayManager.showText("Test Mode", "Press Btn0");
        } else if (currentPhase == TestPhase::COMPLETE) {
            Serial.println("All tests complete");
            displayManager.showText("All tests", "complete", "Btn0 reset");
        } else {
            runPhase(currentPhase);
        }
        phaseStarted = true;
    }
}

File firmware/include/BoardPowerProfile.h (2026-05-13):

#ifndef MN42_BOARD_POWER_PROFILE_H
#define MN42_BOARD_POWER_PROFILE_H

#include <cstdint>

#ifndef POWER_CHOKED_V1
#define POWER_CHOKED_V1 1
#endif

#ifndef SPLIT_RAIL_REWORK
#define SPLIT_RAIL_REWORK 2
#endif

#ifndef MN42_BOARD_POWER_PROFILE
#define MN42_BOARD_POWER_PROFILE POWER_CHOKED_V1
#endif

#if MN42_BOARD_POWER_PROFILE == POWER_CHOKED_V1
#define MN42_BOARD_POWER_PROFILE_NAME "POWER_CHOKED_V1"
#define MN42_BOARD_POWER_PROFILE_RAIL_TOPOLOGY_VERIFIED false
#ifndef MN42_LED_BRIGHTNESS_CAP_VALUE
#define MN42_LED_BRIGHTNESS_CAP_VALUE 26
#endif
#ifndef MN42_SAFE_BENCH_LED_BRIGHTNESS_VALUE
#define MN42_SAFE_BENCH_LED_BRIGHTNESS_VALUE 26
#endif
#ifndef MN42_DEFAULT_LED_BRIGHTNESS_VALUE
#define MN42_DEFAULT_LED_BRIGHTNESS_VALUE 26
#endif
#ifndef MN42_DEMO_LED_BRIGHTNESS_VALUE
#define MN42_DEMO_LED_BRIGHTNESS_VALUE 26
#endif
#elif MN42_BOARD_POWER_PROFILE == SPLIT_RAIL_REWORK
#define MN42_BOARD_POWER_PROFILE_NAME "SPLIT_RAIL_REWORK"
#define MN42_BOARD_POWER_PROFILE_RAIL_TOPOLOGY_VERIFIED true
#ifndef MN42_LED_BRIGHTNESS_CAP_VALUE
#define MN42_LED_BRIGHTNESS_CAP_VALUE 255
#endif
#ifndef MN42_SAFE_BENCH_LED_BRIGHTNESS_VALUE
#define MN42_SAFE_BENCH_LED_BRIGHTNESS_VALUE 64
#endif
#ifndef MN42_DEFAULT_LED_BRIGHTNESS_VALUE
#define MN42_DEFAULT_LED_BRIGHTNESS_VALUE 64
#endif
#ifndef MN42_DEMO_LED_BRIGHTNESS_VALUE
#define MN42_DEMO_LED_BRIGHTNESS_VALUE 96
#endif
#else
#error "Unsupported MN42_BOARD_POWER_PROFILE. Use POWER_CHOKED_V1 or SPLIT_RAIL_REWORK."
#endif

namespace BoardPowerProfile {
inline constexpr char kName[] = MN42_BOARD_POWER_PROFILE_NAME;
inline constexpr uint8_t kLedBrightnessCap = MN42_LED_BRIGHTNESS_CAP_VALUE;
inline constexpr uint8_t kSafeBenchLedBrightness = MN42_SAFE_BENCH_LED_BRIGHTNESS_VALUE;
inline constexpr uint8_t kDefaultLedBrightness = MN42_DEFAULT_LED_BRIGHTNESS_VALUE;
inline constexpr uint8_t kDemoLedBrightness = MN42_DEMO_LED_BRIGHTNESS_VALUE;
inline constexpr bool kRailTopologyVerified = MN42_BOARD_POWER_PROFILE_RAIL_TOPOLOGY_VERIFIED;
} // namespace BoardPowerProfile

#endif // MN42_BOARD_POWER_PROFILE_H

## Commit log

2025-08-13 test: tame usb midi stub and wire arpeggiator
2025-08-13 Stub usbMIDI before Arduino to fix unit tests
2025-08-13 Fence off teensy usb_midi with build flag alias
2025-08-13 Mute Teensy sign-compare noise
2025-08-13 Fix teensy unity USB type
2025-08-13 ci: skip board during unity tests
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2025-08-16 fix: cut sensor ties from FastLED UI
2025-08-16 fix: drop last FastLED button ghosts
2025-08-17 Hardware: v2
    Traces finalized. 25mm Rail for LEDpwr. Ground pool under EF inputs
    [3DShell_3DShell_MOAR_Board_B.obj, 3DShell_3DShell_MOAR_Board_T.obj, 3DShell_3DShell_btnBRD_B.step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]
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2025-08-22 chore(bridge): herd missing-port test into test pen
    Relocate test_missing_port.js into test/ and wire package.json test script to run it via node test/test_missing_port.js.
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2025-08-22 Decode reset cause in banner and print system report
2025-08-22 Allow diagnostic to check buttons on const manager
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2025-08-23 docs: fix power protection mermaid style
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2025-08-24 diagram/hardware finalize
    Set for through-hole build -> SMD next
    [Drill_NPTH_Through.DRL, Drill_PTH_Through.DRL, Drill_PTH_Through_Via.DRL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]
2025-08-24 bridge: wire cmd validation test into npm test
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2025-08-26 Reset Biquad filter state on reconfigure
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2025-08-27 surface mount board
    [Drill_NPTH_Through.DRL, Drill_PTH_Through.DRL, Drill_PTH_Through_Via.DRL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]
2025-08-29 finalizing smd arch
    [BOM_MOAR_MOAR_Board_2025-08-28.xlsx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]
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2025-08-29 busio: fake out SPI bit order and bitbang ctor
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2025-09-01 board sanity check
    almost set for v1
    [BOM_MOAR_MOAR_Board_2025-08-28.xlsx, BOM_MOAR_MOAR_Board_2025-08-31.xlsx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]
2025-09-03 board layers/mock ups
    [BOM_MOAR_MOAR_Board_2025-08-31.xlsx, BOM_MOAR_MOAR_Board_2025-09-02.xlsx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]
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2025-09-03 board sorts
    [BOM_MOAR_MOAR_Board_2025-09-02.xlsx, PickAndPlace_MOAR_Board_2025-09-02.xlsx]
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2025-09-05 hardware builds
    [BOM_MOAR_MOAR_Board_2025-09-02.xlsx, BOM_MOAR_MOAR_Board_2025-09-03.xlsx, PickAndPlace_MOAR_Board_2025-09-02.xlsx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]
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2025-09-18 Fix reference formatting in CDS sample report
2025-10-08 Expose smoothed ADC values in pot MIDI callback
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2025-10-14 Fix teensy unity test build setup
2025-10-15 Fix teensy40_unity serial shim include path
2025-10-15 Tighten Unity shim include search
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2025-10-20 Add button and envelope USB MIDI demo sketch
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2025-10-21 Include hardware IO shim in targeted build filters
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2025-10-23 Fix pot envelope map handling for unassigned slots
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2025-10-23 Fix BulkConfigAssembler empty check for Arduino String
2025-10-23 Guard chunk assembly against Arduino String API gaps
2025-10-23 Accept legacy slot type formats in bulk config
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2025-10-23 Tighten identity reply buffers
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2025-10-23 Reset EEPROM slots when schema bumps
    [Globals.h]
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2025-10-24 Fix EF display guard and format firmware sources
    [MIDITypes.h]
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2025-10-24 Fix ARG slot follower integration
2025-10-24 Fix EF helper linkage and restore ARG shaping
    [Globals.h]
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2025-10-24 Fix EfSettings type and button filter cycling
    [Globals.h, MIDITypes.h]
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2025-10-24 Fix ARG config duplication and repair button controls
    [Globals.h, MIDITypes.h]
2025-10-24 Tuck EF oversample byte to recover slot packing
2025-10-24 Fix ARG pair mapping and relax slot size guard
    [Globals.h, MIDITypes.h]
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2025-10-24 Fix duplicate MIDISlot definition
    [MIDITypes.h]
2025-10-24 Shrink MIDISlot EF runtime footprint and sync usage
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2025-10-24 Update README to remove legacy slot migration info
    Removed legacy slot migration details from README.
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2025-10-26 Testing recertify
    Strapped sysex and other fun stuff back into the machine after we did some intense work last week
2025-10-27 Add compile-time guard for Teensy4 SPI port selection
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2025-10-28 Fix Teensy SPI port selector without pointer casts
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2025-10-28 Scope Teensy4 SPI detail helpers to avoid namespace clash
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2025-10-28 Inline Teensy4 SPI port resolver
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2025-11-06 Reset DWT counter before Teensy4 waits
2025-11-06 Clamp Teensy4 wait guard delta and add regression test
2025-11-06 Handle DWT wrap in Teensy 4 clockless writers
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2025-11-06 Clamp Teensy 4 wait guard slack before converting to cycles
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2025-11-13 Fix migration simulator spec to apply adapter flow
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2025-11-23 Add slot tweak lab and link it from Quick Start
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2026-01-11 Update TODO.md and rename schematic ZIP file
    Removed completed troubleshooting documentation item from TODO.md. Renamed the hardware schematic ZIP file for clarity.
2026-01-11 Add Perlin jitter tuning controls and tests
    Introduces global jitter depth and smoothness parameters for Perlin-powered randomness, tunable via Ctrl0+Ctrl3+Ctrl4 and control pots. Updates arpeggiator and envelope follower to respect these settings, adds status display, and includes system/unit tests for jitter tuning behavior. Documentation and build config updated to reflect new features.
    [Globals.h]
2026-01-18 large re-sort due to firmware growth
    lots of little things and a couple VERY big ones
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2026-01-24 moar board
    [3DShell_3DShell_MOAR_Board_B.stl, 3DShell_3DShell_MOAR_Board_T.stl, BOM_MOAR_MOAR_Board_2025-09-03.xlsx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]
2026-01-25 Firmware updates
    Added UI/workflow for macro slot save/recall (buttons, inline confirmations, command wiring, response handling, disabled save during writes).
    Spec’d LED animator modes (Static/PeakHold/Trail/ClockPulse) with low-priority ticker plus RPC/UI hooks for switching and diagnostics override.
    Defined Scene snapshot system (fixed-size slot array, save/recall commands, JSON schema extension, scheduler-friendly EEPROM usage) and planned WebSerial/Scenes UI support.
    [Protocol.cpp]
2026-01-25 Added Serial Dispatch
    spell out the UX work you plan for the WebSerial buttons (confirmation modal, tooltips, disabling while save is pending, inline success/failure messaging) so the changelog captures the intended polish.
    clarify that the LED animator runs in a low-priority loop (~20 ms ticks), uses fixed buffers, and avoids interrupts, and mention the RPC/UI hook plus diagnostics override.
    note the scene system’s fixed-size Scene struct (including the 16-byte name), EEPROM slot range (4–8), and new SAVE_SCENE/RECALL_SCENE verbs so readers know it’s a multi-slot snapshot feature.
    add a “Testing” line holding the planned PlatformIO command (pio -d firmware test -e teensy40_un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
    [Protocol.cpp]
2026-01-25 Testing/hardening
    Added EEPROM recovery tracking so Runtime can show “Config restored from backup” or “EEPROM corrupted defaults loaded” when a corrupted write occurs, and documented the new OLED feedback in README so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
2026-01-26 Update the PCB a little bit at a time
2026-02-03 update hardware schematic/board
    Swapping the teensy 4.0 for a chipset that would build a teensy 4.1 with dual USB-C. Sweet
2026-02-03 Hardware update
    Lots of surface mount things and part replacement
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2026-02-04 prep(v1.0): onboarding UX, bridge release docs/tooling, and code explainability
    App
    - Add persisted Basic/Advanced UI mode with clearer beginner-oriented slot labels and glossary help
    - Add guided profile workflow (switch -> apply -> save) and tighten profile/macro/scene control gating
    - Strengthen staged/live handling and simulator parity for profile workflows
    - Expand Playwright coverage for UI mode and profile flows
    Bridge + Docs
    - Rework bridge docs into layered guides: full runbook, quickstart, performer one-pager, packaging plan
    - Add bridge release-prep scripts (smoke + packaging) and npm aliases (smoke, package:bridge, release:prep)
    - Add bridge artifact checklist template and wire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
    [Protocol.cpp]
2026-02-05 Application updates
    Followers finally a multi-assignable/mixable - all followers, all filters, all ARGs, all MIDI, every slot, all the time when enabled
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2026-02-14 docs: record demo-polish pass across TODO/HISTORY/CHANGELOG
    Document the latest demo-polish work: manifest device_name, connection identity banner + fail helper, OLED label readability updates, panic-safe reset combo, demo presets/runbook, and new connection-banner test coverage.
    [Protocol.cpp]
2026-02-28 docs: evaluate hardware usability and fix TaskScheduler fragmentation
    Evaluated the MOARkNOBS-42 firmware for data flow, cache management, memory leaks, and forecast hardware usability. Wrote findings into a new EVALUATION.md document. Addressed the immediate issue identified in the evaluation by refactoring TaskScheduler::update() to prevent continuous heap allocation and fragmentation caused by dynamically allocated std::vectors on every main loop tick.
2026-03-05 🧹 Extract duplicate constants into shared module
    * Extracted `EF_FILTER_NAMES`, `ARG_METHOD_NAMES`, and `SLOT_TYPE_NAMES` into `App/lib/constants.js`.
    * Updated `App/views/benzknobz.js` and `App/runtime.js` to import these shared constants instead of defining them locally or inline.
    * Verified changes with `npm test` to ensure no regressions in behavior.
2026-03-05 🧹 Fix CI compiler warning in firmware
    * Replaced `std::strncpy` with `std::memcpy` and manual bounds checking to avoid `-Werror=stringop-truncation` during `pio build`.
2026-03-05 ⚡ Optimize scene slot lookup in benzknobz.js
    Replaced linear Array.find search with direct array indexing in updateSceneSlot and handleSceneSave. Since sceneSlotElements is populated sequentially during boot, the slotIndex directly corresponds to the array index.
    Performance Benchmark (10M iterations, n=6):
    - Baseline (Array.find): 480.81ms
    - Optimized (Direct access): 65.62ms
    - Improvement: 86.35% faster
2026-03-05 🔒 Prevent buffer overflows by using snprintf
    Replace all usages of `sprintf` with `snprintf` in firmware source
    files (`unified_t.cpp`, `main_t.cpp`, `ButtonManager.cpp`) to prevent
    potential buffer overflow vulnerabilities. Used `sizeof(buffer)` appropriately
    to determine the maximum size string that can be generated safely.
    [main_t.cpp]
2026-03-05 🔒 Fix Buffer Overflow Vulnerability by replacing sprintf with snprintf
    Replaced all instances of `sprintf` with `snprintf` in the `firmware/` directory to prevent potential buffer overflows. Specifically addressed the vulnerability in `firmware/src/ButtonManager.cpp`.
    [main_t.cpp]
2026-03-05 🔒 Fix buffer overflow in ButtonManager via sprintf
2026-03-05 🔒 Mitigate buffer overflow vulnerabilities by replacing sprintf with snprintf
    Replaced all instances of `sprintf` with `snprintf(..., sizeof(...), ...)` to enforce bounds checking and prevent buffer overflows.
    This prevents memory corruption that could cause firmware crashes or unpredictable behavior.
    [main_t.cpp]
2026-03-05 fix: replace vulnerable sprintf with snprintf
    Replaces all instances of `sprintf` with `snprintf` in the firmware source files to eliminate buffer overflow vulnerabilities.
    * 🎯 **What:** The vulnerability fixed is the potential for buffer overflow when `sprintf` writes data to fixed-size buffers like `char buf[32]`.
    * ⚠️ **Risk:** The potential impact if left unfixed includes memory corruption, unexpected firmware crashes, and potential arbitrary code execution.
    * 🛡️ **Solution:** `snprintf(buf, sizeof(buf), ...)` was introduced, ensuring bounded writes that include the null terminator, thereby safely guarding the statically allocated buffers against overflow.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
    [main_t.cpp]
2026-03-05 🔒 Fix buffer overflows by replacing sprintf with snprintf
    Replaced vulnerable `sprintf` calls with safer `snprintf` equivalents
    across `unified_t.cpp`, `main_t.cpp`, and `ButtonManager.cpp`. This
    mitigates potential buffer overflows when formatting dynamically sized
    data into fixed-size local array buffers (`label`, `result`, `msg`, etc).
    [main_t.cpp]
2026-03-05 🔒 Prevent buffer overflows by replacing sprintf with snprintf
    Replaced all uses of `sprintf` with `snprintf` in the firmware source code (e.g., `unified_t.cpp`, `main_t.cpp`, `ButtonManager.cpp`). Using `snprintf` with `sizeof(buffer)` prevents formatting strings from exceeding buffer bounds, which fully mitigates potential buffer overflow vulnerabilities.
    The `pre-commit` hooks (such as clang-format) were run and their changes have been incorporated to satisfy CI constraints.
2026-03-05 🔒 Fix Buffer Overflow Vulnerability by replacing sprintf with snprintf
    Replaced all instances of `sprintf` with `snprintf` in the `firmware/` directory to prevent potential buffer overflows. Specifically addressed the vulnerability in `firmware/src/ButtonManager.cpp`. Formatted files using clang-format.
2026-03-05 🔒 Replace sprintf with snprintf to prevent buffer overflows
    This commit replaces all instances of the unsafe `sprintf` function with `snprintf` across the firmware codebase (`unified_t.cpp`, `main_t.cpp`, and `ButtonManager.cpp`). Using `sprintf` is a security risk as it can cause buffer overflows if the resulting string is larger than the destination buffer. By using `snprintf(buffer, sizeof(buffer), ...)`, we explicitly bound the write length to the size of the destination array, ensuring memory safety and preventing potential vulnerabilities.
    [main_t.cpp]
2026-03-05 🔒 Replace sprintf with snprintf to prevent buffer overflows
    This commit replaces all instances of the unsafe `sprintf` function with `snprintf` across the firmware codebase (`unified_t.cpp`, `main_t.cpp`, and `ButtonManager.cpp`). Using `sprintf` is a security risk as it can cause buffer overflows if the resulting string is larger than the destination buffer. By using `snprintf(buffer, sizeof(buffer), ...)`, we explicitly bound the write length to the size of the destination array, ensuring memory safety and preventing potential vulnerabilities. Pre-commit formatting hooks applied to ensure styling consistency.
2026-03-05 🔒 Prevent buffer overflows and fix unity tests linking
    Replaced all uses of `sprintf` with `snprintf` in the firmware source code
    (e.g., `unified_t.cpp`, `main_t.cpp`, `ButtonManager.cpp`) and used `sizeof(buffer)`.
    Included the formatting changes required by `clang-format` to satisfy CI constraints.
    Also fixed the `teensy40_unity` tests linker error by appropriately appending `extern` to
    variables missing linkage declarations in `test/GlobalsStub.cpp`.
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2026-03-22 docs: clarify current build and support entry points
2026-03-23 docs: add demo validation flow and punch list
2026-03-23 Revise prototype status and model recognition note
    Updated the README to reflect the current status of prototypes and clarify model recognition issues.
2026-03-23 docs: strengthen mkdocs landing experience
2026-03-23 docs: fix mkdocs landing page rendering
2026-03-23 docs: refine mkdocs homepage hero and landing flow
2026-03-28 Close firmware-app seams and add real recovery flows
2026-03-28 Fix browser-local slot metadata refresh
2026-03-29 Document configurator operation and add prototype BOM
    [BOM_MOAR_MOAR_Board_2026-03-17.xlsx]
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2026-04-17 feat: add typed bridge events and end-to-end trace metadata
2026-04-18 chore: harden CI lanes, release flow, and contributor guardrails
2026-04-18 hardening: stabilize display boot path and ignore .platformio state
    [DisplayManager.h]
2026-04-18 firmware: make startup animation non-blocking with final invert hold
    [DisplayManager.h]
2026-04-19 Stabilization cut: OLED resolver, WebSerial hardening, queue drain, diagnostics
2026-04-20 Stabilization cut v2: persistence throttle, WebSerial JSON discipline, MIDI queue hardening
    - Filter tuning: live update immediate, persist on 900ms idle + 500ms min interval
    - WebSerial: all output is JSON, added doc.overflowed() guards to all emissions
    - MIDI queue: high-priority 1ms drain task, enqueue failures count in midiDropCount
    - Diagnostics: loop overrun threshold raised to 2500µs (matches pot scan budget)
    - OLED: compressed text ('F' not 'Freq'), two-line toasts ('CONFIRM\nTap again')
    - UI: 'Config Reloaded' replaces misleading 'EEPROM Reset' text
    - Docs: comprehensive UI_ACTION_LEDGER.md with all gestures and side effects
    [MIDIHandler.h]
2026-04-21 refactor: decompose ConfigManager, DRY platformio.ini, harden CI
    Firmware:
    - Extract schema-migration logic into SchemaMigration.cpp (525 lines)
    - Extract profile sanitization/CRC into ProfileStorage.cpp (126 lines)
    - ConfigManager.cpp reduced from 1567 → 1111 lines
    - Fix TaskScheduler: replace O(n²) reverse-erase with remove_if,
    eliminate unused 'finished' vector
    - DRY platformio.ini: shared [core_modules] section replaces 5×
    duplicated 18-line build_src_filter blocks (393 → 339 lines)
    CI:
    - Bump ci.yml actions to checkout@v4, setup-python@v5, pin Python 3.11
    - Remove redundant bridge job from ci.yml (covered by quick-check +
    tests.yml)
    - Fix quick-check.yml Playwright install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
    [BOM_MOAR_MOAR_Board_2026-03-17.xlsx]
2026-04-23 Tighten release checks and improve docs visuals
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2026-05-03 LED tune
    v1.2 board misrouted power and needs an update for v1.3 re: fuse wiring on the input
2026-05-03 Timer jitter resolution/configurator clarity
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2026-05-26 Documentation
    Added commentary back into the stack in the newer parts and adjusted the Windows release flow for generating the still unsigned Bridge object
2026-05-31 board reset
2026-05-31 schedules to fix resets
    HIGH-MID schedule tiers are causing board resets - more fixes soon
    [Protocol.cpp]
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2026-06-05 Configurator slot persistence
    LFO control, seeing what's happening live
2026-07-02 app tightening/doctor doctoring
2026-07-06 Clarify next evidence needed for PCB fabrication quality
    Updated the next evidence needed for PCB fabrication quality to specify using photos from my phone.
2026-07-06 Revise component status and next evidence needed
    Updated observations and next steps for various components, including power rails, OLED/display, controls, MIDI paths, and LEDs/load.
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2026-07-27 Storage and SET_ALL ACK
    full dual-blob + atomic active-pointer redesign and post-ACK config readback comp
    [Arpeggiator.h, Globals.h, Protocol.cpp]
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2026-08-01 slotvalue cleanup & migration
    App tool display and grid/slot interaction
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2026-08-06 Remediation
    Fixed runtime-only scene rollback so persist=false avoids storage writes.
    Protected DIN Note Off admission when the serial queue is full, with regression coverage.
    Initialized activePot to slot 0.
    Made scheduler due checks rollover-safe.
    Replaced fragile binary protocol lookup with linear dispatch.
    Added DiagnosticRecord.cpp to shared machine-test sources.
    Restored the eight unregistered Unity tests and corrected scheduler topology expectations.
    Removed the obsolete Unity transport shim and its stale documentation/doctor requirement.
    Forward-declared DisplayManager in MIDIHandler.h.
    [MIDIHandler.h]
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2026-08-19 App music-first ux
    Musician-centered design UX
    Per-slot tuning
    such a big push
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2026-08-27 Fix modal LED ownership and complete chord help
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2026-10-29 fix(firmware): reconcile bench pin contract
2026-10-29 pin swaps
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2026-10-30 fix(app): preserve slot signal interactions
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2026-10-30 test(app): load demo slot mapping fixture
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2026-10-30 fix(app): refresh slot signal on lifecycle changes
2026-11-01 fix(app): clarify staged review
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2026-11-02 quickstart tightening
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
